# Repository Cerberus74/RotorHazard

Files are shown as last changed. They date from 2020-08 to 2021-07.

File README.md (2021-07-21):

RotorHazard Logo



# RotorHazard
**FPV Race Timing and Event Management**

A multi-node radio frequency race timing system for FPV drone racing with event management. Uses 5.8GHz video signals broadcast by drones to trigger lap times. Each node listens on a specified frequency and communicates times to a central server (usually a Raspberry pi). The server's front-end interface, which any device on the same network can connect to via web browser, offers race organizer management and pilot/spectator information. RotorHazard supports up to 16 nodes.

## Major Features
* Race timing and event management on local hardware, no internet connection needed
* Full screen and mobile-friendly responsive interface
* Simple, visual system calibration
* Adjust and apply calibration retroactively after race is complete
* Learns which calibration values work for each pilot and automatically applies them to new races (adaptive calibration)
* **Never miss a lap**; Recover laps with full accuracy by reviewing race history
* Advanced signal filtering allows accurate reading both indoors and outdoors, even in difficult multipathing environments
* Accurately tracks analog and DJI HD video transmitters
* Manage pilots, heats, classes, and race formats before or after races are run
* Statistics broken out by event, class, heat, and round
* Generates overlay displays and results pages for use with live streaming software such as OBS
* Timer hardware synchronized with user interface for accurate start/end signals; compensates for poor network connectivity
* LED and audio support to indicate race staging, starts, and other events
* Send live updates of lap times and split times to pilot OSD
* Control connected video receivers; change frequency and view lock status
* Connect other systems to extend functionality via MQTT or JSON API
* Send realtime lap data to LiveTime

## Documentation
For instructions on how to build and operate the current version of RotorHazard, follow the [Documentation](https://github.com/RotorHazard/RotorHazard/releases/latest#documentation) link on the [lastest-release page](https://github.com/RotorHazard/RotorHazard/releases/latest).

See the [RotorHazard Build Resources](resources/README.md) page for information on race-timer circuit boards and 3D-printable cases.

An easy-to-build single-node version of RotorHazard may also be constructed; see [doc/USB Nodes.md](doc/USB%20Nodes.md) for more info.

**Note:** The 'main' branch in the GitHub repository will usually contain the latest development code, which may not be stable. To install or upgrade to the latest stable release, please follow the [Documentation](https://github.com/RotorHazard/RotorHazard/releases/latest#documentation) link on the [lastest-release page](https://github.com/RotorHazard/RotorHazard/releases/latest) (see "Software Setup Instructions").

## Migrating from Delta5
RotorHazard is compatible with the hardware specifications of the [Delta5 Race Timer](https://github.com/scottgchin/delta5_race_timer). Install the software on  existing hardware per the [setup instructions](doc/Software%20Setup.md), ensuring that you complete a [re-flash of the Arduinos](doc/Software%20Setup.md#rotorhazard-node-code).

## Additional Resources
Links to external resources are available from the [Wiki](https://github.com/RotorHazard/RotorHazard/wiki), including extended tutorials, complete SD card images, video content, and a Raspberry Pi setup/install/upgrade/node flashing tool. Browsing these resources is strongly recommended for new users.

## Contributors
* Michael Niggel
* Eric Thomas
* Mark Hale

With support from Ryan Friedman, Klaus Michael Schneider, Cerberus Velvet, David Just, Paweł Fabiszewski, Aaron Smith, Diez Roggisch, Roger Bess, Kęstutis Strimaitis, and previous contributors to [Delta5](https://github.com/scottgchin/delta5_race_timer).

### Supported by:
Propwashed Logo (https://propwashed.com)

### Translators
* Dutch: Kenny Van Der Sypt
* German: Klaus Michael Schneider, Christian Baumgartner
* Spanish: Ramon Hernandez Roldan
* French: Yannick M.
* Polish: Mariusz Misiurek and Paweł Fabiszewski

## Feedback
Discuss RotorHazard on Facebook:  https://www.facebook.com/groups/rotorhazard

To report bugs or request features, please post a GitHub issue [here](https://github.com/RotorHazard/RotorHazard/issues). When reporting issues, using the "Download Logs" button and including the generated '.zip' file is highly recommended (see [here](doc/Software%20Setup.md#logging) for more information on logging).

Community contributions are welcome and encouraged; see the [Development.md](doc/Development.md) doc for more info.

## Support
Contributions to RotorHazard can be made on [Patreon](https://www.patreon.com/rotorhazard).

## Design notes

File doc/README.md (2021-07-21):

# RotorHazard Documentation

## Timing Guides
* [User Guide](User%20Guide.md)
* [Calibration Guide](Tuning%20Parameters.md)
* [Shielding and Course Position](Shielding%20and%20Course%20Position.md)
* [Event Setup Guide](Event%20Setup%20Guide.md)

## System Reference
* [Hardware Setup Instructions](Hardware%20Setup.md)
* [Software Setup Instructions](Software%20Setup.md)
* [Raspberry Pi Reference](Raspberry%20Pi%20Reference.md)

## Optional Features
* [Split Timing Guide](Cluster.md)
* [USB Nodes](USB%20Nodes.md)
* [Video Receiver Control](Video%20Receiver.md)

## General Reference
* [FPV Frequency Reference Chart](Frequency%20Reference.md)

<br />

---

* [Build Resources (PCB, etc)](../resources/README.md)
* [Developer Documentation](Development.md)
* <a href="https://github.com/RotorHazard/RotorHazard">RotorHazard on GitHub &#10132;&#xFE0E;</a>

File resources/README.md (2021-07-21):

# RotorHazard Build Resources

<br>

### Circuit Boards

* [RotorHazard S32_BPill PCB](S32_BPill_PCB/README.md)

* [RotorHazard 6 Node STM32](6_Node_BPill_PCB/README.md)

* [RotorHazard PCB 1.2 (Arduinos)](PCB/README.md)

<br>

### 3D-Printable Cases

* [RotorHazard S32_BPill Case](S32_BPill_case/README.md)

* [RotorHazard 6 Node Case](6_node_BPill_case/readme.md)

* [3D Printed Enclosure (for Arduino-based PCBs)](enclosure/README.md)

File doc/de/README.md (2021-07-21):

# RotorHazard-Dokumentation

## Timing-Leitfäden

* [Benutzerhandbuch](User%20Guide.md)
* [Kalibrierungsanleitung](Tuning%20Parameters.md)
* [Abschirmung und Kursposition](Shielding%20and%20Course%20Position.md)
* [Anleitung zur Ereigniseinrichtung](Event%20Setup%20Guide.md)

## System-Referenz

* [Anweisungen zur Hardware-Einrichtung](Hardware%20Setup.md)
* [Software-Einrichtungsanweisungen](Software%20Setup.md)
* [Raspberry Pi Reference](Raspberry%20Pi%20Reference.md)

## Optionale Merkmale

* [Leitfaden zur Zeitaufteilung](Cluster.md)
* [USB-Knoten](USB%20Nodes.md)
* [Video-Empfängersteuerung](Video%20Receiver.md)

## Allgemeine Referenz

* [FPV-Frequenz-Referenzdiagramm](Frequency%20Reference.md)

<br />

---

* [Dokumentation für Entwickler](Development.md)
* <a href="https://github.com/RotorHazard/RotorHazard" target="_blank">RotorGefahr auf GitHub</a> &#10132;➔&#xFE0E;︎

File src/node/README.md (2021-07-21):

# Receiver Node Firmware

The `src/node` directory contains the source code for the RotorHazard nodes. The same code may be used on Arduino nodes, or on an S32_BPill multi-node board.

For Arduino nodes, see '[readme_Arduino.md](readme_Arduino.md)'

For S32_BPill nodes, see '[readme_S32_BPill.md](readme_S32_BPill.md)'

<br>

## Unit Tests

Setup as per <https://github.com/Arduino-CI/arduino_ci>, then

```
set path=c:\Ruby25-x64\msys64\mingw64\bin;%path%
bundle exec arduino_ci_remote.rb --skip-compilation
```

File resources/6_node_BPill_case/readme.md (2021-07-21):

# 6 Node PCB Case
Internet connection is required to view images

## 3D Parts
Click [here](https://github.com/RotorHazard/rhfiles/tree/main/6_Node_BPill/case/stl) to view and download the .stl files

The 3D designs are done using Sketchup 2017 and the stl export plugin (which is hard to get hold of now). The .skp files have been uploaded should you wish to modify them, they can be found [here](https://github.com/RotorHazard/rhfiles/tree/main/6_Node_BPill/case/skp)

The available parts are:
Part                                    | Description                                                             | Links
----------------------------------------|-------------------------------------------------------------------------|-------------------------------------------------
RotorHazard Case                        | This is the main part of the case                                       | [[view](https://github.com/RotorHazard/rhfiles/blob/main/6_Node_BPill/case/stl/RotorHazard_Case.stl)] [[stl](https://github.com/RotorHazard/rhfiles/raw/main/6_Node_BPill/case/stl/RotorHazard_Case.stl)] [[skp](https://github.com/RotorHazard/rhfiles/raw/main/6_Node_BPill/case/skp/RotorHazard_Case.skp)]
RotorHazard Leg 60mm                    | This is the leg for the case, 2 are required                            | [[view](https://github.com/RotorHazard/rhfiles/blob/main/6_Node_BPill/case/stl/RotorHazard_Leg_60mm.stl)] [[stl](https://github.com/RotorHazard/rhfiles/raw/main/6_Node_BPill/case/stl/RotorHazard_Leg_60mm.stl)] [[skp](https://github.com/RotorHazard/rhfiles/raw/main/6_Node_BPill/case/skp/RotorHazard_Leg_60mm.skp)]
RotorHazard Standoff M2.5 11.5mm        | This is a standoff to go between the pi and the PCB, 4 are required     | [[view](https://github.com/RotorHazard/rhfiles/blob/main/6_Node_BPill/case/stl/RotorHazard_Standoff_M2.5_11.5mm.stl)] [[stl](https://github.com/RotorHazard/rhfiles/raw/main/6_Node_BPill/case/stl/RotorHazard_Standoff_M2.5_11.5mm.stl)] [[skp](https://github.com/RotorHazard/rhfiles/raw/main/6_Node_BPill/case/skp/RotorHazard_Standoff_M2.5_11.5mm.skp)]
RotorHazard Standoff M3 11.5mm          | Same as above, use these if you have made your pi's fixing holes wider  | [[view](https://github.com/RotorHazard/rhfiles/blob/main/6_Node_BPill/case/stl/RotorHazard_Standoff_M3_11.5mm.stl)] [[stl](https://github.com/RotorHazard/rhfiles/raw/main/6_Node_BPill/case/stl/RotorHazard_Standoff_M3_11.5mm.stl)] [[skp](https://github.com/RotorHazard/rhfiles/raw/main/6_Node_BPill/case/skp/RotorHazard_Standoff_M3_11.5mm.skp)]
RotorHazard Antenna Holder 50mm         | Used to mount the wired antenna                                         | [[view](https://github.com/RotorHazard/rhfiles/blob/main/6_Node_BPill/case/stl/RotorHazard_Antenna_Holder_50mm.stl)] [[stl](https://github.com/RotorHazard/rhfiles/raw/main/6_Node_BPill/case/stl/RotorHazard_Antenna_Holder_50mm.stl)] [[skp](https://github.com/RotorHazard/rhfiles/raw/main/6_Node_BPill/case/skp/RotorHazard_Antenna_Holder_50mm.skp)]
RotorHazard Lid No LED's                | The case lid with no cut outs for LED's                                 | [[view](https://github.com/RotorHazard/rhfiles/blob/main/6_Node_BPill/case/stl/RotorHazard_Lid_No_LEDs.stl)] [[stl](https://github.com/RotorHazard/rhfiles/raw/main/6_Node_BPill/case/stl/RotorHazard_Lid_No_LEDs.stl)] [[skp](https://github.com/RotorHazard/rhfiles/raw/main/6_Node_BPill/case/skp/RotorHazard_Lid_No_LEDs.skp)]
RotorHazard Lid External LED's          | The case lid with a cut out for a 3 pin JST-SM connector                | [[view](https://github.com/RotorHazard/rhfiles/blob/main/6_Node_BPill/case/stl/RotorHazard_Lid_External_LEDs.stl)] [[stl](https://github.com/RotorHazard/rhfiles/raw/main/6_Node_BPill/case/stl/RotorHazard_Lid_External_LEDs.stl)] [[skp](https://github.com/RotorHazard/rhfiles/raw/main/6_Node_BPill/case/skp/RotorHazard_Lid_External_LEDs.skp)]
RotorHazard Lid Cartridge 1 Part        | The case lid with an aperture for the LED cartridge                     | [[view](https://github.com/RotorHazard/rhfiles/blob/main/6_Node_BPill/case/stl/RotorHazard_Lid_Cartridge_1part.stl)] [[stl](https://github.com/RotorHazard/rhfiles/raw/main/6_Node_BPill/case/stl/RotorHazard_Lid_Cartridge_1part.stl)] [[skp](https://github.com/RotorHazard/rhfiles/raw/main/6_Node_BPill/case/skp/RotorHazard_Lid_Cartridge_1part.skp)]
RotorHazard Lid Cartridge 2 part A      | As above but broken into two easy to print parts, this is part A        | [[view](https://github.com/RotorHazard/rhfiles/blob/main/6_Node_BPill/case/stl/RotorHazard_Lid_Cartridge_2part_A.stl)] [[stl](https://github.com/RotorHazard/rhfiles/raw/main/6_Node_BPill/case/stl/RotorHazard_Lid_Cartridge_2part_A.stl)] [[skp](https://github.com/RotorHazard/rhfiles/raw/main/6_Node_BPill/case/skp/RotorHazard_Lid_Cartridge_2part_A.skp)]
RotorHazard Lid Cartridge 2 part B      | As above but broken into two easy to print parts, this is part B        | [[view](https://github.com/RotorHazard/rhfiles/blob/main/6_Node_BPill/case/stl/RotorHazard_Lid_Cartridge_2part_B.stl)] [[stl](https://github.com/RotorHazard/rhfiles/raw/main/6_Node_BPill/case/stl/RotorHazard_Lid_Cartridge_2part_B.stl)] [[skp](https://github.com/RotorHazard/rhfiles/raw/main/6_Node_BPill/case/skp/RotorHazard_Lid_Cartridge_2part_B.skp)]
RotorHazard Cartridge                   | This is the cartridge to hold the 8x8 LED panel                         | [[view](https://github.com/RotorHazard/rhfiles/blob/main/6_Node_BPill/case/stl/RotorHazard_LED_Cartridge.stl)] [[stl](https://github.com/RotorHazard/rhfiles/raw/main/6_Node_BPill/case/stl/RotorHazard_LED_Cartridge.stl)] [[skp](https://github.com/RotorHazard/rhfiles/raw/main/6_Node_BPill/case/skp/RotorHazard_LED_Cartridge.skp)]
RotorHazard Case (Pi zero / banana pi)  | Use this case with a pi zero or banana pi (No USB or Ethernet cutouts)  | [[view](https://github.com/RotorHazard/rhfiles/blob/main/6_Node_BPill/case/stl/RotorHazard_Case%20-%20pi%20zero.stl)] [[stl](https://github.com/RotorHazard/rhfiles/raw/main/6_Node_BPill/case/stl/RotorHazard_Case%20-%20pi%20zero.stl)] [[skp](https://github.com/RotorHazard/rhfiles/raw/main/6_Node_BPill/case/skp/RotorHazard_Case%20-%20pi%20zero.skp)]
RotorHazard Standoff M3 13.1mm          | Use this standoff when the screw doesn't go through the pi              | [[view](https://github.com/RotorHazard/rhfiles/blob/main/6_Node_BPill/case/stl/RotorHazard_Standoff_M3_13.1mm.stl)] [[stl](https://github.com/RotorHazard/rhfiles/raw/main/6_Node_BPill/case/stl/RotorHazard_Standoff_M3_13.1mm.stl)] [[skp](https://github.com/RotorHazard/rhfiles/raw/main/6_Node_BPill/case/skp/RotorHazard_Standoff_M3_13.1mm.skp)]

## Parts to buy for the case
### Required
Part                | Qty   | Description
--------------------|-------|---------------
M3x8mm              | 10    | Used to attach the PCB to the standoffs, the lid to the case and the legs to the case
M3x10mm countersunk | 4     | Used to attach the Raspberry pi to the case
Copper tape         | -     | Used for RF shielding, make sure it has conductive adhesive
26AWG Wire          | -     | 

### Optional
Part                    | Qty   | Description
------------------------|-------|---------------
M3x5mm                  | 1     | Used for attaching the antenna arm, 3x8mm would work
M2x5mm                  | 2     | Used to attach the voltage display to the case
40x40x10mm fans         | 2     | 
M3x16mm                 | 8     | Attaches the fans to the case
M3 nut                  | 8     | Attaches the fans to the case
8x8 WS218b LED panel    | 1     | LED's for the cartridge print
2.54mm header 3 pins    | 2     | Connects the cartridge to the lid
2.54mm socket 3 pins    | 1     | Connects the cartridge to the lid
Hot glue                | -     | To attach cartridge pins to case

## Lid
There are 3 lid option to chose from:
1. The first has no LED apparatuses and is a basic lid
2. The second adds an aperture for the female JST-SM 3 pin header that comes with the LED's so that external LED's can be used
3. The third allows use of an LED cartridge, the print can be printed in 1 or 2 parts depending on your printers capabilities

### LED cartridge & lid wiring
The LED cartridge connects to the lid using standard PCB mount 2.54mm headers and sockets. You have to be careful to get the alignment of the connectors correct.

1. Start with the two 3 way pin headers, solder wire to both of them and then solder those wires together.
2. Now insert those headers into the two holes on the lid 3D print. Make sure the pin out is symmetrical to ensure correct connections when you rotate the cartridge
3. Now solder the socket to wire and fit it into the LED cartridge print
4. Now is the time to align the connectors. Put the cartridge into the cartridge insert in the lid and ensure a good connection with the lids pins. Hot glue into place once aligned.
5. Rotate the cartridge and ensure it fits in the other orientation.
6. Now solder the cartridge socket wires to the LED panel and secure in place

Internet connection is required to view images
Internet connection is required to view images

## Thermal Considerations
Commercial electronics are typically rated up to 70&deg;C. During initial testing the timer was around 45&deg;C above ambient, with all 6 nodes active and with heat-syncs fitted.

Whilst this is still within 70&deg;C at room temperature ~21&deg;C these kind of temperatures are not recommended as it can cause the following:
* Stability issues
* Reduced life span of the electronics

If you live in a cold country or only plan to use 2-3 nodes at the same time then you are probably ok just using heat-syncs

For the majority of people heat-syncs and fans are recommended for optimum cooling.

If you use fans and wish for them to activate automatically and save power + maintain a constant temperature go [here](https://github.com/Aaronsss/Raspberry-Pi-Fan-Control) and follow the install instructions for the automatic fan control which will turn fans on when the pi temperature is 40&deg;C and off again when it is 38&deg;C

## RF Shielding
RF shielding is an essential part of RotorHazards timing, make sure you shield your timer. There are a number of ways to do this like putting the timer in a metal box

The neatest way to do it is to get some copper tape and cover the inside of the box. Be sure to use copper tape with conductive adhesive. Once fitted you can solder a wire to the copper tape and then connect that to the case pads of the PCB. It is recommended to add insulation tape in locations where the PCB comes close to the case. Be sure to leave the end with the grill and centers of the fan covers unshielded

More information of RF shielding can be found [here](/doc/Shielding%20and%20Course%20Position.md)

Internet connection is required to view images

## Wifi Antenna Wiring
If you wish to use Wifi it is recommended to use a USB 2.4GHz wifi dongle with external antenna. 

You can then go one step further and de-case it and include it inside the laptimer case. This is what the arm is designed for on this case design.

Remove the plastic casing from the wifi dongle, then de-solder the SMA connector. Now solder a 2.4GHz antenna to the old SMA pads by either direct soldering or using a U.FL connector

Now connect the USB connections to the probe points on the bottom of the Raspberry Pi. On a Raspberry Pi 3B+ the probe points are as follows for the bottom left USB (when looking directly at the USB connector):
* PP27 = USB VCC
* PP42 = USB D-
* PP43 = USB D+
* PP51 = GND

You should then apply heat shrink to the wifi board and apply some hot glue to the antenna end for mechanical security.

Now you can feed the antenna through the hole in the case and heat shrink it to the antenna arm

You will then need to configure your pi to use the wifi dongle instead of the built in wifi

Internet connection is required to view images

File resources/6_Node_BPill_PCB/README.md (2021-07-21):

# RotorHazard 6 Node STM32

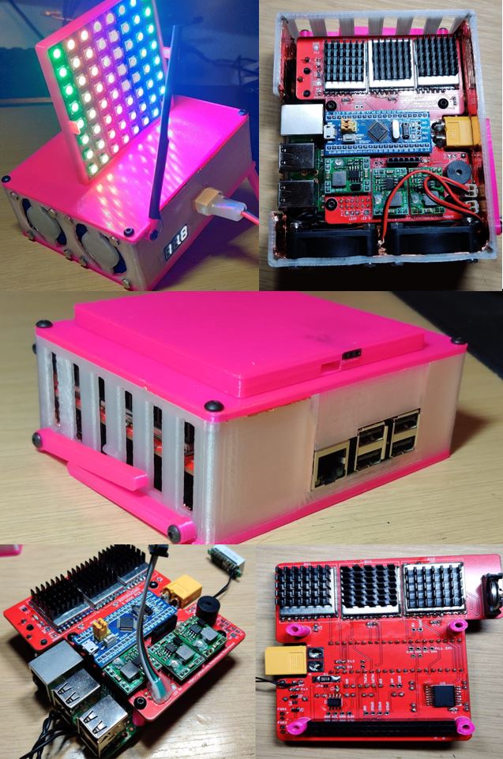
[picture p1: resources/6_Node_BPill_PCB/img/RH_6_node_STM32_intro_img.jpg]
RH_6_node_STM32_intro_img


## Features

* Supports 1 to 6 RX5808 nodes
* Board size is 97mmx87mm, with cut-outs for an XT60 & Raspberry Pi connectors
* The Raspberry Pi plugs directly into the PCB in a raspberry Pi 'hat' style, to keep things compact
* Instead of multiple Arduinos, the board uses a single STM32 processor on a 40 pin module, mounted on the PCB
* The STM32 firmware can be updated via the RotorHazard web GUI using the 'Update Nodes' button (in the 'System' section on the 'Settings' page)
* The same server and node source code supports both the 6 node STM32 and the (existing) multi-Arduino boards
* Supports power / battery monitoring and a buzzer (low-battery alarm)
* INA219 (Current sense IC) & DS3231 (Real Time Clock) + RTC battery can be mounted directly to the PCB
* Connector pads for LED-strips & dedicated regulator
* Fans can be automatically switched on based on raspberry pi temperature.

PCB build instructions can be found [here](BoardBuild.md)

PCB:<br>
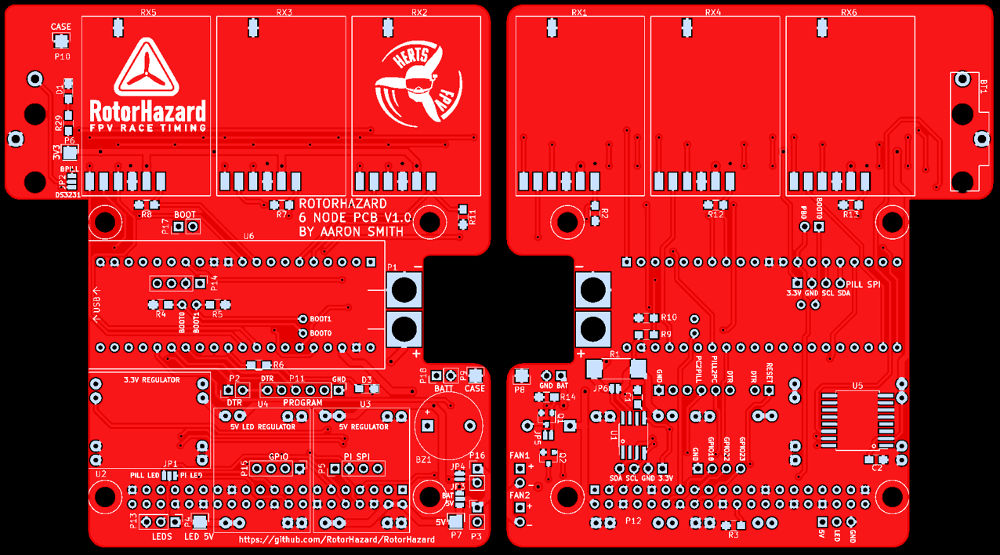
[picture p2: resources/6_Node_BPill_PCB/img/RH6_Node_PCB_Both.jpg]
RH6_Node_PCB_Both


## Cost
The cost of the required parts is approximately £74 (~102.60 USD)

For each node add £6, so all 6 nodes would add £36 (~49.90 USD)

All the optional parts add approximately £23 (~31.90 USD)

To fit all parts to the board will cost approximately £133 (~184.40 USD)

Note: The above costs includes the raspberry pi 3b + SD card. Mouser & Banggood were used in the above costings, parts may be cheaper from other suppliers

## Bill of Materials (BOM)
The PDF version of the BOM can be found [here](RotorHazard_6_Node_Timer_BOM_V1.0.pdf), the PDF version contains more information and suggested parts / suppliers
### Required

For the PCB:
Reference                       | Quantity  | Part No.                                                           | Notes
--------------------------------|-----------|--------------------------------------------------------------------|---------
PCB                             |   1       | Download the [gerber files](RotorHazard_6_Node_Timer_fab_V1.0.zip) | You can upload the gerbers files to your favourite PCB supplier or click [here](https://www.pcbway.com/project/shareproject/RotorHazard_6_Node_STM32_Lap_Timer.html) to buy from PCBway<br>Keep default options but consider changing:<br>- The solder mask colour <br>- Select quantity 10 which doesn't cost any more
P12	                            |   1	    | 2.54mm 20x2 8.51mm tall header                                     | Single strips also work
P1	                            |   1	    | XT60 Male	                                                         | -
R2, R7, R8, R9, R11, R12, R13	|   7	    | 100k ohm 5% 0805 resistor                                          | Buy some extra in case you drop one
R3, R10                         |   2       | 10k ohm 5% 0805 resistor                                           | Buy some extra in case you drop one
U2, U3                          |   2	    | MP1584	                                                         | -
U2, U3  	                    |   16	    | 2.54mm header pins                                                 | -
U6	                            |   1	    | STM32F103C8T6 	                                                 | -
RX1, RX2, RX3, RX4, RX5, RX6    |   1-6	    | RX5808	                                                         | 1 of these is required for each node you wish to fit

For the timer assembly:
Name                            | Quantity  | Notes
--------------------------------|-----------|---------
RASPBERRYPI_3B+                 |   1       | Alternative: Raspberry Pi 4
8GB+ Micro SD card              |   1       | Any Micro SD card between 8GB and 64GB will work
  
You will also require some 3D printed parts for the case and the 11.5mm 3D printed stand offs. If you wish to use a different case then 12mm standoffs should work.

Details on 3D printed parts and mechanical assembly can be found [here](../6_node_BPill_case/README.md)
  
### Optional
For the PCB:
Reference                       | Quantity  | Part No.                      | Notes
--------------------------------|-----------|-------------------------------|---------
U5                              |	1	    | DS3231SN                      | Fit if you want the real time clock (RTC), alternatives: DS3231S#T&R, DS3231SN#, DS3231S#
BT1	                            |   1	    | Keystone Electronics 1069     | Fit if you want the real time clock (RTC)
BT1	                            |   1	    | CR1632 battery                | Fit if you want the real time clock (RTC), alternatives: CR1620, CR1616
R1	                            |   1	    | 0.1 ohm 2512 1% resistor      | Fit if you wish to use the current sense IC
U1	                            |   1	    | INA219AIDR	                | Fit if you wish to use the current sense IC, alternatives: INA219AID, INA219BID, INA219BIDR
C1, C2	                        |   2	    | 100nF X7R 0805 capacitor      | These are decoupling capacitors for INA219 and DS3231
D1, D3	                        |   2	    | 0805 LED       	            | Fit if you want the on-board power and status LED's, not really needed
R6, R29	                        |   2	    | 220 ohm 5% 0805 resistor	    | Fit if you want the on-board power and status LED's, not really needed
P4	                            |   1	    | 3 pin JST SM Female	        | Fit if you want to use RGB LED rope / tape
U4	                            |   8	    | 2.54mm header pins            | Fit if you want to use RGB LED rope / tape
U4	                            |   1	    | MP1584	                    | Fit if you want to use RGB LED rope / tape
BZ1	                            |   1       | 12mm x 9.5mm 5V buzzer        | Used for low voltage alarm
Q2  	                        |   1	    | GSD SOT-23 N-Channel MOSFET   | Used for optional fan enable control, an example is IRLML6344TRPBF

For the timer assembly:
Name	                        | Quantity      | Notes
--------------------------------|---------------|---------
Raspberry Pi heat syncs         |   1 set       | Recommended to keep the pi cool
20x20x6mm heat sync             |   1-6         | Recommended to keep the RX5808's cool
Thermal glue                    |   1 tube      | Needed to attach the RX5808 heat syncs
LCD Voltage Screen              |   1           | Used to show the battery voltage on the case

## Tools
### Required
1. Soldering iron (chisel tip recommended to fit INA219 or DS3231 IC's)
2. Solder
3. Tweezers
4. Digital Multi Meter (DMM), to measure voltage and resistance
5. Screw driver for screws purchased
6. Small flat head screw driver to adjust MP1584 voltage

### Recommended
1. Wire cutters / side cutters
2. Helping hands
3. Solder wick
4. Hot glue & glue gun
5. Pilers
6. Insulation tape
7. Copper tape with conductive adhesive
8. Magnifying glass

## Resources

[RotorHazard 6 Node STM32 Schematic](RotorHazard_6_Node_Timer_V1.0.pdf)

[Gerber files for RotorHazard 6 Node STM32 PCB](RotorHazard_6_Node_Timer_fab_V1.0.zip)

[RotorHazard 6 node STM32 Board Build Guide](BoardBuild.md)

[3D printed parts & mechanical assembly](../6_node_BPill_case/readme.md)

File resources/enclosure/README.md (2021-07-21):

# 3D Printed Enclosure
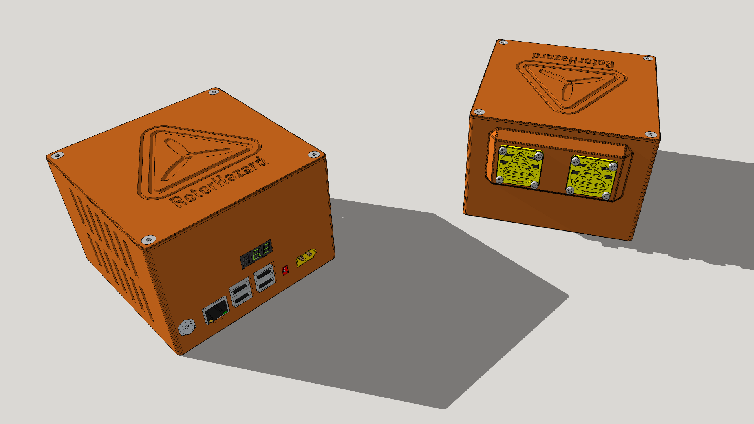
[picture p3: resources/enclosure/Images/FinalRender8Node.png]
3D rendering of box with openings for Raspberry Pi, case fans, and voltage display; with RotorHazard branding


## **Four and Eight Node Printable Enclosures**
This is pretty much a ground up rework of FreeFormFPV's excellent original work. Not much of the original remains. I've expanded heavily on the original design and hopefully improved it.

There are two enclosures. One for four node timers and one for eight node timers. The lid and PCB tray fit either.

The Original D5 100x100mm V2.0 PCB is a 'click fit' into the new PCB Trays. No fasteners needed. the trays then stack in place in the enclosure and are secured in place by the lid. Which secures with four countersunk M3 fasteners. The planned updated RotorHazard PCB will be compatible with the PCB tray.

A POE DC jack is provided so that the timer can be powered at the other end of the network cable (POE injector needed). Be sure to use a THREE PIN DC jack wired properly to disconnect the XT60 socket when in use. Failure to do this may result in the release of magical smoke. The timer may thus be powered either locally by a lipo or remotely over POE.

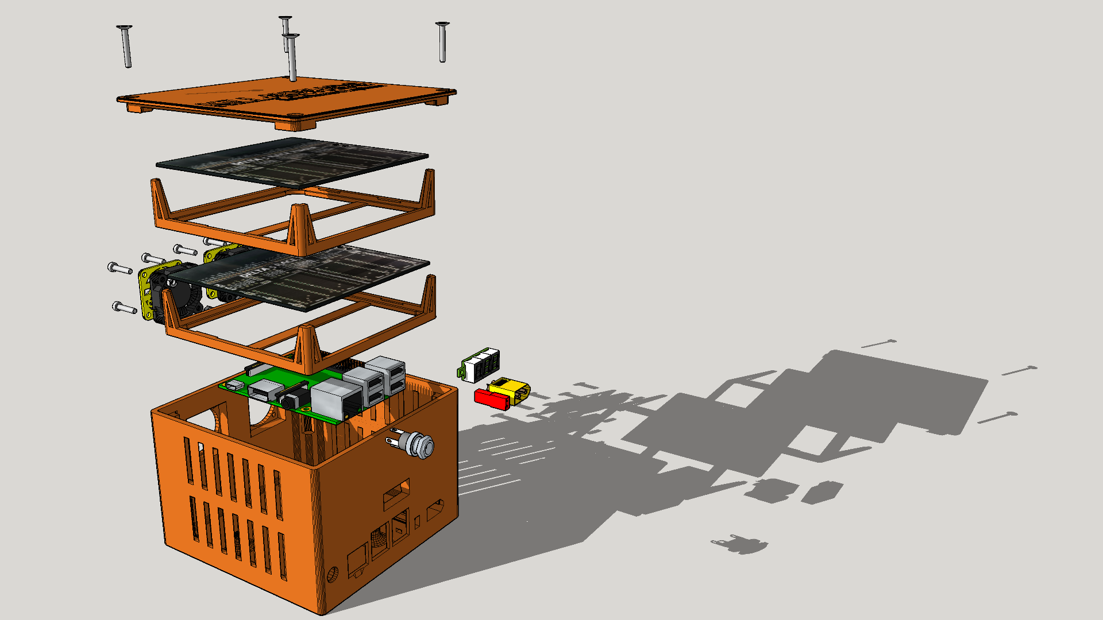
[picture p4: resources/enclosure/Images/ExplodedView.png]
Exploded view of enclosure with insert trays and electronic components

## **Printable Parts:**
* 8 Node Enclosure Box
* 4 Node Enclosure Box
* PCB Tray
* RotorHazard Branded Lid
* RotorHazard Branded Fan Grille
* Three Plain Style Fan Grilles

## **Parts Needed:**
**XT60 connector** to power timer by lipo (Slot for securing zip tie provided, but I recommend a dab of hot glue to really hold it)
http://tiny.cc/12ri8y

**JST connector** for WS2812b LED panel output from Raspberry Pi pins 19-GPIO10,20-GND (Slot for securing zip tie provided, but I recommend a dab of hot glue to really hold it)
http://tiny.cc/e7ri8y

**5.5mm 3 pin DC Jack** for POE
http://tiny.cc/wbsi8y [Wiring Diagram](Images/WireBarrelJack.png)

**POE injector/adapter** (optional)
http://tiny.cc/idsi8y

**2 x 5V 3cm cooling fans**
http://tiny.cc/rsti8y

**Voltage Meter**
http://tiny.cc/o7ti8y
(Secured by two M2 fasteners. Or a couple of dabs of hot glue)

**4 x countersunk M3x20 Machine Screw** To fasten lid
http://tinyurl.com/y3g2hqaf

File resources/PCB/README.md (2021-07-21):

# RotorHazard PCB

The RotorHazard PCB 1.2 implements current hardware standards to simplify wiring and component placement, expediting timer builds and improving usability.

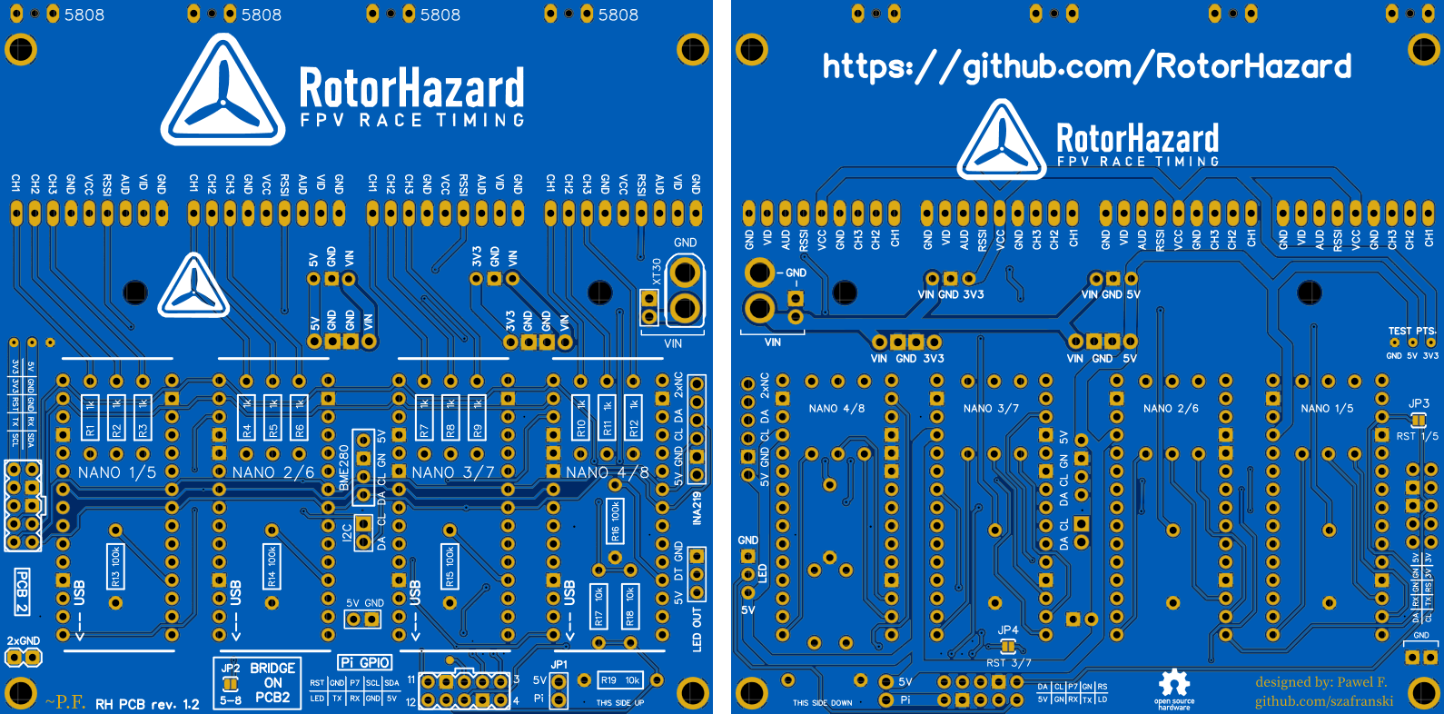
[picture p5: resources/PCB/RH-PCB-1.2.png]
PCB Layout


Download the [gerber file](Gerber_PCB%20RotorHazard%20PCB%20rev.%201.2.zip) to produce a board or send to a PCB manufacturer. Manufacturers often require bulk purchases, so check with other RotorHazard users near you before purchasing in case there is stock available or to split the cost of an order.

[View Board Schematic (PDF)](Schematic_RotorHazard-PCB-1_2_RC_2020-08-20_19-56-33.pdf)<br>
[View Board Dimensions (JPG)](RH_PCB_1_2_dimensions.jpg)

## Features

* 100×100mm (matches common Delta5 V2 PCB)
* Functions as 1–4 node primary board or 1–4 node extension
* Implements hardware-based node address selection. Nodes do not need uniquely addressed and can remain st to address 0 on upload.
* Implements in-system programming wiring for "OTA" updates without removing Arduinos from board
* Integrated voltage converter for ISP line
* Supports standardized 2×5 pin ribbon cable connectors to Pi GPIO and between boards
* Dedicated connectors for BME280 and INA219 sensors
* Expansion connectors for other I2C devices
* Raspberry Pi power isolation jumper
* Additional VIN connector (common uses: case fan or diode for reverse voltage protection)
* Additional ground connectors (common use: case shielding)
* 6 screw-mount holes, 4 with exposed ground plane

## Testing

RotorHazard does not manufacture PCBs and cannot guarantee the quality of any manufacturer. Thoroughly test any boards before connecting sensitive components.

## Build Components

### Required

See [Hardware Setup](https://github.com/RotorHazard/RotorHazard/blob/main/doc/Hardware%20Setup.md) for basic component requirements such as Arduinos, resistors, and receiver modules. The RotorHazard PCB offers mounting points for these components.

In addition to the above building with the RotorHazard PCB requires:
* 1× PCB (for timers with 1–4 nodes) or 2× PCB (timers with 5–8 nodes)
* 1× 3V 2.5A regulator
* 3× 10k resistor (0.25W or greater)

The RotorHazard PCB is designed to fit the following components:
* Arduino Nano
* Pololu D24V25F5 ("enable" pin is not connected)
* Pololu D24V25F3 ("enable" pin is not connected)

### Recommended

These components improve performance or significantly improve ease of use.

* 2×15 pin female 0.1in headers for each Arduino
* 1×9 pin female 0.1in header for each RX5808 module
* Female 0.1in header for each voltage regulator (either 1×3 pin or 1×4 pin depending on regulator style)
* 1×2 pin male 0.1in header with 2-pin jumper (for disconnecting power from the Pi)
* 2×5 pin male connector for Pi GPIO (may be KANDA/ISP style or male gold-pin header)
* Flat/ribbon cable or 10pcs jumper wires (2×5) for Pi GPIO
* 4–6 3mm screws for each board (mounting board to case)

If a 2nd PCB is used:
* 2×5 pin male connector for each PCB
* Flat/ribbon cable or 10pcs jumper wires (2×5) for PCB1 -> PCB2

### Optional

For a tidy build or to use with optional features, the following components may be added.

* XT30 female connector (power in)
* 1×3 pin female 0.1in header for each RX5808 module's antenna connector—do not solder center ANT pin
* 1×3 pin male 0.1in header for LEDs (connect only DATA and GND if LED are powered with separate voltage source)
* 1×6 pin female 0.1in header for INA219 sensor
* 1×4 pin female 0.1in header for BME280 sensor
* 1×2 0.1in header for grounding of RF shield (not needed if mounting screws are already connected to RF shield)
* 1×2 0.1in header for connecting optional accessories to the VIN (such as a 12V case fan)

## Assembly

This layout can be used as a primary board for up to 4 nodes when directly connected to the Pi, or a secondary board for up to 4 additional nodes. When connected directly it will be referred to as PCB1. If you are using only one board, follow all instructions for PCB1. A secondary board is referred to as PCB2.

* Find "THIS SIDE UP" indicator. This is the expected side on which to attach your components. While other configurations are possible, you will need to adjust these assembly instructions accordingly.
* Use node slots in numeric order. While RotorHazard should function with nodes placed out of order, in-system node flashing may not.
* Solder four resistors at "R" positions within each node area for all nodes you will be using. Use the values indicated (1k or 100k).
* R17-19 are required on PCB1. They are not used for PCB2.
* Female 0.1" (2.54mm) headers are expected for Arduino mounts, voltage regulators, and RX5808 mounts. Add these headers now if you are using them. If you choose to flush mount any component, be sure to electrically isolate it from the board.
* Bridge JP1 on PCB1. A physical jumper is recommended in this position. Bridging on PCB2 is not required.
* If using 5–8 nodes, connect "PCB2" headers between each board, being careful to match polarity. You may use a standard 2×5 pin ribbon cable or wire these insidivdually. On PCB2, bridge pads at the bottom marked "BRIDGE ON PCB2" (JP2)
* If using an odd number of nodes, bridge one and only one pad on the back of one board that corresponds to the highest numbered node in use:
1 node: PCB1 JP3
3 nodes: PCB1 JP4
5 nodes: PCB2 JP3
7 nodes: PCB2 JP4
* Connect a 5V voltage regulator and a 3.3V regulator on PCB1. Use either the upper (3) or lower (4) set of pins depending on the chosen regulator's pinout. Do not use both upper and lower sets at once for the same voltage.
* Connect input voltage connector or wires at VIN. Use XT30 connector if desired.
* STOP. Perform continuity testing to ensure there are no shorts from power to ground. Connect power at VIN and test 5V, 3.3V, and GND at test points on back of board before proceeding. Use a fuse or "smoke stopper" during these tests.
* Connect the Pi to the "Pi GPIO" header block. You may use a 2×5 pin cable attached to pins 3–12 of the Pi GPIO, or individual wires if you wish to change any connections (such as for "LED IN")
* If using INA219 or BME280 sensors, connect to dedicated pads.
* Connect Arduinos. Keep Aruino reset button and LEDs visible. Keep USB connector toward side indicated with "<-- USB" (away from voltage regulators).
* Connect RX5808 modules. Optionally connect GND pads near antenna. Do not solder to RX5808 antenna connection (center pad).
* When connecting an LED strip to LED OUT, ensure the voltage regulator you are using is rated highly enough for all Arduinos, sensors, and the LED strip combined. If not, supply power for the LEDs from a separate regulator, using only data and ground from the PCB.

## Usage

* Before ISP flashing of nodes is possible, nodes must not be transmitting over serial. You can flash the most recent node version from RotorHazard, or the standard "Blink" sketch. (Delta5 and older RotorHazard node versions generally use serial and will prevent ISP from functioning.)
* Nodes should all be flashed with the node number of 0 (default). This board will automatically assign node numbers based on their position.
* In-system flashing can be accomplished with the [OTA tool](https://github.com/szafranski/RH-ota)
* If flashing nodes by USB, disconnect JP1 to prevent powering on the Pi.

## Credit

This board and the OTA tool were developed by [Paweł Fabiszewski](mailto:p.fabiszewski@gmail.com).

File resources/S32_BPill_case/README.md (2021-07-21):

# RotorHazard S32_BPill Case

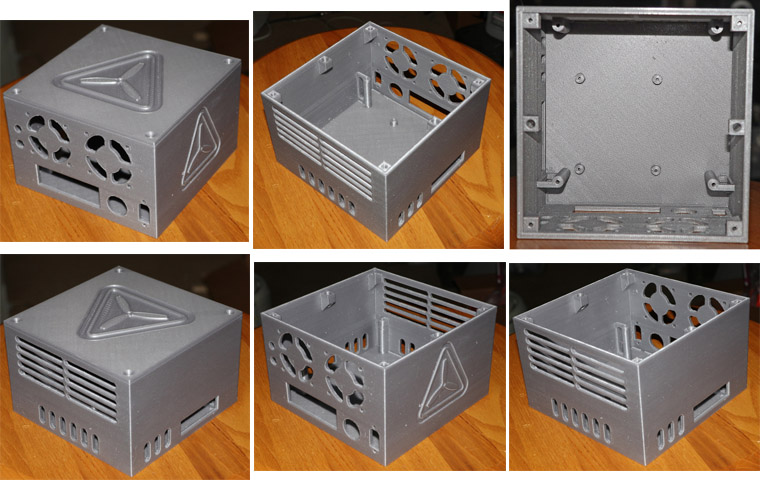
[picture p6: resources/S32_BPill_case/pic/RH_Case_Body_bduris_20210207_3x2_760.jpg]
RH_Case_Body_3x2


The RotorHazard S32_BPill case is the recommended enclosure to use with the [S32_BPill PCB](../S32_BPill_PCB/README.md). Inspired by existing designs, the S32_BPill case was created from scratch as a new project using [FreeCAD](https://github.com/FreeCAD/FreeCAD).

## Features

* Four mounting posts for attaching the S32_BPill PCB with screws (no separate mounting tray)

* Mounting posts for the Raspberry Pi on the bottom, with openings on the front and side for accessing Pi connectors

* Contains mounting holes for a power button, [shutdown button](../../doc/Shutdown%20Button.md), status LED, and (optional) fans

* Lid may be attached with screws, or magnets may be installed in provided mounts

* FreeCAD source project file available (see below)

## Resources

[RotorHazard S32_BPill Case Body \(with logo, 77mm tall\)](https://github.com/RotorHazard/rhfiles/raw/main/S32_BPill/case/RotorHazardCaseBodyBD77.stl) \[[preview](https://github.com/RotorHazard/rhfiles/blob/main/S32_BPill/case/RotorHazardCaseBodyBD77.stl)\]

[RotorHazard S32_BPill Case Lid \(with logo\)](https://github.com/RotorHazard/rhfiles/raw/main/S32_BPill/case/RotorHazardCaseTopBDyy.stl) \[[preview](https://github.com/RotorHazard/rhfiles/blob/main/S32_BPill/case/RotorHazardCaseTopBDyy.stl)\]

[FreeCAD Source Project File](https://github.com/RotorHazard/rhfiles/raw/main/S32_BPill/case/RotorHazardCaseBDyy.FCStd)

[Detailed RotorHazard S32_BPill Case Build Guide](detailedCaseBuild.md) (alt [PDF version](https://github.com/RotorHazard/rhfiles/blob/main/S32_BPill/case/RH_S32_BPill_CaseBuildInstructions.pdf))

Note: The 77mm-tall case is a good fit with the "standard" RotorHazard S32_BPill PCB build using [low-profile socket headers](../S32_BPill_PCB/headers.md) for the node modules. If standard socket headers are used for the node modules then the 81mm-tall case (below) can provide the extra height needed.

[RotorHazard S32_BPill Case Body \(with logo, 81mm tall\)](https://github.com/RotorHazard/rhfiles/raw/main/S32_BPill/case/RotorHazardCaseBodyBD81.stl) \[[preview](https://github.com/RotorHazard/rhfiles/blob/main/S32_BPill/case/RotorHazardCaseBodyBD81.stl)\]

[RotorHazard S32_BPill Case Body \(without logo, 77mm tall\)](https://github.com/RotorHazard/rhfiles/raw/main/S32_BPill/case/RotorHazardCaseBodyBD77_NoLogo.stl) \[[preview](https://github.com/RotorHazard/rhfiles/blob/main/S32_BPill/case/RotorHazardCaseBodyBD77_NoLogo.stl)\]

[RotorHazard S32_BPill Case Body \(without logo, 81mm tall\)](https://github.com/RotorHazard/rhfiles/raw/main/S32_BPill/case/RotorHazardCaseBodyBD81_NoLogo.stl) \[[preview](https://github.com/RotorHazard/rhfiles/blob/main/S32_BPill/case/RotorHazardCaseBodyBD81_NoLogo.stl)\]

[3D CAD Rendering of RotorHazard S32_BPill Case Body](files/RotorHazard_S32_BPill_Case_3D.pdf)

## Notes

* The case top will probably print best if it is inverted on the print bed.

* Changes to the design may be implemented by editing the FreeCAD source project file and regenerating the STL files. The design is highly parameterized and many of the dimensions can be altered by simply changing a number in the spreadsheet that is part of that source project.

* A page for this case has been posted on Thingiverse: https://www.thingiverse.com/thing:4733410

<br>

The RotorHazard S32_BPill case and detailed build guide were developed by Bob Duris

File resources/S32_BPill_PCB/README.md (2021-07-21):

# RotorHazard S32_BPill PCB

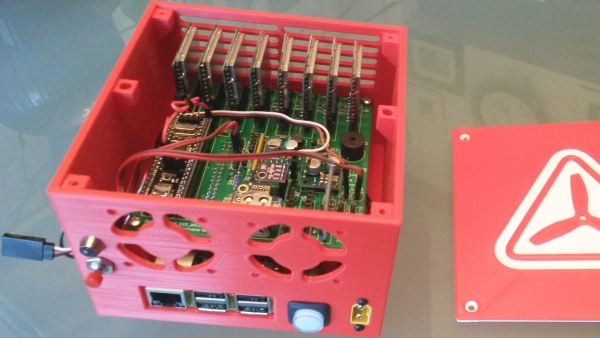
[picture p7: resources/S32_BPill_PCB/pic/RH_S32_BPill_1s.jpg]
RH_S32_BPill_1


The RotorHazard S32_BPill PCB v1.0 represents the next generation of race-timer hardware.

## Features

* Instead of multiple Arduinos, the board has a single STM32 processor

* Board size (100×100mm) is the same as the "standard" Delta5 PCBs

* Supports 1 to 8 RX5808 node modules on a single PCB

* The RX5808 node modules are mounted vertically using small sub-boards -- this allows for up to eight on a single board, and provides substantially improved cooling

* Communication between the STM32 processor and the Raspberry Pi is via serial-port link, running at 921600 baud. The S32_BPill board can also be connected directly to a computer (via USB-to-Serial/FTDI dongle)

* The STM32 processor is on a 40-pin module, attached to the board via sockets. These are commonly known as "Blue Pill" modules, and are readily available and inexpensive (see [below](#aboutblue))

* The board has a 40-pin (2x20) header for connecting to the Raspberry Pi, via a [ribbon cable](https://www.ebay.com/itm/40-Pin-2x20-Female-to-Female-2-54mm-Pitch-40-wire-IDC-Flat-Ribbon-Cable/391776118674) with female ends

* The STM32 processor is in-circuit programmable, able to be updated/flashed using the Raspberry Pi. The update can be performed via the RotorHazard web GUI using the 'Update Nodes' button (in the 'System' section on the 'Settings' page)

* The same server and node source code supports both the S32_BPill and the (existing) multi-Arduino boards

* Supports power/battery monitoring and a buzzer (low-battery alarm)

* Mounting locations for (optional) [DS3231](#rtc) (RTC), [INA219](https://www.adafruit.com/product/904) and [BME280](https://www.amazon.com/Onyehn-Temperature-Humidity-Barometric-Pressure/dp/B07KR24P6P) modules, connected to the Raspberry Pi I2C bus

* Optional "extra" LED, which can be panel mounted on the timer case

* Connector pads for LED-strips -- one to the Raspberry Pi, one to the STM32 processor
<br>

Main PCB:<br>
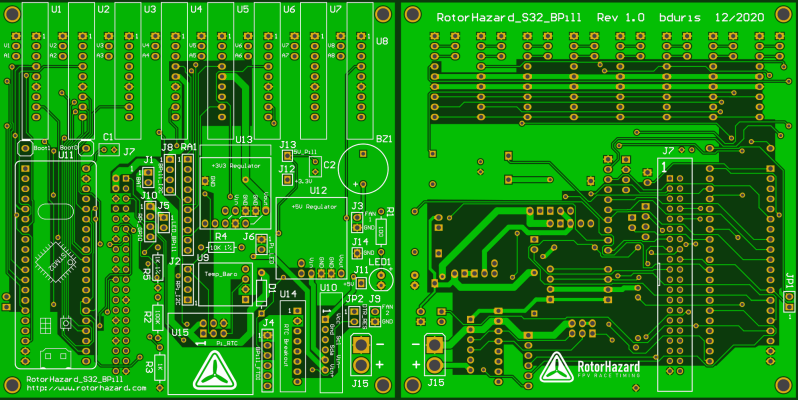
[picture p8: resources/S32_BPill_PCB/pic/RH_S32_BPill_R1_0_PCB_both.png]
RH_S32_BPill_R1_0_PCB_both
<br><br>
Node PCB:<br>
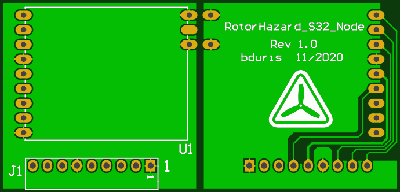
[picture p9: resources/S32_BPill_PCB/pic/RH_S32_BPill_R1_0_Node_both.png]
RH_S32_BPill_R1_0_Node_both


## Resources

[RotorHazard S32_BPill PCB Schematic](files/RotorHazard_S32_BPill_SCH_R1.pdf)

[RotorHazard S32_BPill Node-board Schematic](files/RotorHazard_S32_Node_SCH_R1_0.pdf)

[Gerber files for RotorHazard S32_BPill PCB](http://www.rotorhazard.com/files/GerberFiles_RotorHazard_S32_BPill_R1.zip) &nbsp; (alternate link: [on GitHub](files/GerberFiles_RotorHazard_S32_BPill_R1.zip))

[Gerber files for RotorHazard S32_BPill Node board](http://www.rotorhazard.com/files/GerberFiles_RotorHazard_S32_Node_R1_0.zip) &nbsp; (alternate link: [on GitHub](files/GerberFiles_RotorHazard_S32_Node_R1_0.zip))

The Gerber files can be sent to a PCB manufacturer to fabricate boards. To build a timer, you will need one S32_BPill PCB, and several of the S32_BPill Node boards (one for each RX5808 module in the timer).

The size of the node board is 34.3x33.0mm, with a recommended thickness of 0.8mm (for better thermal conductivity and more capacitance between layers). The recommended thickness for the main PCB is the standard 1.6mm, and, in general, the default PCB-fabrication settings should work well (i.e., 1oz copper, HASL finish, no castellated holes, no gold).

Bill of Materials: [PDF](files/RotorHazard_S32_BPill_R1_bd02.pdf) | [XLS](files/RotorHazard_S32_BPill_R1_bd02.xls) | [HTML](http://www.rotorhazard.com/files/RotorHazard_S32_BPill_R1_bd02.html)

[RotorHazard S32_BPill Main Board Build Guide](mainBoardBuild.md)

[RotorHazard S32_BPill Node Board Assembly](nodeAssembly.md)

[Altium 16.1 project files exported to ASCII](https://github.com/RotorHazard/rhfiles/raw/main/S32_BPill/files/RotorHazard_S32_BPill_R1_AltiumAscii.zip)

[CAD drawings of S32_BPill PCB](https://github.com/RotorHazard/rhfiles/raw/main/S32_BPill/files/RotorHazard_S32_BPill_PCB_R1.pdf)

[CAD drawings of S32_BPill Node Board](https://github.com/RotorHazard/rhfiles/raw/main/S32_BPill/files/RotorHazard_S32_Node_PCB_R1_0.pdf)

[PCB Build Notes](files/Build_notes.txt) and [Pin Soldering Helper](files/PinSolderingHelper.pdf) doc

[Socket Headers](headers.md) and [Trimming Jig](trimjig.md) for RotorHazard S32_BPill

[Generic Blue Pill Pinout](files/GenericBluePillPinout.jpg)

[RobotDyn "Black" Pill Pinout](files/STM32F103C8T6-RobotDyn_Black_Pill_pinout.pdf)

## Notes

* For the S32_BPill board the RotorHazard server must be version 3.0.0 or later.

* The recommended voltage regulators for the board are Pololu [D36V28F5](https://www.pololu.com/product/3782) (5V) and Pololu [D24V22F3](https://www.pololu.com/product/2857) (3.3V). See [here for additional notes](files/PololuCompatibilityWithRaceTimer.txt) about Pololu voltage regulators.

* The board supports two types of [Real-Time Clock](../../doc/Real%20Time%20Clock.md) (RTC) modules - '[DS3231 PiRTC](https://www.adafruit.com/product/4282)' (3x2 header U15) and '[DS3231 Breakout](https://www.adafruit.com/product/3013)' (8-pin header U14). Only one should be attached at a time. See the '[doc/Real Time Clock.md](../../doc/Real%20Time%20Clock.md)' file for setup instructions.

* The recommended installation option for the RX5808 node boards is to use [low-profile sockets](https://www.mouser.com/ProductDetail/Mill-Max/801-93-036-10-012000?qs=WZRMhwwaLl%2F7W%252BkSMqBETQ%3D%3D) in the U1-U8 (9-pin) locations on the PCB. These are shorter and have better contacts than standard socket headers. See the "[Trimming Jig for RotorHazard S32_BPill Nodes](trimjig.md)" document for information about trimming the pins on the node boards.

* An optional [INA219](https://www.adafruit.com/product/904) voltage and current-sensing module may be installed on the PCB at position U10. See [here](https://github.com/RotorHazard/rhfiles/raw/main/S32_BPill/mainBuildPics/image10.jpg) for a pic. (Make sure sure the pin designators correspond to those on the main board -- if the INA219 is installed backwards it will be destroyed.) If an INA219 is not installed, then a wire jumper needs to be soldered between the Vin+ and Vin- pins of the U10 pads (as noted on the
[schematic](https://github.com/RotorHazard/RotorHazard/blob/main/resources/S32_BPill_PCB/files/RotorHazard_S32_BPill_SCH_R1.pdf)).

* If you install the Boot0 [jumper wire](https://www.adafruit.com/product/1951) (and leave it installed) then the Raspberry Pi will always be able to flash the BPill. Without the wire, flash-updates will work if the RotorHazard firmware is operational on the BPill (it has a jump-to-bootloader command), but if not then you'd need to move the 2-pin header clip to the '1' position on Boot0. The red wire in [this pic](pic/RH_S32_BPill_Boot0Jumper.jpg) is the Boot0 jumper wire.

* Note that during the first-time power up, if the buzzer is constantly beeping (because the BPill is not yet flashed), you can put the 2-pin header-clip on the '1' position of the Boot0 jumper on the BPill module and press the reset button to silence it, and leave it on there until the initial flash of the BPill. After that, the Boot0 wire jumper should be installed and left in place. See the links above for BPill pinouts.

* The recommended method for installing the node firmware onto the BPill processor is to use the `Update Nodes` button (in the 'System' section on the 'Settings' page) on the RotorHazard web GUI. The "dtoverlay=miniuart-bt" line needs to have been added to the "/boot/config.txt" file on the RPi for the flash-update to succeed (see instructions in '[doc/Software Setup.md](../../doc/Software%20Setup.md)').

* The recommended enclosure is the [RotorHazard S32_BPill Case](../S32_BPill_case/README.md), which features mounting holes for a power button, [shutdown button](../../doc/Shutdown%20Button.md), and status LED.

### About Blue Pills and Black Pills

The "Blue Pill" is a module containing an STM32F1 processor and support components mounted on small board with two rows of 20-pin headers. The most common variant is what we're calling the "[Generic Blue Pill](https://stm32-base.org/boards/STM32F103C8T6-Blue-Pill)".

[RobotDyn](https://robotdyn.com) has a version with several improvements (better parts, thinner board layout, etc), which they called a "[Black Pill](https://stm32-base.org/boards/STM32F103C8T6-RobotDyn-Black-Pill)". See [here for the RobotDyn page](https://robotdyn.com/stm32f103-stm32-arm-mini-system-dev-board-stm-firmware.html).

We like the RobotDyn version more than the generics, but it has become difficult to acquire. In practice, any Blue Pill module with an STM32F103C8T6 processor and a compatible pin layout should work fine with the S32_BPill PCB.

Seaching eBay for "[STM32F103C8T6 Blue Pill](https://www.ebay.com/sch/i.html?_nkw=STM32F103C8T6+Blue+Pill)" should lead to a number of good, cheap options for acquiring compatible modules.

Note that there are other types of "Black Pill" modules out there with different pinouts. It is possible (with some tweaking) to use an STM32F4 ("Black Pill") module with the S32_BPill PCB; see [here for more information](stm32f4module.md).

<br>

### Assembled RotorHazard S32_BPill Board

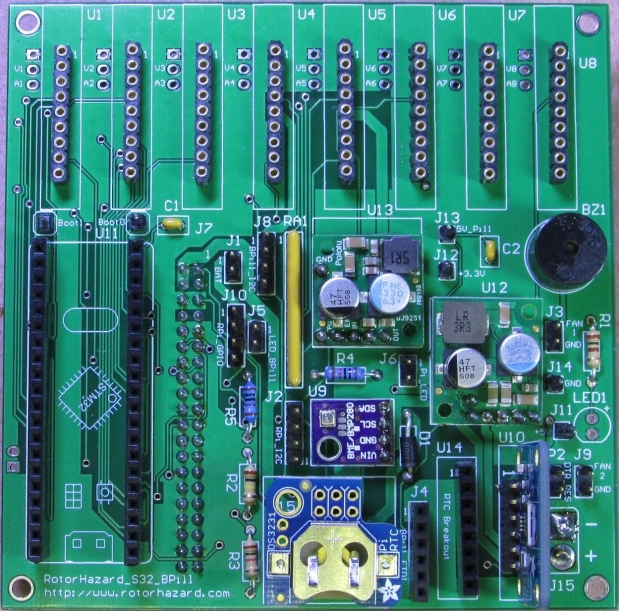
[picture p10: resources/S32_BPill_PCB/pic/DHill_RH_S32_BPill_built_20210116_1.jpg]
DHill_RH_S32_BPill_built_20210116_1


<br>

The RotorHazard S32_BPill schematic and PCB were developed by Bob Duris and [Eric Thomas](http://www.etheli.com).<br>
Special thanks to David Hill for the RotorHazard S32_BPill Main Board Build Guide, and more.

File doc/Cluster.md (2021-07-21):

# Cluster

Additional RotorHazard timers may be attached as "secondary" units, interfaced via their network connection (i.e., WiFi).  The default mode is 'split' (for split timing), which allows multiple timers to be placed around the track to get intermediate lap times.  A 'mirror' mode is also supported, in which the secondary timer will mirror the actions of the primary (for instance as an "LED-only" timer that displays the actions of the primary).

### Configuration

An additional timer may be configured (in 'src/server/config.json' on the primary timer) under "GENERAL" with a "SECONDARIES" entry containing the address of the secondary timer; for example:
```
{
	"GENERAL": {
		... ,
		"SECONDARIES": ["192.168.1.2:5000"]
	}
}
```

Multiple secondary timers may be specified as a list of addresses in track order:
```
{
	"GENERAL": {
		... ,
		"SECONDARIES": ["192.168.1.2:5000", "192.168.1.3:5000"]
	}
}
```

Additional options may be configured, for example:
```
{
	"GENERAL": {
		... ,
		"SECONDARIES": [{"address": "192.168.1.2:5000", "mode": "split", "distance": 5}, {"address": "192.168.1.2:5000", "mode": "mirror"}],
		"SECONDARY_TIMEOUT": 10
	}
}
```
* "address": The IP address and port for the secondary timer.
* "mode": The mode for the timer (either "split" or "mirror").
* "distance": The distance from the previous timer (used to calculate speed).
* "queryInterval": Number of seconds between heartbeat/query messages (default 10).
* "recEventsFlag": Set 'true' to propogate timer events from primary (default 'false' for "split" timer, 'true' for "mirror" timer).
* "SECONDARY_TIMEOUT": Maximum number of seconds to wait for connection to be established.

The "address" value may be specified using asterisk-wildcard characters. For instance, if the IP address of the 'primary' timer is "192.168.0.11":  `"*.77" => "192.168.0.77"`, `"*.*.3.77" => "192.168.3.77"`, `"*" => "192.168.0.11"`

On the secondary timer, no configuration changes are needed.

### Clock Synchronization

The accuracy of reported split times will be higher if all timers have their clocks synchronized. Adding precision [real-time clock (RTC) devices](Real%20Time%20Clock.md) like the [DS3231](https://www.adafruit.com/product/3013) to all the timers can accomplish this, or NTP can be configured to operate between the timers as shown below.

On all timers:

	sudo apt-get install ntp

On the primary, edit /etc/npd.conf and add lines similar to:

	restrict 192.168.123.0 mask 255.255.255.0
	broadcast 192.168.123.255
	
On the secondaries, edit /etc/npd.conf and add lines similar to:

	server 192.168.123.1

On all timers:

	sudo systemctl stop systemd-timesyncd
	sudo systemctl disable systemd-timesyncd
	sudo service ntp restart

### Random number generator

The random number generator helps improve WiFi connectivity (maintains entropy for encryption). Activate hardware RNG to improve available entropy.

	sudo apt-get install rng-tools

Edit /etc/default/rng-tools and uncomment the line:

    HRNGDEVICE=/dev/hwrng

Then, restart rng-tools with

    sudo service rng-tools restart

### Notes

For best results, the primary and secondary timers should be running the same version of the RotorHazard server.

Missed/incorrect split times will have no impact on the recording of lap times by the primary timer.

To enable the announcement of split times, see the "*Cluster/Split Timer*" option on the *Settings* page in the *Audio Control* section. To enable audio indicators of when a cluster/secondary timer connects and disconnects, select the "*Cluster Timer Connect / Disconnect*" checkbox under "*Indicator Beeps*". (Note that these options will only be visible if a secondary timer is configured.)

The status of connected secondary timers may be viewed on the *Settings* page in the *Status* section. (This status information is also available on the *Run* page.) The following items are displayed:
 * *Address* - Network address for the secondary timer (click to bring up the web-GUI for the timer)
 * *Type* - After the address will be an 'S' if split timer or an 'M' if mirror timer
 * *Latency: last min avg max* - Network latency (in milliseconds) for heartbeat/query messages
 * *Disconnects* - Number of times the secondary timer has been disconnected
 * *Contacts* - Number of network contacts with the secondary timer
 * *Time Diff* - Time difference (in milliseconds) between system clocks on primary and secondary timer
 * *Up* - Number of seconds the secondary timer has been connected
 * *Down* - Number of seconds the secondary timer has been disconnected
 * *Availability* - Availability rating (as a percentage) for the secondary timer
 * *Last Contact* - Time (in seconds) since last contact with the timer, or a status message

The web-GUI for the secondary timer may be accessed by clicking on the *Address* value on the status display on the primary timer. From there, lap history may be viewed, marshaling performed and settings adjusted.

When a secondary timer operating in 'split' mode establishes a connection (aka joins the cluster), the database on the timer is backed up and then any existing race data are cleared. The filenames on these backups will have the form "autoBkp_database_YYYYMMDD_HHMMSS.db". The number of these "autoBkp" files retained is limited by the DB_AUTOBKP_NUM_KEEP setting (in "config.json" under GENERAL), with the default value of 30.

A secondary can also be a primary, but sub-splits are not propagated upwards.

If you want to use a Wi-Fi based cluster, instructions for setting up an access point (Wi-Fi hotspot) can be found at
<https://www.raspberrypi.org/documentation/configuration/wireless/access-point.md>.
Also, read <https://github.com/mr-canoehead/vpn_client_gateway/wiki/Configuring-the-Pi-as-a-WiFi-Access-Point>
and <https://superuser.com/questions/1263588/strange-issue-with-denyinterfaces-in-access-point-config>.
Specifically, add `denyinterfaces wlan0` to `/etc/dhcpcd.conf` and `sudo nano /etc/network/interfaces.d/wlan0`
to add

```
allow-hotplug wlan0
iface wlan0 inet static
	address 10.2.2.1
	netmask 255.255.255.0
	network 10.2.2.0
	broadcast 10.2.2.255
	post-up systemctl restart hostapd
```
to make dhcpcd play nice with hostapd.

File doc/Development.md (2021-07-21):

# Development

This document is primarily for developers.

If you plan to contribute to RotorHazard by opening a [pull request](https://help.github.com/en/github/collaborating-with-issues-and-pull-requests/about-pull-requests) for a bugfix or feature, please read the following text before you start. This will help you in submitting your contribution in a form that has a good chance of being accepted.

## Using git and GitHub

Ensure you understand the GitHub workflow: [https://guides.github.com/introduction/flow/index.html](https://guides.github.com/introduction/flow/index.html)

Keep pull requests focused on one thing only, since this makes it easier to merge and test in a timely manner.

If you need help with pull requests there are guides on GitHub here: [https://help.github.com/articles/creating-a-pull-request](https://help.github.com/articles/creating-a-pull-request)

The main flow for a contributing is as follows:

1. Login to GitHub, go to the [RotorHazard repository](https://github.com/RotorHazard/RotorHazard) and press `fork`
2. Then using the command line/terminal on your computer: `git clone <url to YOUR fork>`
3. `cd RotorHazard`
4. `git checkout main`
5. `git checkout -b my-new-code`
6. Make changes
7. `git add <files that have changed>`
8. `git commit`
9. `git push origin my-new-code`
10. Create a pull request using the GitHub web UI to merge your changes from your new branch into `RotorHazard/main`
11. Repeat from step 4 for new other changes

The primary thing to remember is that separate pull requests should be created for separate branches.  Never create a pull request from your `main` branch.

Once you have created the PR, every new commit/push in your branch will propagate from your fork into the PR in the main GitHub/RotorHazard repo. Checkout another branch first if you want something else.

Later, you can get the changes from the RotorHazard repository into your `main` branch by adding the RotorHazard repository as a [git remote](https://help.github.com/en/github/collaborating-with-issues-and-pull-requests/configuring-a-remote-for-a-fork) ("upstream") and merging from it as follows:

1. `git remote add upstream https://github.com/RotorHazard/RotorHazard.git`
2. `git checkout main`
3. `git pull upstream main`
4. `git push origin main` (this is an optional step that will update your repository on GitHub)

<br>

If using Windows, [TortoiseGit](https://tortoisegit.org) is highly recommended.

## Coding Style

When code is added to an existing file, the new code should follow what's already there in terms of indentation (spaces vs tabs), braces, naming conventions, etc.

If a PR is modifying functionality, try to avoid unnecessary whitespace changes (i.e., adding/removing trailing spaces or newlines), as this makes it harder to see the functional changes. Improvements to whitespace and code style should be implemented with PRs that do only those things.

## Eclipse PyDev Project

The [Eclipse IDE](https://www.eclipse.org/eclipseide/) (with the [PyDev](https://www.pydev.org) extension) may be used to edit the Python source code -- the ".project" and ".pydevproject" files define the project, which may be loaded via "File | Open Projects from File System..." in Eclipse.

The [PyLint](https://www.pylint.org) code analyzer is used to improve and reduce bugs in the code. All Python code in the project should be able to pass PyLint analysis with minimal errors and warnings. See the [PyLint install](https://www.pylint.org/#install) page for instructions on installation; on Windows the package may be installed via the command:  `python -m pip install pylint`

See [here](https://www.pydev.org/manual_adv_pylint.html) for enabling PyLint code analysis on Eclipse with PyDev. With its default settings PyLint will flag more warnings than we want to deal with, so we disable some of them by navigating (in Eclipse) to "Preferences | PyDev | Editor | Code Analysis | PyLint" and entering the following into the box under "Arguments to pass to the pylint command":  `--disable=broad-except,bare-except,logging-not-lazy,logging-format-interpolation,global-statement,try-except-raise,unused-argument`

The batch/script files in the 'tools' directory may be used to run the PyLint analysis from the command line: 'pylintchk' checks for errors only, 'pylintchkw' checks for errors and warnings.

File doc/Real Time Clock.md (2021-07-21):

# Real Time Clock

The standard Raspberry Pi does not feature a real-time clock (RTC) -- when it has an internet connection the Pi will fetch the current date and time from an online server, but if an internet connection is not available when the Pi starts up, its date/time will be wrong.  (It will usually revert to the last date/time it was using, and go from there.)

Adding a real-time clock module addresses this problem.  The [DS3231](https://www.adafruit.com/product/3013) module is recommended, as it keeps very accurate time.  There are other, cheaper modules that will also do the job (albeit with less precision), such as the [PCF8523](https://www.adafruit.com/product/3295) and [DS1307](https://www.adafruit.com/product/3296).

The RTC module uses an onboard coin-cell battery ([CR1220](https://www.adafruit.com/product/380)), which allows it to keep track of time while the system is powered off.

### Wiring

If you're using an [S32_BPill PCB](../resources/S32_BPill_PCB/README.md), mounting points for two types of RTC modules are provided. For other PCBs, see below.

The RTC module connects to the Raspberry Pi via the I2C bus.  The following four pads on the RTC module need to be wired to the corresponding connections going to the Pi:  `Vin, GND, SCL, SDA`.  If using the DS3231 or PCF8523, the Vin pad can be wired to 3.3V or 5V.  For the DS1307 use 5V.  The other pads (besides those four) on the RTC module should be left unconnected.

Here is an example of wiring a DS3231 module via a Delta5 V2 PCB:

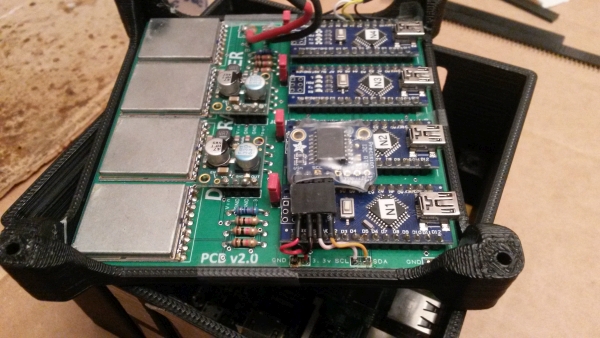
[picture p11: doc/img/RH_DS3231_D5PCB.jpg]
DS3231 wiring


If you're using one of the newer (Arduino-based) [RotorHazard PCBs](../resources/PCB/README.md), there are several places on the board where these connections are available.

### Configuration

The following instructions apply to the standard [Raspberry Pi OS](https://www.raspberrypi.org/downloads/raspberry-pi-os) that is installed for RotorHazard.

Run the following command to verify that the RTC module is wired properly:
```
sudo i2cdetect -y 1
```
The response should look something like this:
```
     0  1  2  3  4  5  6  7  8  9  a  b  c  d  e  f
00:          -- -- -- -- -- 08 -- 0a -- 0c -- 0e --
10: 10 -- 12 -- 14 -- 16 -- -- -- -- -- -- -- -- --
20: -- -- -- -- -- -- -- -- -- -- -- -- -- -- -- --
30: -- -- -- -- -- -- -- -- -- -- -- -- -- -- -- --
40: -- -- -- -- -- -- -- -- -- -- -- -- -- -- -- --
50: -- -- -- -- -- -- -- -- -- -- -- -- -- -- -- --
60: -- -- -- -- -- -- -- -- 68 -- -- -- -- -- -- --
70: -- -- -- -- -- -- -- --
```
The "68" represents the I2C address of the RTC module.  (After the Pi is configured to use the module, this value changes to "UU".)  The addresses from "08" to "16" represent the installed Arduino nodes, and there will usually be 4 or 8 entries (matching the number of nodes).

Enter the following command to edit the "/boot/config.txt" file:
```
sudo nano /boot/config.txt
```
If using the DS3231, add the following line to the end of the file:
```
dtoverlay=i2c-rtc,ds3231
```
(If using the PCF8523, make it `dtoverlay=i2c-rtc,pcf8523`; if using the DS1307, make it `dtoverlay=i2c-rtc,ds1307`.)

Hit *Ctrl-O* and *Enter* to save the file and then *Ctrl-X* to exit the editor.

At this point, reboot the Pi:
```
sudo reboot
```
A startup-service file is needed to make the Pi read the time from the RTC module when the system starts up.  To create this file, enter the following command:
```
sudo nano /etc/systemd/system/hwclock-start.service
```
Copy and paste the text below into the editor:
```
[Unit]
Description=hwclock-start to read rtc and write to system clock
After=sysinit.target

[Service]
Type=oneshot
ExecStart=/sbin/hwclock --hctosys --utc

[Install]
WantedBy=basic.target
```
Hit *Ctrl-O* and *Enter* to save the file and then *Ctrl-X* to exit the editor.

To configure and enable this startup service, enter the following commands:
```
sudo chmod 644 /etc/systemd/system/hwclock-start.service
sudo chown root:root /etc/systemd/system/hwclock-start.service
sudo systemctl daemon-reload
sudo systemctl enable hwclock-start.service
sudo systemctl start hwclock-start.service
```
At this point the RTC module is installed and configured.  When the Pi starts up, it should read the date/time from the RTC module and always have the correct value.  If the Pi has an internet connection it will still use it to fetch the current date and time, and it will update the RTC module with the fetched date/time.

### Testing

Entering the `date` command will display the current system time of the Pi.

The command below may be used to verify the date/time values:
```
timedatectl status
```
The response should look something like this:
```
               Local time: Sat 2020-08-29 19:15:01 EDT
           Universal time: Sat 2020-08-29 23:15:01 UTC
                 RTC time: Sat 2020-08-29 23:15:01
                Time zone: America/New_York (EDT, -0400)
System clock synchronized: yes
              NTP service: active
          RTC in local TZ: no
```
If an RTC module is not installed or is not working properly, the third line in the response will be "RTC time: n/a".

The operation of the RTC startup service can be verified with the following command:
```
journalctl -b | grep 'hwclock-start to read rtc'
```
The response should contain one or more instances of lines similar to these:
```
Aug 29 19:01:49 pi3number98 systemd[1]: Starting hwclock-start to read rtc and write to system clock...
Aug 29 19:01:51 pi3number98 systemd[1]: Started hwclock-start to read rtc and write to system clock.
```

The current time held by RTC module can be queried via the `sudo hwclock -r` command.  Adding the -D parameter will provide additional information:  `sudo hwclock -D -r`

<br />

*References:*  The information in [this forum post](https://www.raspberrypi.org/forums/viewtopic.php?t=209700#p1572546) was used when creating these instructions.

-----------------------------

See Also:  
[doc/Hardware Setup.md](Hardware%20Setup.md)  
[doc/Software Setup.md](Software%20Setup.md)

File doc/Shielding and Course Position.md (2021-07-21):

# Shielding and Course Position

## Add a Directional RF Shield

Illustration of timer shielding

A directional RF shield significantly improves the system's ability to reject false passes. This improves the timer's ability to collect accurate timing data, and allows operators to design courses that pass closely to the timing gate. 

Construct a directional shield that leaves a line of sight open between the timer and the timing gate, but blocks or attenuates RF signals from other directions. The most popular options to accomplish this are:

* Place the system inside a metal box with one side open, such as an ammo can, paint can, metal bucket, or computer case.
* Dig a hole into the ground and place your case within it.
* Line your system case with copper tape.

It is recommended to attach the electrical ground on the timer to your shield.

### Examples

Lining a case with copper tape is a common method of creating a directional shield.

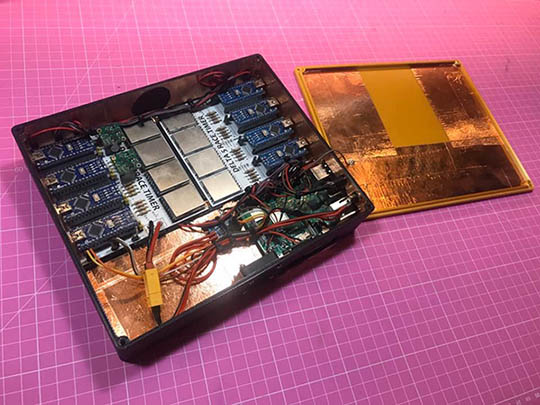
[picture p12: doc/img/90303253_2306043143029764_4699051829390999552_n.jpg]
Copper foil lined case

_Courtesy Cerberus Velvet_

<hr />

Outdoors, digging a hole can make use of the ground for basic shielding.

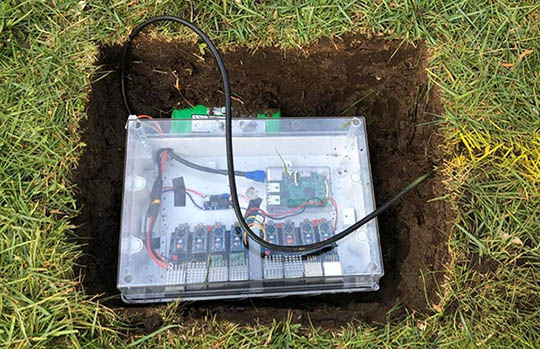
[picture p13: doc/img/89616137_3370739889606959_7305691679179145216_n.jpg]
Timer placed into cut hole in ground

_Courtesy Sebi Wburg_

## Timer Positioning

Illustration of timer position relative to course

The RF shield works best when you can block most of the race course while leaving the timer exposed from the direction of the timing gate.

* Place the timer just outside the gate post.
* Place the timer on the inner side of the course line, facing outward and away from the rest of the course. 
* Avoid having the course cross in front of the timer.

### Examples

Place the opening of the shield toward the gate, blocking the course beside and behind. A cardboard box simply wrapped in aluminum foil can be very effective.

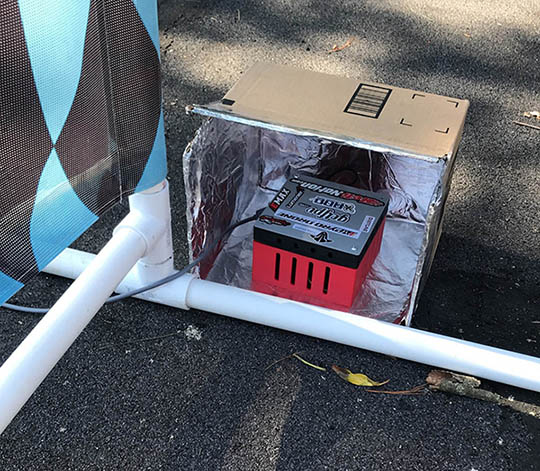
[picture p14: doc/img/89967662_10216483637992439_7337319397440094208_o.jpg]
Cardboard box with time sitting next to gate post

_Courtesy Mark Silva_

<hr />

From the pilot station and race operations outside of the course, you should be able to see the timer inside its shield.

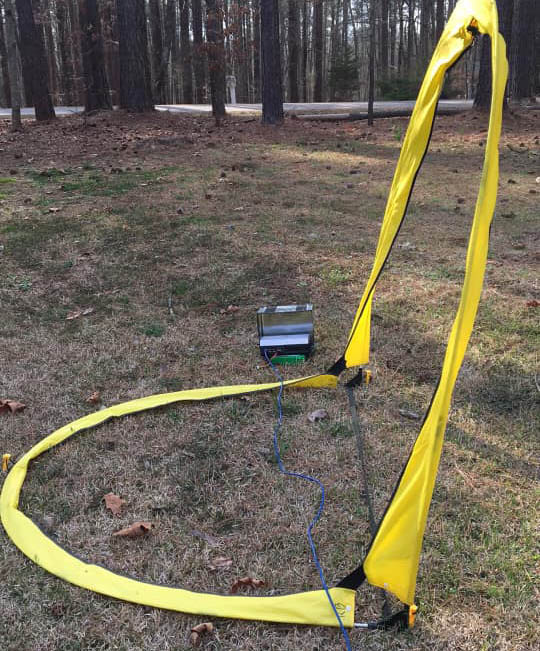
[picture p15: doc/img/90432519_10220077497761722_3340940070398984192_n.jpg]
Gate with timer on far side

_Courtesy Roger Bess_

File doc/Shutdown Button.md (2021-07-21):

# Shutdown Button and Status LED

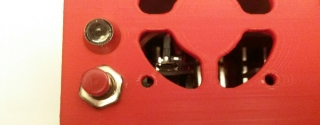
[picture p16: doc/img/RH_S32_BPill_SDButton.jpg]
Button and LED


When the RotorHazard S32_BPill hardware is used, the standard setup is to have a shutdown button and a status (AUX) LED wired to the PCB. See the [RotorHazard S32_BPill Case Build Guide](../resources/S32_BPill_case/detailedCaseBuild.md) for details on the wiring. The S32_BPill PCB also supports a buzzer, which provides feedback sounds.

For the shutdown features to operate correctly, the Raspberry Pi needs have its '/boot/config.txt' file configured as [described](Software%20Setup.md#s32btconfig) in the '[doc/Software Setup.md](Software%20Setup.md)' document.

### Shutdown Button

When the RotorHazard server is running, the button, LED and buzzer will operate as follows:

* When the button is pressed, the buzzer will emit a short beep.

* While the button is held, the LED will show a fast-flashing pattern.

* If the button is held for more than 2.5 seconds, a system shutdown is initiated. The buzzer will emit a medium-length beep, and the LED will stop flashing and be steady on. At this point the button can be released. The buzzer will emit a series of short beeps (for several seconds), followed by a long beep, and the LED will turn off. At this point it is safe to power down the timer.

* If a shutdown is initiated via the RotorHazard web GUI, the buzzer and LED feedback will be similar to what is described above.

When the RotorHazard server is not running there will be less LED and buzzer feedback, but the button may still be used to shut down the system (as long as the '/boot/config.txt' file is configured as [described](Software%20Setup.md#s32btconfig)). In this case the button needs to be held in longer (5-10 seconds), until a buzzer beep is emitted and the LED is steady on. After that, the buzzer and LED feedback should be similar to what is described above.

### Status (AUX) LED Patterns

When the Raspberry Pi is detected (by the BPill processor on S32_BPill board) as operating (not shut down), the Status (AUX) LED will be mostly on, and will blink to indicate activity, as follows:

* One blink every two seconds: The Raspberry Pi is operating, but the RotorHazard server is not running (or has not yet started up).

* One blink every two seconds and additional three-blink patterns mixed in: The RotorHazard server is running, and is "idle" (no web-GUI clients have connected).

* Continuous fast blinking: The RotorHazard server is running, and a web-GUI client has connected. This pattern continues until the server (or the system) is shut down (regardless of whether or not web-GUI clients are currently connected).

### Buzzer Beep Patterns

* When the timer is first powered on, the buzzer should always emit two short beeps. A similar pattern is emitted when the RotorHazard server starts up.

* When the first web-GUI client connects to the RotorHazard server, the buzzer will emit one short beep.

* When the shutdown button is pressed, the buzzer will emit a short beep.

* When a system shutdown is in progress, the buzzer will emit a series of short beeps (for several seconds), followed by a long beep. (At this point it is safe to power down the timer.)

### Configuration Parameters

The following parameters may be configured (in 'src/server/config.json') under "GENERAL":

* SHUTDOWN_BUTTON_GPIOPIN : The GPIO pin number on the Raspberry Pi for the shutdown button (defaults to 18)

* SHUTDOWN_BUTTON_DELAYMS : The length of time (in milliseconds) that the button needs to be held to initiate a shutdown (defaults to 2500)

<br/>

-----------------------------

See Also:  
[doc/Software Setup.md](Software%20Setup.md)<br>
[doc/Hardware Setup.md](Hardware%20Setup.md)<br>
[doc/User Guide.md](User%20Guide.md)

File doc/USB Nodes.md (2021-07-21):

# USB Nodes

Hardware nodes may be connected into the system via USB.  A node can be created with an Arduino, an RX5808 module, and six wires; with the connections shown below.

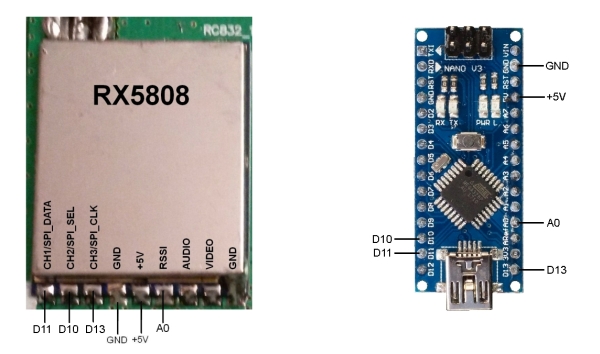
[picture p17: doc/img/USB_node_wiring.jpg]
USB node wiring

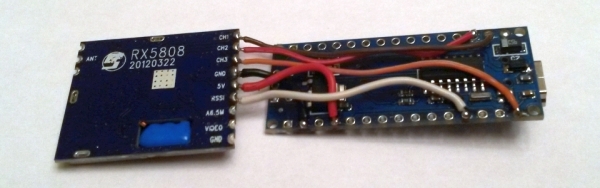
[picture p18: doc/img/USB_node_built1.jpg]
USB node built1

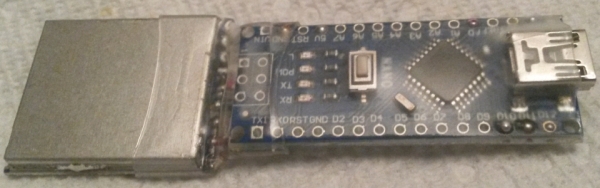
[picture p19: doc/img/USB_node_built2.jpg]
USB node built2


The above build uses an Arduino Nano V3.0 16M 5V ATmega328P module (which can be found on [eBay](https://www.ebay.com/sch/i.html?_nkw=Arduino+Nano+V3.0+16M+5V+ATmega328P)) and an RX5808 module (which can be found on [banggood](https://www.banggood.com/search/rx5808-module.html) and [eBay](https://www.ebay.com/sch/i.html?_nkw=rx5808+module)).

USB nodes may be plugged into the USB ports of the Raspberry Pi on a standard RotorHazard timer build, and they will appear in the system as serial ports.  If the timer also has "standard" (PCB-based) nodes, the USB/serial nodes will add to the total number of nodes available.  (Node counts of 9 or higher are possible.)

The nodes may also be attached (via USB) to [any computer running the RotorHazard server](Software%20Setup.md#otheros).  

USB nodes need to be configured in the "SERIAL_PORTS" section in the "src/server/config.json" file, as shown in the examples below.

#### Raspberry Pi

On the Raspberry Pi, an attached USB node will be referenced with a serial port name like "/dev/ttyUSB0".  The command ```ls /dev/ttyUSB*``` will show the current USB serial ports.  The "src/server/config.json" file should contain an entry like this:
```
	"SERIAL_PORTS": ["/dev/ttyUSB0"],
```
Multiple USB nodes would be configured like this:
```
	"SERIAL_PORTS": ["/dev/ttyUSB0","/dev/ttyUSB1"],
```

#### Windows Computer

On a Windows computer, an attached USB node will be referenced with a serial port name like "COM5".  The current ports may be viewed in the Windows Device Manager under "Ports (COM & LPT)" -- when the USB node is plugged in, its entry should appear.  It may be necessary to install or update its driver (named something like "USB-SERIAL").  The "src/server/config.json" file should contain an entry like this:
```
	"SERIAL_PORTS": ["COM5"],
```
Multiple USB nodes would be configured like this:
```
	"SERIAL_PORTS": ["COM5","COM6"],
```

#### Node Code

The RotorHazard node code will need to be uploaded (flashed) to the Arduino using [the "standard" method](Software%20Setup.md#install-receiver-node-code-arduinos) (via the Arduino IDE).  The NODE_NUMBER value (in "src/node/config.h") is ignored for USB nodes; it can be left at 0.

<br/>

-----------------------------

See Also:  
[doc/Hardware Setup.md](Hardware%20Setup.md)  
[doc/Software Setup.md](Software%20Setup.md)  
[doc/User Guide.md](User%20Guide.md)

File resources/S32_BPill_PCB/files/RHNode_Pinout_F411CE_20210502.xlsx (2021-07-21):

S32_BPill Pinout for RHNode
Pins are numbered in standard CCW DIP fashion starting with Pin 1 at Vbat
DIP Pin Number | Standard Designator | F411CE Module | Pins to Pi | Pins to Modules | Pins to Other | Notes | Available Pins
1 | Vbat | VB |  |  | RTC_BAT | Use if internal RTC is desired
2 | PC_13 | PC13 |  |  | LED1 | On-board LED
3 | PC_14 | PC14 |  |  | OSC32_IN | Connected to RTC Crystal
4 | PC_15 | PC15 |  |  | OSC32_OUT | Connected to RTC Crystal
5 | PA_0 | R | Alt - Pill_Reset | RSSI_0 |  | A/D Input
6 | PA_1 | A0 |  | RSSI_1 |  | A/D Input
7 | PA_2 | A1 |  | RSSI_2 |  | A/D Input
8 | PA_3 | A2 |  | RSSI_3 |  | A/D Input
9 | PA_4 | A3 |  | RSSI_4 |  | A/D Input
10 | PA_5 | A4 |  | RSSI_5 |  | A/D Input
11 | PA_6 | A5 |  | RSSI_6 |  | A/D Input
12 | PA_7 | A6 |  | RSSI_7 |  | A/D Input
13 | PB_0 | A7 | GPIO24 |  |  | (Signal from RPi)
14 | PB_1 | B0 |  |  | ADC1_9 | Battery Monitor (resistor divider)
15 | PB_10 | B1 |  | Alt - RSSI_0 | I2C2_SCL | I2C Interface for other peripherals
16 | PB_11 | B2 |  |  | I2C2_SDA | I2C Interface for other peripherals
17 | RESET | B10 | Pill_Reset |  |  | From digital output on Pi
18 | +3.3V | 3V3
19 | GND | GND | GND
20 | GND | 5V |  |  |  | Do not connect!
21 | PB_12 | B12 |  | CH2_4
22 | PB_13 | B13 |  | CH2_5
23 | PB_14 | B14 |  | CH2_6
24 | PB_15 | B15 |  | CH2_7
25 | PA_8 | A8 |  |  | PA_8_OUT | Direct Drive Buzzer, 5V Tolerant
26 | PA_9 | A9 | Serial1_Tx |  |  | Goes to Serial_Rx on Pi
27 | PA_10 | A10 | Serial1_Rx |  |  | Goes to Serial_Tx on Pi
28 | PA_11 | A11 |  |  | USB_DM | Connected to Micro USB Connector
29 | PA_12 | A12 |  |  | USB_DP | Connected to Micro USB Connector
30 | PA_15 | A15 |  |  | AUX_LED | Direct Drive External LED
31 | PB_3 | B3 |  | CH1_All
32 | PB_4 | B4 |  | CH3_All
33 | PB_5 | B5 |  |  | SPI1_MOSI | LED_STRIP
34 | PB_6 | B6 |  | CH2_0
35 | PB_7 | B7 |  | CH2_1
36 | PB_8 | B8 |  | CH2_2
37 | PB_9 | B9 |  | CH2_3
38 | +5V | 5V | +5V
39 | GND | GND | GND
40 | +3.3V | 3V3
 | (Denotes Fixed Function) |  | Boot0 |  |  | From digital output on Pi (Hold high on reset for bootloader)
 |  |  | (Boot will have to be strapped from the top header on Blue Pill. Connection is optional but recommended for debugging.) | On the 5808 Modules: CH1=SPI_Data CH2=SPI_LE CH3=SPI_CLK

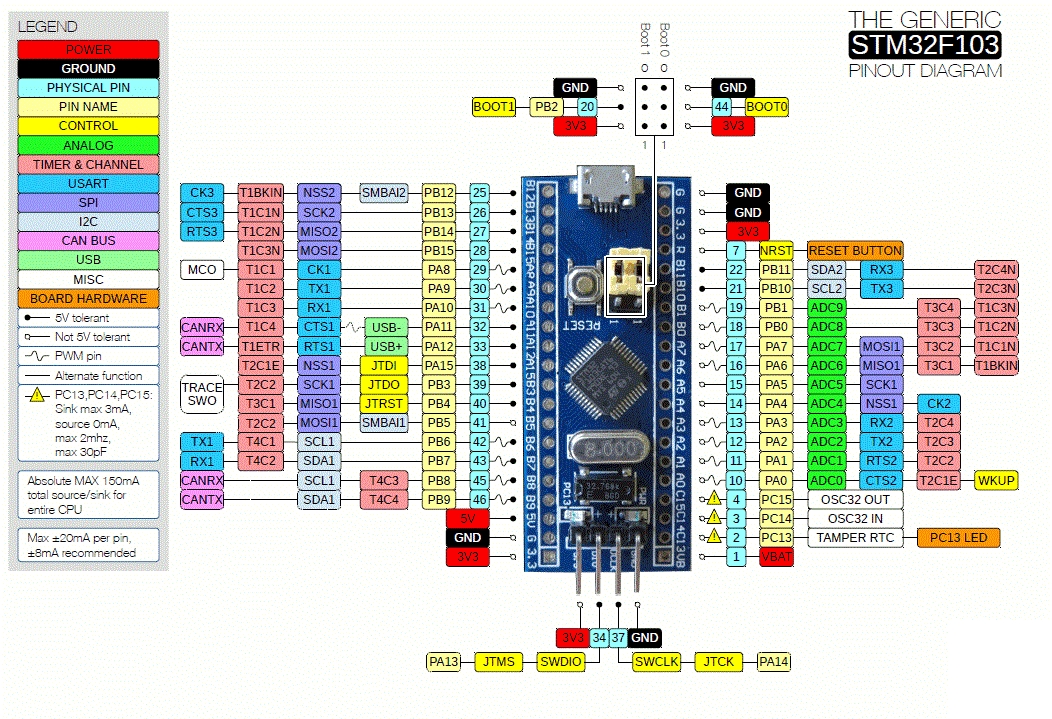
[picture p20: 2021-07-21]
resources/S32_BPill_PCB/files/GenericBluePillPinout.jpg

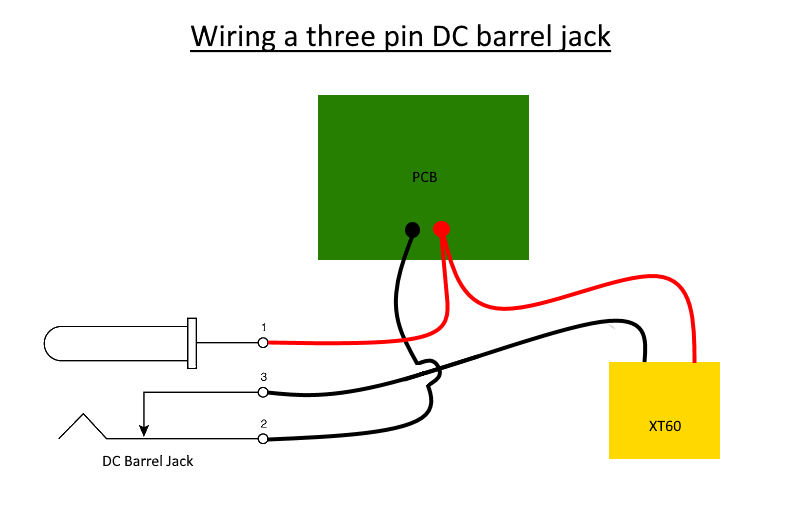
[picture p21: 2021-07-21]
resources/enclosure/Images/WireBarrelJack.png

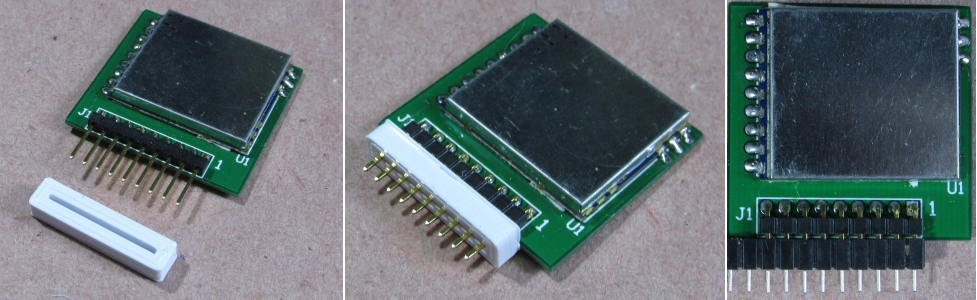
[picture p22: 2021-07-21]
resources/S32_BPill_PCB/pic/nodeTrimJig.jpg

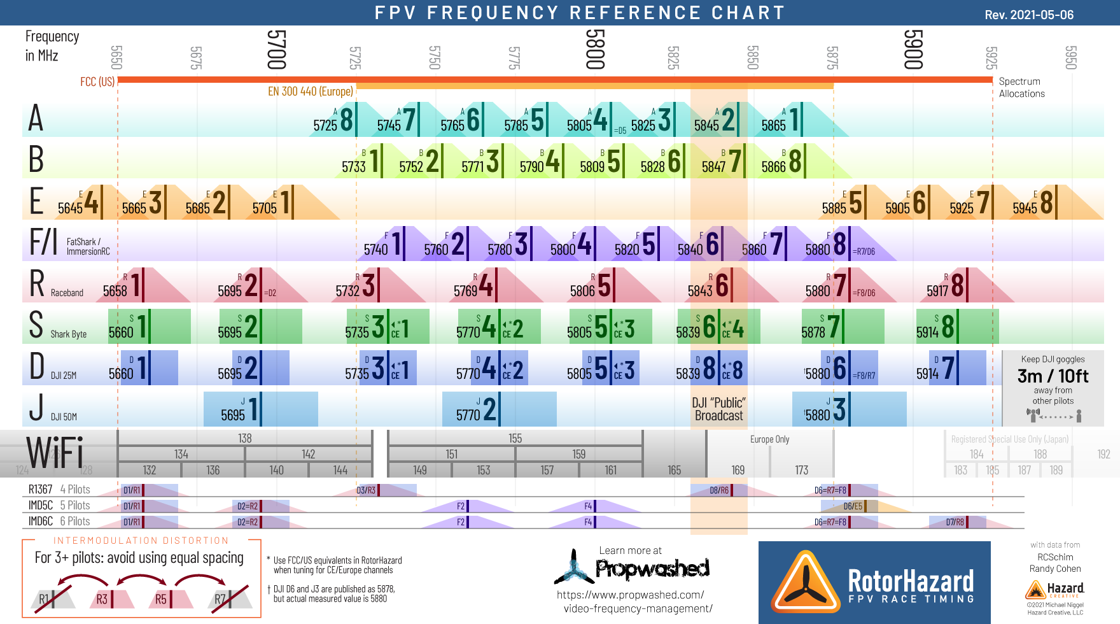
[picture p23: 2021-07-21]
doc/img/Frequency Reference Chart 2021-05-06.png

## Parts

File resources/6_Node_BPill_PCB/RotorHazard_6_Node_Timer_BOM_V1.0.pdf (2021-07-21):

Item Build
Level
Designator | Qty | Part Number | Alternatives | Mouser Ref | Banggood Ref
Optional? | Notes | Link
1 | PCB | U5 | 1 | DS3231SN#T&R

DS3231S#T&R, DS3231SN#,
DS3231S# | 700-DS3231SN#T&R- | -

Yes, fit if you want the real time clock (RTC)

DS3231S is rated for 0 to 70°C,
DS3231SN is rated for -40 to 85°C | https://www.mouser.co.uk/ProductDetail/700-DS3231SN#T&R-
2 | PCB | BZ1 | 1 | CMI-1295-0585T

Any 12mm x 9.5mm 5V
Buzzer | 490-CMI-1295-0585T | - | Yes, used for low voltage alarm | https://www.mouser.co.uk/ProductDetail/490-CMI-1295-0585T
3 | PCB | P12 | 1 | SSW-120-01-T-D

Any 2.54mm 20x2 8.51mm
tall header, single strips also
work | 200-SSW12001TD | - | No | https://www.mouser.co.uk/ProductDetail/200-SSW12001TD
4 | PCB | BT1 | 1

Keystone Electronics
1069 | - | 534-1069 | -

Yes, fit if you want the real time clock
(RTC) | https://www.mouser.co.uk/ProductDetail/534-1069
5 | PCB | C1,C2 | 2 | C0805C104KMRECAUTO

Any 0805 X7R 100nF
capacitor | 80-C0805C104KMRECAUT | -

Yes, these are decoupling capacitors
for INA219 and DS3231. | https://www.mouser.co.uk/ProductDetail/ 80-C0805C104KMRECAUT
6 | PCB | D1,D3 | 2 | 150080VS75000 | Any 0805 LED | 710-150080VS75000 | - | Yes, only fit if you want the onboard
| | | | | | | | power and status LED's

These are driven by 3.3V so check
forward volt drop if using blue or
white LED's and adjust 220r resistor
accordingly | https://www.mouser.co.uk/ProductDetail/710-150080VS75000
7 | PCB | P1 | 1 | XT60 Male | Wire manually to the pad | - | 45394 | No | https://www.banggood.com/search/45394.html
8 | PCB | P2,P3,P16,P17,P18 | 5 | Not required | - | Not required | - | Yes, you can direct solder if required | https://www.mouser.co.uk/ProductDetail/Not required
9 | PCB | P4 | 1 | 3 pin JST SM Female | - | 485-1663 | - | Yes, only needed if you want to use
| | | | | | | | LED rope | https://www.mouser.co.uk/ProductDetail/485-1663
10 | PCB | P5,P14,P15 | 3 | Not required | - | Not required | - | Yes, you can direct solder if required | https://www.mouser.co.uk/ProductDetail/Not required
11 | PCB | P11 | 1 | Not required | - | Not required | - | Yes, you can direct solder if required | https://www.mouser.co.uk/ProductDetail/Not required
12 | PCB | Q1,Q2 | 2 | IRLML6344TRPBF

Any GSD SOT-23 N channel

MOSFET | 942-IRLML6344TRPBF | - | Yes, 1 is used for optional switched
| | | buzzer, the other is used for optional
| | | fan enable control | Make sure if you use an alternative
| | | | the gate, source and drain pins match
| | | | the suggested one | https://www.mouser.co.uk/ProductDetail/942-IRLML6344TRPBF
13 | PCB | R1 | 1 | TLRP3A30WR100FTE

Any 2512 0.1 ohm 1% 3W

resistor | 279-TLRP3A30WR100FTE | - | Yes, only fit if you wish to use the
| | | current reference | | https://www.mouser.co.uk/ProductDetail/279-TLRP3A30WR100FTE
14 | PCB | R2,R7,R8,R9,R11,R12,R13 | 7 | CR0805-JW-104ELF

Any 0805 100k 5% (or better)
resistor | 652-CR0805JW-104ELF | - | No | Buy a few extra in case you drop some | https://www.mouser.co.uk/ProductDetail/652-CR0805JW-104ELF
15 | PCB | R3,R4,R5,R10,R14 | 5 | CR0805-JW-103ELF

Any 0805 10k 5% (or better)
resistor | 652-CR0805-JW-103ELF | - | No | Buy a few extra in case you drop some | https://www.mouser.co.uk/ProductDetail/652-CR0805-JW-103ELF
16 | PCB | R6,R29 | 2 | CR0805-JW-221ELF

Any 0805 220r 5% (or better)

resistor | 652-CR0805-JW-221ELF | - | Yes, only fit if you want the onboard
| | | power and status LED's | Buy a few extra in case you drop some | https://www.mouser.co.uk/ProductDetail/652-CR0805-JW-221ELF
17 | PCB | RX1,RX2,RX3,RX4,RX5,RX6 | 6 | RX5808

IDC-RF variant may be
cheaper on banggood | - | 84775
| | | Yes, 1 of these is required for each
| | | node you wish to fit | | https://www.banggood.com/search/84775.html
18 | PCB | U1 | 1 | INA219AIDR

INA219AID, INA219BID,

INA219BIDR | 595-INA219AIDR | - | Yes, only fit if you wish to use the
| | | current reference | The INA219B is more accurate than
| | | | the A variant | https://www.mouser.co.uk/ProductDetail/595-INA219AIDR
19 | PCB | U2,U3,U4 | 3 | MP1584 | - | 713-106990005 | - | Yes, 1 of these is optional and only
| | | | | | | | used for RGB LED's

Mouser variant only claims up to 18V
input voltage, variants up to 28V exsist
on eBay and are also cheaper, make
sure you get the board and not a
single IC | https://www.mouser.co.uk/ProductDetail/713-106990005
20 | PCB | U2,U3,U4 | 1 | 22-28-4301 | Any 2.54mm header | 538-22-28-4301 | - | No | https://www.mouser.co.uk/ProductDetail/538-22-28-4301
21 | PCB | U6 | 1 | STM32F103C8T6 | - | - | 1668936 | No | https://www.banggood.com/search/1668936.html
22 | PCB | BT1 | 1 | CR1632 | CR1620, CR1616 | - | - | Yes, fit if you want the real time clock
| | | | | | | | (RTC)

CR1632 (140mAh) will last the longests. CR1620 (75mAh), CR1616 (50mAh)
23 | PCB | PCB | 1 | From Github | - | - | - | No | https://www.pcbway.com/project/shareproject/RotorHazard_6_Node_STM32_Lap_Timer.html
24 | Assembly | 1 | RASPBERRYPI_3B+ | Raspberry Pi 4 | - | 1041862 | No | https://www.banggood.com/search/1041862.html
25 | Assembly | | 1 | 8GB + Micro SD card | Any micro SD card between
| | | | | 8GB and 64GB | 467-SDSDQAF3-008G-I | - | No | https://www.mouser.co.uk/ProductDetail/467-SDSDQAF3-008G-I
26 | Assembly | 1 | Raspberry Pi heat syncs | - | - | 1047433 | Yes, either use this or the fans | https://www.banggood.com/search/1047433.html
27 | Assembly | 1 | LCD Voltage Screen | - | - | 1530256 | Yes, only needed if you want to have
| | | | | | | a voltage LED on the case | https://www.banggood.com/search/1530256.html
28 | Assembly | 6 | RX5808 Heat Syncs | Anything up to 24x20x6.5mm | - | 1593902 | Yes, either use these or the fans

The part linked in a 5 pack from
banggood | https://www.banggood.com/search/1593902.html
29 | Assembly | 1 | Thermal Glue | - | - | Yes, either use this or the fans | used to secure the RX5808 heat syncs

30 | Assembly | 11 | M3 8mm Screw | Longer screws may be ok too

- No
31 | Assembly | 4 | M2.5 Countersunk 10mm
| | | screw | Longer screws may be ok too

- No
32 | Assembly | 2 | M2 5mm screw | Longer screws may be ok too

Yes, only needed if the voltage LCD is fitted

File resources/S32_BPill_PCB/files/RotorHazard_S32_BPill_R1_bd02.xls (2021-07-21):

Bill of Materials |  |  | Bill of Materials For Project [RotorHazard_S32_BPill_R1.PrjPCB]
Project: |  | RotorHazard_S32_BPill_R1.PrjPCB
Creation Date: | 12/28/2020 | 3:50:35 PM
Footprint | Comment | LibRef | Designator | Description | Quantity
BZ_12mm | TMB12A05 | Buzzer_12mm | BZ1 | TMB12A05 12mmX9.5mm Buzzer (https://www.amazon.com/TMB12A05-Universal-Active-Electromagnetic-Speaker/dp/B07SL2PJ3J) | 1
Cap Radial 100mil | 0.1uF 50V X7R | C320C104K5R5TA7301 | C1, C2 | Multilayer Ceramic Capacitors MLCC - Leaded 50V 0.1uF 10% X7R (https://www.mouser.com/ProductDetail/KEMET/C320C104K5R5TA7301) | 2
Axial 0.4 Diode | MBR100RLG | MBR1100RLG | D1 | Schottky Diodes & Rectifiers 1A 100V (https://www.mouser.com/ProductDetail/ON-Semiconductor/MBR1100RLG) | 1
HDR 1x2_2.54mm | HDR 1X2 | 961102-6804-AR | J1, J3, J5, J6, J9, JP1, JP2 | Headers & Wire Housings 2P STRT 1 ROW GOLD 6.8MM MATING PIN (https://www.mouser.com/ProductDetail/3M-Electronic-Solutions-Division/2302-6121TG) | 7
HDR 1x4_2.54mm | HDR 1X4 | 961104-6804-AR | J2, J8, J10 | Headers & Wire Housings 4P STRT 1 ROW GOLD 6.8MM MATING PIN (https://www.mouser.com/ProductDetail/3M-Electronic-Solutions-Division/961104-6804-AR) | 3
6-PIN SIL VERT SOCKET | 6 PIN SIL VERT SOCKET | M20-7820646 | J4 | Headers & Wire Housings 6 PIN SIL VERTICAL SOCKET TIN *Note 4 (https://www.mouser.com/ProductDetail/Harwin/M20-7820646) | 1
Header_2X20_Vert_Thru | Header_2X20_Vert_Thru | Header_To_Pi_Cable | J7 | Header_2X20_Vert_Thru (https://www.mouser.com/ProductDetail/Molex/70246-4004) | 1
HDR 1x1_2.54mm | HDR 1X1 | HEADER 1X1 | J11, J12, J13, J14 | Single pin header *Note 2 (https://www.amazon.com/Hotop-Pack-Single-Header-Connector/dp/B06XR8CV8P/) | 4
XT30_M | XT30-M | XT30-M | J15 | XT30 connector male pins (https://www.amazon.com/Finware-Upgrade-Female-Connectors-Battery/dp/B074S7NH3H/) | 1
LED_5mm | LED_5mm | LED_5mm | LED1 | 5mm standard leaded red LED (https://www.mouser.com/ProductDetail/Cree-Inc/C503B-RAN-CZ0C0AA1) | 1
Axial 0.4 100 CF | 100 1/4W 5% | CFR-25JR-52-100R | R1 | Carbon Film Resistors - Through Hole 100ohm 1/4W 5% (https://www.mouser.com/ProductDetail/Yageo/CFR-25JR-52-100R?qs=sGAEpiMZZMsPqMdJzcrNwiPCnpFTGbbhYHVmSfLkWwk%3D) | 1
Axial 0.4 100K CF | 100K 1/4W 5% | CFR-25JR-52-100K | R2 | Carbon Film Resistors - Through Hole 100K ohm 1/4W 5% (https://www.mouser.com/ProductDetail/Yageo/CFR-25JR-52-100K) | 1
Axial 0.4 1K CF | 1K 1/4W 5% | CFR-25JT-52-1K | R3 | Carbon Film Resistors - Through Hole 1/4W 1K Ohm 5% (https://www.mouser.com/ProductDetail/Yageo/CFR-25JT-52-1K?qs=KUIzHt%2Fe91mODjNMcON1KQ%3D%3D) | 1
Axial 0.4 10K MF | 10K 1/4W 1% | MFR-25FRF52-10K | R4 | Metal Film Resistors - Through Hole 10K ohm 1/4W 1% (https://www.mouser.com/ProductDetail/Yageo/MFR-25FRF52-10K?qs=sGAEpiMZZMu61qfTUdNhGztMfEiwFKKTpKeEBKehEYg%3D) | 1
Axial 0.4 1K MF | 1K 1/4W 1% | MFR-25FRF52-1K | R5 | Metal Film Resistors - Through Hole 1K ohm 1/4W 1% (https://www.mouser.com/ProductDetail/Yageo/MFR-25FRF52-1K?qs=sGAEpiMZZMu61qfTUdNhGztMfEiwFKKTY1DevuMNI5M%3D) | 1
RES_SIP_10P | 100K 10Pin SIP | 4610X-101-104LF | RA1 | Resistor Networks & Arrays 10pins 100Kohms Bussed (https://www.mouser.com/ProductDetail/Bourns/4610X-101-104LF?qs=sGAEpiMZZMvrmc6UYKmaNWZq5LK2CquH8Ch17mVAQEE%3D) | 1
RH_S32_Node_PCB | RX5808_PCB | RH_S32_Node | U1, U2, U3, U4, U5, U6, U7, U8 | RX5808 module on PCB with right-angle header pins *Note 1 | 8
BME280_PCB | BME280_BRD | BME280 | U9 | BME280 Temperature, Humidity and Pressure Sensor (https://www.amazon.com/Onyehn-Temperature-Humidity-Barometric-Pressure/dp/B07KR24P6P/) | 1
INA219_PCB_RA | INA219_BRD | INA219_BRD | U10 | INA219 Current Sensor/Voltage Monitor (https://www.adafruit.com/product/904) | 1
DIP40_Plus2 | STM32F103XX BPill | STM32F103XX_BPill | U11 | STMF103XX BPill (https://www.amazon.com/HiLetgo-STM32F103C8T6-Minimum-Development-Learning/dp/B07VKSVM21/) | 1
D36V28FX | D36V28F5 | D36V28F5 | U12 | Pololu D36V28F5 DC/DC Converter (https://www.pololu.com/product/3782) | 1
D24V22FX | D24V22F3 | D24V22F3 | U13 | Pololu D24V22F3 DC/DC Converter (https://www.pololu.com/product/2857) | 1
DS3231_Breakout | DS3231_BBRD | DS3231_Breakout | U14 | ADAFruit DS3231 Breakout Board *Note 3 (https://www.adafruit.com/product/3013) | 1
Pi_RTC | DS3231_Pi_RTC | DS3231_Pi_RTC | U15 | ADAFruit DS3231 PiRTC *Note 3 (https://www.adafruit.com/product/4282) | 1
Parts for Each Node
HDR 1X9 2.54mm RA | HDR 1X9 RA | 649-1012937990904BLF | J1 | 9-Pin RA Header Thru-Hole *Note 5 (https://www.mouser.com/ProductDetail/Amphenol-FCI/10129379-909004BLF?qs=0lQeLiL1qyZfaqCOsdhrCw%3D%3D) | 1
RX5808_MULTI | RX5808 | RX5808_MULTI | U1 | RX5808 Module *Note 6 (https://www.banggood.com/Boscam-5_8G-Wireless-Audio-Video-FPV-Receiver-Receiving-Module-RX5808-for-RC-Drone-FPV-Racing-p-84775.html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) | 1
Notes
1) The number of nodes is up to the user and should be automatically detected. High-quality low-profile sockets made from the strips linked here are recommended. (https://www.mouser.com/ProductDetail/Mill-Max/801-93-036-10-012000?qs=WZRMhwwaLl%2F7W%252BkSMqBETQ%3D%3D) | https://www.mouser.com/ProductDetail/Mill-Max/801-93-036-10-012000?qs=WZRMhwwaLl%2F7W%252BkSMqBETQ%3D%3D | 3) The DS3231 RTCs are optional, but if installed only one should be used at a time. |  | 5) When used with the low-profile sockets the pins should be cut to a length of 3.5mm-4.0mm as measured from the edge of the node PCB.
https://www.mouser.com/ProductDetail/Mill-Max/801-93-036-10-012000?qs=WZRMhwwaLl%2F7W%252BkSMqBETQ%3D%3D | https://www.mouser.com/ProductDetail/Mill-Max/801-93-036-10-012000?qs=WZRMhwwaLl%2F7W%252BkSMqBETQ%3D%3D
2) There are two more single-pin headers that are part of the STM32 CPU component. The one for BOOT0 is required to enable firmware upload. All of the rest are optional. If used these should probably just be separated from the longer breakable strips linked above. |  | 4) Sockets are also recommended for the STM32 CPU and BME280. The best source is probably to get a kit similar to the one linked here from Amazon which will provide enough for several timers. (https://www.amazon.com/Glarks-Straight-Connector-Assortment-Prototype/dp/B076GZXW3Z/) | https://www.amazon.com/Glarks-Straight-Connector-Assortment-Prototype/dp/B076GZXW3Z/ | 6) The "Blue Pill" boards are available from a variety of places and generally have clone versions of the CPU. There is a higher-quality board available from RobotDyn (linked below) but it is often out-of-stock.
 |  | https://www.amazon.com/Glarks-Straight-Connector-Assortment-Prototype/dp/B076GZXW3Z/ | https://www.amazon.com/Glarks-Straight-Connector-Assortment-Prototype/dp/B076GZXW3Z/
 |  | https://www.amazon.com/Glarks-Straight-Connector-Assortment-Prototype/dp/B076GZXW3Z/ | https://www.amazon.com/Glarks-Straight-Connector-Assortment-Prototype/dp/B076GZXW3Z/
 |  | https://www.amazon.com/Glarks-Straight-Connector-Assortment-Prototype/dp/B076GZXW3Z/ | https://www.amazon.com/Glarks-Straight-Connector-Assortment-Prototype/dp/B076GZXW3Z/ | Link to RobotDyn CPU Boards (https://robotdyn.com/stm32f103-stm32-arm-mini-system-dev-board-stm-firmware.html)

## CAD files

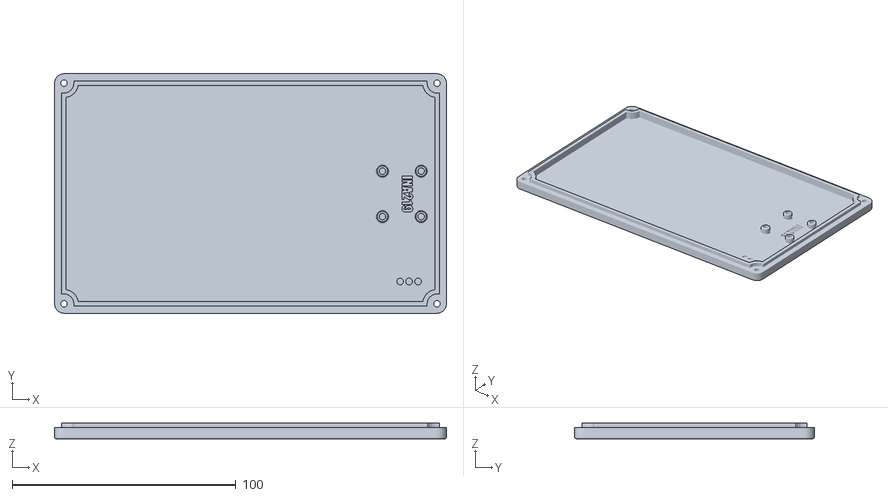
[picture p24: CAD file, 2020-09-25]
Hardware/3D Printed Enclosure/Flat Enclosure/D5 PCB Version/4Node_RHFlatCaseLid.stl
175.0 x 107.0 x 7.00

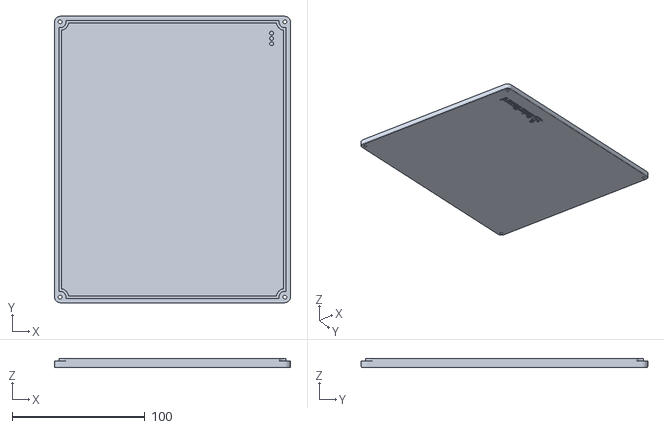
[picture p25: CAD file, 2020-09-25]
Hardware/3D Printed Enclosure/Flat Enclosure/RH PCB Version/V3PCBFlatCase8NodeLID.stl
177.5 x 215.5 x 7.00

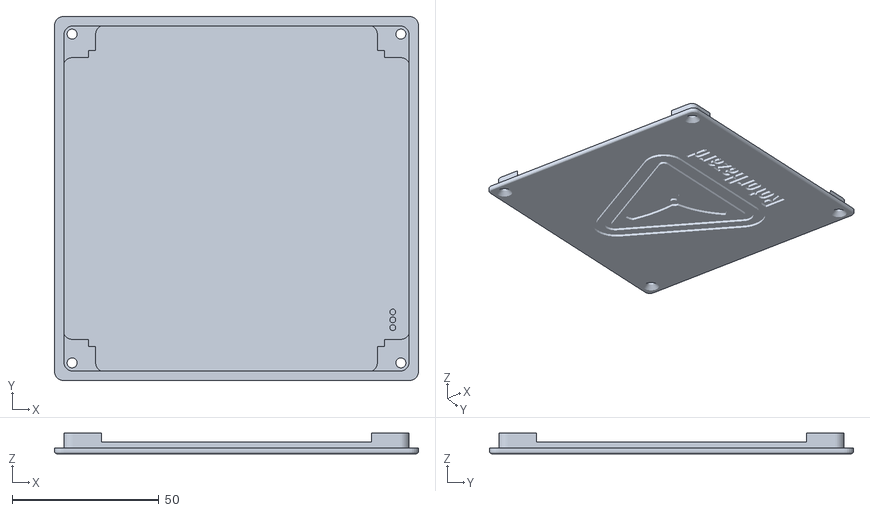
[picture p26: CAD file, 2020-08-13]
resources/enclosure/Lid RotorHazard.stl
124.0 x 124.0 x 7.00

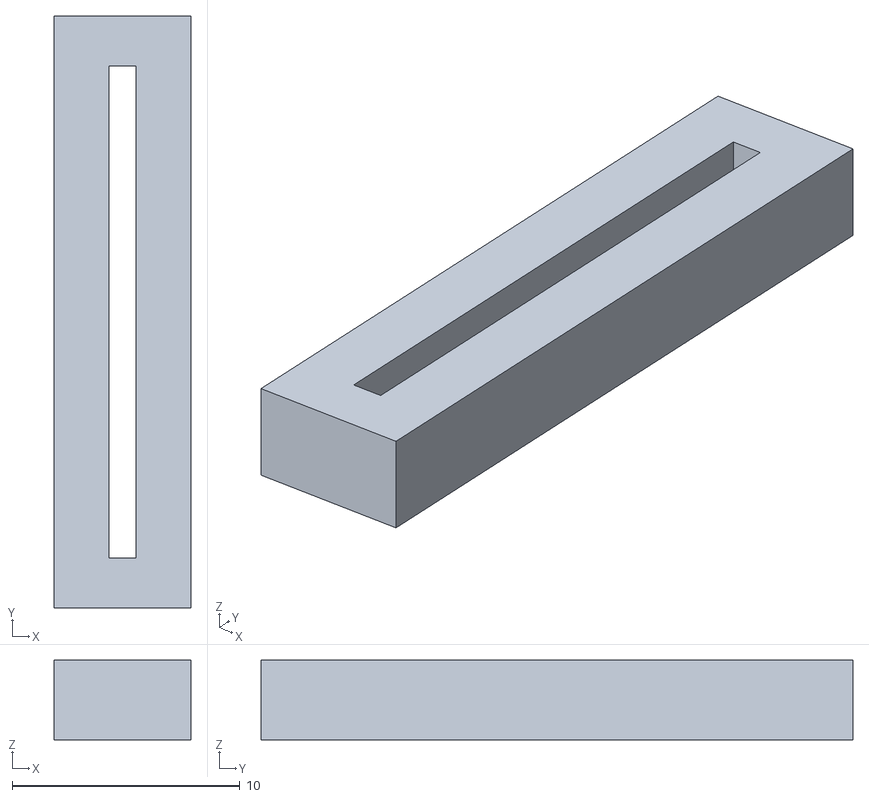
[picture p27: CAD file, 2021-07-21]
resources/S32_BPill_PCB/files/RH_S32_BPill_nodeTrimJig.stl
6.00 x 26.0 x 3.50

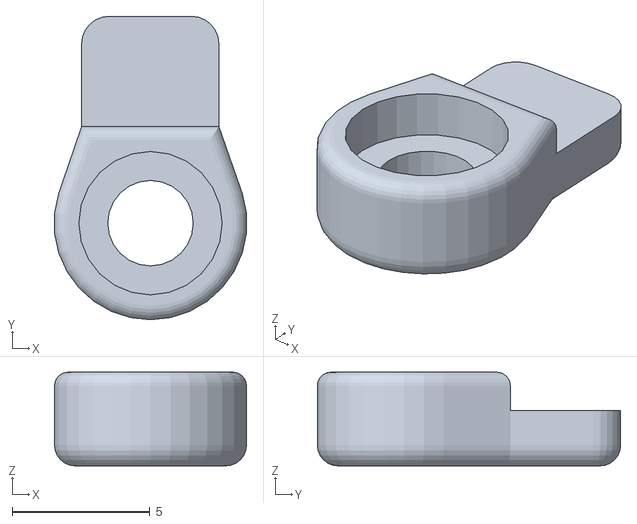
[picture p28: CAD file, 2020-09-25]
Hardware/3D Printed Enclosure/Flat Enclosure/D5 PCB Version/PCB_Clip.stl
6.96 x 11.0 x 3.40

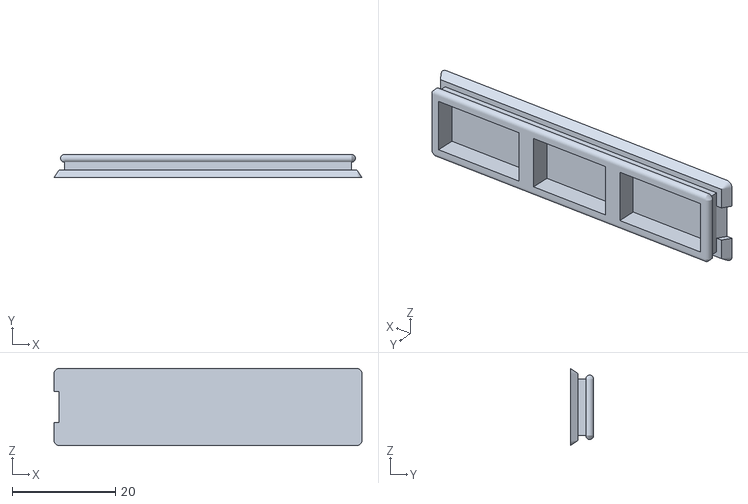
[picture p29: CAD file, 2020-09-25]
Hardware/3D Printed Enclosure/Flat Enclosure/RH PCB Version/PiPortCoverTPU.stl
59.7 x 4.50 x 14.9

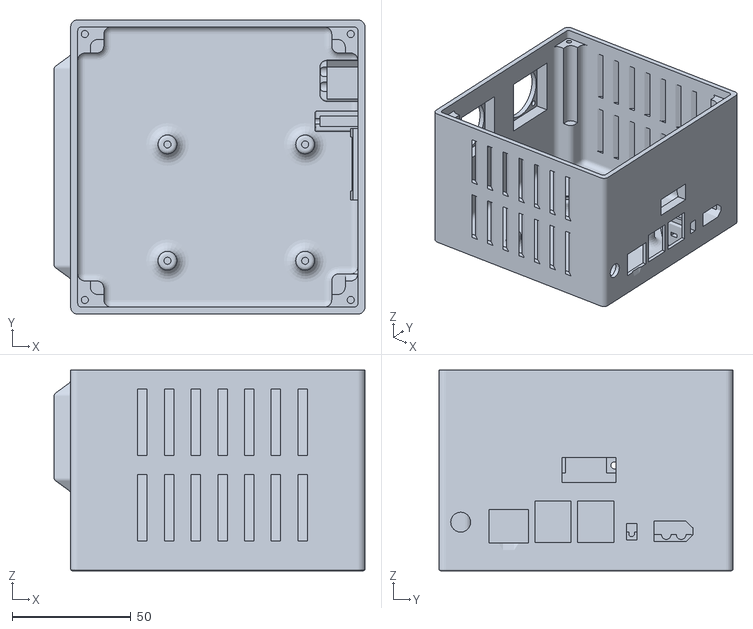
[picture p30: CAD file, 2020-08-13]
resources/enclosure/Box Eight Node.stl
131.0 x 124.0 x 84.5

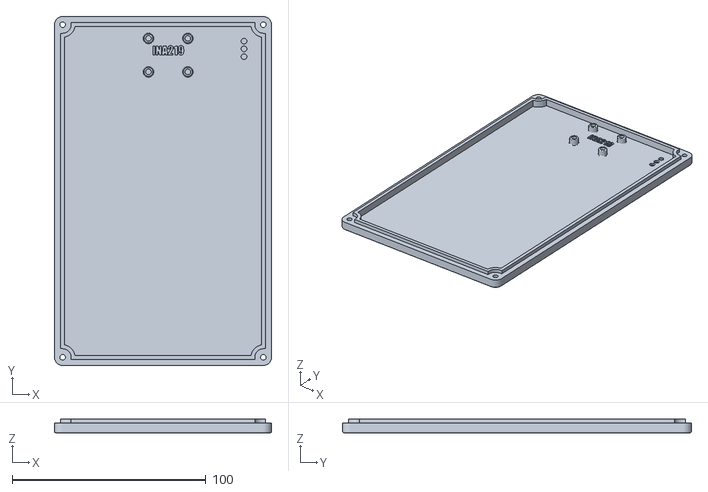
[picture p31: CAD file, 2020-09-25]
Hardware/3D Printed Enclosure/Flat Enclosure/RH PCB Version/V3PCBFlatCase4NodeLID.stl
112.0 x 180.0 x 7.00

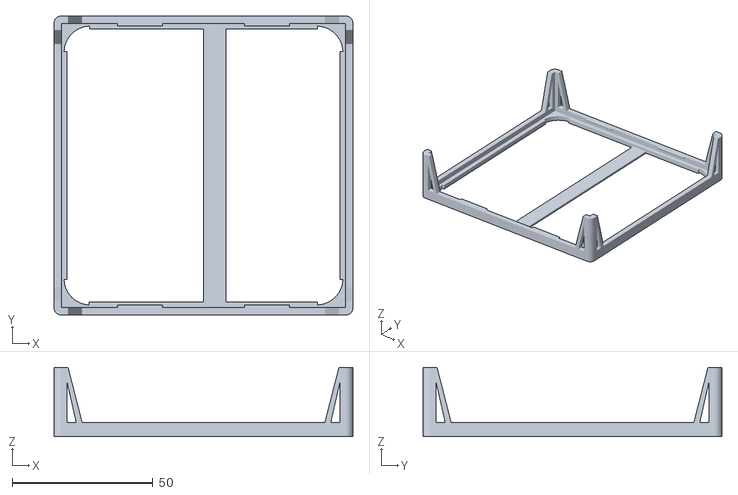
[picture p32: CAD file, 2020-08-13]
resources/enclosure/PCB Tray.stl
106.2 x 106.2 x 24.5

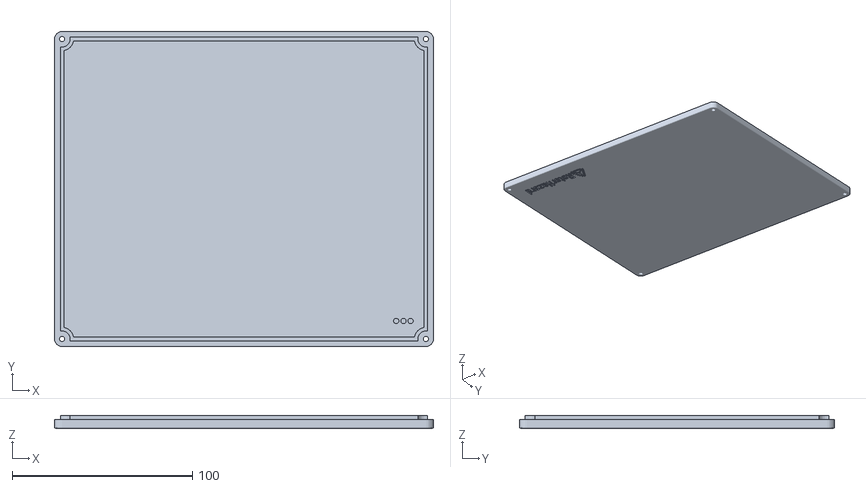
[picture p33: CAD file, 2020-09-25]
Hardware/3D Printed Enclosure/Flat Enclosure/D5 PCB Version/8Node_RHFlatCaseLid.stl
210.5 x 175.0 x 7.00

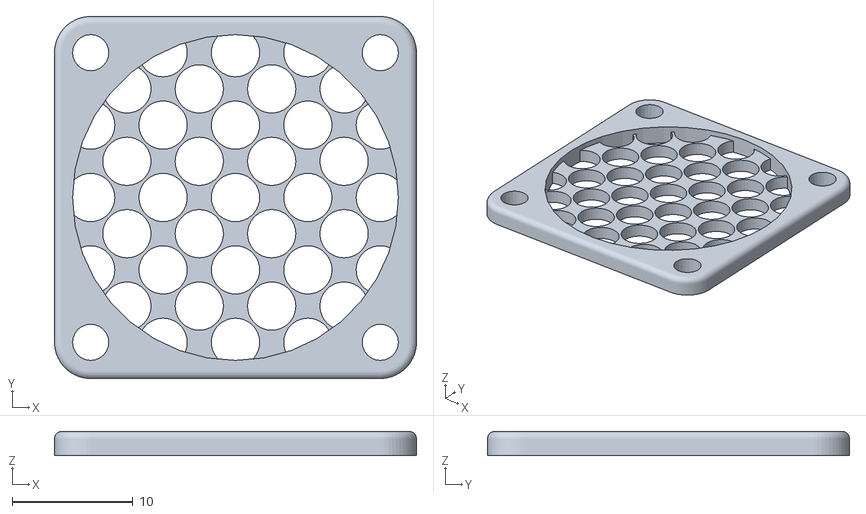
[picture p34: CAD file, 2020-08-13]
resources/enclosure/Grille Circles.stl
30.0 x 30.0 x 2.00

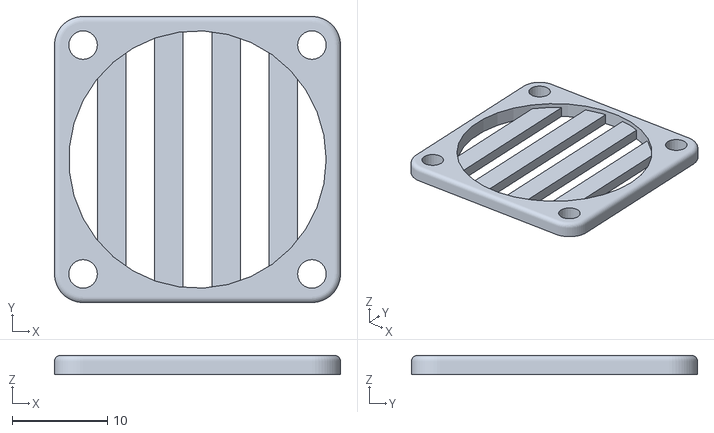
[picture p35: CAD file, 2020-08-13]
resources/enclosure/Grille Slatted.stl
30.0 x 30.0 x 2.00

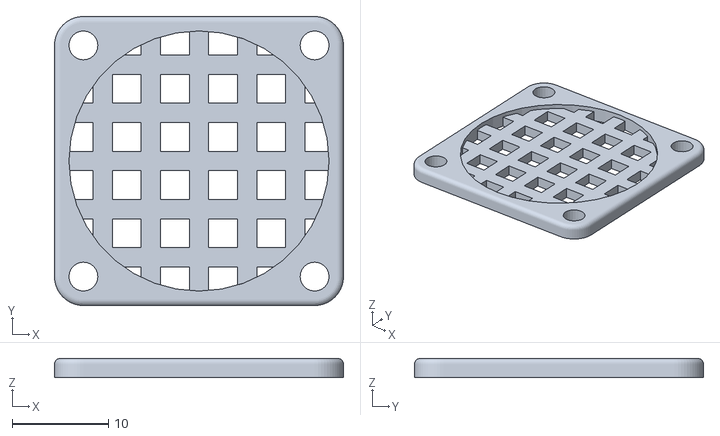
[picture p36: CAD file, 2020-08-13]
resources/enclosure/Grille Squares.stl
30.0 x 30.0 x 2.00

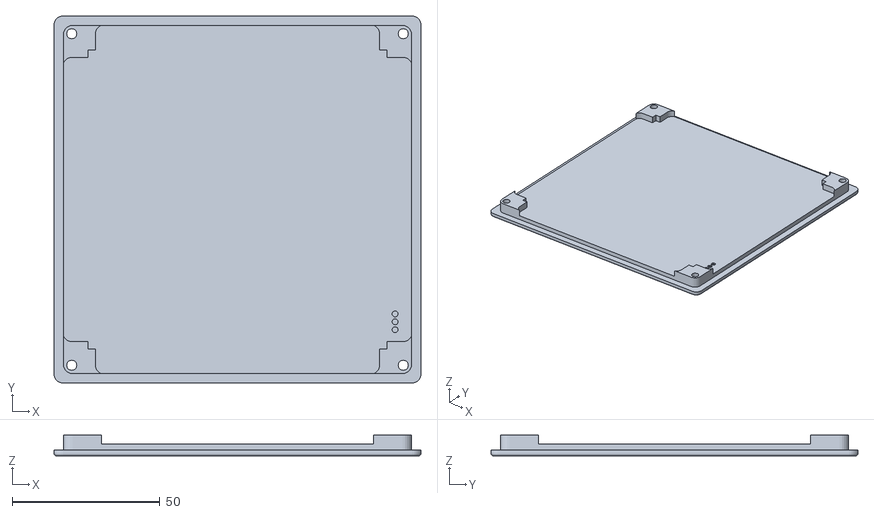
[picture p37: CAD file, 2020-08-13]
resources/enclosure/Lid Plain.stl
124.0 x 124.0 x 7.00

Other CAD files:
resources/enclosure/Grille RotorHazard.stl
resources/enclosure/Box Four Node.stl
resources/S32_BPill_PCB/files/RH_S32_BPill_nodeTrimJig.blend

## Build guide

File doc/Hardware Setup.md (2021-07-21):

# Hardware Setup Instructions

See the [RotorHazard Build Resources](../resources/README.md) page for information on race-timer circuit boards and 3D-printable cases.

For general information on the Arduino-nodes version of the timer, see '[doc/Timer Build with Arduinos.md](Timer%20Build%20with%20Arduinos.md)'

### Add a Directional RF Shield
A directional RF shield significantly improves the system's ability to reject false passes. See [RF shielding](Shielding%20and%20Course%20Position.md)

### Real Time Clock
See '[doc/Real Time Clock.md](Real%20Time%20Clock.md)' for more information on installing a real-time clock module to improve how the system maintains its date and time.

### WS2812b LED Support
The pins in the green box is what were already used by the timer. The pins in the red box is where you connect the signal and ground from the ws2812b LEDs.  The LEDs will require a separate power source. See WS2812b LED support under [doc/Software Setup.md](Software%20Setup.md).

led wiring

### Additional Sensors
Sensors (such as BME280 and INA219) may be attached to the I2C bus and power pins. See the '..._sensor.py' files in the "src/interface" directory for implementation examples. The sensors need to be specified in the "src/server/config.json" file -- in the sample configuration below, a BME280 sensor is configured at I2C address 0x76 (as "Climate") and a INA219 sensor is configured at address 0x40 (as "Battery").
```
    "SENSORS": {
            "i2c:0x76": {
                    "name": "Climate"
            },
            "i2c:0x40": {
                    "name": "Battery",
                    "max_current": 0.1
            }
    },
```

### Multiple Timers
Multiple RotorHazard timers may be connected together (i.e., for split timing and mirroring) -- see [doc/Cluster.md](Cluster.md).

-----------------------------

See Also:<br/>
[doc/USB Nodes.md](USB%20Nodes.md)<br/>
[doc/Software Setup.md](Software%20Setup.md)<br/>
[doc/User Guide.md](User%20Guide.md)<br/>
[Build Resources (PCB, etc)](../resources/README.md)

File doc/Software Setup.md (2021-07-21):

# Software Setup Instructions

The central software component of the RotorHazard system is its server, written in Python, which operates its functions and serves up web pages to browsers. In a standard setup, the server is run on a RaspberryPi. (It is also possible to run RotorHazard on other types of hardware -- see the [Other Operating Systems](#otheros) section below.)

Note: If RotorHazard is already installed, see the [Updating an existing installation](#update) section below.

## Install RotorHazard on a Raspberry Pi

### 1. Install the Raspberry Pi Operating System

Note: Many of the setup commands below require that the Rasperry Pi has internet access.

Install the Raspberry Pi OS, following the official instructions: https://www.raspberrypi.org/help

The standard-recommended setup is to use a Raspberry Pi 3 board and install the [Raspberry Pi OS](https://www.raspberrypi.org/software/operating-systems/#raspberry-pi-os-32-bit) (32-bit, Desktop).

Tip: Any time you intend to use a monitor (via HDMI) with the Raspberry Pi, connect it before powering up the Pi. Connecting the monitor after power up tends to not work (blank screen).

### 2. Configure Interface Options

(The options may be configured using step 2a or 2b below.)

#### 2a. Configure interface options using the desktop
If Raspberry Pi OS with Desktop was installed, the interface options may be configured via "Preferences" | "Raspberry Pi Configuration" | "Interfaces":
* Enable SSH, SPI, I2C, and 'Serial Port'
* Disable 'Serial Console'
* For remote access to the desktop (using a program like [RealVNC viewer](https://www.realvnc.com/en/connect/download/viewer)), enable VNC

#### 2b. Configure interface options using a terminal window
If the Pi OS Desktop is not available, the interface options may be configured using the following command:
```
sudo raspi-config
```
* Select 'Interface Options' and enable: SSH, SPI, and I2C
* Select 'Interface Options' | 'Serial Port', and configure:
  * "login shell accessible serial": No
  * "serial port hardware enabled": Yes

### 3. Apply Changes to '/boot/config.txt'
Open a terminal window and enter:
```
sudo nano /boot/config.txt
```
Add the following lines to the end of the file:
```
dtparam=i2c_baudrate=75000
dtoverlay=miniuart-bt
```
If the Raspberry Pi in use is a Pi 3 model or older (not a Pi 4) then also add this line:
```
core_freq=250
```
If your hardware is the S32_BPill setup with [shutdown button](Shutdown%20Button.md) and AUX LED then add these lines:
```
dtoverlay=act-led,gpio=24
dtparam=act_led_trigger=heartbeat
dtoverlay=gpio-shutdown,gpio_pin=18,debounce=5000
```
Save and exit (CTRL-X, Y, ENTER)

The first line sets the transfer rate on the I2C bus (which is used to communicate with the Arduino node processors).

The "dtoverlay=miniuart-bt" line moves the high performance UART from the Bluetooth device to the GPIO pins, which is needed for setups like the S32_BPill that use the serial port as the communications channel to the nodes.

The "core_freq" line fixes a potential variable clock-rate issue, described [here](https://www.abelectronics.co.uk/kb/article/1089/i2c--smbus-and-raspbian-stretch-linux). If a Raspberry Pi 4 is being used, the "core_freq" line should be omitted (as per the Raspberry Pi documentation [here](https://www.raspberrypi.org/documentation/configuration/config-txt/overclocking.md)).

For the S32_BPill setup, the "dtoverlay=act-led,gpio=24" and "dtparam=act_led_trigger=heartbeat" lines configure a Raspberry-Pi-heartbeat signal that the BPill processor monitors to track the status of the Pi.  The "dtoverlay=gpio-shutdown..." line makes it so the shutdown button still operates if the RotorHazard server is not running.

### 4. Perform System Update
Using a terminal window, do a system update and upgrade (this can take a few minutes):
```
sudo apt-get update && sudo apt-get upgrade
```

### 5. Install Python
Using a terminal window, install Python and the Python drivers for the GPIO:
```
sudo apt install python-dev python3-dev libffi-dev python-smbus build-essential python-pip python3-pip git scons swig python-rpi.gpio python3-rpi.gpio
```
Check the current default version of Python by entering the following command:
```
python --version
```
If the version reported is older than Python 3, enter the following commands to switch the default version to Python 3:
```
sudo update-alternatives --install /usr/bin/python python /usr/bin/python2 1
sudo update-alternatives --install /usr/bin/python python /usr/bin/python3 2
```
After the above commands are entered, the system should default to using Python 3. The default version can be switched back and forth via the command: `sudo update-alternatives --config python`

### 6. Install the RotorHazard Server
Install the RotorHazard server code under '/home/pi/' on the Raspberry Pi as follows:

Go to the [Latest Release page](https://github.com/RotorHazard/RotorHazard/releases/latest) for the project and note the version code.

In the commands below, replace the two occurrences of "1.2.3" with the current version code, and enter the commands using a terminal window:
```
cd ~
wget https://codeload.github.com/RotorHazard/RotorHazard/zip/1.2.3 -O temp.zip
unzip temp.zip
mv RotorHazard-1.2.3 RotorHazard
rm temp.zip
```

Enter the commands below to install RotorHazard server dependencies (be patient, this may take a few minutes):
```
cd ~/RotorHazard/src/server
sudo pip install -r requirements.txt
```

### 7. Reboot System
After the above setup steps are performed, the system should be rebooted by entering the following using a terminal window:
```
sudo reboot
```

----------------------------------------------------------------------------

## RotorHazard Node Code

The firmware for the RotorHazard nodes will need to be installed (or updated). The nodes can be Arduino based (with an Arduino processor for each node channel), or use the multi-node S32_BPill board (with a single STM32F1 processor running 1-8 channels).

For Arduino-based node boards, see the '[src/node/readme_Arduino.md](../src/node/readme_Arduino.md)' file for more information and instructions for installing the node firmware code.

For the S32_BPill board, the recommended method for installing the currently-released node firmware is to use the `Update Nodes` button (in the 'System' section on the 'Settings' page) on the RotorHazard web GUI.<br>
The "dtoverlay=miniuart-bt" line needs to have been added to the "/boot/config.txt" file for the flash-update to succeed (see instructions above).<br>
Note that the flash-update steps described in '[src/node/readme_S32_BPill.md](../src/node/readme_S32_BPill.md)' are for developers who wish to build the S32_BPill node firmware from the source code.

The node-code version may be viewed in the Server Log, and via the "About RotorHazard" item in the drop-down menu.

----------------------------------------------------------------------------

## Optional Components

### Real Time Clock

The installation of a real-time clock module allows the RotorHazard timer to maintain the correct date and time even when an internet connection is not available.  See '[doc/Real Time Clock.md](Real%20Time%20Clock.md)' for more information.

### WS2812b LED Support

Support for WS2812b LED strips (and panels) is provided by the Python library '[rpi-ws281x](https://github.com/rpi-ws281x/rpi-ws281x-python)' (which is among the libraries installed via the `sudo pip install -r requirements.txt` command.

The **LED_COUNT** value must be set in the `src/server/config.json` file; other LED configuration options will attempt to use reasonable defaults. **LED_ROWS** must be set for multiline displays. See the `src/server/config-dist.json` file for the default configuration of the 'LED' settings. The following items may be set:
```
LED_COUNT:  Number of LED pixels in strip (or panel)
LED_ROWS:  Number of rows in a multiline LED display panel (LED_COUNT must be evenly divisible by this value; default 1)
LED_PIN:  GPIO pin connected to the pixels (default 10 uses SPI '/dev/spidev0.0')
LED_FREQ_HZ:  LED signal frequency in hertz (usually 800000)
LED_DMA:  DMA channel to use for generating signal (default 10)
LED_INVERT:  True to invert the signal (when using NPN transistor level shift)
LED_CHANNEL:  Set to '1' for GPIOs 13, 19, 41, 45 or 53
LED_STRIP:  Strip type and color ordering (default is 'GRB')
PANEL_ROTATE:  Optional panel-rotation value (default 0)
INVERTED_PANEL_ROWS:  Optional even-index row inversion for LED panels (default false)
```
***LED_PIN*** is the GPIO number, not the hardware pin index.
If specified, the **LED_STRIP** value must be one of: 'RGB', 'RBG', 'GRB', 'GBR', 'BRG', 'BGR', 'RGBW', 'RBGW', 'GRBW',  'GBRW', 'BRGW', 'BGRW'

Running LEDs from certain GPIO pins (such as GPIO18) requires the server to be run as root. If the error message `Can't open /dev/mem: Permission denied` or `mmap() failed` appears on startup, you must run the server with `sudo` or connect LEDs to a different GPIO pin. If using a service file to start the server on boot, it may be run as root by leaving out the "User=pi" line.

### Java Support
Java enables the calculating of IMD scores, which is helpful for selecting frequency sets with less interference between VTXs. To determine if Java is installed, run the following command:
```
java -version
```
If the response is "command not found" then Java needs to be installed.

For the Raspberry Pi 3 or Pi 4, use the following command:
```
sudo apt install default-jdk-headless
```

For the Raspberry Pi Zero (or an older-model Pi), use this command:
```
sudo apt install openjdk-8-jdk-headless
```

----------------------------------------------------------------------------

## Running the RotorHazard server

The following instructions will start the web server on the raspberry pi, allowing full control and configuration of the system to run races and save lap times.

### Manual Start
Open a terminal window and enter the following:
```
cd ~/RotorHazard/src/server
python server.py
```
The server may be stopped by hitting Ctrl-C

### Start on Boot
To configure the system to automatically start the RotorHazard server when booting up:

Create a service file:
```
sudo nano /lib/systemd/system/rotorhazard.service
```
with the following contents
```
[Unit]
Description=RotorHazard Server
After=multi-user.target

[Service]
User=pi
WorkingDirectory=/home/pi/RotorHazard/src/server
ExecStart=/usr/bin/python server.py

[Install]
WantedBy=multi-user.target
```

Running LEDs from certain GPIO pins (such as GPIO18) requires the server to be run as root. If the error message `Can't open /dev/mem: Permission denied` or `mmap() failed` appears on startup, remove `User=pi` from this config.

Save and exit (CTRL-X, Y, ENTER).

Update permissions:
```
sudo chmod 644 /lib/systemd/system/rotorhazard.service
```

Enable the service:
```
sudo systemctl daemon-reload
sudo systemctl enable rotorhazard.service
sudo reboot
```
### Stopping the server service
If the RotorHazard server was started as a service during the boot, it may be stopped with a command like this:
```
sudo systemctl stop rotorhazard
```
To disable the service (so it no longer runs when the system starts up), enter:
```
sudo systemctl disable rotorhazard.service
```
To query the status of the service:
```
sudo systemctl status rotorhazard.service
```

### Shutting down the System
A system shutdown should always be performed before unplugging the power, either by clicking on the 'Shutdown' button on the 'Settings' page, or by entering the following in a terminal:
```
sudo shutdown now
```

----------------------------------------------------------------------------

## Updating an existing installation

Before updating, any currently-running RotorHazard server should be stopped. If installed as a service, it may be stopped with a command like:
```
sudo systemctl stop rotorhazard
```

To update an existing RotorHazard installation: Go to the [Latest Release page](https://github.com/RotorHazard/RotorHazard/releases/latest) for the project and note the version code. In the commands below, replace the two occurrences of "1.2.3" with the current version code, and enter the commands:
```
cd ~
wget https://codeload.github.com/RotorHazard/RotorHazard/zip/1.2.3 -O temp.zip
unzip temp.zip
mv RotorHazard RotorHazard.old
mv RotorHazard-1.2.3 RotorHazard
rm temp.zip
cp RotorHazard.old/src/server/config.json RotorHazard/src/server/
cp RotorHazard.old/src/server/database.db RotorHazard/src/server/
```
The previous installation ends up in the 'RotorHazard.old' directory, which may be deleted or moved.

For RotorHazard the minimum version of Python supported is 3.5. If your Python is older than this, you should upgrade using the steps in the "Install RotorHazard" section under "5. [Install Python](#python)."

The RotorHazard server dependencies should also be updated (be patient, this command may take a few minutes):
```
cd ~/RotorHazard/src/server
sudo pip install --upgrade --no-cache-dir -r requirements.txt
```

----------------------------------------------------------------------------

## Enable Port forwarding
The RotorHazard server defaults to port 5000, as this is necessary for some 3rd party integrations. While you can change the port via `HTTP_PORT` in the `config.json` file, a better approach is often to forward the web default port of 80 to 5000.

By default, HTTP uses port 80. Other values will require that the port be included as part of the URL entered into client browsers. If other web services are running on the Pi, port 80 may already be in use and reusing it will cause problems. If port 80 is used directly via `HTTP_PORT`, the server may need to be run using the *sudo* command. With the following commands, the server runs on port 5000 but the system sends the traffic from port 80 to it.

```
sudo iptables -A PREROUTING -t nat -p tcp --dport 80 -j REDIRECT --to-ports 5000
sudo iptables -A PREROUTING -t nat -p tcp --dport 8080 -j REDIRECT --to-ports 80
sudo iptables-save
sudo apt-get install iptables-persistent
```
After running these commands, RotorHazard will be available from both ports 80 and 5000. When available by port 80, you may leave the port off when accessing the server, i.e.: `http://127.0.0.1`

Note: The second *iptables* command will forward port 8080 to 80, so services that would normally be available on port 80 will instead be available on port 8080. If port 80 services are not present or if other services are using port 8080, this *iptables* command may be omitted.
<br/>

----------------------------------------------------------------------------

## Other Operating Systems

The RotorHazard server may be run on any computer with an operating system that supports Python. In these alternate configurations, one or more hardware nodes may be connected via USB -- see [doc/USB Nodes.md](USB%20Nodes.md) for more information. The server may also be run using simulated (mock) nodes.

To install the RotorHazard server on these systems:

1. If the computer does not already have Python installed, download and install Python from https://www.python.org/downloads . To check if Python is installed, open up a command prompt and enter ```python --version```

1. From the RotorHazard [Releases page on github](https://github.com/RotorHazard/RotorHazard/releases), download the "Source code (zip)" file.

1. Unzip the downloaded file into a directory (aka folder) on the computer.

1. Open up a command prompt and navigate to the ```src/server``` directory in the RotorHazard files (using the 'cd' command).

1. Install the RotorHazard server dependencies using the 'reqsNonPi.txt' file, using one of the commands below. (Note that this command may require administrator access to the computer, and the command may take a few minutes to finish).
  * On a Windows system the command to use will likely be:<br/>```python -m pip install -r reqsNonPi.txt```<br>

Note: If the above command fails with a message like "error: Microsoft Visual C++ 14.0 is required", the Visual C++ Build Tools may be downloaded (from [here](http://go.microsoft.com/fwlink/?LinkId=691126&fixForIE=.exe.)) and installed.<br>

  * On a Linux system the command to use will likely be:<br/>```sudo pip install -r reqsNonPi.txt```

To run the RotorHazard server on these systems:

1. Open up a command prompt and navigate to the ```src/server``` directory in the RotorHazard files (if not already there).

1. Enter: ```python server.py```

1. If the server starts up properly, you should see various log messages, including one like this:
    ```
    Running http server at port 5000
    ```

1. The server may be stopped by hitting Ctrl-C

If hardware nodes are connected via USB, they will need to be configured in the "SERIAL_PORTS" section in the "src/server/config.json" configuration file (see [doc/USB Nodes.md](USB%20Nodes.md) for details).

If no hardware nodes are configured, the server will operate using simulated (mock) nodes. In this mode the web-GUI interface may be explored and tested.

To view the web-GUI interface, open up a web browser and enter into the address bar: ```localhost:5000``` (If the HTTP_PORT value in the configuration has been changed then use that value instead of 5000). If the server is running then the RotorHazard main page should appear. Note that pages reserved for the race director (Admin/Settings) are password protected with the username and password specified in the configuration.
<br/>

----------------------------------------------------------------------------

## Logging

The RotorHazard server generates "log" messages containing information about its operations. Below is a sample configuration for logging:

```
    "LOGGING": {
        "CONSOLE_LEVEL": "INFO",
        "SYSLOG_LEVEL": "NONE",
        "FILELOG_LEVEL": "INFO",
        "FILELOG_NUM_KEEP": 30,
        "CONSOLE_STREAM": "stdout"
    }
```
The following log levels may be specified:  DEBUG, INFO, WARNING, WARN, ERROR, FATAL, CRITICAL, NONE

If the FILELOG_LEVEL value is not NONE then the server will generate log files in the `src/server/logs` directory. A new log file is created each time the server starts, with each file having a unique name based on the current date and time (i.e., "rh_20200621_181239.log"). Setting FILELOG_LEVEL to DEBUG will result in more detailed log messages being stored in the log file, which can be useful when debugging problems.

The FILELOG_NUM_KEEP value is the number of log files to keep; the rest will be deleted (oldest first).

The CONSOLE_STREAM value may be "stdout" or "stderr".

If the SYSLOG_LEVEL value is not NONE then the server will send log messages to the logging utility built into the host operating system.

The current Server Log may be displayed via the "View Server Log" item in the drop-down menu. The displayed log is "live" in that it will update as new messages are generated. The log can be displayed in a separate window by clicking on the "View Server Log" menu item with the right-mouse button and selecting the "Open Link in New Window" (or similar) option.

Clicking on the "Select Text" button will select all the displayed log text, which may then be copied and pasted. Clicking on the "Download Logs" button will create and download a '.zip' archive file containing all available log files and the current configuration and database files. The '.zip' archive file can also be generated by running the server with the following command:  `python server.py --ziplogs`

**When reporting issues, using the "Download Logs" button and including the generated '.zip' file is highly recommended.**

When troubleshooting, another place to check for error messages is the "/var/log/syslog" file, which may be viewed with a command like: `tail -100 /var/log/syslog`

<br/>

-----------------------------

See Also:<br/>
[doc/Hardware Setup.md](Hardware%20Setup.md)<br/>
[doc/USB Nodes.md](USB%20Nodes.md)<br/>
[doc/User Guide.md](User%20Guide.md)<br/>
[Build Resources (PCB, etc)](../resources/README.md)

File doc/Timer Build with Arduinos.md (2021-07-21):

# Timer Build with Arduinos

## Parts List

### Receiver Node(s) (this list makes one node, build up to eight)
* 1 x [Arduino Nano](https://www.ebay.com/sch/i.html?_nkw=Arduino+Nano+V3.0+16M+5V+ATmega328P)
* 1 x [RX5808 module](https://www.banggood.com/search/rx5808-module.html) with SPI mod (modules with date code 20120322 are known to work)
* 3 x 1k ohm resistor
* 1 x 100k ohm resistor
* 26 AWG and 30 AWG silicone wire

### System Components
* 1 x Raspberry Pi3 (Pi2 users have reported issues with multiple nodes connected)
* 8 GB (minimum) Micro SD Card
* 26 AWG and 30 AWG silicone wire (for wiring to each receiver node)
* 3D printed case for housing the electronics
* 5V power supply, 3 amp minimum (or 12V power supply if onboard regulators are used)

### Additional Components
* [RF shielding](Shielding%20and%20Course%20Position.md)

### Optional Components
* Ethernet cable, 50ft plus
* Outdoor power cable, 50ft plus
* Network router
* Laptop/tablet
* ws2812b LEDs

## Hardware Setup

### RX5808 Video Receivers
Make sure your receivers support SPI. *Most RX5808 modules on sale today already arrive with SPI enabled.* If they do not, modify the RX5808 receivers to enable SPI support as follows:

Remove the shield from the RX5808, the shield is normally held on by a few spots of solder around the edges. Use some solder wick to remove the solder and free the shield from the receiver. Be careful not to damage any ground pads on the receiver. There are usually small holes around the edge you can use to help push off the shield.

Remove the following resistor:
RX5808 spi mod

The shield should be soldered back in place after removing the resistor.

### Receiver Nodes
Complete wiring connections between each Arduino and RX5808.
receiver node wiring

Note: A simple receiver node may also be constructed and attached via USB -- see [doc/USB Nodes.md](USB%20Nodes.md).

### System Assembly
Complete wiring connections between each Arduino and the Raspberry Pi.

Note: be sure all Receiver Nodes and the Raspberry Pi are tied to a common ground; if not, the i2c messages can be corrupted.
system wiring

-----------------------------

See Also:<br/>
[doc/Hardware Setup.md](Hardware%20Setup.md)<br/>
[doc/USB Nodes.md](USB%20Nodes.md)<br/>
[doc/Software Setup.md](Software%20Setup.md)<br/>
[doc/User Guide.md](User%20Guide.md)<br/>
[Build Resources (PCB, etc)](../resources)

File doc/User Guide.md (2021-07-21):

# RotorHazard Race Timer User Guide

## Initial Setup

### Hardware and Software Setup
Follow the instructions here if not done already:<br>
[Hardware Setup](Hardware%20Setup.md)<br>
[Software Setup](Software%20Setup.md)<br>
[RF shielding](Shielding%20and%20Course%20Position.md)

### Set up Config File
In the "src/server" directory, find *config-dist.json* and copy it to *config.json*. Edit this file and modify the ADMIN_USERNAME and ADMIN_PASSWORD values. This items in this file must in valid JSON format. A linter utility like [JSONLint](https://jsonlint.com/) can be used to check for syntax errors.

ADMIN_USERNAME and ADMIN_PASSWORD are the login credentials you will need to access the pages reserved for the race director (i.e., the *Settings* and *Run* pages).

### Connect to the Server
A computer, phone or tablet may be used to interact with the race timer by launching a web browser and entering the IP address of the Raspberry Pi. The Raspberry Pi may be connected using an ethernet cable, or to an available WiFi network. If the IP address of the Pi is not known, it may be viewed using the terminal command "ifconfig", and it can configured to a static value on the Pi desktop via the "Network Preferences." If the Pi is connected to a WiFi network, its IP address may be found in the 'Clients' list on the admin page for the network's router.

In the web browser, type in the IP address of for the race timer and the port value you set in the config file (or leave off the :port if set to 80).

```
XXX.XXX.XXX.XXX:5000
```

Once the page is successfully displayed, it may be bookmarked in the browser. Pages reserved for the race director ("Admin / Settings") are password protected with the username and password specified in the config file.

## Pages

### Home

This page displays the event name and description, along with a set of buttons to various other pages.

### Event

This public page displays the current class setup (if applicable), and a summary of pilots and their heats with channel assignment.

### Results

This public page will display results and calculated statistics of all previously saved races, organized into collapsible panels. Aggregate results are displayed for each heat with multiple rounds, each class, and the entire event.

### Current

This page displays information about the currently running race, including real-time race time, pilot lap times and leaderboard. It automatially updates with the event, and is suitable for projecting to a prominently displayed screen.

In the Audio Control section, the user can select whether any one pilot, all pilots, or no pilots will have laps announced. In this way, a pilot might elect to hear only their own laps announced. A user can also adjust the voice, volume, rate, and pitch of these announcements.

### Settings

This page allows changing the timer's optional settings and event setup.

#### Frequency Setup
Choose a preset or manually select frequencies for each node. Arbitrary frequency selection is possible, as is disabling a node. The IMD score for currently selected frequencies is calculated and displayed at the bottom of the panel.

Profiles contain frequencies and node tuning values. Changing this list immediately activates the selected profile, and changing current frequencies and node tuning immediately saves to the profile.

#### Sensor Tuning
See [doc/Tuning Parameters.md](Tuning%20Parameters.md) for a detailed description and tuning guide.

#### Event and Classes
Event information is displayed on the home page when users first connect to the system.

Classes are not required for events; there's no need to create a class unless you will have two or more in the event. Classes can be used to have separate generated statistics for groups of heats. For example, Open and Spec class, or Beginner/Pro classes.

#### Heats
Add heats until there are enough for all pilots racing. Optional heat names can be added if desired. Heat slots may be set to *None* if no pilot is assigned there.

If you are using classes, assign each heat to a class. Be sure to add enough heats for each pilot in each class; heats assigned to one class are not available in another.

As you run races, heats will become locked and cannot be modified. This protects saved race data from becoming invalid. To modify heats again, open the *Database* panel and clear races.

#### Pilots
Add an entry for each pilot that will race. The system will announce pilots based on their callsign. A phonetic spelling for a callsign may be used to influence the voice callouts; it is not required.

#### Audio Control
All audio controls are local to the browser and device where you set them, including the list of available languages, volumes, and which announcements or indicators are in use.

Voice select chooses the text-to-speech engine. Available selections are provided by the web browser and operating system.

Announcements allow the user to choose to hear each pilot's callsign, lap number, and/or lap time as they cross. The "Race Clock" announcement will perioically call out how much time has elapsed or is remaining, depending on the timer mode in the race format. "Team Lap Total" is used only when "Team Racing Mode" is enabled.

Voice volume, rate, and pitch control all text-to-speech announcements. "Tone Volume" controls race start and end signals.

Indicator beeps are very short tones that give feedback on how the timer is working, and are most useful when trying to tune it. Each node is identified with a unique audio pitch. "Crossing Entered" will beep once when a pass begins, and "Crossing Exited" will beep twice rapidly when a pass is completed. "Manual Lap Button" will beep once if the "Manual" button is used to force a simulated pass.

#### Race Format
Race formats define how a race is conducted. Choose an active race format. Settings that you adjust here will be saved to the currently active format.

The race clock can count up or down as selected by _Race Clock Mode_. Use "No Time Limit" for a "First to X laps" style with a timer that counts upward from zero. Use "Fixed Time" for a timer which counts down to zero after the race starts. _Timer Duration_ is used in "Fixed Time" mode to determine race length.

Each race begins with a staging sequence. Race staging can be done with a fixed or variable number of staging seconds and with or without staging tones. Set the _Minimum Start Delay_ and _Maximum Start Delay_ to the values (in seconds) that are desired for race staging. If these values are different, the timer will choose a value at random for the amount of staging time. Random staging times are useful to prevent false starts. The timer will display "Ready" during staging, obscuring the race start time. For a fixed staging time, set the "Minimum" and "Maximum" to the same value. The staging timer will openly display the number of seconds until the race begins. 

_A small amount of time is needed to ensure the timer has synchronized with all hardware, so there is a short staging period even with a staging time of zero._

A number of tones can be generated during the staging sequence, as set by _Staging Tones_. For "Each Second", the timer will sound a tone continuously during staging. With "One", the timer will sound a tone immediately when staging begins. With "None", no audible warning is provided. Regardless of the _Staging Tones_ setting, the "Race Start" tone is still played when staging completes and the race begins.

When a pilot crosses for the first time in a race, _First Crossing_ affects how result displays and race outcomes are processed. "Hole Shot" records the race time of each pilot's first crossing as beginning their first lap. "First Lap" records the race time of each pilot's first crossing as ending their first lap. "Staggered Start" begins each pilot's own race clock their first crossing, disregarding the global race clock. "Staggered Start" is typically combined with the "No Time Limit" _Race Clock Mode_.

_Win Condition_ determines how the timer calls out the winner of the race, the information presented in the OSD and streaming display, and sort method for leaderboards. Leaderboard sorting affects the results page and heat generator.
* __Most Laps in Fastest Time__: Pilots are judged by the number of laps completed and how long it took to complete them. If there is a tie for the number of laps completed, the pilot who completed those laps in a shorter amount of time will be ranked higher.
* __Most Laps Only__: Scored only by the completed lap count. Pilots with the same lap count are tied. Use with "Fixed Time" mode for a race style before timing was reliable, or with "No Time Limit" mode to judge the greatest distance instead of shortest time.
* __Most Laps Only with Overtime__: Similar to _Most Laps in Fastest Time_, but with a "sudden death" component. When the timer expires (or the race is stopped early), if a pilot has more laps than all the others then that pilot is the winner. If there is a tie for lap count when the timer expires, the first of the tied pilots across the line is the winner.
* __First to X Laps__: The race continues until one pilot reaches the desired lap count. In this mode, the _Number of Laps to Win_ parameter is used. Typically used with the _No Time Limit_ race mode.
* __Fastest Lap__: Ignores the race progress and considers only each pilot's single fastest lap.
* __Fastest 3 Consecutive Laps__: Considers all laps a pilot has completed and uses the three consecutive laps with the fastest combined time.
* __None__: Does not declare a winner under any circumstance. Heats generated from a class with this condition will be assigned randomly.

_Team Racing Mode_ activates alternate scoring for additional race formats. Win conditions in team racing mode differ somewhat:
* __Most Laps in Fastest Time__: Teams are judged on combined lap count of all members and how long it took to complete those laps.
* __Most Laps Only__: Teams are judged on total combined lap count of all members.
* __Most Laps Only with Overtime__: Teams are judged on total combined lap count of all members. If tied when time expires, the first team (of those tied) to add a lap becomes the winner.
* __First to X Laps__: The first team to complete the desired combined lap count is the winner.
* __Fastest Lap__: After all team members have contributed one lap, teams are judged by the average of pilots' fastest lap time.
* __Fastest 3 Consecutive Laps__: After all team members have contributed 3 laps, teams are judged by the average of pilots' fastest "three consecutive laps" time.

With _Fastest Lap_ and _Fastest 3 Consecutive Laps_, teams with differing numbers of pilots can compete together fairly.

_Minimum lap Time_ highlights or discards passes that would have registered laps less than the specified duration. Use the "discard" behavior with caution, as this will eliminate data that may have been valid. _Minimum Lap Time_ is not stored with the race format.

#### LED Effects
Choose a visual effect for each timer event. The timer will display this effect when the event occurs, immediately overriding any existing display or effect. Some visual effects are only available on particular timer events. Some visual effects are modified by the event, most notably the color of gate crossing enters/exits. Most effects can be previewed through the LED Control panel.

Some LED effects can be delayed a short time if the timer is busy with time-critical tasks. (Others such as race start are never delayed.) Because of this effect and potentially concurrent crossings, _"Turn Off"_ should usually be avoided for gate exits. Instead, use _"No Change"_ on gate entrance and your desired effect on gate exit.

_This section will not appear if your timer does not have LEDs configured. A notice appears in the startup log._

#### LED Control
This section will override the current LED display. Choose to temporarily shut off the display, display some pre-configured colors, display any custom color, or display a defined effect. You can also use the slider to adjust the brightness of your panel. The ideal setting for FPV cameras is where the lit panel matches the brightness of a white object. This puts the panel output within the dynamic range of what the camera can capture. However, using a low brightness setting distorts color reproduction and smoothness of color transitions.

_This section will not appear if your timer does not have LEDs configured. A notice appears in the startup log._

#### Database
Choose to backup the current database (save to a file on the pi and prompt to download it) or clear data. You may clear races, classes, heats, and pilots.

#### System
Choose the interface language, and change parameters that affect the appearance of the timer such as its name and color scheme. You can also shut down the server from here.

### Run

This page allows you to control the timer and run races.

Select the Heat for the race which is to be run next.

Start the race when ready. (Hotkey: <kbd>z</kbd>) The timer will do a quick communication to the server to  compensate for client/server response time, then begin the staging procedure defined by the current race format.

Tuning parameters can be adjusted here by clicking on/touching any of the graphs for each node. See [doc/Tuning Parameters.md](Tuning%20Parameters.md) for a detailed description and tuning guide.

During the race, there is an "×" next to each counted lap. This will discard that lap pass, so its time is moved to the next lap. Use this to remove errant extra passes, or clean up pilots flying close to the start gate after their race finished.

Pressing the "+ Lap" button will manually trigger a lap pass for that node.

When a race is over, use the "Stop Race" button (Hotkey: <kbd>x</kbd>) to discontinue counting laps. You need to do this  even if the timer reaches zero in a "Count Down" format—a popular race format allows pilots to finish the lap they are on when time expires. For best results, clear the timing gate and allow all valid crossings to end before stopping the race.

Once a race has concluded, you must choose "Save Laps" or "Discard Laps" before starting another race. "Save Laps" (Hotkey: <kbd>c</kbd>) will store race results to the database and display them on the "Results" page. "Discard Laps" (Hotkey: <kbd>v</kbd>) will discard the race results. Saving laps will automatically advance the heat selection to the next heat with the same class as the saved race.

(The spacebar can also be used as a hotkey for the Start, Stop and Save functions.)

The Race Management panel provides quick access to change the current Race Format, Profile, Minimum Lap Time, or Team Racing Mode. _Audio Control_ and _LED Control_ are the same as the Settings page. The History Export dumps a CSV file to be downloaded of the recorded RSSI values in the most recently completed race. "Time Until Race Start" will schedule a race to be run at a future time. Operators may use this to set a hard limit on the amount of time allowed for pilots to prepare, or to start the timer and then participate in the race themselves.

### Marshal

Adjust results of saved races.

Select the round, heat, and pilot to adjust. Enter and Exit points are automatically loaded from the saved race data. Adjust the Enter and Exit points to recalibrate the race after the fact. "Load from Node" to copy current live calibration data over the active values. "Save to Node" to copy the active values over the current live values. "Recalculate Race" to use the active Enter/Exit values as calibration points for a "re-run" of the race. This will erase current laps and replace them with the recalculated information. Manually entered laps are preserved.

Add laps by entering the crossing time in seconds from the beginning of the race, then pressing the "Add Lap" button.

Delete laps with the "×" button on the unwanted lap. Deleted laps are removed from calculations but remain present in the data for later reference. "Discard Laps" to permanently remove the data from the database.

You may click on/touch the graph to set enter/exit points, activate recalculation, and highlight specific laps. Clicking on laps in the list also adds a highlight on the graph. Press <kbd>delete</kbd> or <kbd>x</kbd> to delete a highlighted lap. Active laps are displayed in green, and deleted laps change to red. The width of the lap indicator shows the enter/exit points, and the yellow highlight draws a line at the exact lap time within that window.

"Commit changes" when you are finished adjusting the race data to save it to the database and update the race results.

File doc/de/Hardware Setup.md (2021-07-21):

# Anweisungen zur Hardware-Einrichtung

## Stückliste

### Empfänger-Knoten (diese Liste ergibt einen Knoten, bis zu acht)

* 1 x [Arduino Nano](https://www.ebay.com/sch/i.html?_nkw=Arduino+Nano+V3.0+16M+5V+ATmega328P)
* 1 x [RX5808 Modul](https://www.banggood.com/search/rx5808-module.html) mit SPI mod (Module mit Datumscode 20120322 funktionieren bekanntermaßen)
* 3 x 1k-Ohm-Widerstand
* 1 x 100k-Ohm-Widerstand
* 26 AWG und 30 AWG Silikondraht

### Systemkomponenten

* 1 x Raspberry Pi3 (Pi2-Benutzer haben Probleme mit mehreren angeschlossenen Knoten gemeldet)
* 8 GB (Minimum) Micro-SD Karte
* 26 AWG und 30 AWG Silikonkabel (für die Verdrahtung zu jedem Empfängerknoten)
* 3D gedrucktes Gehäuse zur Aufnahme der Elektronik
* 5V-Stromversorgung, mindestens 3 Ampere (oder 12V-Stromversorgung, wenn bordeigene Regler verwendet werden)

### Zusätzliche Komponenten

* [HF-Abschirmung](Shielding%20and%20Course%20Position.md)

### Optionale Komponenten

* Ethernet-Kabel, 15 Meter plus
* Stromkabel für den Außenbereich, 15 Meter plus
* Netzwerk-Router
* Laptop/Tablett
* ws2812b LEDs

## Hardware-Einrichtung

### RX5808 Video-Empfänger

Stellen Sie sicher, dass Ihre Empfänger SPI unterstützen. *Wenn dies nicht der Fall ist, modifizieren Sie die RX5808-Empfänger wie folgt, um die SPI-Unterstützung zu aktivieren*. Die meisten heute erhältlichen RX5808-Module werden bereits mit aktiviertem SPI geliefert:

Entfernen Sie die Abschirmung vom RX5808, die Abschirmung wird normalerweise durch ein paar Lötpunkte an den Kanten gehalten. Verwenden Sie etwas Lötlotdocht, um das Lot zu entfernen und die Abschirmung vom Empfänger zu befreien. Achten Sie darauf, keine Massepads auf dem Empfänger zu beschädigen. In der Regel befinden sich am Rand kleine Löcher, mit denen Sie die Abschirmung leichter entfernen können.

Entfernen Sie den folgenden Widerstand:
RX5808 spi mod

Die Abschirmung sollte nach Entfernen des Widerstandes wieder angelötet werden.

### Empfänger-Knoten

Vollständige Verkabelung der Verbindungen zwischen jedem Arduino und RX5808.
Verdrahtung des Empfängerknotens

Hinweis: Ein einfacher Empfängerknoten kann auch über USB konstruiert und angeschlossen werden -- siehe [doc/USB Nodes.md](USB%20Nodes.md).

### System-Baugruppe

Vollständige Verkabelung der Verbindungen zwischen jedem Arduino und der Raspberry Pi.

Hinweis: Vergewissern Sie sich, dass alle Empfänger-Knoten und die Raspberry Pi an eine gemeinsame Masse angeschlossen sind; wenn nicht, können die i2c-Nachrichten beschädigt werden.
Systemverkabelung

### Hinzufügen einer gerichteten RF-Abschirmung

Eine gerichtete HF-Abschirmung verbessert die Fähigkeit des Systems zur Abwehr von Fehlpässen erheblich. Siehe [HF-Abschirmung](Shielding%20and%20Course%20Position.md)

### Echtzeituhr

Unter "[doc/Real Time Clock.md](Real%20Time%20Clock.md)" finden Sie weitere Informationen über die Installation eines Echtzeituhr-Moduls, mit dem das System das Datum und die Uhrzeit besser verwalten kann.

### WS2812b LED-Unterstützung

Die Stifte im grünen Kasten sind die, die bereits vom Timer verwendet wurden. An den Pins im roten Kasten schließen Sie das Signal und die Masse der ws2812b-LEDs an.  Die LEDs benötigen eine separate Stromquelle. Siehe WS2812b LED-Unterstützung unter [doc/Software Setup.md](Software%20Setup.md).

led wiring

### Zusätzliche Sensoren

Sensoren (wie BME280 und INA219) können an den I2C-Bus und die Stromversorgungspins angeschlossen werden. Siehe die '..._sensor.py'-Dateien im Verzeichnis "src/interface" für Implementierungsbeispiele. Die Sensoren müssen in der Datei "src/server/config.json" spezifiziert werden -- in der Beispielkonfiguration unten wird ein BME280-Sensor an I2C-Adresse 0x76 (als "Klima") und INA219-Sensoren an 0x40 und 0x41 konfiguriert.

```
    "SENSOREN": {
            "i2c:0x76": {
                    "Name": "Klima": "Klima".
            },
            "i2c:0x40": {
                    "Name": "Batterie",
                    "max_current": 0.1
            },
            "i2c:0x41": {
                    "Name": "Pi",
                    "max_current": 2
            }
    },
```

### Mehrere Timer

Mehrere RotorHazard Timer können miteinander verbunden werden (d.h. für Split Timing und Spiegelung) -- siehe [doc/Cluster.md](Cluster.md).

---

Siehe auch:<br/>
[doc/USB-Knoten.md](USB%20Nodes.md)<br/>
[doc/Software Setup.md](Software%20Setup.md)<br/>
[doc/Benutzerhandbuch.md](User%20Guide.md)

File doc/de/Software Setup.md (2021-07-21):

# Anweisungen zur Software-Einrichtung

Die zentrale Softwarekomponente des RotorHazard-Systems ist der in Python geschriebene Server, der seine Funktionen ausführt und Webseiten für Browser bereitstellt. In einem Standard-Setup wird der Server auf einem RaspberryPi ausgeführt. (Es ist auch möglich, RotorHazard auf anderen Hardwaretypen auszuführen - siehe Abschnitt [Andere Betriebssysteme](#otheros) weiter unten.)

## System installieren (Raspberry Pi)

Hinweis: Für viele der folgenden Setup-Befehle muss der Rasperry Pi über einen Internetzugang verfügen.

Beginnen Sie mit der Installation von Raspbian und befolgen Sie die offiziellen Anweisungen hier: https://www.raspberrypi.org/downloads/raspbian/. Sie können entweder Desktop oder Lite verwenden.

Konfigurieren Sie die Schnittstellenoptionen auf dem Raspberry Pi.
Öffnen Sie ein Terminalfenster und geben Sie den folgenden Befehl ein:

```
sudo raspi-config
```

Wählen Sie Schnittstellenoptionen und aktivieren Sie: SSH, SPI und I2C.

Führen Sie ein Systemupdate und -upgrade durch (dies kann einige Minuten dauern):

```
sudo apt-get update && sudo apt-get upgrade
```

Installieren Sie Python und die Python-Treiber für das GPIO.

```
sudo apt install python-dev libffi-dev python-smbus build-essential python-pip git scons swig python-rpi.gpio
```

Installieren Sie die Funktionsoberfläche in Python

```
sudo pip install cffi
```

Aktualisieren Sie die i2c-Baudrate

```
sudo nano /boot/config.txt
```

Fügen Sie am Ende der Datei die folgenden Zeilen hinzu:

```
dtparam=i2c_baudrate=75000
core_freq=250
```

Hinweis: In der ersten Zeile wird die Übertragungsrate auf dem I2C-Bus festgelegt (der zur Kommunikation mit den Arduino-Knotenprozessoren verwendet wird). Die zweite Zeile behebt ein potenzielles Problem mit variabler Taktrate, das [hier](https://www.abelectronics.co.uk/kb/article/1089/i2c--smbus-and-raspbian-stretch-linux) beschrieben wird. Wenn ein Raspberry Pi 4 verwendet wird, muss möglicherweise die zweite Zeile weggelassen werden.

Speichern und beenden Sie die Datei mit Strg-X

Installieren Sie den RotorHazard-Code unter '/home/pi/' auf dem Raspberry Pi wie folgt: Gehen Sie zur [Seite mit der neuesten Version](https://github.com/RotorHazard/RotorHazard/releases/latest) für das Projekt und notieren Sie das Versionscode. Ersetzen Sie in den folgenden Befehlen die beiden Vorkommen von "1.2.3" durch den aktuellen Versionscode und geben Sie die folgenden Befehle ein:

```
cd ~
wget https://codeload.github.com/RotorHazard/RotorHazard/zip/1.2.3 -O temp.zip
unzip temp.zip
mv RotorHazard-1.2.3 RotorHazard
rm temp.zip
```

Installieren Sie die RotorHazard-Serverabhängigkeiten (haben Sie etwas Geduld, dieser Befehl kann einige Minuten dauern):

```
cd ~/RotorHazard/src/server
sudo pip install -r requirements.txt
```

Aktualisieren Sie die Berechtigungen im Arbeitsordner:

```
cd ~/RotorHazard/src
sudo chmod 777 server
```

*Hinweis: Wenn RotorHazard bereits installiert ist, lesen Sie den folgenden Abschnitt [Aktualisieren einer vorhandenen Installation](#update).*

## Installieren Sie den Code für Empfängerknoten (Arduinos).

Arduino 1.8+ ist erforderlich. Download von https://www.arduino.cc/en/Main/Software

*Der Knotencode und die Serverversion müssen übereinstimmen. Verwenden Sie den 'Knoten'-Code, der in dem zuvor heruntergeladenen Servercode enthalten ist. Laden Sie keine andere Datei direkt von GitHub herunter.*

Der Knotencode kann mit der [Eclipse IDE](https://www.eclipse.org/eclipseide/) und der "[Eclipse C ++ - IDE für Arduino](https://marketplace.eclipse.org/content) bearbeitet und erstellt werden / eclipse-c-ide-arduino) "Plugin (oder die altmodische Methode mit der Arduino IDE). In Eclipse kann das Knotencode-Projekt über "Datei | Projekte aus Dateisystem öffnen ..." geladen werden.

Wenn Sie keine RotorHazard-Platine verwenden, bearbeiten Sie die Datei 'src/node/config.h' und konfigurieren Sie vor dem Hochladen den Wert '#define NODE_NUMBER' für jeden Knoten. Für den ersten Knoten setzen Sie NODE_NUMBER auf 1, für den zweiten auf 2 usw.

```
// Node Setup -- Set node number here (1 - 8)
#define NODE_NUMBER 1
```

Die Auswahl der Hardwareadresse ist auch möglich, indem die Hardwarestifte gemäß der [veröffentlichten Spezifikation](https://github.com/RotorHazard/RotorHazard/wiki/Specification:-Node-hardware-addressing) geerdet werden.

## Installieren Sie optionale Komponenten

### Echtzeituhr

Durch die Installation eines Echtzeituhrmoduls kann der RotorHazard-Timer das korrekte Datum und die korrekte Uhrzeit beibehalten, auch wenn keine Internetverbindung verfügbar ist. Weitere Informationen finden Sie unter '[doc/Real Time Clock.md](Real%20Time%20Clock.md)'.

### WS2812b LED-Unterstützung

Die ws2812b-Steuerelemente werden von folgendem Projekt bereitgestellt:

[https://github.com/jgarff/rpi_ws281x](https://github.com/jgarff/rpi_ws281x)

Klonen Sie das Repository auf den Pi und starten Sie Scons:

```
cd ~
sudo git clone https://github.com/jgarff/rpi_ws281x.git
cd rpi_ws281x
sudo scons
```

Installieren Sie die Python-Bibliothek:

```
cd python
sudo python setup.py install
```

Hinweis: Der Wert **LED_COUNT** muss in der Datei `src/server/config.json` festgelegt werden. Die Standardkonfiguration der LED-Einstellungen finden Sie in der Datei "src/server/config-dist.json". Folgende Elemente können eingestellt werden:

```
LED_COUNT:  Anzahl der LED-Pixel im Streifen (oder Panel)
LED_PIN:  GPIO-Pin mit den Pixeln verbunden (Standard 10 verwendet SPI '/dev/spidev0.0')
LED_FREQ_HZ:  LED-Signalfrequenz in Hertz (normalerweise 800000)
LED_DMA:  DMA-Kanal zur Signalerzeugung (Standard 10)
LED_INVERT:  True, um das Signal zu invertieren (bei Verwendung der NPN-Transistorpegelverschiebung)
LED_CHANNEL:  Setzen Sie für die GPIOs 13, 19, 41, 45 oder 53 auf '1'
LED_STRIP:  Streifentyp und Farbreihenfolge (Standard ist 'GRB')
LED_ROWS:  Anzahl der Zeilen im LED-Panel-Array (1 für Streifen)
PANEL_ROTATE:  Optionaler Panel-Rotationswert (Standard 0)
INVERTED_PANEL_ROWS:  Optionale Panel-Zeilenumkehrung (Standardwert false)
```

Falls angegeben, muss der Wert **LED_STRIP** einer der folgenden Werte sein: 'RGB', 'RBG', 'GRB', 'GBR', 'BRG', 'BGR', 'RGBW', 'RBGW', 'GRBW' , 'GBRW', 'BRGW', 'BGRW'

Die LED-Bibliothek erfordert direkten Speicher und GPIO-Zugriff. Wenn aktiviert, muss RotorHazard mit `sudo` ausgeführt werden.

```
sudo python server.py
```

### INA219 Spannungs- / Stromunterstützung

Die ina219-Schnittstelle wird von folgendem Projekt bereitgestellt:

https://github.com/chrisb2/pi_ina219

Klonen Sie das Repository auf den Pi:

```
cd ~
sudo git clone https://github.com/chrisb2/pi_ina219.git
cd pi_ina219
```

Installieren Sie die Python-Bibliothek:

```
sudo python setup.py install
```

### BME280 Temperaturunterstützung

Die bme280-Schnittstelle wird von folgendem Projekt bereitgestellt:
https://github.com/rm-hull/bme280

Klonen Sie das Repository auf den Pi:

```
cd ~
sudo git clone https://github.com/rm-hull/bme280.git
cd bme280
```

Installieren Sie die Python-Bibliothek:

```
sudo python setup.py install
```

### Java-Unterstützung

Java ermöglicht die Berechnung von IMD-Scores. Wenn Sie mit RASPBIAN MIT GRAFISCHER OBERFLÄCHE begonnen haben, sollte dieser Schritt nicht erforderlich sein, da Java standardmäßig installiert ist. Andernfalls:

```
sudo apt install default-jdk-headless
```

## System vorbereiten

### System neu starten

Nachdem die obigen Einrichtungsschritte ausgeführt wurden, sollte das System neu gestartet werden, indem folgendes eingegeben wird:

```
sudo reboot
```

### System starten

Die folgenden Anweisungen starten den Webserver auf dem Himbeer-Pi und ermöglichen die vollständige Kontrolle und Konfiguration des Systems, um Rennen durchzuführen und Rundenzeiten zu sparen.

#### Manueller Start

Öffnen Sie ein Terminal und geben Sie folgendes ein:

```
cd ~/RotorHazard/src/server
python server.py
```

Der Server kann durch Drücken von Strg-C gestoppt werden

#### Automatischer Start beim Hochfahren

So konfigurieren Sie das System so, dass der RotorHazard-Server beim Hochfahren automatisch gestartet wird:

Erstellen Sie eine Servicedatei:

```
sudo nano /lib/systemd/system/rotorhazard.service
```

mit folgenden Inhalten

```
[Unit]
Description=RotorHazard Server
After=multi-user.target

[Service]
WorkingDirectory=/home/pi/RotorHazard/src/server
ExecStart=/usr/bin/python server.py

[Install]
WantedBy=multi-user.target
```

Speichern und beenden (STRG-X, Y, ENTER).

Berechtigungen anpassen:

```
sudo chmod 644 /lib/systemd/system/rotorhazard.service
```

Aktivieren Sie den Dienst:

```
sudo systemctl daemon-reload
sudo systemctl enable rotorhazard.service
sudo reboot
```

#### Beenden des Serverdienstes

Wenn der RotorHazard-Server während des Startvorgangs als Dienst gestartet wurde, kann er mit einem Befehl wie dem folgenden gestoppt werden:

```
sudo systemctl stop rotorhazard
```

Geben Sie Folgendes ein, um den Dienst zu deaktivieren (damit er beim Systemstart nicht mehr ausgeführt wird):

```
sudo systemctl disable rotorhazard.service
```

### System herunterfahren

Ein Herunterfahren des Systems sollte immer durchgeführt werden, bevor der Netzstecker gezogen wird, indem Sie entweder auf der Seite "Einstellungen" auf die Schaltfläche "Herunterfahren" klicken oder Folgendes in ein Terminal eingeben:

```
sudo shutdown now
```

### Aktualisieren einer vorhandenen Installation

Vor dem Update sollte jeder aktuell ausgeführte RotorHazard-Server gestoppt werden. Wenn es als Dienst installiert ist, kann es mit einem Befehl wie dem folgenden gestoppt werden:

```
sudo systemctl stop rotorhazard
```

So aktualisieren Sie eine vorhandene RotorHazard-Installation: Gehen Sie zur Seite [Neueste Version](https://github.com/RotorHazard/RotorHazard/releases/latest) für das Projekt und notieren Sie den Versionscode. Ersetzen Sie in den folgenden Befehlen die beiden Vorkommen von "1.2.3" durch den aktuellen Versionscode und geben Sie die folgenden Befehle ein:

```
cd ~
wget https://codeload.github.com/RotorHazard/RotorHazard/zip/1.2.3 -O temp.zip
unzip temp.zip
mv RotorHazard RotorHazard.old
mv RotorHazard-1.2.3 RotorHazard
rm temp.zip
cp RotorHazard.old/src/server/config.json RotorHazard/src/server/
cp RotorHazard.old/src/server/database.db RotorHazard/src/server/
```

Die vorherige Installation landet im Verzeichnis 'RotorHazard.old', das gelöscht oder verschoben werden kann.

Die RotorHazard-Serverabhängigkeiten sollten ebenfalls aktualisiert werden (haben Sie etwas Geduld, dieser Befehl kann einige Minuten dauern):

```
cd ~/RotorHazard/src/server
sudo pip install --upgrade --no-cache-dir -r requirements.txt
```

### Aktivieren Sie die Portweiterleitung

Der RotorHazard-Server verwendet standardmäßig Port 5000, da dies für einige Integrationen von Drittanbietern erforderlich ist. Während Sie den Port über `HTTP_PORT` in der Datei `config.json` ändern können, besteht ein besserer Ansatz häufig darin, den Web-Standardport von 80 bis 5000 weiterzuleiten.

Standardmäßig verwendet HTTP Port 80. Für andere Werte muss der Port als Teil der in Client-Browsern eingegebenen URL enthalten sein. Wenn andere Webdienste auf dem Pi ausgeführt werden, wird Port 80 möglicherweise bereits verwendet, und die Wiederverwendung führt zu Problemen. Wenn Port 80 direkt über `HTTP_PORT` verwendet wird, muss der Server möglicherweise mit dem Befehl *sudo* ausgeführt werden. Mit den folgenden Befehlen wird der Server auf Port 5000 ausgeführt, aber das System sendet den Datenverkehr von Port 80 an Port 80.

```
sudo iptables -A PREROUTING -t nat -p tcp --dport 80 -j REDIRECT --to-ports 5000
sudo iptables-save
sudo apt-get install iptables-persistent
```

Nach dem Ausführen dieser Befehle ist RotorHazard an beiden Ports 80 und 5000 verfügbar. Wenn es an Port 80 verfügbar ist, können Sie den Port beim Zugriff auf den Server deaktivieren: `http://127.0.0.1`
<br/>

---

### Andere Betriebssysteme

Der RotorHazard-Server kann auf jedem Computer mit einem Betriebssystem ausgeführt werden, das Python unterstützt. In diesen alternativen Konfigurationen können ein oder mehrere Hardwareknoten über USB verbunden sein. Weitere Informationen finden Sie unter [doc/USB Nodes.md](USB%20Nodes.md). Der Server kann auch mit simulierten (Schein-) Knoten ausgeführt werden.

So installieren Sie den RotorHazard-Server auf diesen Systemen:

1. Wenn auf dem Computer Python noch nicht installiert ist, laden Sie Python Version 2.7 von https://www.python.org/downloads herunter und installieren Sie es. Um zu überprüfen, ob Python installiert ist, öffnen Sie eine Eingabeaufforderung und geben Sie ```python --version``` ein
2. Laden Sie von RotorHazard [Veröffentlichungsseite auf github](https://github.com/RotorHazard/RotorHazard/releases) die Datei "Quellcode (zip)" herunter.
3. Entpacken Sie die heruntergeladene Datei in ein Verzeichnis (auch bekannt als Ordner) auf dem Computer.
4. Öffnen Sie eine Eingabeaufforderung und navigieren Sie zum Verzeichnis `src/server` in den RotorHazard-Dateien (mit dem Befehl 'cd').
5. Installieren Sie die RotorHazard-Serverabhängigkeiten mithilfe der Datei 'requirements.txt' mit einem der folgenden Befehle (Beachten Sie, dass für diesen Befehl möglicherweise Administratorzugriff auf den Computer erforderlich ist und der Befehl einige Minuten dauern kann):

* Auf einem Windows-System lautet der zu verwendende Befehl wahrscheinlich:<br/>```python -m pip install -r requirements.txt```<br/><br/>
* Auf einem Linux-System lautet der zu verwendende Befehl wahrscheinlich:<br/>```sudo pip install -r requirements.txt```<br/>

So führen Sie den RotorHazard-Server auf diesen Systemen aus:

1. Öffnen Sie eine Eingabeaufforderung und navigieren Sie zum Verzeichnis `src/server` in den RotorHazard-Dateien (falls nicht bereits vorhanden).
2. Geben Sie ```python server.py``` ein.
3. Wenn der Server ordnungsgemäß gestartet wird, sollten verschiedene Protokollmeldungen angezeigt werden, darunter eine wie folgt:

   ```
   Running http server at port 5000
   ```
4. Der Server kann durch Drücken von Strg-C gestoppt werden

Wenn Hardwareknoten über USB verbunden sind, müssen sie im Abschnitt `SERIAL_PORTS` in der Konfigurationsdatei "src/server/config.json" konfiguriert werden (siehe [doc/USB Nodes.md](USB%20Nodes.md) für Details).

Wenn keine Hardwareknoten konfiguriert sind, arbeitet der Server mit simulierten (Schein-) Knoten. In diesem Modus kann die Web-GUI-Oberfläche untersucht und getestet werden.

Um die Web-GUI-Oberfläche anzuzeigen, öffnen Sie einen Webbrowser und geben Sie in die Adressleiste Folgendes ein: `localhost:5000` (Wenn der HTTP_PORT-Wert in der Konfiguration geändert wurde, verwenden Sie diesen Wert anstelle von 5000). Wenn der Server ausgeführt wird, sollte die RotorHazard-Hauptseite angezeigt werden. Beachten Sie, dass für den Rennleiter reservierte Seiten (Admin / Einstellungen) mit dem in der Konfiguration angegebenen Benutzernamen und Passwort passwortgeschützt sind.
<br/>

---

### Protokollierung

Der RotorHazard-Server generiert "Protokoll" -Nachrichten mit Informationen zu seinen Vorgängen. Unten finden Sie eine Beispielkonfiguration für die Protokollierung:

```
    "LOGGING": {
        "CONSOLE_LEVEL": "INFO",
        "SYSLOG_LEVEL": "NONE",
        "FILELOG_LEVEL": "INFO",
        "FILELOG_NUM_KEEP": 30,
        "CONSOLE_STREAM": "stdout"
    }
```

Die folgenden Protokollstufen können angegeben werden: DEBUG, INFO, WARNING, WARN, ERROR, FATAL, CRITICAL, NONE

Wenn der Wert FILELOG_LEVEL nicht NONE ist, generiert der Server Protokolldateien im Verzeichnis `src/server/logs`. Bei jedem Start des Servers wird eine neue Protokolldatei erstellt, wobei jede Datei einen eindeutigen Namen hat, der auf dem aktuellen Datum und der aktuellen Uhrzeit basiert (d. H. "Rh_20200621_181239.log"). Wenn Sie FILELOG_LEVEL auf DEBUG setzen, werden detailliertere Protokollmeldungen in der Protokolldatei gespeichert. Dies kann beim Debuggen von Problemen hilfreich sein.

Der Wert FILELOG_NUM_KEEP gibt die Anzahl der zu speichernden Protokolldateien an. Der Rest wird gelöscht (älteste zuerst).

Der CONSOLE_STREAM-Wert kann "stdout" oder "stderr" sein.

Wenn der Wert SYSLOG_LEVEL nicht NONE ist, sendet der Server Protokollnachrichten an das im Host-Betriebssystem integrierte Protokollierungsdienstprogramm.

Das aktuelle Serverprotokoll wird möglicherweise über den Eintrag "Serverprotokoll anzeigen" im Dropdown-Menü angezeigt. Das angezeigte Protokoll ist "live", da es aktualisiert wird, wenn neue Nachrichten generiert werden. Das Protokoll kann in einem separaten Fenster angezeigt werden, indem Sie mit der rechten Maustaste auf den Menüpunkt "Serverprotokoll anzeigen" klicken und die Option "Link in neuem Fenster öffnen" (oder ähnlich) auswählen.

Durch Klicken auf die Schaltfläche "Text auswählen" wird der gesamte angezeigte Protokolltext ausgewählt, der dann kopiert und eingefügt werden kann. Durch Klicken auf die Schaltfläche "Protokolle herunterladen" wird eine ZIP-Archivdatei erstellt und heruntergeladen, die alle verfügbaren Protokolldateien sowie die aktuellen Konfigurations- und Datenbankdateien enthält. Die '.zip'-Archivdatei kann auch generiert werden, indem der Server mit dem folgenden Befehl ausgeführt wird: `python server.py --ziplogs`

Wenn Sie Probleme melden, wird dringend empfohlen, die Schaltfläche "Protokolle herunterladen" zu verwenden und die generierte ZIP-Datei einzuschließen.

<br/>

---

Siehe auch:
[doc/Hardware Setup.md](Hardware%20Setup.md)<br/>
[doc/USB Nodes.md](USB%20Nodes.md)<br/>
[doc/User Guide.md](User%20Guide.md)

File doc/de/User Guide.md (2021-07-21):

# RotorHazard Race Timer Benutzerhandbuch

## Ersteinrichtung

### Hardware- und Software-Setup

Befolgen Sie die Anweisungen hier, falls dies noch nicht geschehen ist: <br>
[Hardware Setup](Hardware%20Setup.md)<br>
[Software Setup](Software%20Setup.md)<br>
[RF shielding](Shielding%20and%20Course%20Position.md)

### Konfigurationsdatei einrichten

Suchen Sie im Verzeichnis "src / server" nach *config-dist.json* und kopieren Sie es nach *config.json*. Bearbeiten Sie diese Datei und ändern Sie die Werte ADMIN_USERNAME und ADMIN_PASSWORD. Diese Elemente in dieser Datei müssen im gültigen JSON-Format vorliegen. Ein Linter-Dienstprogramm wie [JSONLint](https://jsonlint.com/) kann verwendet werden, um nach Syntaxfehlern zu suchen.

ADMIN_USERNAME und ADMIN_PASSWORD sind die Anmeldeinformationen, die Sie benötigen, um auf die für den Rennleiter reservierten Seiten zuzugreifen (d. H. Auf die Seiten *Einstellungen* und *Ausführen*).

### Stellen Sie eine Verbindung zum Server her

Ein Computer, ein Smartphone oder ein Tablet kann zur Interaktion mit dem Race-Timer verwendet werden, indem ein Webbrowser gestartet und die IP-Adresse des Raspberry Pi eingegeben wird. Der Raspberry Pi kann über ein Ethernet-Kabel oder ein verfügbares WiFi-Netzwerk verbunden werden. Wenn die IP-Adresse des Pi nicht bekannt ist, kann sie mit dem Terminalbefehl "ifconfig" angezeigt und über die "Netzwerkeinstellungen" auf dem Pi-Desktop auf einen statischen Wert konfiguriert werden. Wenn der Pi mit einem WiFi-Netzwerk verbunden ist, finden Sie seine IP-Adresse in der Liste "Clients" auf der Administrationsseite für den Router des Netzwerks.

Geben Sie im Webbrowser die IP-Adresse von für den Race-Timer und den Portwert ein, den Sie in der Konfigurationsdatei festgelegt haben (oder lassen Sie den Port: weg, wenn er auf 80 eingestellt ist).

```
XXX.XXX.XXX.XXX:5000
```

Sobald die Seite erfolgreich angezeigt wurde, kann sie im Browser mit einem Lesezeichen versehen werden. Für den Rennleiter reservierte Seiten ("Admin / Einstellungen") sind mit dem in der Konfigurationsdatei angegebenen Benutzernamen und Passwort passwortgeschützt.

## Seiten

### Home

Auf dieser Seite werden der Name und die Beschreibung des Ereignisses sowie eine Reihe von Schaltflächen für verschiedene andere Seiten angezeigt.

### Veranstaltung

Auf dieser öffentlichen Seite werden das aktuelle Klassen-Setup (falls zutreffend) sowie eine Zusammenfassung der Piloten und ihrer Vorläufe mit Kanalzuweisung angezeigt.

### Ergebnisse

Auf dieser öffentlichen Seite werden Ergebnisse und berechnete Statistiken aller zuvor gespeicherten Rennen angezeigt, die in zusammenklappbaren Feldern organisiert sind. Die Gesamtergebnisse werden für jeden Lauf mit mehreren Runden, jeder Klasse und dem gesamten Ereignis angezeigt.

### Aktuell

Auf dieser Seite werden Informationen zum aktuell laufenden Rennen angezeigt, einschließlich Echtzeit-Rennzeit, Rundenzeiten des Piloten und Rangliste. Es wird automatisch mit dem Ereignis aktualisiert und eignet sich für die Projektion auf einen gut sichtbaren Bildschirm.

Im Abschnitt Audiosteuerung kann der Benutzer auswählen, ob für einen Piloten, alle Piloten oder keine Piloten Runden angekündigt werden sollen. Auf diese Weise kann ein Pilot entscheiden, nur seine eigenen angekündigten Runden zu hören. Ein Benutzer kann auch die Stimme, Lautstärke, Rate und Tonhöhe dieser Ansagen anpassen.

### Einstellungen

Auf dieser Seite können Sie die optionalen Einstellungen und das Ereignis-Setup des Timers ändern.

#### Frequenzeinstellung

Wählen Sie eine Voreinstellung oder wählen Sie die Frequenzen für jeden Knoten manuell aus. Eine beliebige Frequenzauswahl ist möglich, ebenso wie das Deaktivieren eines Knotens. Der IMD-Wert für aktuell ausgewählte Frequenzen wird berechnet und am unteren Rand des Bedienfelds angezeigt.

Profile enthalten Frequenzen und Knotenoptimierungswerte. Durch Ändern dieser Liste wird das ausgewählte Profil sofort aktiviert, und durch Ändern der aktuellen Frequenzen und der Knotenoptimierung wird sofort im Profil gespeichert.

#### Sensor-Tuning

Eine ausführliche Beschreibung und Tuning-Anleitung finden Sie hier [doc/Tuning Parameters.md](Tuning%20Parameters.md).

#### Veranstaltung und Klassen

Ereignisinformationen werden auf der Startseite angezeigt, wenn Benutzer zum ersten Mal eine Verbindung zum System herstellen.

Für Veranstaltungen sind keine Klassen erforderlich. Es ist nicht erforderlich, eine Klasse zu erstellen, es sei denn, Sie haben zwei oder mehr in dem Ereignis. Klassen können verwendet werden, um separate Statistiken für Gruppen von Vorläufen zu generieren. Zum Beispiel Open- und Spec-Klassen oder Anfänger- / Pro-Klassen.

#### Vorläufe

Fügen Sie Läufe hinzu, bis genug für alle Piloten vorhanden sind. Falls gewünscht, können optionale Wärmenamen hinzugefügt werden. Heizschlitze können auf *Keine* gesetzt werden, wenn dort kein Pilot zugewiesen ist.

Wenn Sie Klassen verwenden, weisen Sie jede Hitze einer Klasse zu. Stellen Sie sicher, dass für jeden Piloten in jeder Klasse genügend Vorläufe vorhanden sind. Läufe, die einer Klasse zugeordnet sind, sind in einer anderen nicht verfügbar.

Während Sie Rennen laufen, werden die Vorläufe gesperrt und können nicht geändert werden. Dies schützt gespeicherte Renndaten vor Ungültigkeit. Um die Vorläufe erneut zu ändern, öffnen Sie das Bedienfeld *Datenbank* und löschen Sie die Rennen.

#### Piloten

Fügen Sie einen Eintrag für jeden Piloten hinzu, der Rennen fahren wird. Das System kündigt Piloten anhand ihres Rufzeichens an. Eine phonetische Schreibweise für ein Rufzeichen kann verwendet werden, um die Sprachanrufe zu beeinflussen. es ist nicht notwendig.

#### Audiosteuerung

Alle Audiosteuerelemente sind lokal für den Browser und das Gerät, auf dem Sie sie eingestellt haben, einschließlich der Liste der verfügbaren Sprachen, Lautstärken und der verwendeten Ansagen oder Anzeigen.

Sprachauswahl wählt die Text-zu-Sprache-Engine. Die verfügbaren Optionen werden vom Webbrowser und vom Betriebssystem bereitgestellt.

Mit Ankündigungen kann der Benutzer wählen, ob er das Rufzeichen, die Rundennummer und / oder die Rundenzeit jedes Piloten beim Überqueren hören möchte. Die Ankündigung "Race Timer" zeigt perio an, wie viel Zeit verstrichen ist oder noch verbleibt, abhängig vom Timer-Modus im Race-Format. "Team Lap Total" wird nur verwendet, wenn "Team Racing Mode" aktiviert ist.

Sprachlautstärke, Frequenz und Tonhöhe steuern alle Text-zu-Sprache-Ansagen. "Tonlautstärke" steuert die Start- und Endsignale des Rennens.

Anzeigetöne sind sehr kurze Töne, die Rückmeldung über die Funktionsweise des Timers geben und am nützlichsten sind, wenn Sie versuchen, ihn abzustimmen. Jeder Knoten ist mit einer eindeutigen Tonhöhe gekennzeichnet. "Crossing Entered" piept einmal, wenn ein Pass beginnt, und "Crossing Exited" piept zweimal schnell, wenn ein Pass abgeschlossen ist. Die Taste "Manuelle Runde" piept einmal, wenn mit der Taste "Manuell" ein simulierter Durchgang erzwungen wird.

#### Rennformat

Rennformate definieren, wie ein Rennen durchgeführt wird. Wähle ein aktives Rennformat. Einstellungen, die Sie hier anpassen, werden im aktuell aktiven Format gespeichert.

Der Renntimer kann nach oben oder unten zählen, wie im Renn-Timer-Modus ausgewählt. Verwenden Sie "No Time Limit" für einen "First to X Laps" -Stil mit einem Timer, der von Null aufwärts zählt. Verwenden Sie "Feste Zeit" für einen Timer, der nach dem Start des Rennens auf Null herunterzählt. Die Zeitdauer wird im Modus "Feste Zeit" verwendet, um die Länge des Rennens zu bestimmen.

Jedes Rennen beginnt mit einer Inszenierungssequenz. Race Staging kann mit einer festen oder variablen Anzahl von Staging-Sekunden und mit oder ohne Staging-Töne durchgeführt werden. Stellen Sie die _Minimum Start Delay_ und _Maximum Start Delay_ auf die Werte (in Sekunden) ein, die für die Rennstrecke gewünscht werden. Wenn diese Werte unterschiedlich sind, wählt der Timer einen zufälligen Wert für die Staging-Zeit. Zufällige Staging-Zeiten sind nützlich, um Fehlstarts zu verhindern. Der Timer zeigt während der Bereitstellung "Bereit" an und verdeckt die Startzeit des Rennens. Stellen Sie für eine feste Staging-Zeit "Minimum" und "Maximum" auf den gleichen Wert ein. Der Staging-Timer zeigt offen die Anzahl der Sekunden an, bis das Rennen beginnt.

_Eine kleine Zeit wird benötigt, um sicherzustellen, dass der Timer mit der gesamten Hardware synchronisiert wurde, sodass selbst bei einer Staging-Zeit von Null eine kurze Staging-Zeitspanne vorhanden ist._

Während der Staging-Sequenz kann eine Anzahl von Tönen erzeugt werden, wie durch _Staging-Töne_ festgelegt. Bei "Jede Sekunde" gibt der Timer während der Inszenierung kontinuierlich einen Ton aus. Mit "Eins" gibt der Timer sofort zu Beginn der Inszenierung einen Ton aus. Bei "Keine" wird keine akustische Warnung ausgegeben. Unabhängig von der Einstellung _Staging Tones_ wird der Ton "Race Start" immer noch abgespielt, wenn das Staging abgeschlossen ist und das Rennen beginnt.

_Win Condition_ bestimmt, wie der Timer den Gewinner des Rennens anruft, welche Informationen im OSD und in der Streaming-Anzeige angezeigt werden und welche Sortiermethode für Bestenlisten verwendet wird. Die Sortierung der Bestenlisten wirkt sich auf die Ergebnisseite und den Wärmeerzeuger aus.

* __Die meisten Runden in der schnellsten Zeit__: Die Piloten werden anhand der Anzahl der absolvierten Runden und der Dauer ihrer Runden beurteilt. Wenn es ein Unentschieden für die Anzahl der absolvierten Runden gibt, wird der Pilot, der diese Runden in kürzerer Zeit absolviert hat, höher eingestuft.
* __Nur die meisten Runden__: Wird nur nach der Anzahl der abgeschlossenen Runden gewertet. Piloten mit der gleichen Rundenzahl sind gebunden. Verwenden Sie den Modus "Feste Zeit" für einen Rennstil, bevor das Timing zuverlässig war, oder den Modus "Kein Zeitlimit", um die größte Distanz anstelle der kürzesten Zeit zu beurteilen.
* __Die meisten Runden nur mit Überstunden__: Ähnlich wie _Most Runden in der schnellsten Zeit_, jedoch mit einer Komponente "Plötzlicher Tod". Wenn der Timer abläuft (oder das Rennen vorzeitig abgebrochen wird), wenn ein Pilot mehr Runden als alle anderen hat, ist dieser Pilot der Gewinner. Wenn nach Ablauf des Timers ein Gleichstand für die Rundenanzahl besteht, ist der erste der gebundenen Piloten auf der ganzen Linie der Gewinner.
* __Erste bis X Runden__: Das Rennen wird fortgesetzt, bis ein Pilot die gewünschte Rundenzahl erreicht hat. In diesem Modus wird der Parameter _Number of Laps to Win_ verwendet. Wird normalerweise im Rennmodus _No Time Limit_ verwendet.
* __Schnellste Runde__: Ignoriert den Rennfortschritt und berücksichtigt nur die schnellste Einzelrunde jedes Piloten.
* __Schnellste 3 aufeinanderfolgende Runden__: Berücksichtigt alle Runden, die ein Pilot absolviert hat, und verwendet die drei aufeinander folgenden Runden mit der schnellsten kombinierten Zeit.
* __None__: Erklärt unter keinen Umständen einen Gewinner. Vorläufe, die aus einer Klasse mit dieser Bedingung generiert wurden, werden zufällig zugewiesen.

_Team Racing Mode_ aktiviert die alternative Wertung für zusätzliche Rennformate. Die Gewinnbedingungen im Teamrennmodus unterscheiden sich etwas:

* __Die meisten Runden in der schnellsten Zeit__: Die Teams werden anhand der Gesamtzahl der Runden aller Mitglieder und der Dauer dieser Runden beurteilt.
* __Nur die meisten Runden__: Die Teams werden anhand der Gesamtzahl der kombinierten Runden aller Mitglieder beurteilt.
* __Die meisten Runden nur mit Überstunden__: Die Teams werden anhand der Gesamtzahl der kombinierten Runden aller Mitglieder beurteilt. Wenn nach Ablauf der Zeit ein Gleichstand besteht, gewinnt das erste Team (von dem Unentschieden), das eine Runde hinzugefügt hat, den Sieger.
* __Erste bis X Runden__: Das erste Team, das die gewünschte Anzahl kombinierter Runden erreicht hat, ist der Gewinner.
* __Schnellste Runde__: Nachdem alle Teammitglieder eine Runde beigesteuert haben, werden die Teams anhand des Durchschnitts der schnellsten Rundenzeit der Piloten beurteilt.
* __Schnellste 3 aufeinanderfolgende Runden__: Nachdem alle Teammitglieder 3 Runden beigesteuert haben, werden die Teams anhand des Durchschnitts der schnellsten "drei aufeinander folgenden Runden" der Piloten beurteilt.

Mit _Fastest Lap_ und _Fastest 3 Consecutive Laps_ können Teams mit unterschiedlich vielen Piloten fair miteinander konkurrieren.

_Minimale Rundenzeit_ markiert oder verwirft Pässe, bei denen Runden registriert worden wären, die kürzer als die angegebene Dauer sind. Verwenden Sie das Verhalten "Verwerfen" mit Vorsicht, da dadurch möglicherweise gültige Daten entfernt werden. _Minimum Lap Time_ wird nicht im Rennformat gespeichert.

#### LED-Effekte

Wählen Sie für jedes Timer-Ereignis einen visuellen Effekt. Der Timer zeigt diesen Effekt an, wenn das Ereignis eintritt, und überschreibt sofort alle vorhandenen Anzeigen oder Effekte. Einige visuelle Effekte sind nur für bestimmte Timer-Ereignisse verfügbar. Einige visuelle Effekte werden durch das Ereignis verändert, insbesondere die Farbe der Ein- und Ausgänge der Gate-Kreuzung. Die meisten Effekte können über das LED-Bedienfeld in der Vorschau angezeigt werden.

Einige LED-Effekte können sich kurz verzögern, wenn der Timer mit zeitkritischen Aufgaben beschäftigt ist. (Andere wie der Start des Rennens werden nie verzögert.) Aufgrund dieses Effekts und möglicherweise gleichzeitiger Überfahrten sollte "Ausschalten" normalerweise für Torausgänge vermieden werden. Verwenden Sie stattdessen _"No Change"_ am Gate-Eingang und den gewünschten Effekt beim Gate-Ausgang.

_Dieser Abschnitt wird nicht angezeigt, wenn für Ihren Timer keine LEDs konfiguriert sind. Ein Hinweis wird im Startprotokoll angezeigt._

#### LED-Steuerung

Dieser Abschnitt überschreibt die aktuelle LED-Anzeige. Wählen Sie diese Option, um die Anzeige vorübergehend auszuschalten, einige vorkonfigurierte Farben anzuzeigen, benutzerdefinierte Farben anzuzeigen oder einen definierten Effekt anzuzeigen. Sie können auch den Schieberegler verwenden, um die Helligkeit Ihres Panels anzupassen. Die ideale Einstellung für FPV-Kameras ist, wenn das beleuchtete Feld der Helligkeit eines weißen Objekts entspricht. Dadurch liegt die Panel-Ausgabe innerhalb des Dynamikbereichs, den die Kamera erfassen kann. Die Verwendung einer niedrigen Helligkeitseinstellung verzerrt jedoch die Farbwiedergabe und die Glätte der Farbübergänge.

_Dieser Abschnitt wird nicht angezeigt, wenn für Ihren Timer keine LEDs konfiguriert sind. Ein Hinweis wird im Startprotokoll angezeigt._

#### Datenbank

Wählen Sie, ob Sie die aktuelle Datenbank sichern (in einer Datei auf dem Pi speichern und zum Herunterladen auffordern) oder Daten löschen möchten. Sie können Rennen, Klassen, Vorläufe und Piloten beenden.

#### System

Wählen Sie die Sprache der Benutzeroberfläche aus und ändern Sie Parameter, die sich auf das Erscheinungsbild des Timers auswirken, z. B. Name und Farbschema. Sie können den Server auch von hier aus herunterfahren.

### Lauf

Auf dieser Seite können Sie den Timer steuern und Rennen starten.

Wählen Sie die Hitze für das Rennen, das als nächstes ausgeführt werden soll.

Starten Sie das Rennen, wenn Sie bereit sind. (Hotkey: <kbd>z</kbd>). Der Timer führt eine schnelle Kommunikation mit dem Server durch, um die Client / Server-Antwortzeit zu kompensieren, und beginnt dann mit dem durch das aktuelle Race-Format definierten Staging-Verfahren.

Die Tuning-Parameter können hier über die Taste eingestellt werden.Eine ausführliche Beschreibung und Tuning-Anleitung finden Sie hier [doc/Tuning Parameters.md](Tuning%20Parameters.md).

Während des Rennens steht neben jeder gezählten Runde ein "×". Dadurch wird dieser Rundenpass verworfen, sodass seine Zeit auf die nächste Runde verschoben wird. Verwenden Sie diese Option, um fehlerhafte zusätzliche Pässe zu entfernen oder Piloten zu bereinigen, die nach Beendigung des Rennens in der Nähe des Starttors fliegen.

Durch Drücken der Taste "+ Runde" wird manuell ein Rundenpass für diesen Knoten ausgelöst.

Wenn ein Rennen beendet ist, verwenden Sie die Schaltfläche "Rennen stoppen" (Hotkey: <kbd>x</kbd>), um das Zählen von Runden abzubrechen. Sie müssen dies auch dann tun, wenn der Timer in einem "Countdown" -Format Null erreicht. Ein beliebtes Rennformat ermöglicht es den Piloten, die Runde zu beenden, auf der sie sich befinden, wenn die Zeit abgelaufen ist. Um optimale Ergebnisse zu erzielen, löschen Sie das Timing-Gate und lassen Sie alle gültigen Überfahrten enden, bevor Sie das Rennen beenden.

Sobald ein Rennen beendet ist, müssen Sie "Runden speichern" oder "Runden verwerfen" wählen, bevor Sie ein anderes Rennen starten. "Runden speichern" (Hotkey: <kbd>c</kbd>) speichert die Rennergebnisse in der Datenbank und zeigt sie auf der Seite "Ergebnisse" an. "Runden verwerfen" (Hotkey: <kbd>v</kbd>) verwirft die Rennergebnisse. Durch das Speichern von Runden wird die Auswahl des Laufs automatisch auf den nächsten Lauf mit derselben Klasse wie beim gespeicherten Rennen vorgerückt.

Das Race Management-Bedienfeld bietet schnellen Zugriff zum Ändern des aktuellen Rennformats, Profils, der minimalen Rundenzeit oder des Team-Rennmodus. _Audio Control_ und _LED Control_ entsprechen der Seite Einstellungen. Der Verlaufsexport gibt eine CSV-Datei aus, die von den aufgezeichneten RSSI-Werten des zuletzt abgeschlossenen Rennens heruntergeladen werden soll. "Zeit bis zum Start des Rennens" plant ein Rennen, das zu einem späteren Zeitpunkt durchgeführt werden soll. Die Betreiber können dies verwenden, um ein festes Limit für die Zeit festzulegen, die Piloten zur Vorbereitung benötigen, oder um den Timer zu starten und dann selbst am Rennen teilzunehmen.

### Marshal

Passen Sie die Ergebnisse gespeicherter Rennen an.

Wählen Sie die Runde, die Hitze und den Piloten aus, um sie anzupassen. Ein- und Ausstiegspunkte werden automatisch aus den gespeicherten Renndaten geladen. Passen Sie die Ein- und Ausstiegspunkte an, um das Rennen nachträglich neu zu kalibrieren. "Vom Knoten laden", um aktuelle Live-Kalibrierungsdaten über die aktiven Werte zu kopieren. "Auf Knoten speichern", um die aktiven Werte über die aktuellen Live-Werte zu kopieren. "Rennen neu berechnen", um die aktiven Ein- / Ausstiegswerte als Kalibrierungspunkte für eine "Wiederholung" des Rennens zu verwenden. Dadurch werden aktuelle Runden gelöscht und durch die neu berechneten Informationen ersetzt. Manuell eingegebene Runden bleiben erhalten.

Fügen Sie Runden hinzu, indem Sie die Überfahrtzeit in Sekunden ab Rennbeginn eingeben und dann auf die Schaltfläche "Runde hinzufügen" klicken.

Löschen Sie Runden mit der Taste "×" in der unerwünschten Runde. Gelöschte Runden werden aus den Berechnungen entfernt, bleiben jedoch zur späteren Bezugnahme in den Daten vorhanden. "Runden verwerfen", um die Daten dauerhaft aus der Datenbank zu entfernen.

Sie können auf das Diagramm klicken / es berühren, um Ein- / Ausstiegspunkte festzulegen, die Neuberechnung zu aktivieren und bestimmte Runden hervorzuheben. Durch Klicken auf Runden in der Liste wird auch eine Markierung in der Grafik hinzugefügt. Drücken Sie <kbd>delete</kbd> oder <kbd>x</kbd>, um eine markierte Runde zu löschen. Aktive Runden werden grün angezeigt und gelöschte Runden werden rot. Die Breite der Rundenanzeige zeigt die Ein- / Ausstiegspunkte an, und die gelbe Markierung zeichnet eine Linie zur genauen Rundenzeit in diesem Fenster.

"Änderungen übernehmen", wenn Sie mit dem Anpassen der Renndaten fertig sind, um sie in der Datenbank zu speichern und die Rennergebnisse zu aktualisieren.

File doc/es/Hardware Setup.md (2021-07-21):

# Instrucciones de Configuración del Hardware

## Lista de componentes

### Nodo/s del receptor (esta lista forma un nodo, pero se pueden montar hasta ocho)
* 1 x [Arduino Nano](https://www.ebay.com/sch/i.html?_nkw=Arduino+Nano+V3.0+16M+5V+ATmega328P)
* 1 x [RX5808 module](https://www.banggood.com/search/rx5808-module.html) con el mod SPI (se sabe que los módulos con el código de fecha 20120322 funcionan)
* 3 resistencias x 1k ohm 
* 1 resistencia x 100k ohm
* Cable de silicona: medida 26 AWG y 30 AWG

### Componentes del Sistema
* 1 x Raspberry Pi3 (los usuarios de Pi2 han reportado problemas con múltiples nodos conectados)
* 8 GB (mínimo) Micro SD Card
* Cable de silicona de 26 AWG y 30 AWG (para cablear cada nodo del receptor)
* Carcasa 3D o similar para alojar todos los componentes
* Fuente de alimentación de 5V, de 3 amperios como mínimo (o fuente de alimentación de 12V si se utilizan reguladores a bordo)

### Componentes adicionales
* Blindaje RF (ver debajo)

### Componentes Opcionales
* Cable Ethernet, 30m o más
* Cable de corriente de exterior, 30 metros o más
* Enrutador de red
* Ordenador portáti / Tablet pc
* ws2812b LEDs

## Configuración del Hardware

### Receptores de vídeo RX5808 
Asegúrese de que sus receptores sean compatibles con SPI. * La mayoría de los módulos RX5808 a la venta ya llegan con SPI habilitado. * Si no lo hacen, modifique los receptores RX5808 para habilitar el soporte SPI de la siguiente manera:

Retire el escudo del RX5808, el escudo normalmente está sujeto por unos pocos puntos de soldadura alrededor de los bordes. Use una mecha de soldadura para eliminar la soldadura y liberar el escudo del receptor. Tenga cuidado de no dañar las almohadillas de tierra en el receptor. Por lo general, hay pequeños agujeros alrededor del borde que puede usar para ayudar a empujar el escudo.

Retire la siguiente resistencia:
RX5808 spi mod

Vuelva a soldar el escudo protector una vez haya retirado la resistencia.

### Nodos Receptores
Complete el cableado entre cada Arduino y RX5808.
receiver node wiring

Nota: También se puede construir y conectar un nodo receptor simple a través de USB -- vea [doc/USB Nodes.md](USB%20Nodes.md).

### Ensamblaje del Sistema
Complete las conexiones de cableado entre cada Arduino y la Raspberry Pi.

Nota: asegúrese de que todos los nodos del receptor y la Raspberry Pi estén vinculados a un negativo (GND) común; si no, los mensajes de i2c pueden corromperse.
system wiring

### Agregar un blindaje direccional de RF
Un escudo de RF direccional mejora significativamente la capacidad del sistema para rechazar pases falsos. Esto permite a los operadores aumentar su sensibilidad o construir carreras que pasan más cerca de la puerta de sincronización. Construya un escudo direccional que deje una línea de visión abierta entre el temporizador y la puerta de sincronización, pero que bloquee o atenúe las señales de RF de otras direcciones. Las opciones más populares para lograr esto son:
* Coloque el sistema dentro de una caja de metal con un lado abierto, como una lata de munición, una lata de pintura, un cubo de metal o una caja de computadora. Se recomienda conectar este estuche a una toma de tierra eléctrica en el temporizador.
* Cava un hoyo en el suelo y coloca tu estuche dentro de él
* Cubra su carcasa del sistema con cinta de cobre

### Soporte LED WS2812b
Los pines en el cuadro verde son los que ya están en uso en el temporizador. Los pines en el cuadro rojo es donde se debe conectar la señal y la tierra de los LED ws2812b. Los LED requerirán una fuente de alimentación separada. Consulte el soporte de LED WS2812b en Configuración de software.
led wiring

### Sensores adicionales
Se pueden conectar sensores (como BME280 e INA219) al bus I2C y a los pines de alimentación. Consulte los archivos '..._ sensor.py' en el directorio "src / interface" para ver ejemplos de implementación. Los sensores deben especificarse en el archivo "src / server / config.json": en la siguiente configuración de muestra, un sensor BME280 está configurado en la dirección I2C 0x76 (como "Clima") y los sensores INA219 están configurados en 0x40 y 0x41 .
```
    "SENSORES": {
            "i2c:0x76": {
                    "name": "Temperatura"
            },
            "i2c:0x40": {
                    "name": "Batería",
                    "max_current": 0.1
            },
            "i2c:0x41": {
                    "name": "Pi",
                    "max_current": 2
            }
    },
```

### Temporizadores múltiples
Se pueden conectar varios temporizadores RotorHazard entre sí (es decir, para temporización dividida y duplicación); consulte[doc/Cluster.md](Cluster.md).

-----------------------------

Vea también:<br/>
[doc/USB Nodes.md](USB%20Nodes.md)<br/>
[doc/Software Setup.md](Software%20Setup.md)<br/>
[doc/User Guide.md](User%20Guide.md)

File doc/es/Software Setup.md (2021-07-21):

#Instrucciones de configuración de software

El componente de software central del sistema RotorHazard es su servidor, escrito en Python, que opera sus funciones y sirve páginas web para los navegadores. En una configuración estándar, el servidor se ejecuta en un RaspberryPi. (También es posible ejecutar RotorHazard en otros tipos de hardware; consulte el[Other Operating Systems](#otheros) section below.)

##Instalar sistema (Raspberry Pi)
Nota: Muchos de los comandos de configuración a continuación requieren que Raspberry Pi tenga acceso a Internet.
Comience instalando Raspbian, siguiendo las instrucciones oficiales aquí: https://www.raspberrypi.org/downloads/raspbian/. Puede usar Desktop o Lite.

Configure las opciones de interfaz en la Raspberry Pi.
Abra una ventana de Terminal e ingrese el siguiente comando:
```
sudo raspi-config
```
Seleccione Opciones de Interfaz y habilite: SSH, SPI y I2C.

Actualice el sistema (esto puede tardar unos minutos):
```
sudo apt-get update && sudo apt-get upgrade
```

Instale Python y los drivers de Python para GPIO.
```
sudo apt-get install python-dev python-rpi.gpio libffi-dev python-smbus build-essential python-pip git scons swig
```

Instale la interfaz de la función en Python
```
sudo pip install cffi
```

Actualice el baudrate de puerto i2C
```
sudo nano /boot/config.txt
```
Añada las siguientes líneas al final del archivo config.txt:
```
dtparam=i2c_baudrate=75000
core_freq=250
```
Guarde y salga del archivo con Ctrl-X

Instale el código RotorHazard en '/ home / pi /' en la Raspberry Pi de la siguiente manera: Vaya a [Latest Release page](https://github.com/RotorHazard/RotorHazard/releases/latest) para el proyecto y tenga en cuenta el código de versión. En los siguientes comandos, reemplace las dos apariciones de "1.2.3" con el código de la versión actual e ingrese los comandos:
```
cd ~
wget https://codeload.github.com/RotorHazard/RotorHazard/zip/1.2.3 -O temp.zip
unzip temp.zip
mv RotorHazard-1.2.3 RotorHazard
rm temp.zip
```

Instale las dependencias del servidor RotorHazard (sea paciente, este comando puede tardar unos minutos):
```
cd ~/RotorHazard/src/server
sudo pip install -r requirements.txt
```

Actualizar permisos en la carpeta de trabajo:
```
cd ~/RotorHazard/src
sudo chmod 777 server
```

* Nota: Si RotorHazard ya está instalado, consulte el [Updating an existing installation](#update) sección abajo.*

## Instalar el Código en los Nodo Receptores (Arduinos)
Requiere Arduino 1.8 o superior. Descárguelo de https://www.arduino.cc/en/Main/Software

* El código de nodo y la versión del servidor deben coincidir. Utilice el código 'nodo' incluido con el código del servidor que descargó anteriormente; no descargue un archivo diferente directamente desde GitHub. *

El código de nodo se puede editar y construir utilizando el[Eclipse IDE](https://www.eclipse.org/eclipseide/) y el "[Eclipse C++ IDE for Arduino](https://marketplace.eclipse.org/content/eclipse-c-ide-arduino)"plugin (o la forma tradicional usando el IDE de Arduino). En Eclipse, el proyecto de código de nodo se puede cargar a través de "Archivo | Abrir proyectos desde el sistema de archivos ..."

Edite el archivo 'src / node / config.h' y configure el valor '#define NODE_NUMBER' para cada nodo antes de cargarlo. Para el primer nodo, configure NODE_NUMBER en 1, para el segundo configúrelo en 2, etc.

```
// Node Setup -- Set node number here (1 - 8)
#define NODE_NUMBER 1
```
También se puede configurar de manera automática los nodos mediante la conexión a tierra de estos pines de los Arduinos. Establezca NODE_NUMBER en 0, luego empalme estos pines a tierra (GND):

nodo #1: GND a pin D5<br/>
nodo #2: GND a pin D6<br/>
nodo #3: GND a pin D7<br/>
nodo #4: GND a pin D8<br/>
nodo #5: GND a pin D5 y pin D4<br/>
nodo #6: GND a pin D6 y pin D4<br/>
nodo #7: GND a pin D7 y pin D4<br/>
nodo #8: GND a pin D8 y pin D4<br/>

## Instalar Componentes opcionales
### Soporte WS2812b LED
Los controles de los LED ws2812b se proporcionan en el siguiente proyecto:
https://github.com/jgarff/rpi_ws281x

Clone el repositorio en la Pi e inicie Scons:
```
cd ~
sudo git clone https://github.com/jgarff/rpi_ws281x.git
cd rpi_ws281x
sudo scons
```

Instale la bilblioteca Python:
```
cd python
sudo python setup.py install
```

### Sensor de Voltage/Current INA219
La interfaz ina219 se proporciona en el siguiente proyecto:
https://github.com/chrisb2/pi_ina219

Clone el repositorio en la Pi:
```
cd ~
sudo git clone https://github.com/chrisb2/pi_ina219.git
cd pi_ina219
```
Instale la biblioteca Python:
```
sudo python setup.py install
```

### Sensor de Temperatura BME280
La interfaz bme280 se proporciona en el siguiente proyecto:
https://github.com/rm-hull/bme280

Clone el repositorio en la Pi:
```
cd ~
sudo git clone https://github.com/rm-hull/bme280.git
cd bme280
```
Instale la biblioteca Python:
```
sudo python setup.py install
```

### Soporte Java
Java permite el cálculo de las puntuaciones de IMD. Si comenzó con RASPBIAN WITH DESKTOP, este paso no debería ser necesario ya que Java está instalado de manera predeterminada. De otra manera:
```
sudo apt install default-jdk-headless
```

## Preparar el Sistema
### Reiniciar el Sistema
Después de realizar los pasos de configuración anteriores, el sistema debe reiniciarse ingresando lo siguiente:
```
sudo reboot
```

### Arrancando el Sistema

Las siguientes instrucciones iniciarán el servidor web en la raspberryPi, permitiendo el control total y la configuración del sistema para lanzar carreras y guardar los tiempos de vuelta.

#### Arranque Manual
Abra un terminal y escriba lo siguiente:
```
cd ~/RotorHazard/src/server
python server.py
```
El servidor se puede parar pulsando Ctrl+c

#### Arranque de inicio
Cree un servicio
```
sudo nano /lib/systemd/system/rotorhazard.service
```
con el siguiente contenido:
```
[Unit]
Description=RotorHazard Server
After=multi-user.target

[Service]
WorkingDirectory=/home/pi/RotorHazard/src/server
ExecStart=/usr/bin/python server.py

[Install]
WantedBy=multi-user.target
```
Guarde y salga (CTRL-X, Y, ENTER).

Actualice los permisos.
```
sudo chmod 644 /lib/systemd/system/rotorhazard.service
```

Inicio con los comandos de arranque.
```
sudo systemctl daemon-reload
sudo systemctl enable rotorhazard.service
sudo reboot
```

### Apagando el Sistema
El apagado del sistema siempre debe realizarse antes de desconectar la alimentación, ya sea haciendo clic en el botón 'Apagar' en la página 'Configuración' o ingresando lo siguiente en un terminal:
```
sudo shutdown now
```

### Actualizar una instalación existente

Antes de actualizar, se debe detener cualquier servidor RotorHazard que se esté ejecutando actualmente. Si se instala como un servicio, se puede detener con un comando como: `sudo systemctl stop rotorhazard`

Para actualizar una instalación existente de RotorHazard: vaya a [Latest Release page](https://github.com/RotorHazard/RotorHazard/releases/latest) para el proyecto y tenga en cuenta el código de versión. En los siguientes comandos, reemplace las dos apariciones de "1.2.3" con el código de la versión actual e ingrese los comandos:
```
cd ~
wget https://codeload.github.com/RotorHazard/RotorHazard/zip/1.2.3 -O temp.zip
unzip temp.zip
mv RotorHazard RotorHazard.old
mv RotorHazard-1.2.3 RotorHazard
rm temp.zip
cp RotorHazard.old/src/server/config.json RotorHazard/src/server/
cp RotorHazard.old/src/server/database.db RotorHazard/src/server/
```
La instalación anterior termina en el directorio 'RotorHazard.old', que se puede eliminar o mover.

Las dependencias del servidor RotorHazard también deben actualizarse (tenga paciencia, este comando puede tardar unos minutos):
```
cd ~/RotorHazard/src/server
sudo pip install --upgrade --no-cache-dir -r requirements.txt
```
<br/>

-----------------------------

### Otros sistemas operativos

El servidor RotorHazard puede ejecutarse en cualquier computadora con un sistema operativo que admita Python. En estas configuraciones alternativas, uno o más nodos de hardware se pueden conectar a través de USB; consulte [doc/USB Nodes.md](USB%20Nodes.md) para más información. El servidor también puede ejecutarse utilizando nodos simulados.

To install the RotorHazard server on these systems:

1. Si el ordenador aún no tiene Python instalado, descargue e instale Python versión 2.7 de https://www.python.org/downloads. Para verificar si Python está instalado, abra un símbolo del sistema e ingrese ```python --version```

1. Desde el RotorHazard [Releases page on github](https://github.com/RotorHazard/RotorHazard/releases), descargar el archivo "Source code (zip)".

1. Descomprima el archivo descargado en un directorio (también conocido como carpeta) en el ordenador.

1. Abra un símbolo del sistema y navegue hasta el directorio `` src / server`` en los archivos RotorHazard (usando el comando 'cd').

1. Instale las dependencias del servidor RotorHazard utilizando el archivo 'require.txt'. En un sistema Windows, el comando a usar probablemente será: ```python -m pip install -r requirements.txt```<br/>Tenga en cuenta que este comando puede requerir acceso de administrador al ordenador, y el comando puede tardar unos minutos en finalizar)

Para ejecutar el servidor RotorHazard en estos sistemas:

1. Abra un símbolo del sistema y navegue hasta el directorio ```src/server``` en los archivos RotorHazard (si aún no está allí).

1. Teclee: ```python server.py```

1. Si el servidor se inicia correctamente, debería ver varios mensajes de registro, incluido uno como este:
    ```
    Running http server at port 5000
    ```

1. El servidor se puede detener presionando Ctrl+C

Si los nodos de hardware están conectados a través de USB, deberán configurarse en la sección "SERIAL_PORTS" en el archivo de configuración "src / server / config.json" (consulte [doc/USB Nodes.md](USB%20Nodes.md) para detalles).

Si no hay configurados nodos de hardware, el servidor funcionará utilizando nodos simulados (simulados). En este modo, se puede explorar y probar la interfaz web-GUI.

Para ver la interfaz web-GUI, abra un navegador web e ingrese en la barra de direcciones: ```localhost:5000``` (Si el valor HTTP_PORT en la configuración ha cambiado, use ese valor en lugar de 5000). Si el servidor se está ejecutando, debería aparecer la página principal de RotorHazard. Tenga en cuenta que las páginas reservadas para el director de carrera (Administrador / Configuración) están protegidas con contraseña con el nombre de usuario y la contraseña especificados en la configuración.

<br/>

-----------------------------

Vea también:<br/>
[doc/Hardware Setup.md](Hardware%20Setup.md)<br/>
[doc/USB Nodes.md](USB%20Nodes.md)<br/>
[doc/User Guide.md](User%20Guide.md)

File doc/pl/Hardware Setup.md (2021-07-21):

# Instrukcja Ustawienia Sprzętu

## Lista Części

### Odnoga odbiornika (z tej listy stworzysz jedną - maksymalnie można używać ośmiu)
* 1 x [Arduino Nano](https://www.ebay.com/sch/i.html?_nkw=Arduino+Nano+V3.0+16M+5V+ATmega328P)
* 1 x [RX5808 module](https://www.banggood.com/search/rx5808-module.html) with SPI mod (modules with date code 20120322 are known to work)
* 3 x rezystor 1k Ohm
* 1 x rezystor 100k Ohm
* przewód 26 AWG i 30 AWG

### Komponenty Systemu
* 1 x Raspberry Pi3 (użytkownicy Pi2 raportowali problemy, kiedy było podłączone więcej odnóg)
* karta Micro SD - 8 GB (minimum)
* przewód 26 AWG i 30 AWG (do połączenia do każdej odnogi odbiornika)
* wydrukowana w 3D obudowa na komponenty elektroniczne
* zasilacz 5V, 3A minimum (albo zasilacz 12V jeśli używane są regulatory na płytce)

### Dodatkowe komponenty
* ekranowanie RF (zobacz poniżej)

### Opcjonalne komponenty
* Kabel Ethernet, 15m plus
* Zewnętrzny kabel zasilający, 15m plus
* Router sieciowy
* Laptop/tablet
* Paski LED-owe WS2812b

## Ustawienie sprzętu

### RX5808 - Odbiorniki Wideo
Upewnij się, że odbiorniki wspierają protokół SPI. *Większość sprzedawanych dziś odbiorników wspiera SPI.* Jeśli nie, zmodyfikuj odbiorniki RX5808, żeby wspierały ten protokół, w następujący sposób:

Zdejmij ekranowanie z odbiornika, przytwierdzone za pomocą kilku lutów na brzegach. Użyj plecionki żeby pozbyć się cyny (możesz dodać odrobinę świeżej cyny z topnikiem). Bądź ostrożny, żeby nie uszkodzić padów połączonych do masy. Przeważnie dookoła odbiornika są małe otwory, które mogą zostać użyte do zdjęcia ekranowania.

Pozbądź się następującego rezystora:
RX5808 spi mod

Ekranowanie powinno zostać przylutowane z powrotem, po wyjęciu rezystora.

### Odnogi odbiornika
Kompletne okablowanie każdego Arduino i odbiornika RX5808
okablowanie odnogi odbiornika

Uwaga: Prosty odbiornik może być również skonstruowany i podłączony przez USB - zobacz [doc/USB Nodes.md](USB%20Nodes.md).

### Złożenie Systemu
Skompletuj okablowanie każdej odnogi i Raspberry Pi.

Uwaga: Upewnij się, że wszystkie odnogi i Raspberry Pi są podłączone do wspólnej masy. Jeśli tak nie jest, transfer danych może działać nieprawidłowo.
okablowanie systemu

### Dodaj ekranowanie kierunkowe
Kierunkowe ekranowanie znacząco poprawia zdolność systemu do odrzucania fałszywych pezelotów przez bramkę. Pozwala to operatorowi na podniesienie ich czułości i budowanie torów przebiegających bliżej bramki z timerem. Skonstruuj kierunkowe ekranowanie pozostawiając niewielką linię między timerem, a mierzoną bramką, ale blokując sygnały RF z innych kierunków. Najbardziej popularne opcje, aby to osiągnąć to:
* Połóż system w metalowym pojemniku, z jedną stroną otwartą, np. w pojemniku na amunicję, wiaderku po farbie czy metalowym wiadrze albo obudowie od komputera. Zaleca się podłączenie elektrycznej masy timera do tego pojemnika.
* Wykop dziurę w ziemi i umieść tam pojemnik
* Owiń obudowę swojego timera miedzianą taśmą

### Wsparcie dla LEDów WS2812b
Piny w zielonym prostokącie są już używane przez timer. Piny zaznaczone na czerwono są tam, gdzie możesz podłączyć sygnał i masę z LED-ów WS2812b. Ledy potrzebują oddzielnego źródła zasilania. Zobacz wsparcie dla WS2812b w sekcji Ustawienia Programowe (Software Setup).
okablowanie LED

### Dodatkowe Czujniki
Czujniki (takie jak BME280 and INA219) mogą być podłączone do magistrali I2C. Zobacz pliki '..._sensor.py' w folderze "src/interface" dla przykładów zastosowania. Czujniki muszą być uwzględnione w pliku "src/server/config.json" -- w przykładowej konfiguracji poniżej czujnik BME280 jest skonfigurowany na linii I2C pod adresem 0x76 (jako "Climate") i czujnik INA219 jest skonfigurowany pod adresem 0x40 i 0x41.
```
    "SENSORS": {
            "i2c:0x76": {
                    "name": "Temperatura"
            },
            "i2c:0x40": {
                    "name": "Bateria",
                    "max_current": 0.1
            },
            "i2c:0x41": {
                    "name": "Pi",
                    "max_current": 2
            }
    },
```

### Wiele Timerów
Wiele timerów RotorHazard może być połączonych razem (np. dla pomiaru międzyczasów albo w trybie "odbicia lustrzanego") -- zobacz [doc/Cluster.md](Cluster.md).

-----------------------------

Zobacz Również:<br/>
[doc/USB Nodes.md](USB%20Nodes.md)<br/>
[doc/Software Setup.md](Software%20Setup.md)<br/>
[doc/User Guide.md](User%20Guide.md)

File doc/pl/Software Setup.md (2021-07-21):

# Instrukcje Konfiguracji Oprogramowania

Głównym komponentem oprogramowania systemu RotorHazard jest jego serwer, napisany w języku python, który operuje jego funkcjami i służy jako serwer web dla przeglądarki. W standardowym ustawieniu serwer jest włączony na Raspberry Pi. Możliwe jest włączenie RotorHazard na innym typie urządzenia – zobacz poniżej sekcję [Inne Systemy Operacyjne](#otheros).
## Zainstaluj System – (Raspberry Pi)
Uwaga: Wiele spośród wymienionych niżej komend wymaga połączenia z Internetem.

Zacznij od instalacji systemu Raspbian. Postępuj zgodnie z oficjalnymi instrukcjami na stronie:
https://www.raspberrypi.org/downloads/raspbian/. Możesz użyć wersji Desktop albo Lite.

Skonfiguruj interfejs na Raspberry Pi. Otwórz okno terminala i wpisz następujące komendy:
```
sudo raspi-config
```
Wybierz Interfacing Options i włącz: SSH, SPI, and I2C.

Wykonaj aktualizację systemu – może zająć kilka minut:
```
sudo apt-get update && sudo apt-get upgrade
```
Zainstaluj python i sterowniki python dla GPIO:
```
sudo apt-get install python-dev python-rpi.gpio libffi-dev python-smbus build-essential python-pip git scons swig
```
Zainstaluj interfejs funkcji dla python:
```
sudo pip install cffi
```
Zaktualizuj przepływność magistrali I2C:
```
sudo nano /boot/config.txt
```
Dodaj następujące linie na końcu pliku:
```
dtparam=i2c_baudrate=75000
core_freq=250
```
Zapisz i zamknij naciskając Ctrl+X.

Zainstaluj RotorHazard w '/home/pi/' na Raspberry Pi następujący sposób:
Idź do strony [Latest Release page](https://github.com/RotorHazard/RotorHazard/releases/latest)

„Ostatnie wydania” i zobacz jaka jest aktualna wersja kodu. W komendach poniżej zastąp znaki "1.2.3" aktualną wersję kodu i wpisz następujące komendy:
```
cd ~
wget https://codeload.github.com/RotorHazard/RotorHazard/zip/1.2.3 -O temp.zip
unzip temp.zip
mv RotorHazard-1.2.3 RotorHazard
rm temp.zip
```
Zainstaluj tak zwane „zależności” serwera RotorHazard - bądź cierpliwy może zająć to kilka minut:
```
cd ~/RotorHazard/src/server
sudo pip install -r requirements.txt
```
Zmień ustawienia dostępu dla folderu:
```
cd ~/RotorHazard/src
sudo chmod 777 server
```
Uwaga: jeśli RotorHazard jest już zainstalowany, zobacz w sekcji poniżej[uaktualnianie obecnej instalacji](#update).

## Zainstaluj kod dla odnóg Arduino
Wymagane jest Arduino w wersji minimum 1.8. Ściągnij z:
https://www.arduino.cc/en/Main/Software

*Wersja oprogramowania dla odnóg oraz serwera muszą do siebie pasować. Użyj kodu przygotowanego dla odnóg z tego samego folderu, z którego instalujesz serwer. Nie ściągaj innych plików bezpośrednio z GitHub.*

Kod dla odnóg może być edytowany i przygotowany używając [Eclipse IDE](https://www.eclipse.org/eclipseide/) i "[Eclipse C++ IDE dla Arduino](https://marketplace.eclipse.org/content/eclipse-c-ide-arduino)" (albo “po-staremu” używając Arduino IDE). W Eclipse projekt zawierający kod dla odnóg może być otwarty poprzez „Plik”, „Otwórz projekt z pliku systemowego…”

Edytuj plik 'src/node/config.h' i skonfiguruj wartość '#define NODE_NUMBER' dla każdej odnogi przed uaktualnieniem. Dla pierwszej odnogi ustaw NODE_NUMBER jako 1, dla drugiej ustaw jako 2, itd.
```
// Node Setup -- Set node number here (1 - 8)
#define NODE_NUMBER 1
```
Automatyczne numerowanie sprzętowe, również jest możliwe. Ustaw NODE_NUMBER jako 0, następnie połącz następujące piny z masą:

node #1: pin D5 podłączony do masy<br/>
node #2: pin D6 podłączony do masy<br/>
node #3: pin D7 podłączony do masy<br/>
node #4: pin D8 podłączony do masy<br/>
node #5: pin D5 i pin D4 podłączone do masy<br/>
node #6: pin D6 i pin D4 podłączone do masy<br/>
node #7: pin D7 i pin D4 podłączone do masy<br/>
node #8: pin D8 i pin D4 podłączone do masy

## Zainstaluj Opcjonalne Składniki
### Wsparcie dla LEDów WS2812b
Kontrola nad WS2812b jest dostarczona przez następujący projekt:
https://github.com/jgarff/rpi_ws281x

Sklonuj repozytorium na Pi i zainicjuj Scons:
```
cd ~
sudo git clone https://github.com/jgarff/rpi_ws281x.git
cd rpi_ws281x
sudo scons
```

Zainstaluj bibliotekę Python:
```
cd python
sudo python setup.py install
```

### Wsparcie dla miernika Napięcia/Natężenia INA219
Interfejs INA219 jest dostarczony przez następujący projekt:
https://github.com/chrisb2/pi_ina219

Sklonuj repozytorium na Pi:
```
cd ~
sudo git clone https://github.com/chrisb2/pi_ina219.git
cd pi_ina219
```
Zainstaluj bibliotekę Python:
```
sudo python setup.py install
```

### Wsparcie dla czujnika temperatury BME280
Interfejs BME280 jest dostarczony przez następujący projekt: https://github.com/rm-hull/bme280

Sklonuj repozytorium na Pi:
```
cd ~
sudo git clone https://github.com/rm-hull/bme280.git
cd bme280
```
Zainstaluj bibliotekę Python:
```
sudo python setup.py install
```

### Java Support
Java umożliwia kalkulację oceny zniekształceń intermodulacyjnych „IMD score”. Jeśli zainstalowałeś w kroku pierrwszym “RASPBIAN WITH DESKTOP”, ten krok nie powinien być konieczny. W innym wypadku:
```
sudo apt install default-jdk-headless
```

## Przygotuj System
### Zrestartuj System
Po tym jak powyższe kroki zostaną przeprowadzone system powinien być zrestartowany poprzez następujące komendy:
```
sudo reboot
```

### Uruchom System
Następujące instrukcje włączą serwer web na Raspberry Pi, umożliwiając pełną kontrolę oraz konfigurację systemu, aby móc przeprowadzać wyścigi i zapisywać czasy okrążeń.

#### Manualny Start
Otwórz okno terminal i wpisz:
```
cd ~/RotorHazard/src/server
python server.py
```
Serwer może być zatrzymany poprzez wciśnięcie Ctrl+C

#### Uruchamianie podczas rozruchu
Stwórz usługę
```
sudo nano /lib/systemd/system/rotorhazard.service
```
Z następującą zawartością:
```
[Unit]
Description=RotorHazard Server
After=multi-user.target

[Service]
WorkingDirectory=/home/pi/RotorHazard/src/server
ExecStart=/usr/bin/python server.py

[Install]
WantedBy=multi-user.target
```
Zapisz i wyjdź (CTRL+X, Y, ENTER).

Zaktualizuj ustawienia dostępu.
```
sudo chmod 644 /lib/systemd/system/rotorhazard.service
```

Komendy uruchamiania podczas rozruchu:
```
sudo systemctl daemon-reload
sudo systemctl enable rotorhazard.service
sudo reboot
```

### Wyłączanie Systemu
System powinien zawsze być prawidłowo wyłączony przed odłączeniem zasilania – poprzez wciśnięcie przycisku w Ustawieniach lub poprzez wpisanie następującej komendy:
```
sudo shutdown now
```

### Uaktualnianie obecnej instalacji

Przed uaktualnieniem, wszystkie obecnie uruchomione serwery powinny być zatrzymane. Jeśli serwer jest zainstalowany jako usługa, może być zatrzymany przez wpisanie komendy: `sudo systemctl stop rotorhazard`

Aby uaktualnić obecną instalację RotorHazard: Idź do [Latest Release page](https://github.com/RotorHazard/RotorHazard/releases/latest) „Ostatnie wydania” i zobacz jaka jest aktualna wersja kodu. W komendach poniżej zastąp znaki "1.2.3" aktualną wersję kodu i wpisz następujące komendy:
```
cd ~
wget https://codeload.github.com/RotorHazard/RotorHazard/zip/1.2.3 -O temp.zip
unzip temp.zip
mv RotorHazard RotorHazard.old
mv RotorHazard-1.2.3 RotorHazard
rm temp.zip
cp RotorHazard.old/src/server/config.json RotorHazard/src/server/
cp RotorHazard.old/src/server/database.db RotorHazard/src/server/
```
Poprzednia instalacja znajdzie się w folderze 'RotorHazard.old', który może zostać usunięty lub przeniesiony.

„Zależności” RotorHazard również powinny być uaktualnione – bądź cierpliwy – może to zająć kilka minut:
```
cd ~/RotorHazard/src/server
sudo pip install --upgrade --no-cache-dir -r requirements.txt
```
<br/>

-----------------------------

### Pozostałe Systemy Operacyjne

Serwer RotorHazard może być uruchomiony na każdym komputerze obsługującym python. W tych alternatywnych konfiguracjach, jedna albo więcej odnóg może być podłączona przez USB – zobacz [doc/USB Nodes.md](USB%20Nodes.md) aby uzyskać więcej informacji. Serwer może również być włączony używając “wirtualnych” (sztucznych) odnóg.

Aby zainstalować serwer RotorHazard na tych systemach:

1. Jeśli komputer nie posiada zainstalowanego Python’a w wersji 2.7 zainstaluj go z https://www.python.org/downloads. Żeby sprawdzić czy Python jest zainstalowany, otwórz wiersz poleceń i wpisz ```python --version```

2. Z RotorHazard [Releases page on github](https://github.com/RotorHazard/RotorHazard/releases), ściągnij plik "Source code (zip)".

3. Rozpakuj ściągnięty plik w folderze, na komputerze.

4. Otwórz wiersz poleceń i nawiguj do pliku ```src/server``` w plikach RotorHazard (używając komend 'cd’).

5. Zainstaluj “zależności” serwera RotorHazard używając pliku 'requirements.txt'. Na systemie Windows komenda jakiej prawdopodobnie będziesz musiał użyć to: ```python -m pip install -r requirements.txt```<br/>
Zwróć uwagę, że ta komenda może wymagać uprawnień administratora i jej wykonanie może zająć kilka minut.

Aby uruchomić serwer RotorHazard na tych systemach:

1. Otwórz wiersz poleceń i nawiguj do pliku ```src/server``` w plikach RotorHazard (chyba, że już się tam znajdujesz).

2. Wpisz: ```python server.py```

3. Jeśli serwer uruchomił się prawidłowo, powinieneś zobaczyć wiersz log’ów, np:
    ```
    Running http server at port 5000
    ```

4. Serwer może być zatrzymany poprzez naciśnięcie Ctrl+C

Jeśli odnogi są podłączone poprzez USB, muszą zostać skonfigurowane w sekcji "SERIAL_PORTS" w pliku konfiguracyjnym "src/server/config.json" (zobacz [doc/USB Nodes.md](USB%20Nodes.md) aby uzyskać szczegółowe informacje).

Jeśli żadna odnoga sprzętowa nie jest skonfigurowana, serwer będzie operował używając symulowanych – sztucznych – odnóg. w tym trybie interfejs web może byś testowany i eksplorowany.

Aby obejrzeć interfejs web, otwórz przeglądarkę internetową i wpisz w pole adresu: ```localhost:5000``` (jeśli HTTP_PORT w konfiguracji został zmieniony, wpisz wybraną wartość zamiast 5000). Jeśli serwer uruchomiony, wtedy strona główna RotorHazard powinna się pojawić. Zwróć uwagę że strony przynależne do zarządzającego zawodami (Admin/Settings) są chronione hasłem z nazwą użytkownika i hasłem ustalonymi w pliku konfiguracyjnym.
<br/>

-----------------------------

Zobacz również:<br/>
[doc/Hardware Setup.md](Hardware%20Setup.md)<br/>
[doc/USB Nodes.md](USB%20Nodes.md)<br/>
[doc/User Guide.md](User%20Guide.md)

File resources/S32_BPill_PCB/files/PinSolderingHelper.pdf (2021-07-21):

Pin Soldering Helper

When solder single or even dual pin headers onto a PCB it can be difficult or frustrating to get them straight without burning yourself. Here is how to make a simple helper to make the process a lit bit easier.

First, start with a 3- or 4-pin high-profile socket and cut its pins off flush so that it can sit flat:

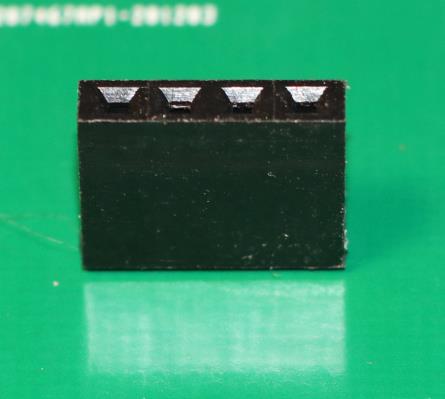
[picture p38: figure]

Then take two single pins and insert them into the socket. You can see from the photo that these were broken off of a longer header pin strip:

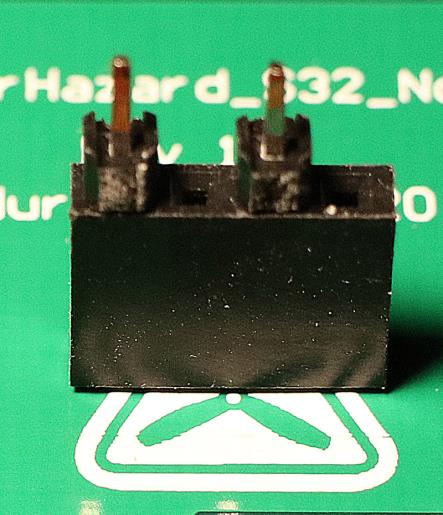
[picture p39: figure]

Then cut off the tails of the pins flush and push the pins down so they are completely below the plastic surround:

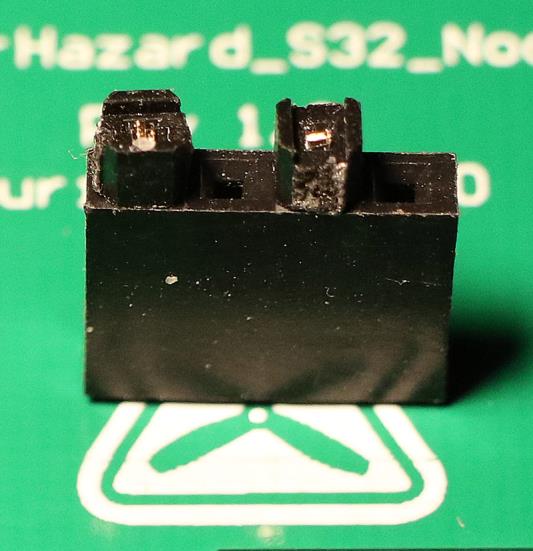
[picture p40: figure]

Insert the pin to be soldered between the other two pins and you now have a nice holder that will make it easier to hold the single pin for soldering without burning your fingers:

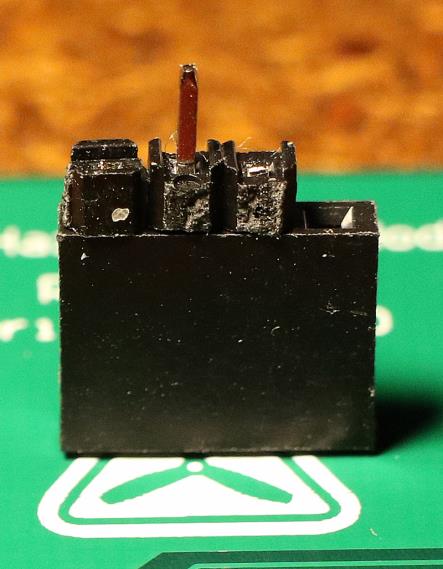
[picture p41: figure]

It will also make it easier to hold the pin vertical in the first place. This helper can also make it easier to hold 2-pin (or more) headers perpendicular to the PCB while soldering:

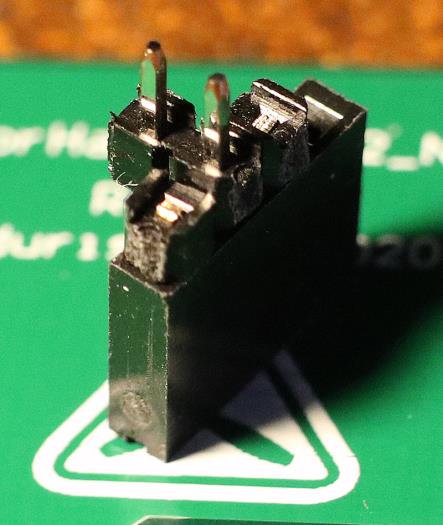
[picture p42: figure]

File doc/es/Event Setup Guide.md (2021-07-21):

# Gía de configuración de Evento

Los conceptos básicos de la configuración de un evento son la configuración de pilotos, series y nodos. También puede agregar detalles del evento y clases de carrera si lo desea.

## Borrar datos existentes (si fuese necesario)
Desde Configuración, abrir Base de datos. Usar entre las opciones disponibles para borrar los datos que sean obsoletos.

## Añadir Detalles al Evento (opcional)
Desde Configuración, abra el panel Evento. Actualice el nombre y la descripción del evento. Estos se mostrarán en la página de inicio cuando los usuarios visiten el RotorHazard por primera vez. Aquí puede informar a los pilotos qué pueden esperar del evento, como cuál será el formato o el horario.

## Añadir Pilotos
Desde Configuración, abra el panel Pilotos. Agregue una entrada para cada piloto que participe. El nombre del piloto se mostrará en la página del evento; Callsign (alias) se usará para mostrar los resultados de la carrera y las llamadas de voz. Prueba la pronunciación de la voz con el botón ">". Si lo desea, escriba una ortografía fonética para los nombres que no suenen igual. Esto nunca se mostrará, pero se usa para pronunciar el nombre.

## Crear Formatos de Carrera (opcional)
Desde Configuración, abrir Formato de Carreras. [Adjust the settings](User%20Guide.md#race-format) o crear nuevos formatos para que coincidan con el tipo de puesta en escena de inicio de su grupo, la condición de victoria, etc.

## Añadir Series y Clases
**Series** son pilotos que vuelan juntos exactamente al mismo tiempo. Asigne un nombre a su serie o deje el nombre vacío para usar un nombre predeterminado. Seleccione qué pilotos volarán exactamente al mismo tiempo y agréguelos a una casilla de la serie. El número de casillas de serie disponibles está determinado por el número de nodos conectados al temporizador. Use "Ninguno" para las casillas de la serie no utilizadas.

**Clases** son grupos de pilotos con características compartidas. Cree clases basadas en cómo está estructurado su evento, si necesita más de una clase. Nombre su clase para referencia en otro lugar. La descripción de la clase es visible en la página del evento. Establecer un formato opcional obliga a todas las carreras dentro de esa clase a usar la configuración de Formato de Carrera seleccionado.

Asigne series a las clases para usarlos. Cuando una carrera se guarda para una serie con una clase asignada, los resultados de la clase se calcularán por separado y aparecerán como su propia sección en los resultados de la carrera.

## Sintonizar los Nodos al Entorno
Una vez que el temporizador esté funcionando en el lugar de la carrera, ajuste el [node parameters and filtering settings](Tuning%20Parameters.md) para que coincida mejor con el tipo de carrera deseado. Opcionalmente, cree un perfil para esta ubicación para que pueda cargarlo fácilmente más tarde.

## Ejemplo
8 pilotos se reunirán para una carrera de micro quad en interiores. El formato del evento es de cinco rondas clasificatorias que suman el recuento total de vueltas con los cuatro mejores pilotos avanzando a una única serie final. Antes del evento, el organizador agrega todos los pilotos en el panel Pilotos. Se crean dos clases, "Calificación" y "Final", y a ambas clases se les asigna el formato de carrera "Whoop Sprint". Se crean dos series con cuatro pilotos cada una, y ambas series se asignan a la clase "Calificación".

El día del evento, el organizador selecciona el perfil "Interior" para establecer las frecuencias deseadas y la configuración de filtrado y se asegura de que los nodos estén sintonizados correctamente. Desde la página Carrera, las eliminatorias se ejecutan cinco veces cada una. El temporizador organiza estas carreras en rondas 1 a 5 para la página de resultados a medida que se ejecutan las carreras.

Una vez que terminan las eliminatorias clasificatorias, el organizador revisa la página de resultados y revisa la clase "Calificación" para determinar los mejores pilotos. El organizador abre la página Configuración y el panel Calienta, crea un nuevo calor y asigna los cuatro mejores pilotos en él, luego asigna la clase "Final" al calor. La carrera por este último calor se corre. En la página de resultados, la clase "Final" contiene los resultados de la final y los muestra por separado de los demás.

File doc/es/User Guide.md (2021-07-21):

# RotorHazard Race Timer - Guía de Usuario

## Configuración Inicial

### Configuración de HARDWARE y SOFTWARE
Siga las siguientes instrucciones si aún no lo ha hecho:
[doc/Hardware Setup.md](Hardware%20Setup.md)
[doc/Software Setup.md](Software%20Setup.md)

### Configurar archivo de configuración
En el directorio "src/server", busque *config-dist.json* y cópielo en *config.json*. Edite este archivo y modifique los valores HTTP_PORT, ADMIN_USERNAME y ADMIN_PASSWORD. Python requiere estrictamente que este archivo sea JSON válido. Una utilidad linter como [JSONLint](https://jsonlint.com/) puede ayudarle a revisar errores de síntesis.

HTTP_PORT es el valor del puerto en el que se ejecutará el servidor. De manera predeterminada, HTTP usa el puerto 80. Otros valores requerirán que el puerto se incluya como parte de la URL ingresada en los navegadores del cliente. Si otros servicios web se están ejecutando en la Pi, el puerto 80 puede estar en uso y el servidor no podrá iniciarse. Si se usa el puerto 80, el servidor puede necesitar ejecutarse usando el comando *sudo*. El puerto 5000 debería estar disponible. Algunas versiones de LiveTime solo se conectarán a un servidor en el puerto 5000.

ADMIN_USERNAME y ADMIN_PASSWORD son las credenciales de inicio de sesión que se necesitarán para realizar cambios en el apartado de configuración.

### Conectarse al servidor
Se puede usar una computadora, teléfono o tableta para interactuar con el crono iniciando un navegador web e ingresando la dirección IP de Raspberry Pi. La Raspberry Pi puede conectarse mediante un cable de ethernet o una red WiFi disponible. Si no se conoce la dirección IP de Pi, se puede ver con el comando de terminal "ifconfig" y se puede configurar con un valor estático en el escritorio de Pi a través de "Preferencias de red". Si el Pi está conectado a una red WiFi, su dirección IP se puede encontrar en la lista 'Clientes' en la página de administración del enrutador de la red.

En el navegador web, escriba la dirección IP del crono y el valor del puerto que configuró en el archivo de config.json (o deje el puerto: si está configurado en 80).

```
XXX.XXX.XXX.XXX:5000
```

Una vez que la página se muestre con éxito, se puede marcar en el navegador. Las páginas reservadas para el director de carrera ("Admin/Configuración") están protegidas con contraseña con el nombre de usuario y la contraseña especificados en el archivo de config.json

## Pages

### Home

Esta página muestra el nombre y la descripción del evento, junto con un conjunto de botones para otras páginas.

### Evento

Esta es una página pública que muestra la configuración de clase actual (si corresponde) y un resumen de los pilotos y sus series con asignación de canales.

### Resultados

Esta página pública mostrará resultados y estadísticas calculadas de todas las carreras guardadas anteriormente, organizadas en paneles desplegables. Los resultados agregados se muestran para cada serie con múltiples rondas, cada clase y el evento completo.

### Espectador

Esta página muestra información sobre la carrera actual, incluido el tiempo de carrera en tiempo real, los tiempos de vuelta de los pilotos y la tabla de clasificación. Se actualiza automáticamente con el evento y es adecuado para proyectar en una pantalla de visualización destacada.

En la sección Control de audio, el usuario puede seleccionar si se anuncia por voz a un piloto, todos los pilotos o ningún piloto. De esta manera, un piloto podría elegir escuchar solo sus propias vueltas anunciadas. El usuario también puede ajustar la voz, el volumen, la velocidad y el tono de estos anuncios.

### Configuración

Esta página permite cambiar la configuración opcional del crono y la configuración de eventos.

#### Configuración de frecuencias
Elija un preajuste o seleccione manualmente las frecuencias para cada nodo. La selección de frecuencias arbitrarias es posible, igual que deshabilitar un nodo. Actualmente se calcula y se muestra en la parte inferior del panel la puntuación IMD para las frecuencias seleccionadas. 

Los perfiles contienen frecuencias y valores de ajuste de nodos. Cambiar esta lista activa inmediatamente el perfil seleccionado, y cambiar las frecuencias actuales y la sintonización de nodos se guarda inmediatamente en el perfil.

#### Ajuste del sensor
Vea [doc/Tuning Parameters.md](Tuning%20Parameters.md) para una descripción detallada sobre la sintonización y calibrado de los nodos.

#### Evento y Clases
La información del evento se muestra en la página de inicio cuando los usuarios se conectan por primera vez al sistema.

No se requieren clases para eventos; no es necesario crear una clase a menos que tenga dos o más en el evento. Las clases se pueden usar para tener estadísticas generadas por separado para grupos de series. Por ejemplo, clasificatorias Open y Spec, o clasificatorias Principiante/Pro.

#### Series
Agregue series hasta que haya suficientes para todas las carreras y pilotos. Se pueden agregar nombres de serie opcionales si se desea. Las ranuras dentro de la serie se pueden establecer en *Ninguno* si no se asigna ningún piloto allí.

Si está usando clases, asigne cada serie a una clase. Asegúrese de agregar suficientes series para cada piloto en cada clase; las series asignadas a una clase no están disponibles en otra.

A medida que lance carreras, las clases (clasificatorias) se bloquearán y no podrán modificarse. Esto protege los datos de carrera guardados para que sean válidos. Para modificar las series nuevamente, abra el panel *Base de datos* y borre las carreras.

#### Pilotos
Agregue una entrada para cada piloto que competirá. El sistema anunciará pilotos en función de su indicativo "callsing". Se puede usar una ortografía fonética para un "callsing" para influir en cómo se oirá el nombre; aunque es opcional.

#### Control de audio
Todos los controles de audio son locales para el navegador y el dispositivo donde los configuró, incluida la lista de idiomas, volúmenes disponibles y qué anuncios o indicadores están en uso.
La selección de voz elige el motor de texto a voz. Las selecciones disponibles serán proporcionadas por el navegador web y el sistema operativo.

Los anuncios permiten al usuario elegir escuchar el indicativo, el número de vuelta y/o el tiempo de vuelta de cada piloto al cruzar. El anuncio del "Tiempo de carrera" indicará periódicamente cuánto tiempo ha transcurrido o queda, según el modo de temporizador en el formato de carrera. "Tiempo de Vuelta de Equipo" se usa solo cuando el "Modo de Carrera por Equipos" está habilitado.

El volumen de voz, la velocidad y el tono controlan todos los anuncios de texto a voz. "Volumen de tono" controla las señales de inicio y finalización de la carrera.

Los pitidos de los indicadores son tonos muy cortos que proporcionan información sobre cómo funciona el temporizador, y son más útiles cuando se trata de sintonizarlo. Cada nodo se identifica con un tono de audio único. "Cruce entrado" emitirá un pitido cuando comience un pase y "Cruce salido" emitirá dos pitidos rápidamente cuando se complete un pase. El "Botón de vuelta manual" emitirá un pitido si se usa el botón "Manual" para forzar un pase simulado.

#### Formato de carrera
Los formatos de carrera recopilan configuraciones que definen cómo se lleva a cabo una carrera. Elige un formato de carrera activo. La configuración que ajuste aquí se guardará en el formato actualmente activo.

El modo de temporizador puede contar hacia arriba o hacia atrás. Use "Cuenta Ascendente" para un estilo heads-up, "primero en X vueltas". Use "Cuenta Atrás" para un formato de tiempo fijo. La duración del temporizador solo se usa en el modo "Count Down".

El modo de temporizador de etapas afecta si la visualización del tiempo será visible antes de una carrera. "Mostrar cuenta regresiva" mostrará el tiempo hasta la señal de inicio de la carrera; "Ocultar cuenta regresiva" mostrará "Listo" hasta que comience la carrera.

El Retardo de inicio mínimo y máximo ajusta cuántos segundos dura el cronómetro de etapas (antes de la carrera). Ajústelos al mismo número durante un tiempo de contado fijo, o a números diferentes para un tiempo aleatorio dentro de este rango.

El tiempo mínimo de vuelta y el modo de carrera en equipo no se almacenan con el formato de carrera.

El tiempo mínimo de vuelta descarta automáticamente los pases que hubieran registrado vueltas menores a la duración especificada. Úselo con precaución, ya que esto podría descartar datos que podrían haber sido válidos.

#### Efectos LED
Elija un efecto visual para cada evento del temporizador. El temporizador mostrará este efecto cuando ocurra el evento, anulando inmediatamente cualquier visualización o efecto existente. Algunos efectos visuales solo están disponibles en eventos de temporizador particulares. El evento modifica algunos efectos visuales, en particular el color del cruce de la puerta que entra/sale. La mayoría de los efectos se pueden previsualizar a través del panel de control LED.

Algunos efectos de LED pueden retrasarse un poco si el temporizador está ocupado con tareas críticas. (Otros, como el inicio de la carrera, nunca se retrasan). Debido a este efecto y los cruces potencialmente concurrentes, _"Desactivar"_ generalmente debe evitarse para las salidas de la puerta. En su lugar, use _"Sin cambio"_ en la entrada de la puerta y el efecto deseado en la salida de la puerta.

_Esta sección no aparecerá si su crono no tiene LED configurados. Aparece un aviso en el registro de inicio._

#### Control LED
Esta sección anulará la pantalla LED actual. Elija apagar temporalmente la pantalla, mostrar algunos colores preconfigurados, mostrar cualquier color personalizado o mostrar un efecto definido. También puede usar el control deslizante para ajustar el brillo de su panel. La configuración ideal para cámaras FPV es donde el panel iluminado coincide con el brillo de un objeto blanco. Esto coloca la salida del panel dentro del rango dinámico de lo que la cámara puede capturar. Sin embargo, el uso de un ajuste de brillo bajo distorsiona la reproducción del color y la suavidad de las transiciones de color.

_Esta sección no aparecerá si su temporizador no tiene LED configurados. Aparece un aviso en el registro de inicio._

#### Base de datos
Elija hacer una copia de seguridad de la base de datos actual (guardar en un archivo en el pi y solicitar que se descargue) o borrar datos. Puede borrar carreras, clases, series y pilotos.

#### Sistema
Elija el idioma de la interfaz y cambie los parámetros que afectan la apariencia del temporizador, como su nombre y combinación de colores. También puede apagar i reiniciar el servidor desde aquí.

### Carrera

Esta página te permite controlar el crono y correr carreras.

Seleccione la Serie para la carrera que se ejecutará a continuación.

Comienza la carrera cuando estés listo. (Hotkey: <kbd>z</kbd>) El temporizador hará una comunicación rápida con el servidor para compensar el tiempo de respuesta del cliente / servidor, luego comenzará el procedimiento de clasificación definido por el formato de carrera actual.

Los parámetros de ajuste se pueden ajustar aquí mediante el botón "⚠". Ver [doc/Tuning Parameters.md](Tuning%20Parameters.md) para una descripción detallada y guía de ajuste.

Durante la carrera, hay una "×" al lado de cada vuelta contada. Esto descartará ese pase de vuelta, por lo que su tiempo se moverá a la siguiente vuelta. Use esto para eliminar pases extra erróneas, o limpiar a los pilotos que vuelan cerca de la puerta de inicio después de que termine su carrera.

Se proporciona un botón "+ Vuelta" para forzar el paso de vuelta para que ese nodo se registre inmediatamente.

Cuando termine una carrera, use el botón "Detener carrera" (Hotkey: <kbd>x</kbd>) para dejar de contar vueltas. Debe hacerlo incluso si el temporizador llega a cero en un formato de "Cuenta atrás"; un formato de carrera popular permite a los pilotos terminar la vuelta en la que se encuentran cuando expira el tiempo. Para obtener los mejores resultados, despeje la puerta de sincronización y permita que finalicen todos los cruces válidos antes de detener la carrera.

Una vez que finaliza una carrera, debes elegir "Guardar vueltas" o "Borrar vueltas" antes de comenzar otra carrera. "Guardar vueltas" (Hotkey: <kbd>c</kbd>) almacenará los resultados de la carrera en la base de datos y los mostrará en la página "Resultados". "Descartar Vueltas" (Hotkey: <kbd>v</kbd>) descartará los resultados de la carrera. Guardar vueltas avanzará automáticamente la selección de la serie a la siguiente con la misma clase que la carrera guardada.

El panel Gestión de Carrera proporciona acceso rápido para cambiar el formato de carrera actual, el perfil, el tiempo mínimo de vuelta o el modo Team Racing. _Audio Control_ y _LED Control_ son igules que en la página Configuración. La Exportación del Historial crea un archivo CSV para descargar los valores RSSI registrados en la carrera completada más recientemente. "Tiempo hasta el inicio de la carrera" programará una carrera que se ejecutará en un momento futuro. Los operadores pueden usar esto para establecer un límite estricto en la cantidad de tiempo permitido para que los pilotos se preparen, o para iniciar el crono y luego participar en la carrera ellos mismos.

### Mariscal

Ajusta los resultados de las carreras guardadas.

Seleccione la serie, la ronda y el piloto a ajustar. Los puntos de entrada y salida se cargan automáticamente a partir de los datos de carrera guardados. Ajuste los puntos de entrada y salida para recalibrar la carrera. "Cargar desde el nodo" para cargar los datos guardados actualmente en el nodo y que se muestren en el gráfico. "Guardar en nodo" para copiar los valores ajustados en el gráfico al nodo. "Recalcular carrera" para usar los valores activos de entrada/salida como puntos de calibrado para una "repetición" de la carrera. Esto borrará las vueltas actuales y las reemplazará con la información recalculada. Las vueltas introducidas manualmente se conservarán.

Agregue vueltas ingresando el tiempo de cruce en segundos desde el comienzo de la carrera, luego presione el botón "Agregar vuelta".

Elimine las vueltas con el botón "×" en la vuelta no deseada. Las vueltas eliminadas se eliminan de los cálculos, pero permanecen presentes en los datos para referencia posterior. "Borrar vueltas" para eliminar permanentemente los datos de la base de datos.

Puede hacer clic/tocar el gráfico para establecer los puntos de entrada/salida, activar el recálculo y resaltar vueltas específicas. Al hacer clic en las vueltas de la lista también se resalta el gráfico. Presione <kbd>borrar</kbd> o <kbd>x</kbd> para borrar una vuelta resaltada. Las vueltas activas se muestran en verde, y las vueltas eliminadas cambian a rojo. El ancho del indicador de vuelta muestra los puntos de entrada/salida, y el resaltado amarillo dibuja una línea en el tiempo exacto de vuelta dentro de esa ventana.

"Realizar Cambios" cuando haya terminado de ajustar los datos de la carrera para guardarlos en la base de datos y actualizar los resultados de la carrera.

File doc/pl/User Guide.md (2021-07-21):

# RotorHazard Race Timer - Instrukcja Użytkownika

## Wstępna Konfiguracja

###  Ustawienia Sprzętu i Oprogramowania
Postępuj zgodnie z instrukcja podanymi poniżej, jeśli jeszcze tego nie zrobiłeś:
[doc/Hardware Setup.md](Hardware%20Setup.md)
[doc/Software Setup.md](Software%20Setup.md)

###  Ustaw Plik Konfiguracyjny
W folderze "src/server" znajdź plik *config-dist.json* skopiuj go jako *config.json*.  Edytuj plik modyfikując wartości: HTTP_PORT,  ADMIN_USERNAME, and ADMIN_PASSWORD. Python szczególnie zwraca uwagę, żeby ten plik był ważnym plikiem JSON. Narzędzie linter i podobne [JSONLint](https://jsonlint.com/) może być użyte żeby sprawdzić poprawność składni.

HTTP_PORT jest portem, na którym serwer będzie włączony. Domyślnie, HTTP używa portu 80. Inne wartości wymagają, żeby port zawierał się jako część adresu wpisanego w przeglądarkę klienta. Jeśli inne usługi sieciowe chodzą już na Pi, port 80 może być już w użyciu i serwer nie będzie mógł wystartować. Jeśli port 80 jest używany, serwer może wymagać użycia komendy *sudo*. Port 5000 powinien być dostępny. Niektóre wersje LiveTime będą mogły się połączyć z serwerem tylko na porcie 5000.

ADMIN_USERNAME i ADMIN_PASSWORD są danymi do logowania, potrzebnymi aby zmieniać ustawienia.

### Połączenie z Serwerem
Komputer, telefon albo tablet może być użyty do interakcji z timerem, przez włączenie strony internetowej i wpisanie adresu IP należącego do Raspberry Pi. Raspberry Pi może być podłączone używając kabla Ethernet albo do dostępnej sieci WiFi. Jeżeli adres IP Raspberry jest nieznany może być sprawdzony poprzez wpisanie w wierszu poleceń komendy "ifconfig". Może być też skonfigurowany jako statyczny adres IP w preferencjach sieciowych, w wersji desktop systemu. Jeśli jest połączony z siecią WiFi, jego adres IP może być sprawdzony na liście "klientów", ma stronie konfiguracyjnej routera.

W przeglądarce sieciowej, wpisz adres IP timera i port ustawiony w pliku konfiguracyjnym albo zostaw port nie-wpisany jeśli jest ustawiony na 80.

```
XXX.XXX.XXX.XXX:5000
```

Kiedy strona zostanie wyświetlana, może być dodana do zakładek w przeglądarce. Strony zarezerwowane dla zarządzającego zawodami ("Admin/Settings") - ustawienia - są zabezpieczone hasłem. Nazwa użytkownika i hasłem ustawione są w pliku konfiguracyjnym.

## Strony

### Domowa

Ta strona wyświetla nazwę wydarzenia i opis oraz zestaw przycisków przełączających do innych stron.

### Wydarzenie

To strona ogólnodostępna wyświetlająca aktualne ustawienia klasy - jeśli dostępne - i podsumowanie pilotów oraz ich biegu i ustawień kanału.

### Wyniki

To strona ogólnodostępna wyświetlająca wyniki i obliczone statystyki wszystkich zapisanych wyścigów, zorganizowane jako zwijający się panel. Zgromadzone rezultaty, są wyświetlane dla każdego biegu z wieloma rundami dla każdej klasy i dla całego wydarzenia.

### Aktualny

Ta strona wyświetla informacje o aktualnie trwającym wyścigu, zawiera czas wyścigu podany na żywo, czasy poszczególnych Pilotów i ich wyniki. Automatycznie uaktualnia się wraz z wydarzeniem jest przystosowana do wyświetlania na ogólno-dostepnym, dużym ekranie.

W sekcja Kontroli Audio, użytkownik może wybrać czy chce słuchać komunikatów dotyczących wszystkich, żadnego czy poszczególnych pilotów oraz ich okrążeń i czasów. W ten sposób pilot może przystosować się i słuchać tylko swoich czasów i okrążeń. Użytkownik może również ustawić głos, głośność, język oraz mowę komunikatów głosowych.

### Ustawienia

Ta strona pozwala na zmianę opcjonalnych ustawienie timera i wydarzenia.

#### Ustawienia Częstotliwości

Wybierz przygotowane ustawienie albo osobiście wybierz częstotliwości dla każdej od odnogi. Odgórne przypisanie częstotliwości jest możliwe, tak samo jak wyłączenie poszczególnych odnóg. Wynik IMD dla aktualnie wybranych częstotliwości jest obliczany i pokazany na dole panelu.

Profile zawierają częstotliwości i strojenia dla odnóg. Zmiana od razu aktywuje wybrany profil, zmienia aktualnie wybrane częstotliwości, a strojenie odnogi od razu zapisuje się do profilu.

#### Strojenie Czujników

Zobacz [doc/Tuning Parameters.md](Tuning%20Parameters.md) dla szczegółowych informacji, opisu i przewodnika po strojeniu.

#### Wydarzenia i Klasy

Informacje o wydarzeniu są wyświetlane na stronie głównej, kiedy użytkownik po raz pierwszy podłącza się do systemu.

Klasy nie są  wymagane, nie ma potrzeby tworzenia klas, chyba że masz dwie lub więcej klas w danym wydarzeniu. Klasy mogą być użyte, żeby generować oddzielne statystyki dla grupy kilku biegów. Na przykład klasa Open i Spec albo Początkujący i Pro-piloci.

#### Biegi

Dodaj biegi, aż będzie ich wystarczająco dużo, żeby wszyscy piloci mogli się ścigać. Opcjonalnie możesz nazwać bieg - jeśli chcesz. Wolne miejsca w biegach mogą być ustawione jako "None" jeśli żaden pilot nie jest przypisany.

Jeśli używasz Klas, przypisz każdy bieg do klasy. Upewnij się dodałeś odpowiednią ilość biegów dla każdego pilota, w każdej klasie. Biegi przypisane do jednej klasy, nie są dostępne w innej.

Kiedy przeprowadzasz wyścigi, biegi będą zablokowane i nie będą mogły być zmienione. To chroni zapisane wyścigi przed tym, żeby nie stały się nie ważne. Żeby zmienić biegi, otwórz panel "Baza Danych" i skasuj wyścigi.

#### Piloci

Dodaj wpis dla każdego pilota który będzie się ścigał. System będzie ogłaszał pilotów bazując na ich zapisanych znakach wywoławczych. Fonetyczna wymowa dla każdego znaku może być użyta, żeby dostosować komunikaty głosowe, nie jest to jednak wymagane.
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

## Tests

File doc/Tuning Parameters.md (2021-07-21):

# Calibration and Sensor Tuning Parameters

_If you are having trouble calibrating your timer, be sure you have constructed and placed [RF shielding](Shielding%20and%20Course%20Position.md) correctly._

Each node keeps track of the signal strength (RSSI) on a selected frequency and uses this relative strength to determine whether a transmitter is near the timing gate. The RotorHazard timing system allows you to calibrate each node individually so that you can compensate for the behavior and hardware differences across your system and environment.

A node can be *Crossing* or *Clear*. If a node is *Clear*, the system believes a transmitter is not near the timing gate because the RSSI is low. If it is *Crossing*, the system believes a transmitter is passing by the timing gate because the RSSI is high. A lap pass will be recorded once the *Crossing* is finished and the system returns to *Clear*.

Tuning Graph<br />
_RSSI during a race appears similar to this graph with many visible peaks and valleys. As the transmitter nears the timing gate, the signal rises._

## Parameters
Two parameters that affect the *Crossing* status: *EnterAt* and *ExitAt*.

### EnterAt
The system will switch to *Crossing* when RSSI raises to or above this level. It is indicated by a red line.

### ExitAt
The system will switch to *Clear* once the RSSI value drops below this level. It is indicated by an orange line.

In between *EnterAt* and *ExitAt*, the system will remain *Crossing* or *Clear* depending on its previous state.

Sample RSSI Graph

### Calibration Mode

*Manual* calibration mode will always use the *EnterAt* and *ExitAt* values provided by the user.

*Adaptive* calibration mode uses the user-defined points unless there are saved races. When saved races exist, changing heats will initiate a search of previous race data for the best calibration values to use in the upcoming race. These values are copied and replace the current *EnterAt* and *ExitAt* values for all nodes. This mode improves calibration as more races are saved if the race director confirms the incoming lap counts or recalculates them through the *Marshal* page.

### Start of Race EnterAt/ExitAt Lowering

At the beginning of a race there can be many quads going through the start gate at the same time, and this can result in lower RSSI values being detected on some of the nodes (which could result in an initial gate pass being missed). To try and account for this, the following settings may be configured:

*Start of race EnterAt/ExitAt lowering amount (percent):* Sets the amount that the EnterAt and ExitAt values for all nodes will be reduced, as a percentage. For instance, if 30 (percent) is configured, the EnterAt value will be lowered to a value that is 30% closer to the ExitAt value. (So if EnterAt=90 and ExitAt=80, the EnterAt value will be lowered to 87.) The ExitAt value will be also be lowered by the same amount.

*Start of race EnterAt/ExitAt lowering duration (seconds):* Sets the maximum amount of time (in seconds) that the EnterAt and ExitAt values will be lowered. If a gate crossing for a node is detected as completed before this time then the EnterAt and ExitAt values for that node will be restored then.

Suggested values are 30 (percent) and 10 (seconds). If either of these settings are configured as zero then the EnterAt and ExitAt values will not be lowered.

Note that on the *Marshal* page these settings are taken into consideration, so if they are non-zero then the first lap pass on a node may be detected even though the peak RSSI appears to be lower than the EnterAt level displayed.

## Tuning
Before tuning, power up the timer and keep it running for a few minutes to allow the receiver modules to warm up. The RSSI values tend to increase by a few points as the timer heats up.

You can use the *Marshal* page to tune values visually. Collect data by running a race with a pilot on each channel, then save it. Open the *Marshal* page and view the race data, adjusting Enter and Exit points until the number of laps is correct. Save the Enter/Exit points to each node to use as calibration for future races.

### Set the *EnterAt* value
Tuning Graph

* Below the peak of all gate crossings
* Above any peak when the transmitter is not near the gate
* Higher than *ExitAt*

### Set the *ExitAt* value
Tuning Graph

* Below any valleys that occur during a gate crossing
* Above the lowest value seen during any lap
* Lower than *EnterAt*

ExitAt values closer to EnterAt allow the timer to announce and display laps sooner, but can cause multiple laps to be recorded.

### Tuning Example
Tuning Graph<br />
_Two laps are recorded. The signal rises above *EnterAt* and then falls below *ExitAt* twice, once at each peak. Within these two crossing windows, the timer finds the strongest signal after noise filtering to use as the recorded lap time._

### Alternate Tuning Method

The *Capture* buttons may be used to store the current RSSI reading as the *EnterAt* or *ExitAt* value for each node. The values may also be entered and adjusted manually.

Power up a quad on the correct channel and bring it very close to the timer for a few seconds. This will allow the timer to capture the peak RSSI value for that node. This should be done for each node/channel that is being tuned. The peak value will be displayed.

#### EnterAt
A good starting point for *EnterAt* is to capture value with a quad about 1.5–3m (5–10 ft) away from the timer.

#### ExitAt
A good starting point for *ExitAt* is to capture the value with a quad about 6–9m (20–30 ft) away from the timer.

## Notes
* A low *ExitAt* value can still provide accurate timing, but the system will wait longer before announcing laps. A delay in announcing does not affect the accuracy of the timer.
* The *Minimum Lap Time* setting can be used to prevent extra passes, but might mask crossings that are triggered too early. It is recommended to leave the behavior at *Highlight* rather than *Discard*.
* If you experience timing issues during a race and the RSSI graphs are responding to transmitter location, do not stop the race. Save the race after it completes and visit the *Marshal* page. All RSSI history is saved and the race can be accurately recalculated with updated tuning values.

## Troubleshooting

### Missing Laps (System usually *Clear*)
Tuning Graph<br />
_Laps are not recorded if RSSI does not reach EnterAt._
* Lower *EnterAt*

### Missing Laps (System usually *Crossing*)
Tuning Graph<br />
_Laps are merged together if *ExitAt* is too low because the first lap crossing never completes._
* Raise *ExitAt*

### Laps register on other parts of a course
Tuning Graph<br />
_Extra crossings occur when *EnterAt* is too low._
* Raise *EnterAt* until *crossings* only begin near the timing gate. (Use the *Marshal* page after saving a race to determine and save the best values.)

### Many laps register at once
Tuning Graph<br />
_Too many laps occur when *ExitAt* is too close to *EnterAt* because laps exit too quickly._
* Raise *EnterAt*, if possible
* Lower *ExitAt*

The *Minimum Lap Time* setting always keeps the first crossing and disards subsequent laps that occur too soon. In this instance, this setting would discard the correct first crossing and keep the incorrect second crossing. It is recommended to leave the *Minimum Lap Time* behavior at *Highlight* rather than *Discard* so that a race organizer can manually review each case.

### Laps take a long time to register
Tuning Graph<br />
_Lap recording takes a long time to complete if *ExiAt* is low. This does not affect the accuracy of the recorded time._
* Raise *ExitAt*

### Node is never *crossing*
Tuning Graph<br />
_Laps will not register if RSSI never reaches *EnterAt*._
* Lower *EnterAt*

### Node is never *clear*
Tuning Graph<br />
_Laps will not complete if RSSI never drops below *ExitAt*._
* Raise *ExitAt*

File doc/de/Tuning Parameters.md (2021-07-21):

# Kalibrierungs- und Sensorabstimmungsparameter

_Wenn Sie Probleme beim Kalibrieren Ihres Timers haben, stellen Sie sicher, dass Sie die [HF-Abschirmung](Shielding%20and%20Course%20Position.md) korrekt konstruiert und platziert haben._

Jeder Knoten verfolgt die Signalstärke (RSSI) auf einer ausgewählten Frequenz und verwendet diese relative Stärke, um zu bestimmen, ob sich ein Sender in der Nähe des Timing-Gates befindet. Mit dem RotorHazard-Zeitmesssystem können Sie jeden Knoten einzeln kalibrieren, um das Verhalten und die Hardwareunterschiede zwischen System und Umgebung auszugleichen.

Ein Knoten kann *Crossing* oder *Clear* sein. Wenn ein Knoten *Clear* ist, glaubt das System, dass sich ein Sender nicht in der Nähe des Timing-Gates befindet, da der RSSI niedrig ist. Wenn es sich um *Crossing* handelt, geht das System davon aus, dass ein Sender am Timing Gate vorbeikommt, da der RSSI hoch ist. Ein Rundenpass wird aufgezeichnet, sobald die *Überfahrt* beendet ist und das System zu *Löschen* zurückkehrt.

Tuning Graph<br />
_RSSI während eines Rennens erscheint ähnlich wie diese Grafik mit vielen sichtbaren Gipfeln und Tälern. Wenn sich der Sender dem Timing-Gate nähert, steigt das Signal an._

## Parameter

Zwei Parameter, die sich auf den Status *Crossing* auswirken: *EnterAt* und *ExitAt*.

### EnterAt

Das System wechselt zu *Crossing*, wenn RSSI auf oder über dieses Niveau steigt. Es wird durch eine rote Linie angezeigt.

### ExitAt

Das System wechselt zu *Löschen*, sobald der RSSI-Wert unter diesen Wert fällt. Es wird durch eine orange Linie angezeigt.

Zwischen *EnterAt* und *ExitAt* bleibt das System je nach vorherigem Status *Crossing* oder *Clear*.

Sample RSSI Graph

### Kalibrierungsmodus

Der *manuelle* Kalibrierungsmodus verwendet immer die vom Benutzer angegebenen Werte *EnterAt* und *ExitAt*.

Der *adaptive* Kalibrierungsmodus verwendet die benutzerdefinierten Punkte, sofern keine Rennen gespeichert sind. Wenn gespeicherte Rennen vorhanden sind, wird durch Ändern der Vorläufe eine Suche in den vorherigen Renndaten nach den besten Kalibrierungswerten für das bevorstehende Rennen eingeleitet. Diese Werte werden kopiert und ersetzen die aktuellen Werte *EnterAt* und *ExitAt* für alle Knoten. Dieser Modus verbessert die Kalibrierung, da mehr Rennen gespeichert werden, wenn der Rennleiter die Anzahl der eingehenden Runden bestätigt oder sie über die Seite *Marschall* neu berechnet.

### Start des Rennens EnterAt/ExitAt Absenkung

Zu Beginn eines Rennens können viele Quads gleichzeitig durch das Starttor fahren, und dies kann dazu führen, dass auf einigen Knoten niedrigere RSSI-Werte erkannt werden (was dazu führen kann, dass ein anfänglicher Gate-Pass verpasst wird). Um dies zu berücksichtigen, können die folgenden Einstellungen konfiguriert werden:

*Start des Rennens EnterAt / ExitAt-Senkungsbetrag (Prozent):* Legt den Betrag fest, um den die EnterAt- und ExitAt-Werte für alle Knoten in Prozent reduziert werden. Wenn beispielsweise 30 (Prozent) konfiguriert ist, wird der EnterAt-Wert auf einen Wert gesenkt, der 30% näher am ExitAt-Wert liegt. (Wenn also EnterAt=90 und ExitAt=80 ist, wird der EnterAt-Wert auf 87 gesenkt.) Der ExitAt-Wert wird ebenfalls um denselben Betrag gesenkt.

*Startbeginn EnterAt / ExitAt-Absenkungsdauer (Sekunden):* Legt die maximale Zeitspanne (in Sekunden) fest, in der die EnterAt- und ExitAt-Werte gesenkt werden. Wenn eine Gate-Kreuzung für einen Knoten vor diesem Zeitpunkt als abgeschlossen erkannt wird, werden die EnterAt- und ExitAt-Werte für diesen Knoten wiederhergestellt.

Vorgeschlagene Werte sind 30 (Prozent) und 10 (Sekunden). Wenn eine dieser Einstellungen als Null konfiguriert ist, werden die EnterAt- und ExitAt-Werte nicht gesenkt.

Beachten Sie, dass auf der Seite *Marschall* diese Einstellungen berücksichtigt werden. Wenn sie also nicht Null sind, wird möglicherweise der erste Rundenpass auf einem Knoten erkannt, obwohl der maximale RSSI-Wert niedriger als der angezeigte EnterAt-Wert zu sein scheint.

## Tuning

Schalten Sie den Timer vor dem Einstellen ein und lassen Sie ihn einige Minuten laufen, damit sich die Empfängermodule erwärmen können. Die RSSI-Werte steigen in der Regel um einige Punkte an, wenn sich der Timer erwärmt.

Auf der Seite *Marschall* können Sie Werte visuell einstellen. Sammeln Sie Daten, indem Sie auf jedem Kanal ein Rennen mit einem Piloten durchführen, und speichern Sie sie dann. Öffnen Sie die Seite *Marschall* und zeigen Sie die Renndaten an. Passen Sie die Ein- und Ausstiegspunkte an, bis die Anzahl der Runden korrekt ist. Speichern Sie die Eingabe- / Ausstiegspunkte auf jedem Knoten, um sie als Kalibrierung für zukünftige Rennen zu verwenden.

### Stellen Sie den Wert *EnterAt* ein

Tuning Graph

* Unterhalb der Spitze aller Torübergänge
* Über jeder Spitze, wenn sich der Sender nicht in der Nähe des Gates befindet
* Höher als *ExitAt*

### Stellen Sie den Wert *ExitAt* ein

Tuning Graph

* Unterhalb von Tälern, die während einer Torüberquerung auftreten
* Über dem niedrigsten Wert, der während einer Runde gesehen wurde
* Niedriger als *EnterAt*

ExitAt-Werte, die näher an EnterAt liegen, ermöglichen es dem Timer, Runden früher anzukündigen und anzuzeigen, können jedoch dazu führen, dass mehrere Runden aufgezeichnet werden.

### Tuning Beispiel

Tuning Graph<br />
_Zwei Runden werden aufgezeichnet. Das Signal steigt über *EnterAt* und fällt dann zweimal unter *ExitAt*, einmal an jedem Peak. Innerhalb dieser beiden Kreuzungsfenster findet der Timer nach der Rauschfilterung das stärkste Signal, das als aufgezeichnete Rundenzeit verwendet werden kann._

### Alternative Tuning Methode

Mit den Schaltflächen *Capture* kann der aktuelle RSSI-Wert als *EnterAt* - oder *ExitAt* -Wert für jeden Knoten gespeichert werden. Die Werte können auch manuell eingegeben und angepasst werden.

Schalten Sie ein Quad auf dem richtigen Kanal ein und bringen Sie es einige Sekunden lang sehr nahe an den Timer. Dadurch kann der Timer den RSSI-Spitzenwert für diesen Knoten erfassen. Dies sollte für jeden Knoten / Kanal erfolgen, der abgestimmt wird. Der Spitzenwert wird angezeigt.

#### EnterAt

Ein guter Ausgangspunkt für *EnterAt* ist die Erfassung des Werts mit einem Quad, das etwa 1,5 bis 3 m vom Timer entfernt ist.

#### ExitAt

Ein guter Ausgangspunkt für *ExitAt* ist die Erfassung des Werts mit einem Quad, das etwa 6 bis 9 m vom Timer entfernt ist.

## Anmerkungen

* Ein niedriger *ExitAt* -Wert kann immer noch ein genaues Timing liefern, aber das System wartet länger, bevor Runden angekündigt werden. Eine Verzögerung bei der Ansage hat keinen Einfluss auf die Genauigkeit des Timers.
* Die Einstellung *Minimale Rundenzeit* kann verwendet werden, um zusätzliche Durchgänge zu verhindern, kann jedoch Kreuzungen maskieren, die zu früh ausgelöst werden. Es wird empfohlen, das Verhalten bei *Hervorheben* anstatt bei *Verwerfen* zu belassen.
* Wenn während eines Rennens Zeitprobleme auftreten und die RSSI-Grafiken auf den Senderstandort reagieren, beenden Sie das Rennen nicht. Speichern Sie das Rennen nach Abschluss und besuchen Sie die Seite *Marschall*. Der gesamte RSSI-Verlauf wird gespeichert und das Rennen kann mit aktualisierten Tuning-Werten genau neu berechnet werden.

## Fehlerbehebung

### Fehlende Runden (System normalerweise *Löschen*)

Tuning Graph<br />
_Runden werden nicht aufgezeichnet, wenn RSSI EnterAt nicht erreicht wurde._

* Senken Sie *EnterAt*

### Fehlende Runden (System normalerweise *Crossing*)

Tuning Graph<br />
_Runden werden zusammengeführt, wenn *ExitAt* zu hoch ist, weil die erste Rundenüberquerung nie abgeschlossen wird._

* Erhöhen Sie *ExitAt*

### Runden registrieren sich für andere Teile eines Kurses

Tuning Graph<br />
_Extra-Kreuzungen treten auf, wenn *EnterAt* zu niedrig ist._

* Erhöhen Sie *EnterAt*, bis *Kreuzungen* erst in der Nähe des Timing-Gates beginnen. (Verwenden Sie nach dem Speichern eines Rennens die Seite *Marschall*, um die besten Werte zu ermitteln und zu speichern.)

### Viele Runden werden gleichzeitig registriert

Tuning Graph<br />
_Zu viele Runden treten auf, wenn *ExitAt* zu nahe an *EnterAt* liegt, weil Runden zu schnell beendet werden._

* Erhöhen Sie nach Möglichkeit *EnterAt*
* Niedriger *ExitAt*

Die Einstellung *Minimale Rundenzeit* behält immer die erste Überfahrt bei und verwirft nachfolgende Runden, die zu früh auftreten. In diesem Fall würde diese Einstellung die richtige erste Kreuzung verwerfen und die falsche zweite Kreuzung beibehalten. Es wird empfohlen, das Verhalten *Minimale Rundenzeit* bei *Hervorheben* anstatt bei *Verwerfen* zu belassen, damit ein Rennveranstalter jeden Fall manuell überprüfen kann.

### Die Registrierung der Runden dauert lange

Tuning Graph<br />
_Die Rundenaufzeichnung dauert lange, wenn *ExiAt* niedrig ist. Dies hat keinen Einfluss auf die Genauigkeit der aufgezeichneten Zeit._

* Erhöhen Sie *ExitAt*

### Der Knoten kreuzt niemals

Tuning Graph<br />
_Laps werden nicht registriert, wenn RSSI *EnterAt* nie erreicht ._

* Senken Sie *EnterAt*

### Der Knoten ist niemals *klar*

Tuning Graph<br />
_Laps werden nicht abgeschlossen, wenn RSSI niemals unter *ExitAt* fällt ._

* Erhöhen Sie *ExitAt*

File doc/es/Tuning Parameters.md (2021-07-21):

# Parámetros de calibración y ajuste del sensor

Cada nodo realiza un seguimiento de la intensidad de la señal (RSSI) en una frecuencia seleccionada y utiliza esta intensidad relativa para determinar si un transmisor está cerca de la puerta donde está alojado el crono. El sistema de sincronización RotorHazard le permite calibrar cada nodo individualmente para que pueda compensar el comportamiento y las diferencias de hardware en su sistema y en su entorno.

Un nodo puede estar *Cruzando* o *Despejado*. Si un nodo es *Despejado*, el sistema cree que no hay ningún dron cerca de la puerta del crono porque el RSSI es bajo. Si está *Cruzando*, el sistema cree que hay un transmisor pasando por la puerta de sincronización porque el RSSI es alto. Se registrará un pase de vuelta una vez que *Cruzando* haya finalizado y el sistema regrese a *Despejado*.

Tuning Graph<br />
_La señal RSSI durante una carrera aparece similar a este gráfico con muchos picos y bajadas visibles. A medida que el transmisor se acerca a la puerta de sincronización, la señal aumenta._

## Parámetros
Dos parámetros que afectan el estado *Cruzando*: *EnterAt* y *ExitAt*.

### EnterAt
El sistema cambiará a *Cruzando* cuando la señal RSSI suba o supere este nivel. Está indicado por una línea roja.

### ExitAt
El sistema cambiará a *Despejado* una vez que el valor de la señal RSSI caiga por debajo de este nivel. Está indicado por una línea naranja.

Entre *EnterAt* y *ExitAt*, el sistema seguirá estando *Cruzando* o *Despejado* dependiendo de su estado anterior.

Sample RSSI Graph

### Modo de Calibrado

El modo de calibrado *Manual* siempre utilizará los valores *EnterAt* y *ExitAt* proporcionados por el usuario manualmente.

El modo de calibración *Adaptativo* utiliza los puntos definidos por el usuario a menos que haya carreras guardadas. Cuando existen carreras guardadas, el cambio entre series iniciará una búsqueda de datos de carreras anteriores para obtener los mejores valores de calibrado para usar en la próxima carrera. Estos valores se copian y reemplazan los valores actuales *EnterAt* y *ExitAt* para todos los nodos. Este modo mejora la calibración a medida que se guardan más carreras, si el director de carrera confirma los conteos de vueltas entrantes o los recalcula a través de la página *Mariscal*. Para que estos valores se vayan guardando tendremos que pinchar en REALIZAR CAMBIOS dentro de la página *Mariscal*

## Sintonización
Antes de sintonizar, encienda el temporizador y manténgalo en funcionamiento durante unos minutos para permitir que los módulos receptores se calienten. Los valores de RSSI tienden a aumentar en algunos puntos a medida que el temporizador se calienta.

Puede usar la página *Mariscal* para ajustar los valores visualmente. Recopile datos corriendo una carrera con un piloto en cada canal, luego guárdelo. Abra la página *Mariscal* y vea los datos de la carrera ajustando los puntos de entrada y salida hasta que el número de vueltas sea correcto. Guarde los puntos de entrada/salida en cada nodo para usarlos como calibrado para futuras carreras.

### Configurar el valor *EnterAt*
Tuning Graph

* Por debajo del pico de todos los cruces de puertas
* Por encima de cualquier pico cuando el transmisor no está cerca de la puerta
* Superior a *ExitAt*

### Configurar el valor *ExitAt*
Tuning Graph

* Debajo de los valles que ocurren durante un cruce de la puerta
* Por encima del valor más bajo visto durante cualquier vuelta
* Menor que *EnterAt*

Los valores ExitAt más cercanos a EnterAt permiten que el temporizador anuncie y muestre vueltas antes, pero puede hacer que se registren varias vueltas.

### Ejemplo de Sintonización
Tuning Graph<br />
_Se registran dos vueltas. La señal sube por encima de *EnterAt* y luego cae por debajo de *ExitAt* dos veces, una en cada pico. Dentro de estas dos ventanas cruzadas, el crono encuentra la señal más fuerte después del filtrado de ruido para usarla como el tiempo de vuelta registrado._

### Método de ajuste alternativo

Los botones *Capturar* pueden usarse para almacenar la lectura actual de RSSI como el valor *EnterAt* o *ExitAt* para cada nodo. Los valores también pueden ingresarse y ajustarse manualmente.

Encienda un quad en el canal correcto y llévelo muy cerca del crono durante unos segundos. Esto permitirá que el crono capture el valor máximo de señal RSSI para ese nodo. Esto debe hacerse para cada nodo/canal que se esté sintonizando. Se mostrará el valor pico.

#### EnterAt
Un buen punto de partida para *EnterAt* es capturar el valor con un quad a unos 1,5m – 3m (5–10 pies) del temporizador.

#### ExitAt
Un buen punto de partida para *ExitAt* es capturar el valor con un quad a unos 6m – 9m (20–30 pies) del temporizador.

## Notas
* Un valor bajo *ExitAt* aún puede proporcionar una sincronización precisa, pero el sistema esperará más tiempo antes de anunciar vueltas. Un retraso en el anuncio no afecta la precisión del temporizador.
* El ajuste *Tiempo mínimo de vuelta* se puede usar para evitar pases adicionales, pero puede enmascarar los cruces que se activan demasiado pronto. Se recomienda dejar el comportamiento en *Resaltar* en lugar de *Descartar*.
* Si tiene problemas de tiempo durante una carrera y los gráficos RSSI responden a la ubicación del transmisor, no pare la carrera. Guarde la carrera después de que se complete y visite la página *Mariscal*. Todo el historial RSSI se guarda y la carrera se puede volver a calcular con precisión con valores de ajuste actualizados.

## Solución de Problemas

### Vueltas Perdidas (Sistema generalmente *Despejado*)
Tuning Graph<br />
_Las vueltas no se registran si RSSI no llega a EnterAt._
* Bajar *EnterAt*

### Vueltas Perdidas (Sistema generalmente *Cruzando*)
Tuning Graph<br />
_Las vueltas fse fusionan si *ExitAt* es demasiado bajo porque el primer cruce de la vuelta nunca se completa._
* Subir *ExitAt*

### Se cuentan Vueltas en otras partes del circuito
Tuning Graph<br />
_Los cruces adicionales ocurren cuando *EnterAt* es demasiado bajo ._
* Elevar *EnterAt* hasta que *los cruces* solo comiencen cerca de la puerta del crono. (Use la página *Mariscal* después de guardar una carrera para determinar y guardar los mejores valores).

### Se registran varias vueltas a la vez
Tuning Graph<br />
Ocurren demasiadas vueltas cuando *ExitAt* está demasiado cerca de *EnterAt* porque las vueltas salen demasiado rápido.
* Elevar *EnterAt*, si es posible
* Bajar *ExitAt*

El ajuste *Tiempo mínimo de vuelta* siempre mantiene el primer cruce y descarta las vueltas posteriores que ocurren demasiado pronto. En este caso, esta configuración descartaría el primer cruce correcto y mantendría el segundo cruce incorrecto. Se recomienda dejar el comportamiento *Tiempo mínimo de vuelta* en *Resaltar* en lugar de *Descartar* para que un organizador de la carrera pueda revisar manualmente cada caso.

### Las Vueltas tardan mucho en registrarse
Tuning Graph<br />
_El registro de las vueltas tarda mucho tiempo en completarse si *ExiAt* es bajo. Esto no afecta la precisión del tiempo registrado.
* Elevar *ExitAt*

### El nodo nunca está *Cruzando*
Tuning Graph<br />
_No se registrarán vueltas si la señal RSSI nunca alcanza *EnterAt*._
* Bajar *EnterAt*

### El nodo nunca está *Despejado*
Tuning Graph<br />
_Las vueltas nunca se completarán si la señal RSSI nunca cae por debajo de *ExitAt*._
* Subir *ExitAt*

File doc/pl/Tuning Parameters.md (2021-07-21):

# Kalibracja i Parametry Strojenia Czujników

Każda odnoga monitoruje siłę sygnału (RSSI) wybranych częstotliwości i używa tych względnych wartości, żeby zdeterminować kiedy nadajnik jest w pobliżu bramki. System pomiaru czasu RotorHazard pozwala na kalibrację każdej odnogi indywidualnie, przez co różnice w sprzecie mogą zostać skompensowane dla danego systemu i otoczenia.

Odnoga może być w stanie *Przelotu* (Crossing) lub *Czysto* (Clear). Jeśli odnoga jest w stanie *Czysto*, system zakłada, że nadajnik nie jest w pobliżu bramki, ponieważ wartość RSSI jest niska. Jeśli jest w stanie
*Przelotu*, system zakłada, że nadajnik przekracza bramkę, ponieważ wartość RSSI jest wysoka. Przelot przez okrążanie będzie zapisany, kiedy zakończy się *Przelot*, a system wróci do stanu *Czysto*.

Wykres strojenia<br />
_RSSI podczas wyścigu wygląda podobnie do tego, z dużą ilością zmian i  pików. Kiedy nadajnik jest w pobliżu timera, wartość odczytu wzrasta._

## Parametry
Dwa parametry, które wpływają na stan *Przelotu*: *Wlot* i  *Wylot*.

### Wlot
System przełączy się w stan *Przelotu*, gdy wartość RSSI przekroczy tę wartość. Pokazuje to czerwona linia.

### Wylot
System przełączy się w stan *Czysto*, gdy wartość RSSI spadnie poniżej tej wartości. Pokazuje to pomarańczowa linia.

Pomiędzy *Wlotem* a *Wylotem*, system pozostanie w stanie *Przelot* lub *Czysto* w zależności od poprzedniego stanu.

Przykładowy wykres RSSI

### Tryb kalibracji

*Manualny* tryb kalibracji będzie zawsze używał wartości * Wlot* i * Wylot* podanych przez użytkownika.

*Adaptacyjny* tryb kalibracji będzie używał wartości * Wlot* i * Wylot* podanych przez użytkownika dopóki nie pojawią się zapisane wyścigi. Kiedy pojawią się napisane wyścigi, zmiana biegów spowoduje rozpoczęcie poszukiwania danych z poprzedniego wyścigu dla najlepszych wartości kalibracji, żeby użyć ich w kolejnym biegu. Wartości te są skopiowane i zamienione przez obecne *Wlot* i *Wylot* dla wszystkich odnóg. Tryb ten poprawia kalibrację wraz z każdym zapisanym wyścigiem, gdy zarządzający wyścigiem potwierdzi pojawiające się okrążenie - liczy się ono albo jest przeliczane ponownie używając strony *Zarządzanie*.

## Strojenie
Przed strojeniem, włącz timer i zostaw go włączonego na kilka minut, aby pozwolić odbiornikom się nagrzać. Wartości RSSI mają tendencję do zwiększania się o kilka punktów po tym jak timer się nagrzeje

Możesz użyć zakładki *Zarządzanie*, żeby stroić wartości wizualnie.  Zbierz dane przeprowadzając wyścig z pilotem na każdym kanale, później je zapisz. Otwórz stronę *Zarządzanie* i zobacz dane wyścigów. Ustaw wartości Wlot i Wylot, do momentu kiedy liczba okrążeń będzie poprawa. Zapisz wartości wlot i wylot na każdej od nogi żeby użyć ich jako kalibrację dla kolejnych wyścigów.

### Ustawianie wartości *Wlot*
Wykres Strojenia

* Poniżej piku podczas wszystkich przelotów przez bramkę
* Powyżej każdego piku kiedy nadajnik nie jest w pobliżu bramki
* Wyżej niż wartość *Wylot*

### Ustawianie wartości *Wylot*
Wykres Strojenia

* Poniżej każdego spłaszczenia jakie pojawiają się podczas przygotowywania przez bramkę
* Powyżej najniższej wartości widzianej atrakcje okrążenia
* Poniżej wartości *Wlot*

Wartość *Wylot* bliższa wartości *Wlot* pozwala timerowi na ogłoszenie i wyświetlenie okrążeń wcześniej, ale może powodować, że zbyt wiele okrążenie dostanie zapisanych

### Przykład Strojenia
Wykres Strojenia<br />
_Dwa okrążenia są zapisane. Sygnał rośnie powyżej wartości *Wlot*, a później opada poniżej wartości *Wylot* 2 razy, raz przy każdym piku. Podczas tych dwóch przelotów timer szuka najsilniejszego sygnału po odfiltrowywaniu szumu, żeby użyć go jako zapisanego czasu okrążenia

### Alternatywne Metody Strojenia

Przycisk *Przechwyć* (Capture) może być użyty żeby zapisać obecną wartość RSSI jako *Wlot* albo *Wylot* dla każdej odnogi. Wartości mogą być też wpisane ręcznie.

Włącz quad na poprawnym kanale i spraw, żeby zbliżył się bardzo blisko timera na kilka sekund. To pozwoli timerowi przechwycić wartości RSSI dla tej odnogi. Proces ten powinien być przeprowadzony dla każdej odnogi/kanału, który jest strojony. Wartość piku będzie wyświetlona.

#### Wlot
Dobrym punktem startowym dla *Wlot* jest przechwycenie wartości z quadem około 1.5 do 3m od timera.

#### Wylot
Dobrym punktem startowym dla *Wylot* jest przechwycenie wartości z quadem około 6 do 9m od timera.

## Uwagi
* Niska wartość *Wylot* może nadal powodować, że pomiary będą poprawne, ale system będzie dłużej czekał na ogłoszenie okrążeń. Opóźnienie w podaniu okrążenia nie wpływa na dokładność pomiaru.
* Ustawienie Minimalnego Czasu Okrążenia może być użyte, żeby zapobiec dodatkowym przekroczeniom bramki, ale może zamaskować przelot, który pojawia się zbyt szybko. Zaleca się pozostawienie zachowania jako *Podświetl*, a nie *Odrzuć*.
* Jeśli doświadczasz jakichś kwestii związanych z opóźnieniami podczas wyścigu, a wartość RSSI na wykresie odpowiada na odległość nadajnika, nie przerywaj wyścigu. Zachowaj wyścig po tym jak jest ukończony i odwiedź stronę *Zarządzanie*. Wszystkie dane historyczne RSSI są zapisane i wyścig może być dokładnie przekalkulowany z nowymi danymi strojenia.

## Rozwiązywanie Problemów

### Brakujące okrążenie (System przeważnie w stanie *Czysto*)
![Wykres Strojenia](](../img/Tuning%20Graph-04.svg)<br />
_Okrążenia nie są zapisane jeśli wartość RSSI nie przekroczy wartości *Wlot*._
* Obniż *Wlot*

### Brakujące okrążenia (przeważnie w stanie *Przekraczanie*)
![Wykres Strojenia]../img/Tuning%20Graph-05.svg)<br />
_Okrążenia są łączone w jedno jeśli *Wylot* jest za wysoko, ponieważ pierwsze okrążenie nigdy się nie skończyło._
* Podwyższ *Wylot*

### Obrażenia są zarejestrowane w innych częściach torów
Wykres Strojenia<br />
_Dodatkowe przekroczenia pojawiają się kiedy wartość *Wlot* jest ustawiona za nisko._
* Podnieść wartość *Wlot* do momentu kiedy *Przelot* będzie zaczynać się tylko w pobliżu bramki. Użyj strony *Zarządzanie* po zapisaniu w wyścigu, żeby stwierdzić jaka powinna być to wartość i zapisz najbardziej pasujące wartości.

### Wiele okrążeń zarejestrowanych na raz
Wykres Strojenia<br />
_Zbyt wiele okrążeń pojawia się kiedy wartość *Wylot* jest za blisko wartości *Wlot*, ponieważ okrążenie kończy się zbyt szybko._
* Podnieś wartość *Wlot*, jeśli to możliwe
* Obniż wartośc *Wylot*

### Ustawienie Minimalny Czas Okrążenia zawsze utrzymuje pierwsze przekroczenie i odrzuca kolejne które pojawiają się zbyt szybko.
*W takim wypadku ustawienie to odrzuciłoby pierwsze poprawne przekroczenie i utrzymało kolejne niepoprawne. Zaleca się pozostawienie opcji ustawionej na *Podświetlenie*, a nie na *Odrzucenie*, żeby organizator wyścigu mógł ręcznie sprawdzić każdy przypadek.

### Okrążeniom zajmuje dużo czasu, żeby się zarejestrowały
Wykres Strojenia<br />
_Zapisanie okrążeń trwa zbyt długo kiedy wartość *Wylot* jest za niska. Nie wpływa to na poprawność czasu zapisanych okrążeń._
* Podnieś *Wylot*

### Odnoga nigdy nie jest w stanie *Przelot*
Wykres Strojenia<br />
_Okrążenie nigdy nie zostanie zarejestrowane jeśli wartość RSSI nigdy nie przekroczy wartości *Wlot*._
* Obniż *Wlot*

### Odnoga nigdy nie jest w stanie *Czysto*
Wykres Strojenia<br />
_Okrążenie nigdy się nie skończy jeśli wartość RSSI nigdy nie spadnie poniżej wartości *Wylot*._
* Podnieś *Wylot*

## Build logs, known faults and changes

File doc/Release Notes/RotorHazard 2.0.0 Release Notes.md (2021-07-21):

# RotorHazard 2.0.0 Release Notes

## Main Features
* Improved node filtering improves timing accuracy and ease of calibration by resisting outlier noise. No longer requires setting filter ratio when changing between indoor and outdoor environments.
* Race history collection: Records signal data during a race so calibration can be adjusted afterward.
* Improved browser timer (system-clock based vs. interval-based): more accurate and better synchronization
* Synchronization and delay compensation for i2c and browser communciations
* Synchronization of LED changes and browser start signals
* Race marshaling: add laps, remove laps, and recalculate all laps based on signal history.
* LiveTime support.
* Race scheduling (delayed staging/start)
* JSON API exposes race data for use by other services on network.
* Supports BME280 temperature sensor and INA219 voltage sensor 

### UI
* Added [keyboard shortcuts](https://github.com/RotorHazard/RotorHazard/blob/main/doc/User%20Guide.md#run) for start race, stop race, save laps, clear laps, manual laps, and dismiss message
* Selectable generated or MP3 tones (each work better on different browsers)
* Improved use of large screen areas
* Warn about suspect calibration values
* Display local race start time
* Display race lap absolute timestamp
* Restore opened panels when results refresh
* Warn about browser timer sync loss
* Less intrusive message location 

### Other
* New 3D printed case design/STL files
* Improved documentation
* Added French language
* Some UK localization
* Optionally used libraries are not required to install
* Simulated interface for developing without hardware present
* Unit tests for important node functions
* Can stop a race during staging
* Bug fixes and performance improvements

## Upgrade Notes
* The monotonic library is now required. Connect the pi to the internet, change to the server directory, then run "sudo pip install -r requirements.txt" to get it.
* Use of [directional RF shielding](https://github.com/RotorHazard/RotorHazard/blob/main/doc/Hardware%20Setup.md#add-a-directional-rf-shield) is now considered a required part of the hardware build.

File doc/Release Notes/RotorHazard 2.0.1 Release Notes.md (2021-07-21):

# RotorHazard 2.0.1 Release Notes

## Updates
* Language translation updates
* Update LED library
* Fix LEDs not actually optional
* Fix opening Marshal page clears local settings
* Fix database recovery of RSSI thresholds
* Update requirements to prevent dependency vulnerabilities
* Add DJI channels

## Upgrade Notes
* If you run LEDs, you will need to update the rpi_281x library. Connect the pi to the internet, then run "sudo pip install --upgrade rpi_ws281x".

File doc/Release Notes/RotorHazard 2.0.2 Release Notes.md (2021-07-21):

# RotorHazard 2.0.2 Release Notes

## Updates
* Improve CORS handling (fixes LiveTime support)
* Set dependency requirements to known working versions
* Improve LED detection (support older lib)
* Language updates
* Minor cleanup

## Upgrade Notes
* After updating project files, change to ~/RotorHazard/src/server and run "sudo pip install --upgrade -r requirements.txt" to update dependencies to known working versions. This can take a few minutes to run. This is not required for new builds.

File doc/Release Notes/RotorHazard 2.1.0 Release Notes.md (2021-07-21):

# RotorHazard 2.1.0 Release Notes

## Updates from 2.0

 * Improved browser/pi time sync (improves sync of audio/LED start signals and time capture)
 * Adjust calibration based on pilot/node history
 * Touch-marshaling: click and drag on graph to quickly select laps and adjust tuning parameters
 * Auto-increment heat when race is saved (maintains same class)
 * LED effects library
 * LED management maps effects to timer events
 * LED panel support: image bitmap display, image rotation, row index conversion
 * Colorblind- and FPV-camera-friendly images for 16x16 LED panels
 * Improved responsiveness (non-blocking pass callbacks and results calculations)
 * Improved documentation; especially tuning parameters with new illustrations
 * Offline documentation reader
 * Improved UI for race marshaling (graph scaling, data reload, default to most recently run race)
 * New heat pilot assignments default to "None"
 * Hide disabled nodes from UI (when disabled by frequency)
 * Keep deleted realtime laps for restoration in marshaling
 * Frontend display of lap number, time since start, time since lap 0 (Klaus-Michael PR #105)
 * Highlight laps recorded after time has expired during a fixed-time race
 * Generic sensor framework (pulquero PR #159)
 * Support for USB-connected nodes (see 'doc/USB Nodes.md')
 * Cleaned-up and improved node code (pulquero PR #99)
 * Added node I2C comms monitor (should prevent unresponsive nodes)
 * Improved node status LED: now shows idle (2s blink), crossing (solid), and data bus activity
 * Split-timing support (experimental) (pulquero PR #94)
 * Band scanner (experimental, enabled via Debug config flag) (pulquero)
 * Browser sync quality now visible under ... -> About RotorHazard (Run or Current page only)
 * Added server reboot button
 * Various bug fixes and minor improvements
 * Added primary documentation translations (es, pl)
 * Added Polish language
 * Language updates
 * Dependency updates

### LED Panel

LED panel hardware is configured exactly like LED strips. To enable image display, follow the instructions at the top of src/server/led_handler_bitmap.py to install necessary libraries. See config-dist.json for new LED options that may be used. If your panel image requires rotation, use `PANEL_ROTATE` with the number of 90-degree CCW rotations needed [0..3]. Some panels are not wired in a typical left-to-right pattern and are instead wired in a Z-pattern (every other row is addressed right-to-left). Set `"INVERTED_PANEL_ROWS": true` to correct this.

### Upgrade Notes

To install RotorHazard on a new system, see the instructions in doc/Software Setup.md

To update an existing RotorHazard installation to this version:
```
cd ~
wget https://codeload.github.com/RotorHazard/RotorHazard/zip/2.1.0 -O temp.zip
unzip temp.zip
mv RotorHazard RotorHazard.old
mv RotorHazard-2.1.0 RotorHazard
rm temp.zip
cp RotorHazard.old/src/server/config.json RotorHazard/src/server/
cp RotorHazard.old/src/server/database.db RotorHazard/src/server/
```
The previous installation ends up in the 'RotorHazard.old' directory, which may be deleted or moved.

The RotorHazard server dependencies should also be updated (be patient, this command may take a few minutes):
```
cd ~/RotorHazard/src/server
sudo pip install --upgrade --no-cache-dir -r requirements.txt
```

### Node Code (Arduino)

Node code changes for NODE_API_LEVEL 22 provide faster node polling and more robust operation (with recovery via a communications monitor). Please upgrade using the code supplied with this release. This version is not different from 2.1.0-beta.2, no updates are needed if upgrading from that version or later.

As always, to report bugs please post a GitHub issue [here](https://github.com/RotorHazard/RotorHazard/issues).

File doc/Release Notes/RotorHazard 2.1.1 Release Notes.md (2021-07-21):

# RotorHazard 2.1.1 Release Notes

## Updates from 2.1.0

 * Fix LED custom color selector
 * Fix profile selector
 * Added support for RGBW strips
 * Improved documentation and translations

See [release notes from 2.1.0](https://github.com/RotorHazard/RotorHazard/releases/tag/2.1.0) for more information on this version.

## Upgrade Notes

To install RotorHazard on a new system, see the instructions in doc/Software Setup.md

To update an existing RotorHazard installation to this version:
```
cd ~
wget https://codeload.github.com/RotorHazard/RotorHazard/zip/2.1.1 -O temp.zip
unzip temp.zip
mv RotorHazard RotorHazard.old
mv RotorHazard-2.1.1 RotorHazard
rm temp.zip
cp RotorHazard.old/src/server/config.json RotorHazard/src/server/
cp RotorHazard.old/src/server/database.db RotorHazard/src/server/
```
The previous installation ends up in the 'RotorHazard.old' directory, which may be deleted or moved.

The RotorHazard server dependencies should also be updated (be patient, this command may take a few minutes):
```
cd ~/RotorHazard/src/server
sudo pip install --upgrade --no-cache-dir -r requirements.txt
```

## Node Code (Arduino)

No additional code changes have been made to nodes since the 2.1.0 release.

As always, to report bugs please post a [GitHub issue](https://github.com/RotorHazard/RotorHazard/issues).

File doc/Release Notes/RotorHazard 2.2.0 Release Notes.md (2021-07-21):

# RotorHazard 2.2.0 Release Notes

RotorHazard 2.2.0 provides many new features and fixes, including:

### Logging
The RotorHazard interface now has a "View Server Log" menu item (in the "..." menu) and a "Download Logs" button that will create and download a '.zip' archive file containing all available log files and the current configuration and database files. When reporting issues, using the "Download Logs" button and including the generated '.zip' file is highly recommended.

### VRx Control
See doc/Video Receiver.md

### Streaming
The _..._ -> _Stream Displays_ menu option generates a list of URLs which can be directly placed by OBS into scenes.

### Heat Generation
From _Settings_ -> _Heats_ panel. If an input class other than "Randomize" is selected, heats are generated using the "Win Condition" setting of the input class' race format. Lower seeded heats are added first.

### Display Result Source
Mouse over or click/tap on fastest lap or fastest consecutive time to view which round/heat was the source for that time.

## Updates from RotorHazard 2.1.1

* VRx Control and OSD messaging (supports ClearView 2.0) #291 #285 #236 
* Dynamic overlay pages for use with live streaming (OBS) #318 #282 #226
* Improved results generation performance and caching #293 #193 #113
* Heat generation from class results or available pilots #304 #192
* Pilot sorting by name or callsign #297 #195 #177
* Enable removing of unused pilots, heats, classes #300 #8
* Duplicate heats and classes #314 #180
* New options for staging tones #268 #93 #189
* Display source heat/round for result in summary leaderboard #298 #157
* Highlight laps recorded after fixed-time race ends #209 #313
* Arbitrary user text-to-speech callouts #315 #208 #161
* Hardware power saving #311
* Node hardware addressing update #277 #252 
* Enabling in-system programming of nodes #277 #262
* Improved logging and log visibility #330 #324 #289 #283 #295 #301 #303
* Logs saved to file #323
* Automatic log file pruning #323
* Improved database recovery #308
* Internal event system for triggering behaviors; enables plugins and other 3rd party integrations #273 #299
* Fixed pass crossing issues with maxLapsWin races #348
* Node code simplification and cleanup #296
* Node history buffering #230
* Documentation main page #327 
* Experimental node low-pass filter #230
* Code structure improvements #319 #287 #310 
* Database organization improvements #267 #136 
* Bug fixes #312 #305
* Fixed heat generator update on class renaming #332
* Fixed freqs callout wrong frequencies #336
* Fixed IMDtabler reads unused nodes #335
* Added documentation on [logging configuration](https://github.com/RotorHazard/RotorHazard/blob/main/doc/Software%20Setup.md#logging)
* Added Release Notes files in doc
* Other documentation updates

## Upgrade Notes

To install RotorHazard on a new system, see the instructions in doc/Software Setup.md

To update an existing RotorHazard installation to this version:
```
cd ~
wget https://codeload.github.com/RotorHazard/RotorHazard/zip/2.2.0 -O temp.zip
unzip temp.zip
mv RotorHazard RotorHazard.old
mv RotorHazard-2.2.0 RotorHazard
rm temp.zip
cp RotorHazard.old/src/server/config.json RotorHazard/src/server/
cp RotorHazard.old/src/server/database.db RotorHazard/src/server/
```
The previous installation ends up in the 'RotorHazard.old' directory, which may be deleted or moved.

The RotorHazard server dependencies should also be updated (be patient, this command may take a few minutes):
```
cd ~/RotorHazard/src/server
sudo pip install --upgrade --no-cache-dir -r requirements.txt
```

## Node Code (Arduino)
There are node code changes for this version (since 2.1.1) to enable hardware power saving, history buffering, new hardware addressing spec, in-system programming, and other features. Please upgrade using the code supplied with this release.

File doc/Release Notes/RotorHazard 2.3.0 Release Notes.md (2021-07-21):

# RotorHazard 2.3.0 Release Notes

RotorHazard 2.3.0 provides many new features and fixes, including:

### Improved Results Generation
This release provides significant performance advantages when saving races and viewing the results page, particularly for large events. Race results are now atomically cached for each race, heat, class, and event. A local page cache is also maintained. These caching systems are updated on an as-needed basis, preventing rebuild of the entire results cache.

### Expanded Win Conditions and First Crossing Behaviors
Win conditions include common race types and new team racing conditions that use average lap times for the entire team. First crossings can now be hole shots, first lap, or staggered starts. See [Race Formats in the User Guide](https://github.com/RotorHazard/RotorHazard/blob/main/doc/User%20Guide.md#race-format) for more details.

### Retroactive Data Manipulation
Organizers may now remove locks on saved race data to manipulate assigned pilots, heats, classes, etc. for the correction of event setup errors in prior races.

### Database Controls and Migrations
Save, restore, and delete database files in the db_bkp folder from the Database panel in Settings. Also restores database files in older formats.

### Split Timing Improvements
Support for multiple cluster/split timers has been fleshed out and improved. See '[doc/Cluster.md](https://github.com/RotorHazard/RotorHazard/blob/main/doc/Cluster.md)' for details.

### Frequency Reference
A [Frequency Reference](https://github.com/RotorHazard/RotorHazard/blob/main/doc/Frequency%20Reference.md) has been added to documentation, and can be pulled up in the offline documentation viewer.

### Python 3 support
Python 2 is past end of life. RotorHazard 2.3.0 may be run on either Python 2 or Python 3. (This is also the last release to support Python 2; after this release, only Python 3 will be supported.)

### Official PCB release
Paweł Fabiszewski has developed a PCB which implements current hardware standards to simplify wiring and component placement, expediting timer builds and improving usability. See [RotorHazard PCB](https://github.com/RotorHazard/RotorHazard/tree/main/resources/PCB) for more details.

### LiveTime Controls
Visit /decoder to open a dedicated page for settings which apply when RotorHazard is connected to LiveTime.

## Updates from RotorHazard 2.2

* Optimize result page rebuild process #446 
* First crossing options (hole shot, first lap, staggered start) #442
* Retroactive data maniplulation #440
* Added PCB files and documentation #397
* Improved results page build and caching #384
* Added expanded win conditions #339 ([See documentation](https://github.com/RotorHazard/RotorHazard/blob/main/doc/User%20Guide.md#race-format))
* Added "decoder" page for LiveTime settings #316
* Added [Frequency Reference](https://github.com/RotorHazard/RotorHazard/blob/main/doc/Frequency%20Reference.md) to documentation
* Split timer improvements #377 #378 #399 #402 #404 #417 #439
* Python 3 compatibility #320 #415 
* Improved display on iOS #470 
* Automatic dark mode #443
* Reconnect when page regains visibility (device wakes from sleep) #447
* Server support of up to 16 nodes (I2C limit is still 8)
* Fix major issue with events and multiple assigned handlers
* Restore and delete databases from UI #59 #421
* Added DJI 50MB channels as "J" band
* Updated DJI 25MB Ch6 to 5880
* Added Shark Byte channels as "S" band
* Added start-of-race enter/exit lowering #389
* Made auto heat increment optional #394
* Added hotkey for start/stop race (spacebar) #437 
* Added more announcement options #395
* Support most recent CVCM protocol #408
* Allow log updates page to be paused #401 #422
* Improved database migrations and fix issues #415
* Enforce format switch on heat change and race staging
* Added semaphore lock for node I/O access #467
* Clears stream node display when seat is empty
* Handle system clock time jumps #439
* Improve message queuing for cluster timers #455
* VRx Control shuts off OSD on CV2.0 #457
* VRx Control uses preliminary JSON protocol #438
* Remove 'null' pilots from results list #388
* Add folder for user data that is not overwritten on update #356 #423
* Ensure correct permissions on generated files and folders
* Improved exception catching/logging on thread/route/render functions #387
* Decoupled sensors from timing interface #386 
* Improved translation support #414 #425
* Additional German translations #414 #425
* Fixed scheduled race cancellation
* Fixed plugin loading #373
* Code refactoring #398 
* Alter last heat's ID to 1 after others deleted #426
* Various minor bug fixes and improvements
* Improved documentation #403

## Upgrade Notes

To install RotorHazard on a new system, see the instructions in '[doc/Software Setup.md](https://github.com/RotorHazard/RotorHazard/blob/main/doc/Software%20Setup.md)'

To update an existing RotorHazard installation to this version:
```
cd ~
wget https://codeload.github.com/RotorHazard/RotorHazard/zip/2.3.0 -O temp.zip
unzip temp.zip
mv RotorHazard RotorHazard.old
mv RotorHazard-2.3.0 RotorHazard
rm temp.zip
cp RotorHazard.old/src/server/config.json RotorHazard/src/server/
cp RotorHazard.old/src/server/database.db RotorHazard/src/server/
```
The previous installation ends up in the 'RotorHazard.old' directory, which may be deleted or moved.

The RotorHazard server dependencies should also be updated (be patient, this command may take a few minutes):
```
cd ~/RotorHazard/src/server
sudo pip install --upgrade --no-cache-dir -r requirements.txt
```

## Node Code (Arduino)
There are no node code changes for this version since 2.2.0. You will need to upgrade your Arduino firmware only if upgrading from a version prior to 2.2.

## Issues
If you encounter a bug, please report it using the [Issues page on GitHub](https://github.com/RotorHazard/RotorHazard/issues). Open "View Server Log" (in the "..." menu) and a "Download Logs" button will create and download a '.zip' archive file containing all available log files and the current configuration and database files.

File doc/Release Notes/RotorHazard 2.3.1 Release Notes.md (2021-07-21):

# RotorHazard 2.3.1 Release Notes

## Updates from 2.3.0

 * Fix LiveTime Decoder page
 * Fix Java detection for Python 3.8 #477
 * Resolve deprecated log functions #476

See [release notes from 2.3.0](https://github.com/RotorHazard/RotorHazard/releases/tag/2.3.0) for more information on this version.

## Documentation

Documentation for RotorHazard 2.3.1 may be found at:
https://github.com/RotorHazard/RotorHazard/blob/2.3.1/doc/README.md

## Installation / Upgrade Notes

To install RotorHazard on a new system, see the instructions in [doc/Software Setup.md](https://github.com/RotorHazard/RotorHazard/blob/2.3.1/doc/Software%20Setup.md)

To update an existing RotorHazard installation to this version:
```
cd ~
wget https://codeload.github.com/RotorHazard/RotorHazard/zip/2.3.1 -O temp.zip
unzip temp.zip
mv RotorHazard RotorHazard.old
mv RotorHazard-2.3.1 RotorHazard
rm temp.zip
cp RotorHazard.old/src/server/config.json RotorHazard/src/server/
cp RotorHazard.old/src/server/database.db RotorHazard/src/server/
```
The previous installation ends up in the 'RotorHazard.old' directory, which may be deleted or moved.

The RotorHazard server dependencies should also be updated (be patient, this command may take a few minutes):
```
cd ~/RotorHazard/src/server
sudo pip install --upgrade --no-cache-dir -r requirements.txt
```

## Node Code (Arduino)
There are no node code changes for this version since 2.2.0. You will need to upgrade your Arduino firmware only if upgrading from a version prior to 2.2.

## Issues
If you encounter a bug, please report it using the [Issues page on GitHub](https://github.com/RotorHazard/RotorHazard/issues). Open "View Server Log" (in the "..." menu) and a "Download Logs" button will create and download a '.zip' archive file containing all available log files and the current configuration and database files.

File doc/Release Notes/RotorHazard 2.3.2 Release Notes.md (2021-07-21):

# RotorHazard 2.3.2 Release Notes

## Updates from 2.3.1

 * Improved compatibility with hardware and python version differences
 * Realign documentation with other updates

See [release notes from 2.3.0](https://github.com/RotorHazard/RotorHazard/releases/tag/2.3.0) and [release notes from 2.3.1](https://github.com/RotorHazard/RotorHazard/releases/tag/2.3.1) for more information on this version.

## Documentation

Documentation for RotorHazard 2.3.2 may be found at:
https://github.com/RotorHazard/RotorHazard/blob/2.3.2/doc/README.md

## Installation / Upgrade Notes

To install RotorHazard on a new system, see the instructions in [doc/Software Setup.md](https://github.com/RotorHazard/RotorHazard/blob/2.3.2/doc/Software%20Setup.md)

Use the commands below to update an existing RotorHazard installation to this version. (Before updating, any currently-running RotorHazard server should be [stopped](https://github.com/RotorHazard/RotorHazard/blob/2.3.2/doc/Software%20Setup.md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).)
```
cd ~
wget https://codeload.github.com/RotorHazard/RotorHazard/zip/2.3.2 -O temp.zip
unzip temp.zip
mv RotorHazard RotorHazard.old
mv RotorHazard-2.3.2 RotorHazard
rm temp.zip
cp RotorHazard.old/src/server/config.json RotorHazard/src/server/
cp RotorHazard.old/src/server/database.db RotorHazard/src/server/
```
The previous installation ends up in the 'RotorHazard.old' directory, which may be deleted or moved.

The RotorHazard server dependencies should also be updated (be patient, this command may take a few minutes):
```
cd ~/RotorHazard/src/server
sudo pip install --upgrade --no-cache-dir -r requirements.txt
```

## Node Code (Arduino)
There are no node code changes for this version since 2.2.0. You will need to upgrade your Arduino firmware only if upgrading from a version prior to 2.2.

## Issues
If you encounter a bug, please report it using the [Issues page on GitHub](https://github.com/RotorHazard/RotorHazard/issues). Open "View Server Log" (in the "..." menu) and a "Download Logs" button will create and download a '.zip' archive file containing all available log files and the current configuration and database files.

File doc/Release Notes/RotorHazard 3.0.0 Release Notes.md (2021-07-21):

# RotorHazard 3.0.0 Release Notes

RotorHazard 3.0.0 provides many new features and fixes, including:

### Support for STM32 hardware
A RotorHazard timer can now be built using the new S32_BPill board (with a single STM32 processor instead of multiple Arduinos). This results in significant cost savings and fewer points of failure for new timer builds. RotorHazard maintains compatibility with all existing hardware.

### S32_BPill PCBs and case
See the [resources](https://github.com/RotorHazard/RotorHazard/blob/master/resources/README.md) section for information on the new [S32_BPill board](https://github.com/RotorHazard/RotorHazard/blob/master/resources/S32_BPill_PCB/README.md) and [3D-printable case](https://github.com/RotorHazard/RotorHazard/blob/master/resources/S32_BPill_case/README.md), including extensive documentation and build guides. STM32F1 and STM32F4 chips are supported on "Blue Pill" and "Black Pill" modules. Also check out the compact [RotorHazard 6 Node STM32 board](https://github.com/RotorHazard/RotorHazard/blob/master/resources/6_Node_BPill_PCB/README.md) (contributed by Aaron Smith).

### Data export
Export race data via the Database panel of the Settings page. Exporters are included for CSV and JSON formats with a variety of data types. Export uses a plugin system that will automatically load user-created exporter files for additional flexibility in data and format returned.

### Improved band / channel support
Selecting a frequency now stores the band/channel information instead of just numeric frequency. As a result, the user interface will display the selected band/channel when recalled (previously the first band/channel that matched the same frequency assignment was provided).

### Live graphic tuning
On the tuning dialog, drawing on the graph will immediately update enter and exit values. The "Tuning" button is removed for each node on the `Run` page as clicking on the graph itself opens this dialog.

### UI refresh
The UI has undergone a minor update, including a customized typeface. Disallowed actions no longer appear as UI options. The spacebar functions as a general-purpose hotkey for advancing the event.

### Cluster terminology has changed
A "Master" timer is now known as a "Primary" timer and "Slave" timers are now known as "Secondary" timers. Existing 'SLAVE' keys in the config.json file are still accepted, but their use is deprecated. Please migrate to 'SECONDARY' keys as documented in [Cluster.md](https://github.com/RotorHazard/RotorHazard/blob/3.0.0/doc/Cluster.md).

### End of support for Python 2
Python 2 is past end of life. RotorHazard 3.0 only officially supports Python 3 and some features will no longer function if run with Python 2. [See documentation for upgrade instructions](https://github.com/RotorHazard/RotorHazard/blob/3.0.0/doc/Software%20Setup.md#5-install-python).

## Documentation
Documentation for RotorHazard 3.0.0 may be found at:
https://github.com/RotorHazard/RotorHazard/tree/3.0.0/doc

## Updates from RotorHazard 2.3

* Support for STM32 #482 #483 #538
* Data Export #456 #253
* Store band/channel #492 #499
* Add leader/winner tones #513
* Update relationship terminology #486
* Add support for hardware buzzer and status LED #538 #553
* Update UI for split/mirror connections #472
* Make important server message more prominent in UI #559
* Add space hotkey condition for race save action #564
* Improved database recovery
* Include customized UI typeface
* Removed UI for disallowed actions
* Make i2c bus index configurable #473
* Send peak duration instead of timestamp #432
* Favor best available data when history buffer is full #433
* Reduce i2c chill #409
* Fix Flask_SQLAlchemy dependency incompatibility
* Fix memory leak #527
* Fix issue with exporting unclassified races
* Fix cache issue with failed database load
* Fix file download under Python 3
* Fix filter time compensation #407
* Improve log outputs
* Add warning for split/cluster version mismatch
* Node firmware versioning #518
* Cleanup of language file #488
* Add STM32 build resources #513 #537
* Improve ease of install #555
* Bug fixes and stability improvements #561 #517 #548 #535
* Improve documentation #491 #495 #549 #558 #568
* Update frequency reference with updated Shark Byte assignments #570

## Installation / Upgrade Notes

To install RotorHazard on a new system, see the instructions in '[doc/Software Setup.md](https://github.com/RotorHazard/RotorHazard/blob/3.0.0/doc/Software%20Setup.md)'

To update an existing RotorHazard installation to this version:
```
cd ~
wget https://codeload.github.com/RotorHazard/RotorHazard/zip/3.0.0 -O temp.zip
unzip temp.zip
mv RotorHazard RotorHazard.old
mv RotorHazard-3.0.0 RotorHazard
rm temp.zip
cp RotorHazard.old/src/server/config.json RotorHazard/src/server/
cp RotorHazard.old/src/server/database.db RotorHazard/src/server/
```
The previous installation ends up in the 'RotorHazard.old' directory, which may be deleted or moved.

For RotorHazard the minimum version of Python supported is 3.5. If your Python is older than this, you should upgrade using the steps in the Software Setup document under "5. [Install Python](https://github.com/RotorHazard/RotorHazard/blob/main/doc/Software%20Setup.md#5-install-python)."

The RotorHazard server dependencies should also be updated (be patient, this command may take a few minutes):
```
cd ~/RotorHazard/src/server
sudo pip install --upgrade --no-cache-dir -r requirements.txt
```

## RotorHazard Node Code
New node code is provided with this version. As of this release, the RotorHazard node code supports both [Arduino-based](https://github.com/RotorHazard/RotorHazard/blob/master/src/node/readme_Arduino.md) and [S32_BPill](https://github.com/RotorHazard/RotorHazard/blob/master/resources/S32_BPill_PCB/README.md) boards.

For the S32_BPill board, the recommended method for installing the node firmware is to use the `Update Nodes` button (in the 'System' section on the 'Settings' page) on the RotorHazard web GUI.

Starting with this release the node code is now assigned a version, with this version at "1.1.4". The node-code version may be viewed in the Server Log, and via the "About RotorHazard" item in the drop-down menu.

## Issues
If you encounter a bug, please report it using the [Issues page on GitHub](https://github.com/RotorHazard/RotorHazard/issues). When reporting issues, using the "Download Logs" button and including the generated '.zip' file is highly recommended (see below).

The Server Log may be displayed via the "View Server Log" item in the drop-down menu. Clicking on the "Select Text" button will select all the displayed log text, which may then be copied and pasted. Clicking on the "Download Logs" button will create and download a '.zip' archive file containing all available log files and the current configuration and database files.

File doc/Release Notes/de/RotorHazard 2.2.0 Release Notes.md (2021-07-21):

# Versionshinweise zu RotorHazard 2.2.0

RotorHazard 2.2.0 bietet viele neue Funktionen und Korrekturen, darunter:

### Protokollierung

Die RotorHazard-Oberfläche verfügt jetzt über einen Menüpunkt "Serverprotokoll anzeigen" (im Menü "...") und eine Schaltfläche "Protokolle herunterladen", mit der eine ".zip" -Archivdatei erstellt und heruntergeladen wird, die alle verfügbaren Protokoll-, die aktuellen Konfigurations- und Datenbankdateien. Wenn Sie Probleme melden, wird dringend empfohlen, die Schaltfläche "Protokolle herunterladen" zu verwenden und die generierte ZIP-Datei einzuschließen.

### VRx-Steuerung

Siehe [doc/Video Receiver.md](doc/de-Video%20Receiver.md)

### Streaming

Die Menüoption _..._-> _Stream Displays_ generiert eine Liste von URLs, die von OBS direkt in Szenen eingefügt werden können.

### Erzeugung von Läufen

Aus dem Bereich _Einstellungen_ -> _Läufe_. Wenn eine andere Eingabeklasse als "Zufällig" ausgewählt ist, werden Vorläufe mit der Einstellung "Gewinnbedingung" des Rennformats der Eingabeklasse generiert. Niedrigere Läufe werden zuerst hinzugefügt.

### Ergebnisquelle anzeigen

Fahren Sie mit der Maus über oder klicken / tippen Sie auf die schnellste Runde oder die schnellste aufeinanderfolgende Zeit, um zu sehen, welche Runde / Hitze die Grundlage für diese Zeit war.

## Updates von RotorHazard 2.1.1

* VRx Control und OSD-Messaging (unterstützt ClearView 2.0) #291 #285 #236
* Dynamische Overlay-Seiten zur Verwendung mit Live-Streaming (OBS) #318 #282 #226
* Verbesserte Leistung bei der Ergebnisgenerierung und Zwischenspeicherung #293 #193 #113
* Erzeugung von Läufen aus Klassenergebnissen oder verfügbaren Piloten #304 #192
* Sortierung der Piloten nach Name oder Rufzeichen #297 #195 #177
* Aktivieren von "Entfernen nicht verwendeter Piloten, Vorläufe, Klassen" #300 #8
* Duplizierung von Vorläufen und Klassen #314 #180
* Neue Optionen für die Inszenierung von Tönen #268 #93 #189
* Anzeige der Läufe / Runden für das Ergebnis in der zusammenfassenden Bestenliste #298 #157
* Markieren Sie Runden, die nach dem Ende des Rennens mit fester Zeit aufgezeichnet wurden #209 #313
* Beliebige Benutzer-Text-zu-Sprache-Beschriftungen #315 #208 #161
* Hardware-Energieeinsparung #311
* Update der Knotenhardwareadressierung #277 #252
* Aktivieren der systeminternen Programmierung von Knoten #277 #262
* Verbesserte Protokollierung und Protokollsichtbarkeit #330 #324 #289 #283 #295 #301 #303
* In Datei #323 gespeicherte Protokolle
* Automatisches Bereinigen von Protokolldateien #323
* Verbesserte Datenbankwiederherstellung #308
* Internes Ereignissystem zum Auslösen von Verhalten; aktiviert Plugins und andere Integrationen von Drittanbietern #273 #299
* Probleme beim Überqueren von Pässen bei maxLapsWin-Rennen #348 wurden behoben
* Vereinfachung und Bereinigung des Knotencodes #296
* Knotenverlaufspufferung #230
* Hauptseite der Dokumentation #327
* Experimenteller Knoten-Tiefpassfilter #230
* Verbesserungen der Codestruktur #319 #287 #310
* Verbesserungen der Datenbankorganisation #267 #136
* Fehlerbehebungen #312 #305
* Das Update des Wärmeerzeugers beim Umbenennen der Klasse #332 wurde behoben
* Fehler behoben: Freqs Callout falsche Frequenzen #336
* Behoben, dass IMDtabler nicht verwendete Knoten #335 liest
* Dokumentation zu [Protokollierungskonfiguration](https://github.com/RotorHazard/RotorHazard/blob/main/doc/de-Software%20Setup.md#logging) hinzugefügt
* Versionshinweisdateien im Dokument hinzugefügt
* Andere Dokumentationsaktualisierungen

## Upgrade-Hinweise

Informationen zum Installieren von RotorHazard auf einem neuen System finden Sie in den Anweisungen in doc / Software Setup.md

So aktualisieren Sie eine vorhandene RotorHazard-Installation auf diese Version:

```
cd ~
wget https://codeload.github.com/RotorHazard/RotorHazard/zip/2.2.0 -O temp.zip
unzip temp.zip
mv RotorHazard RotorHazard.old
mv RotorHazard-2.2.0 RotorHazard
rm temp.zip
cp RotorHazard.old/src/server/config.json RotorHazard/src/server/
cp RotorHazard.old/src/server/database.db RotorHazard/src/server/
```

Die vorherige Installation landet im Verzeichnis 'RotorHazard.old', das gelöscht oder verschoben werden kann.

Die RotorHazard-Serverabhängigkeiten sollten ebenfalls aktualisiert werden (haben Sie etwas Geduld, dieser Befehl kann einige Minuten dauern):

```
cd ~/RotorHazard/src/server
sudo pip install --upgrade --no-cache-dir -r requirements.txt
```

## Knotencode (Arduino)

Für diese Version (seit 2.1.1) wurden Änderungen am Knotencode vorgenommen, um Hardware-Energieeinsparung, Verlaufspufferung, neue Hardware-Adressierungsspezifikation, systeminterne Programmierung und andere Funktionen zu ermöglichen. Bitte aktualisieren Sie diese mit dem in dieser Version enthaltenen Code.

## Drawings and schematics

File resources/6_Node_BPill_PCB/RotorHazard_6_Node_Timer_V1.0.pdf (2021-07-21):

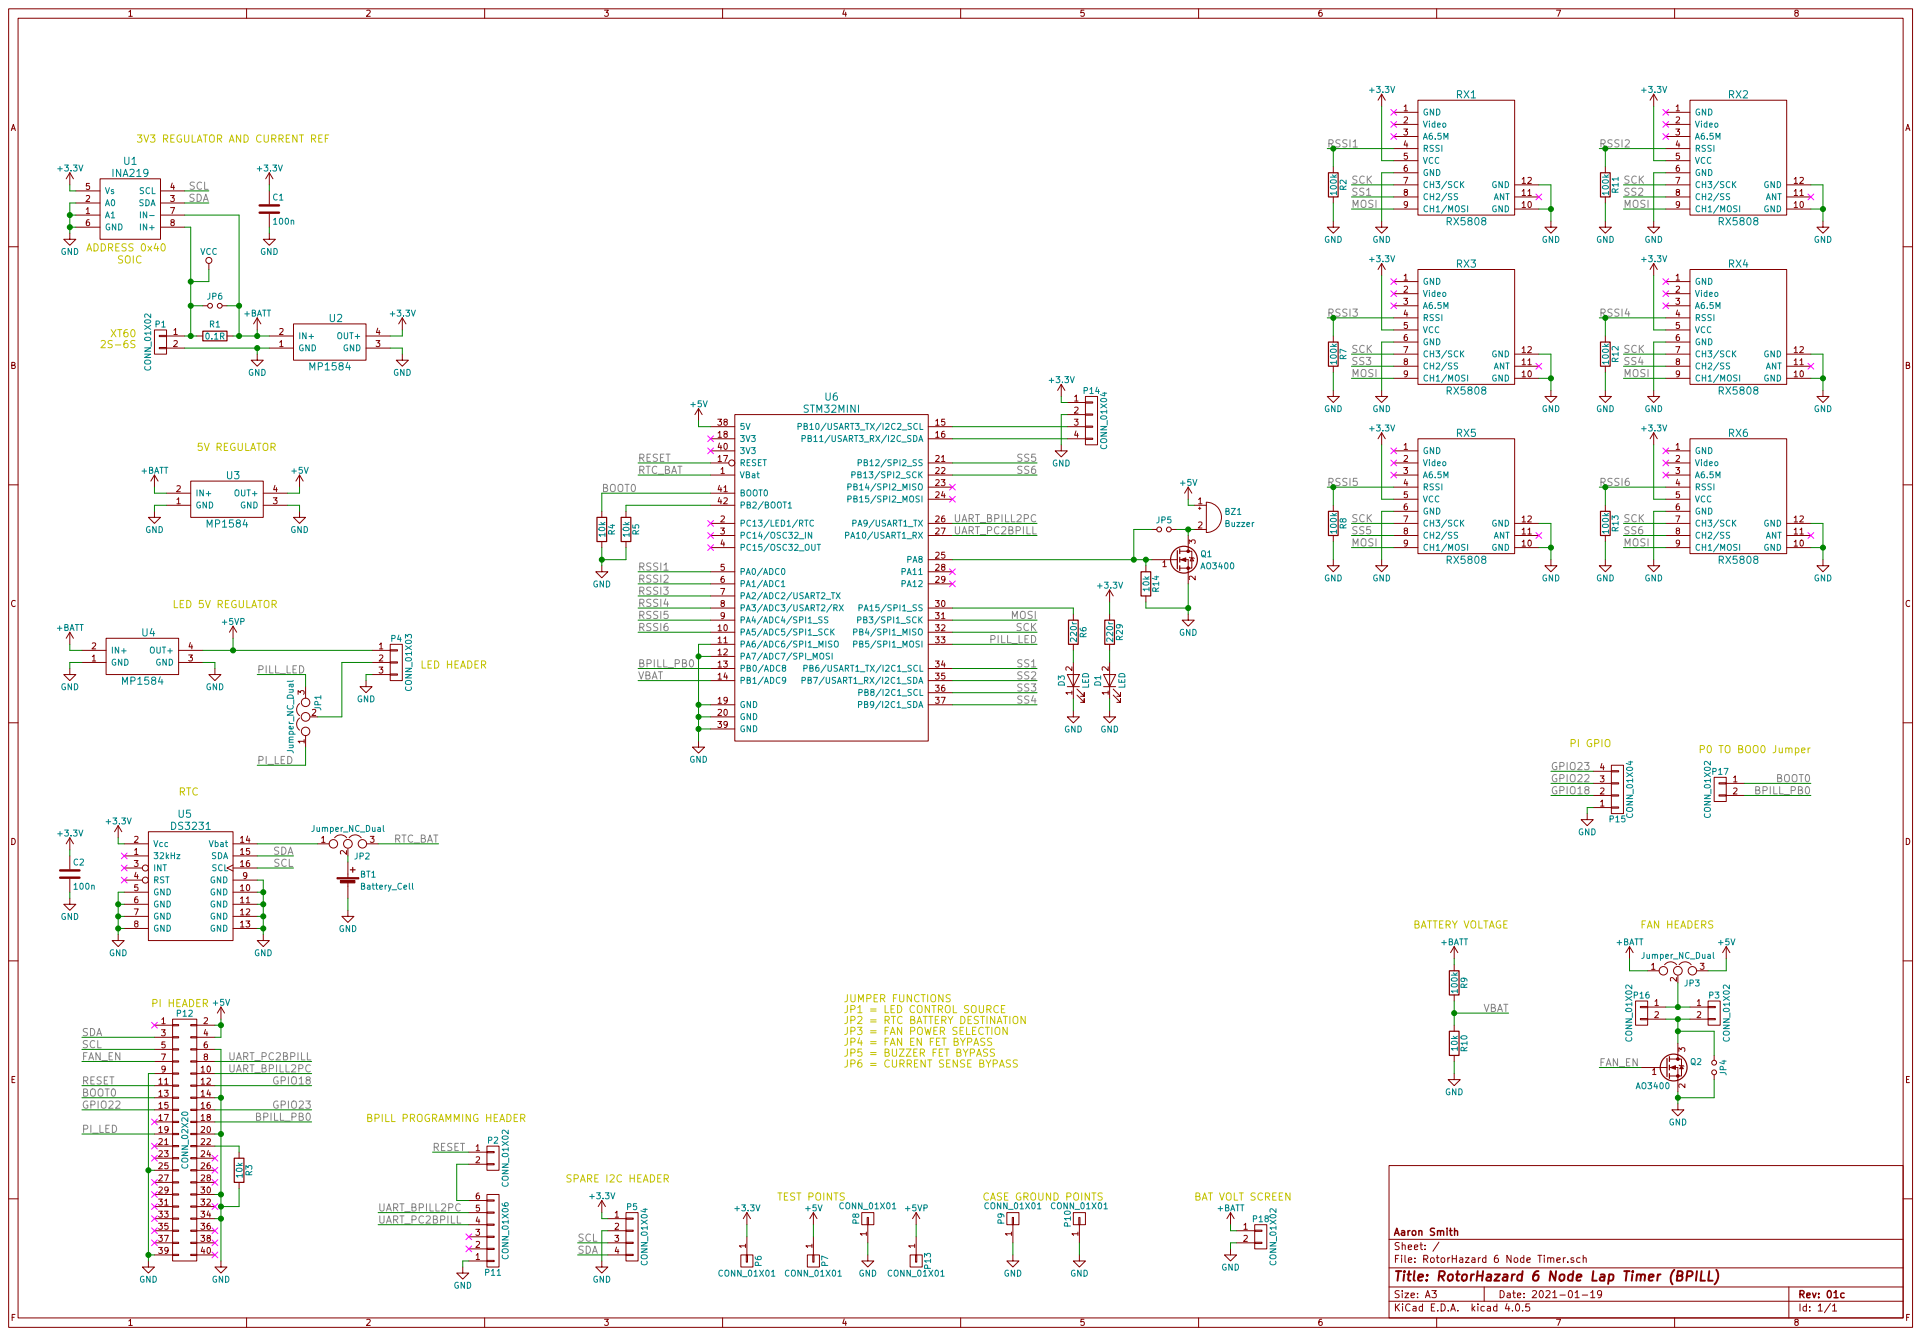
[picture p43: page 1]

3V3 REGULATOR AND CURRENT REF
0.1R SCL

39 P12CONN_02X20 GND 15 | GND SCL

JP1 = LED CONTROL SOURCE
JP2 = RTC BATTERY DESTINATION
JP3 = FAN POWER SELECTION
JP4 = FAN EN FET BYPASS
JP5 = BUZZER FET BYPASS
JP6 = CURRENT SENSE BYPASS

17 | | 18 | BPILL_PB0

2 P18 CONN_01X02+BATT GND BAT VOLT SCREEN

Id: 1/1 Title: RotorHazard 6 Node Lap Timer (BPILL) File: RotorHazard 6 Node Timer.sch Sheet: / Aaron Smith

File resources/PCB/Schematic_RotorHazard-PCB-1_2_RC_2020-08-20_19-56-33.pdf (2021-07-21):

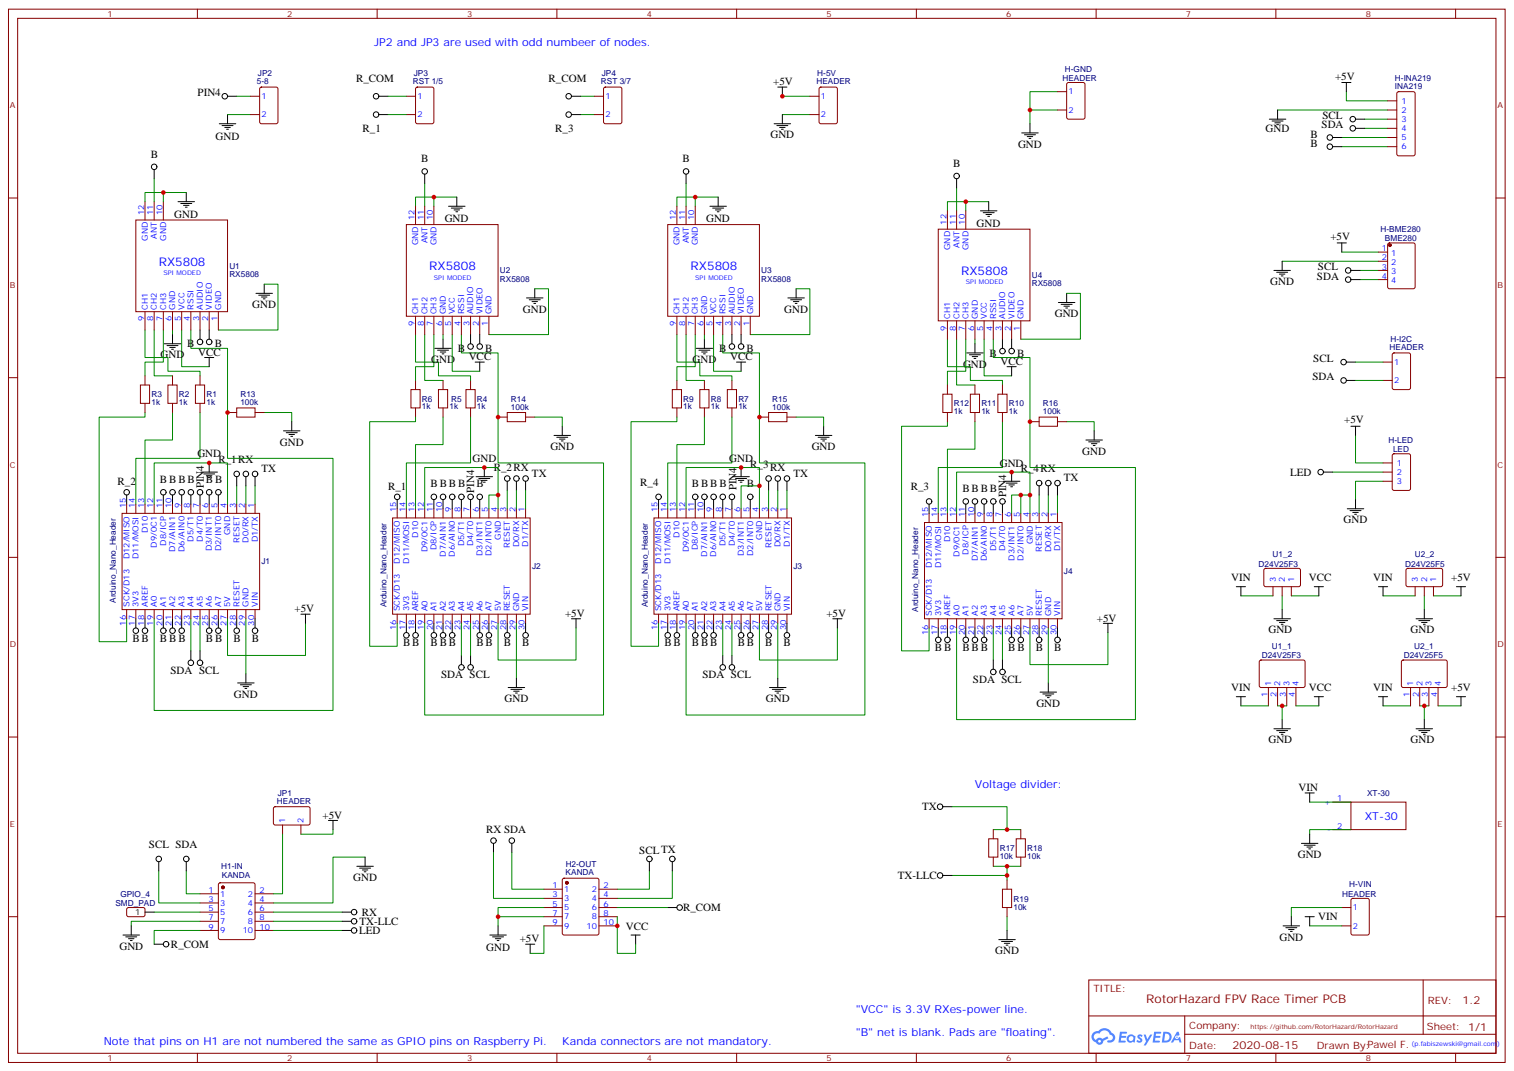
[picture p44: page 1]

JP2 and JP3 are used with odd numbeer of nodes.

SDA SCL

"VCC" is 3.3V RXes-power line.
"B" net is blank. Pads are "floating".

Company: https://github.com/RotorHazard/RotorHazard

Note that pins on H1 are not numbered the same as GPIO pins on Raspberry Pi. Kanda connectors are not mandatory.

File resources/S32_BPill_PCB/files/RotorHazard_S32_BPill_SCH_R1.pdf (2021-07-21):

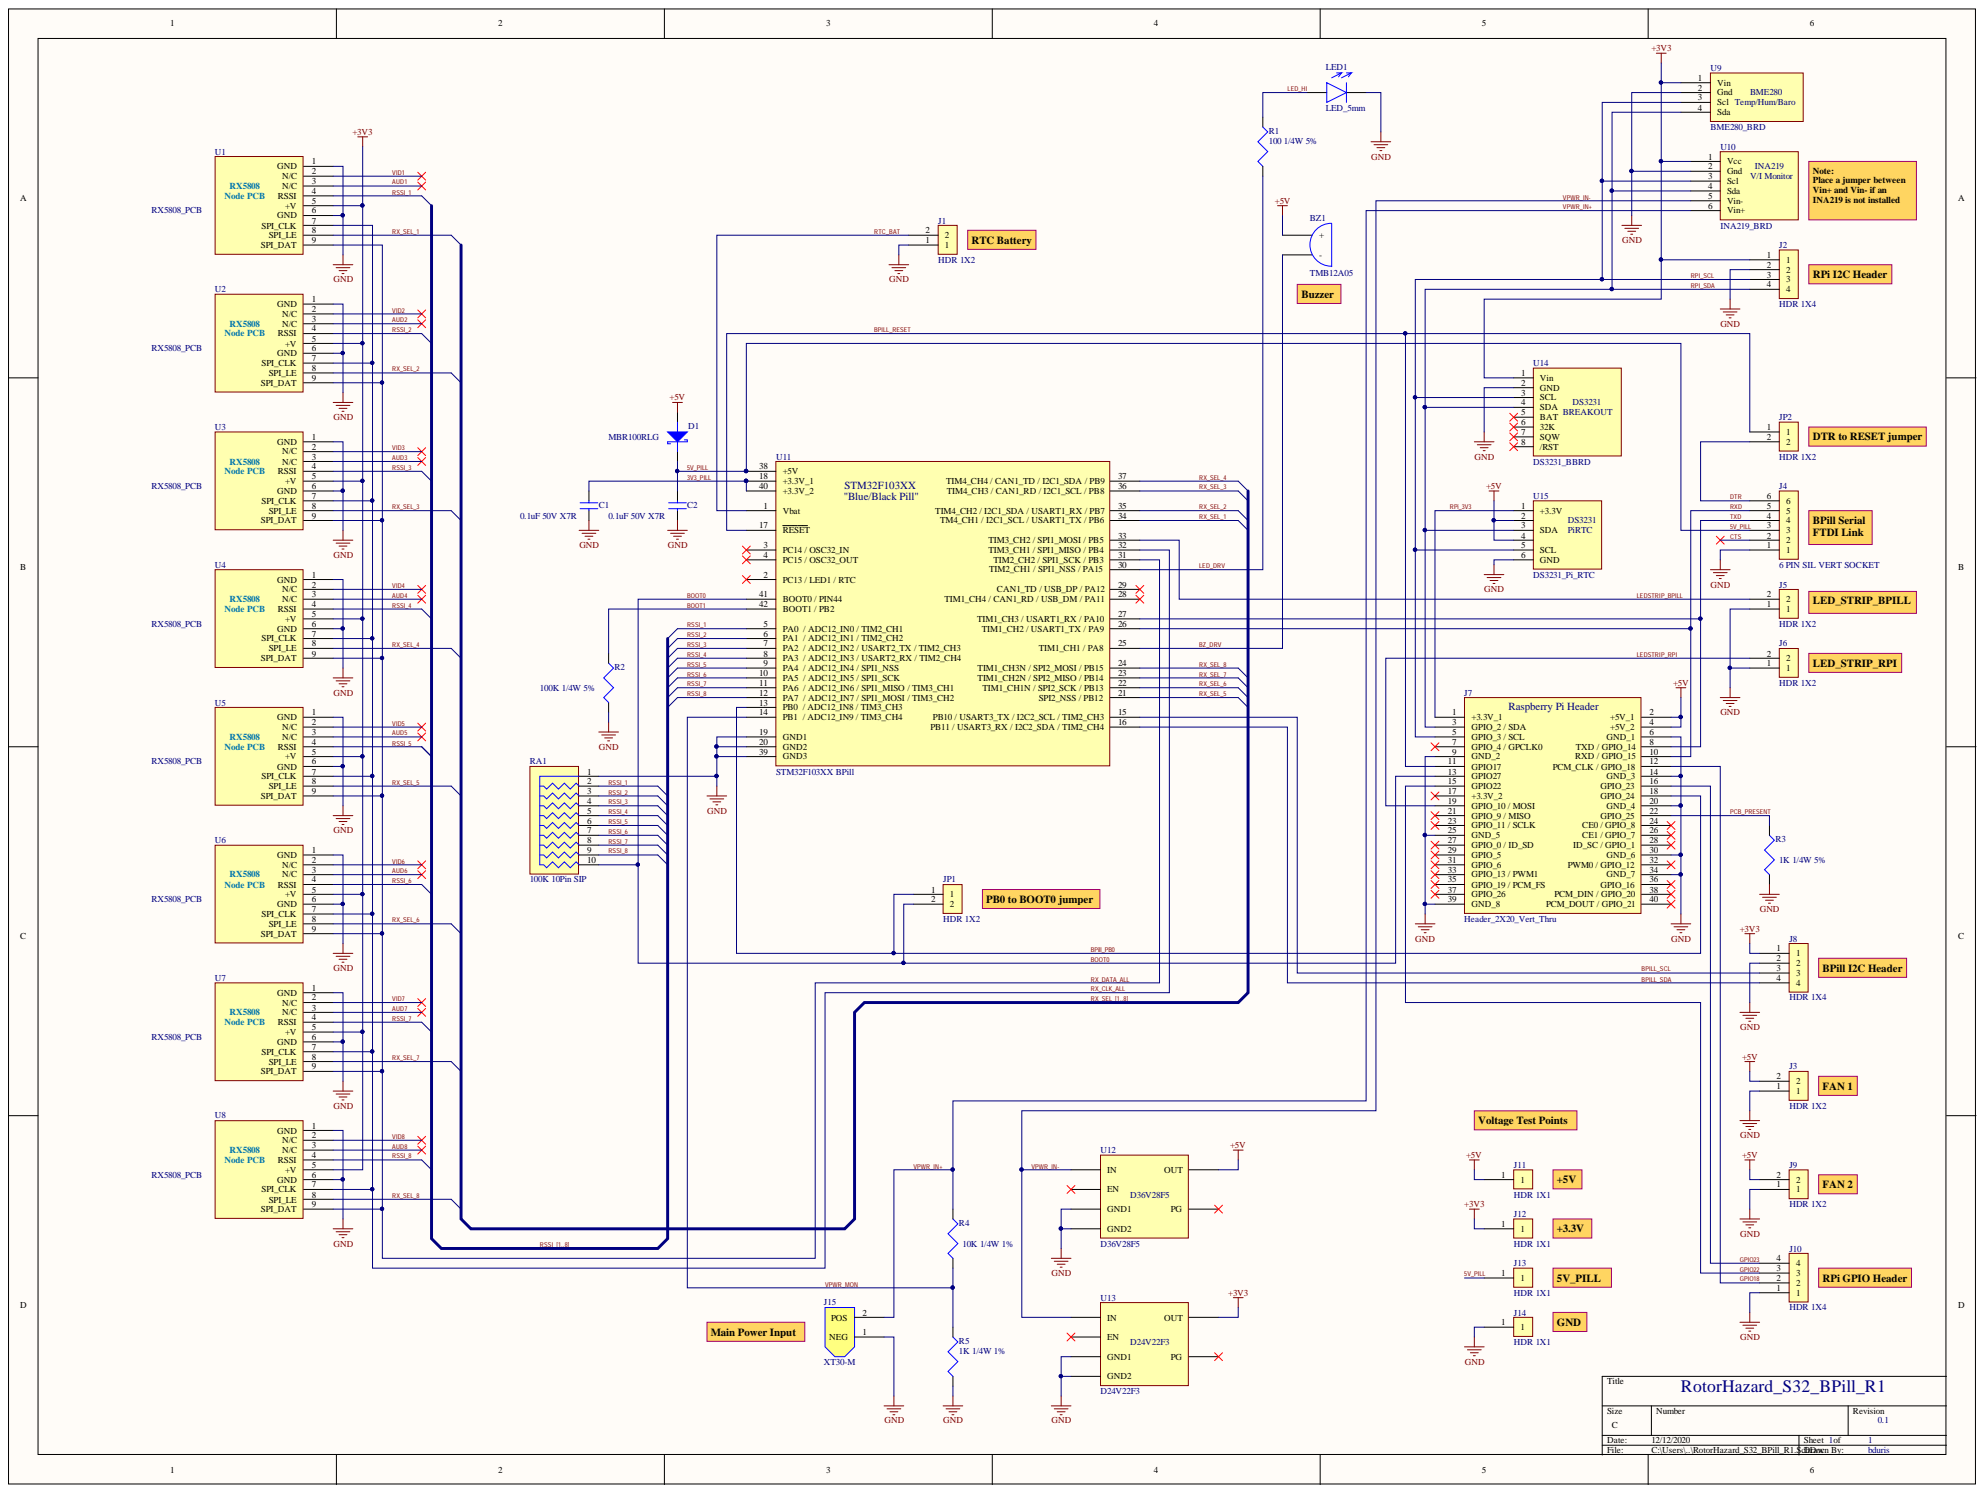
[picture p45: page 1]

RPi I2C Header Note: Place a jumper betw

+ 5 V + 3 . 3 V _ 1 STM32F103XX "Blue/Black Pill" + 3 . 3 V _2 | T M TIM / TIM 2_CH / TIM 2_CH TIM 3 _CH TIM 3 _CH PB1 0 | 4_CH 4 / CA N 1 4_CH 3 / CA N 1 4_CH 2 / I2C1 _ S D 4_CH 1 / I2C1 _ SCL TIM 3 _CH TIM 3 _CH TIM 2_CH TIM 2_CH 1 _CH 4 / CA N 1 TIM 1 _CH 3 TIM 1 _CH 3 4 TIM 1 _CH 3 TIM 1 _CH 2 1 TIM 1 _CH 2 / U S ART 3 _T X / I2C2 U S ART 3 _RX / I2C2 | _T D / I2C1 _ S D A / PB9 _RD / I2C1 _ SCL / PB8 A / U S ART 1 _RX / PB7 / U S ART 1 _T X / PB6 2 / S PI1 _M O SI / PB5 1 / S PI1 _MIS O / PB4 2 / S PI1 _ SCK / PB3 1 / S PI1 _N S S / P A 1 5 _RD / U SB_D M / P A 1 1 / U S ART 1 _RX / P A 1 0 2 / U S ART 1 _T X / P A 9 TIM 1 _CH 1 / P A 8 N / S PI2 _M O SI / PB1 5 N / S PI2 _MIS O / PB1 4 1 N / S PI2 _ SCK / PB1 3 S PI2 _N S S / PB1 2 _ SCL / TIM 2_CH 3 _ S D A / TIM 2_CH 4

BOOT 0 | 1 8 4 0 1

BOOT 1 | 4 2 | 2 7 | 1

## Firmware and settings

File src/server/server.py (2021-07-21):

'''RotorHazard server script'''
RELEASE_VERSION = "3.1.0-dev.8" # Public release version code
SERVER_API = 32 # Server API version
NODE_API_SUPPORTED = 18 # Minimum supported node version
NODE_API_BEST = 35 # Most recent node API
JSON_API = 3 # JSON API version

# This must be the first import for the time being. It is
# necessary to set up logging *before* anything else
# because there is a lot of code run through imports, and
# we would miss messages otherwise.
import logging
import log
from datetime import datetime
from monotonic import monotonic
import RHTimeFns

log.early_stage_setup()
logger = logging.getLogger(__name__)

EPOCH_START = RHTimeFns.getEpochStartTime()

# program-start time, in milliseconds since 1970-01-01
PROGRAM_START_EPOCH_TIME = int((RHTimeFns.getUtcDateTimeNow() - EPOCH_START).total_seconds() * 1000)

# program-start time (in milliseconds, starting at zero)
PROGRAM_START_MTONIC = monotonic()

# offset for converting 'monotonic' time to epoch milliseconds since 1970-01-01
MTONIC_TO_EPOCH_MILLIS_OFFSET = PROGRAM_START_EPOCH_TIME - 1000.0*PROGRAM_START_MTONIC

logger.info('RotorHazard v{0}'.format(RELEASE_VERSION))

# Normal importing resumes here
import gevent.monkey
gevent.monkey.patch_all()

import io
import os
import sys
import base64
import subprocess
import importlib
import copy
from functools import wraps
from collections import OrderedDict
from six import unichr, string_types

from flask import Flask, send_file, request, Response, session, templating, redirect
from flask_socketio import SocketIO, emit

import socket
import random
import string
import json

import Config
import Database
import Results
import Language
import RHData
import RHUtils
from RHUtils import catchLogExceptionsWrapper
from ClusterNodeSet import SecondaryNode, ClusterNodeSet
import PageCache
from util.SendAckQueue import SendAckQueue
import RHGPIO
from util.ButtonInputHandler import ButtonInputHandler
import util.stm32loader as stm32loader

# Events manager
from eventmanager import Evt, EventManager

Events = EventManager()

# LED imports
from led_event_manager import LEDEventManager, NoLEDManager, ClusterLEDManager, LEDEvent, Color, ColorVal, ColorPattern, hexToColor

sys.path.append('../interface')
sys.path.append('/home/pi/RotorHazard/src/interface')  # Needed to run on startup

from Plugins import Plugins, search_modules  #pylint: disable=import-error
from Sensors import Sensors  #pylint: disable=import-error
import RHRace
from RHRace import StartBehavior, WinCondition, WinStatus, RaceStatus
from data_export import DataExportManager

APP = Flask(__name__, static_url_path='/static')

HEARTBEAT_THREAD = None
BACKGROUND_THREADS_ENABLED = True
HEARTBEAT_DATA_RATE_FACTOR = 5

ERROR_REPORT_INTERVAL_SECS = 600  # delay between comm-error reports to log

DB_FILE_NAME = 'database.db'
DB_BKP_DIR_NAME = 'db_bkp'
IMDTABLER_JAR_NAME = 'static/IMDTabler.jar'
NODE_FW_PATHNAME = "firmware/RH_S32_BPill_node.bin"

# check if 'log' directory owned by 'root' and change owner to 'pi' user if so
if RHUtils.checkSetFileOwnerPi(log.LOG_DIR_NAME):
    logger.info("Changed '{0}' dir owner from 'root' to 'pi'".format(log.LOG_DIR_NAME))

# command-line arguments:
CMDARG_VERSION_LONG_STR = '--version'    # show program version and exit
CMDARG_VERSION_SHORT_STR = '-v'          # show program version and exit
CMDARG_ZIP_LOGS_STR = '--ziplogs'        # create logs .zip file
CMDARG_JUMP_TO_BL_STR = '--jumptobl'     # send jump-to-bootloader command to node
CMDARG_FLASH_BPILL_STR = '--flashbpill'  # flash firmware onto S32_BPill processor

if __name__ == '__main__' and len(sys.argv) > 1:
    if CMDARG_VERSION_LONG_STR in sys.argv or CMDARG_VERSION_SHORT_STR in sys.argv:
        sys.exit(0)
    if CMDARG_ZIP_LOGS_STR in sys.argv:
        log.create_log_files_zip(logger, Config.CONFIG_FILE_NAME, DB_FILE_NAME)
        sys.exit(0)
    if CMDARG_JUMP_TO_BL_STR not in sys.argv:  # handle jump-to-bootloader argument later
        if CMDARG_FLASH_BPILL_STR in sys.argv:
            flashPillArgIdx = sys.argv.index(CMDARG_FLASH_BPILL_STR) + 1
            flashPillPortStr = Config.SERIAL_PORTS[0] if Config.SERIAL_PORTS and \
                                                len(Config.SERIAL_PORTS) > 0 else None
            flashPillSrcStr = sys.argv[flashPillArgIdx] if flashPillArgIdx < len(sys.argv) else None
            if flashPillSrcStr and flashPillSrcStr.startswith("--"):  # use next arg as src file (optional)
                flashPillSrcStr = None                       #  unless arg is switch param
            flashPillSuccessFlag = stm32loader.flash_file_to_stm32(flashPillPortStr, flashPillSrcStr)
            sys.exit(0 if flashPillSuccessFlag else 1)
        print("Unrecognized command-line argument(s): {0}".format(sys.argv[1:]))
        sys.exit(1)

TEAM_NAMES_LIST = [str(unichr(i)) for i in range(65, 91)]  # list of 'A' to 'Z' strings

BASEDIR = os.getcwd()
APP.config['SQLALCHEMY_DATABASE_URI'] = 'sqlite:///' + os.path.join(BASEDIR, DB_FILE_NAME)
APP.config['SQLALCHEMY_TRACK_MODIFICATIONS'] = False
Database.DB.init_app(APP)
Database.DB.app = APP

# start SocketIO service
SOCKET_IO = SocketIO(APP, async_mode='gevent', cors_allowed_origins=Config.GENERAL['CORS_ALLOWED_HOSTS'])

# this is the moment where we can forward log-messages to the frontend, and
# thus set up logging for good.
Current_log_path_name = log.later_stage_setup(Config.LOGGING, SOCKET_IO)

INTERFACE = None  # initialized later
SENSORS = Sensors()
CLUSTER = None    # initialized later
ClusterSendAckQueueObj = None
serverInfo = None
serverInfoItems = None
Use_imdtabler_jar_flag = False  # set True if IMDTabler.jar is available
vrx_controller = None
server_ipaddress_str = None
ShutdownButtonInputHandler = None
Server_secondary_mode = None

RACE = RHRace.RHRace() # For storing race management variables
LAST_RACE = None
SECONDARY_RACE_FORMAT = None
RHData = RHData.RHData(Database, Events, RACE, SERVER_API, DB_FILE_NAME, DB_BKP_DIR_NAME) # Primary race data storage
PageCache = PageCache.PageCache(RHData, Events) # For storing page cache
Language = Language.Language(RHData) # initialize language
__ = Language.__ # Shortcut to translation function
RHData.late_init(PageCache, Language) # Give RHData additional references

TONES_NONE = 0
TONES_ONE = 1
TONES_ALL = 2

ui_server_messages = {}
def set_ui_message(mainclass, message, header=None, subclass=None):
    item = {}
    item['message'] = message
    if header:
        item['header'] = __(header)
    if subclass:
        item['subclass'] = subclass
    ui_server_messages[mainclass] = item

# convert 'monotonic' time to epoch milliseconds since 1970-01-01
def monotonic_to_epoch_millis(secs):
    return 1000.0*secs + MTONIC_TO_EPOCH_MILLIS_OFFSET

# Wrapper to be used as a decorator on callback functions that do database calls,
#  so their exception details are sent to the log file (instead of 'stderr')
#  and the database session is closed on thread exit (prevents DB-file handles left open).
def catchLogExcDBCloseWrapper(func):
    def wrapper(*args, **kwargs):
        try:
            retVal = func(*args, **kwargs)
            RHData.close()
            return retVal
        except:
            logger.exception("Exception via catchLogExcDBCloseWrapper")
            try:
                RHData.close()
            except:
                logger.exception("Error closing DB session in catchLogExcDBCloseWrapper-catch")
    return wrapper

# Return 'DEF_NODE_FWUPDATE_URL' config value; if not set in 'config.json'
#  then return default value based on BASEDIR and server RELEASE_VERSION
def getDefNodeFwUpdateUrl():
    try:
        if Config.GENERAL['DEF_NODE_FWUPDATE_URL']:
            return Config.GENERAL['DEF_NODE_FWUPDATE_URL']
        if RELEASE_VERSION.lower().find("dev") > 0:  # if "dev" server version then
            retStr = stm32loader.DEF_BINSRC_STR      # use current "dev" firmware at URL
        else:
            # return path that is up two levels from BASEDIR, and then NODE_FW_PATHNAME
            retStr = os.path.abspath(os.path.join(os.path.join(os.path.join(BASEDIR, os.pardir), \
                                                             os.pardir), NODE_FW_PATHNAME))
        # check if file with better-matching processor type (i.e., STM32F4) is available
        try:
            curTypStr = INTERFACE.nodes[0].firmware_proctype_str if len(INTERFACE.nodes) else None
            if curTypStr:
                fwTypStr = getFwfileProctypeStr(retStr)
                if fwTypStr and curTypStr != fwTypStr:
                    altFwFNameStr = RHUtils.appendToBaseFilename(retStr, ('_'+curTypStr))
                    altFwTypeStr = getFwfileProctypeStr(altFwFNameStr)
                    if curTypStr == altFwTypeStr:
                        logger.debug("Using better-matching node-firmware file: " + altFwFNameStr)
                        return altFwFNameStr
        except Exception as ex:
            logger.debug("Error checking fw type vs current type: " + str(ex))
        return retStr
    except:
        logger.exception("Error determining value for 'DEF_NODE_FWUPDATE_URL'")
    return "/home/pi/RotorHazard/" + NODE_FW_PATHNAME

# Returns the processor-type string from the given firmware file, or None if not found
def getFwfileProctypeStr(fileStr):
    dataStr = None
    try:
        dataStr = stm32loader.load_source_file(fileStr, False)
        if dataStr:
            return RHUtils.findPrefixedSubstring(dataStr, INTERFACE.FW_PROCTYPE_PREFIXSTR, \
                                                 INTERFACE.FW_TEXT_BLOCK_SIZE)
    except Exception as ex:
        logger.debug("Error processing file '{}' in 'getFwfileProctypeStr()': {}".format(fileStr, ex))
    return None

def getCurrentProfile():
    current_profile = RHData.get_optionInt('currentProfile')
    return RHData.get_profile(current_profile)

def getCurrentRaceFormat():
    if RACE.format is None:
        val = RHData.get_optionInt('currentFormat')
        if val:
            race_format = RHData.get_raceFormat(val)
            if not race_format:
                race_format = RHData.get_first_raceFormat()
                RHData.set_option('currentFormat', race_format.id)
        else:
            race_format = RHData.get_first_raceFormat()

        # create a shared instance
        RACE.format = RHRaceFormat.copy(race_format)
        RACE.format.id = race_format.id  #pylint: disable=attribute-defined-outside-init
    return RACE.format

def getCurrentDbRaceFormat():
    if RACE.format is None or RHRaceFormat.isDbBased(RACE.format):
        val = RHData.get_optionInt('currentFormat')
        return RHData.get_raceFormat(val)
    else:
        return None

def setCurrentRaceFormat(race_format, **kwargs):
    if RHRaceFormat.isDbBased(race_format): # stored in DB, not internal race format
        RHData.set_option('currentFormat', race_format.id)
        # create a shared instance
        RACE.format = RHRaceFormat.copy(race_format)
        RACE.format.id = race_format.id  #pylint: disable=attribute-defined-outside-init
        RACE.cacheStatus = Results.CacheStatus.INVALID  # refresh leaderboard
        RACE.team_cacheStatus = Results.CacheStatus.INVALID
    else:
        RACE.format = race_format

    if 'silent' not in kwargs:
        emit_current_laps()

class RHRaceFormat():
    def __init__(self, name, race_mode, race_time_sec, start_delay_min, start_delay_max, staging_tones, number_laps_win, win_condition, team_racing_mode, start_behavior):
        self.name = name
        self.race_mode = race_mode
        self.race_time_sec = race_time_sec
        self.start_delay_min = start_delay_min
        self.start_delay_max = start_delay_max
        self.staging_tones = staging_tones
        self.number_laps_win = number_laps_win
        self.win_condition = win_condition
        self.team_racing_mode = team_racing_mode
        self.start_behavior = start_behavior

    @classmethod
    def copy(cls, race_format):
        return RHRaceFormat(name=race_format.name,
                            race_mode=race_format.race_mode,
                            race_time_sec=race_format.race_time_sec,
                            start_delay_min=race_format.start_delay_min,
                            start_delay_max=race_format.start_delay_max,
                            staging_tones=race_format.staging_tones,
                            number_laps_win=race_format.number_laps_win,
                            win_condition=race_format.win_condition,
                            team_racing_mode=race_format.team_racing_mode,
                            start_behavior=race_format.start_behavior)

    @classmethod
    def isDbBased(cls, race_format):
        return hasattr(race_format, 'id')

#
# Authentication
#

def check_auth(username, password):
    '''Check if a username password combination is valid.'''
    return username == Config.GENERAL['ADMIN_USERNAME'] and password == Config.GENERAL['ADMIN_PASSWORD']

def authenticate():
    '''Sends a 401 response that enables basic auth.'''
    return Response(
        'Could not verify your access level for that URL.\n'
        'You have to login with proper credentials', 401,
        {'WWW-Authenticate': 'Basic realm="Login Required"'})

def requires_auth(f):
    @wraps(f)
    def decorated(*args, **kwargs):
        auth = request.authorization
        if not auth or not check_auth(auth.username, auth.password):
            return authenticate()
        return f(*args, **kwargs)
    return decorated

# Flask template render with exception catch, so exception
# details are sent to the log file (instead of 'stderr').
def render_template(template_name_or_list, **context):
    try:
        return templating.render_template(template_name_or_list, **context)
    except Exception:
        logger.exception("Exception in render_template")
    return "Error rendering template"

#
# Routes
#

@APP.route('/')
def render_index():
    '''Route to home page.'''
    return render_template('home.html', serverInfo=serverInfo,
                           getOption=RHData.get_option, __=__, Debug=Config.GENERAL['DEBUG'])

@APP.route('/event')
def render_event():
    '''Route to heat summary page.'''
    return render_template('event.html', num_nodes=RACE.num_nodes, serverInfo=serverInfo, getOption=RHData.get_option, __=__)

@APP.route('/results')
def render_results():
    '''Route to round summary page.'''
    return render_template('results.html', serverInfo=serverInfo, getOption=RHData.get_option, __=__, Debug=Config.GENERAL['DEBUG'])

@APP.route('/run')
@requires_auth
def render_run():
    '''Route to race management page.'''
    frequencies = [node.frequency for node in INTERFACE.nodes]
    nodes = []
    for idx, freq in enumerate(frequencies):
        if freq:
            nodes.append({
                'freq': freq,
                'index': idx
            })

    return render_template('run.html', serverInfo=serverInfo, getOption=RHData.get_option, __=__,
        led_enabled=(led_manager.isEnabled() or (CLUSTER and CLUSTER.hasRecEventsSecondaries())),
        vrx_enabled=vrx_controller!=None,
        num_nodes=RACE.num_nodes,
        nodes=nodes,
        cluster_has_secondaries=(CLUSTER and CLUSTER.hasSecondaries()))

@APP.route('/current')
def render_current():
    '''Route to race management page.'''
    frequencies = [node.frequency for node in INTERFACE.nodes]
    nodes = []
    for idx, freq in enumerate(frequencies):
        if freq:
            nodes.append({
                'freq': freq,
                'index': idx
            })

    return render_template('current.html', serverInfo=serverInfo, getOption=RHData.get_option, __=__,
        num_nodes=RACE.num_nodes,
        nodes=nodes,
        cluster_has_secondaries=(CLUSTER and CLUSTER.hasSecondaries()))

@APP.route('/marshal')
@requires_auth
def render_marshal():
    '''Route to race management page.'''
    return render_template('marshal.html', serverInfo=serverInfo, getOption=RHData.get_option, __=__,
        num_nodes=RACE.num_nodes)

@APP.route('/settings')
@requires_auth
def render_settings():
    '''Route to settings page.'''
    server_messages_formatted = ''
    if len(ui_server_messages):
        for key, item in ui_server_messages.items():
            message = '<li class="' + key
            if 'subclass' in item and item['subclass']:
                message += ' ' + key + '-' + item['subclass']
            if 'header' in item and item['header']:
                message += ' ' + item['header'].lower()
            message += '">'
            if 'header' in item and item['header']:
                message += '<strong>' + item['header'] + ':</strong> '
            message += item['message']
            message += '</li>'
            server_messages_formatted += message
    if Config.GENERAL['configFile'] == -1:
        server_messages_formatted += '<li class="config config-bad warning"><strong>' + __('Warning') + ': ' + '</strong>' + __('The config.json file is invalid. Falling back to default configuration.') + '<br />' + __('See <a href="/docs?d=User Guide.md#set-up-config-file">User Guide</a> for more information.') + '</li>'
    elif Config.GENERAL['configFile'] == 0:
        server_messages_formatted += '<li class="config config-none warning"><strong>' + __('Warning') + ': ' + '</strong>' + __('No configuration file was loaded. Falling back to default configuration.') + '<br />' + __('See <a href="/docs?d=User Guide.md#set-up-config-file">User Guide</a> for more information.') +'</li>'

    return render_template('settings.html', serverInfo=serverInfo, getOption=RHData.get_option, __=__,
        led_enabled=(led_manager.isEnabled() or (CLUSTER and CLUSTER.hasRecEventsSecondaries())),
        led_events_enabled=led_manager.isEnabled(),
        vrx_enabled=vrx_controller!=None,
        num_nodes=RACE.num_nodes,
        server_messages=server_messages_formatted,
        cluster_has_secondaries=(CLUSTER and CLUSTER.hasSecondaries()),
        node_fw_updatable=(INTERFACE.get_fwupd_serial_name()!=None),
        is_raspberry_pi=RHUtils.isSysRaspberryPi(),
        Debug=Config.GENERAL['DEBUG'])

@APP.route('/streams')
def render_stream():
    '''Route to stream index.'''
    return render_template('streams.html', serverInfo=serverInfo, getOption=RHData.get_option, __=__,
        num_nodes=RACE.num_nodes)

@APP.route('/stream/results')
def render_stream_results():
    '''Route to current race leaderboard stream.'''
    return render_template('streamresults.html', serverInfo=serverInfo, getOption=RHData.get_option, __=__,
        num_nodes=RACE.num_nodes)

@APP.route('/stream/node/<int:node_id>')
def render_stream_node(node_id):
    '''Route to single node overlay for streaming.'''
    if node_id <= RACE.num_nodes:
        return render_template('streamnode.html', serverInfo=serverInfo, getOption=RHData.get_option, __=__,
            node_id=node_id-1
        )
    else:
        return False

@APP.route('/stream/class/<int:class_id>')
def render_stream_class(class_id):
    '''Route to class leaderboard display for streaming.'''
    return render_template('streamclass.html', serverInfo=serverInfo, getOption=RHData.get_option, __=__,
        class_id=class_id
    )

@APP.route('/stream/heat/<int:heat_id>')
def render_stream_heat(heat_id):
    '''Route to heat display for streaming.'''
    return render_template('streamheat.html', serverInfo=serverInfo, getOption=RHData.get_option, __=__,
        num_nodes=RACE.num_nodes,
        heat_id=heat_id
    )

@APP.route('/scanner')
@requires_auth
def render_scanner():
    '''Route to scanner page.'''

    return render_template('scanner.html', serverInfo=serverInfo, getOption=RHData.get_option, __=__,
        num_nodes=RACE.num_nodes)

@APP.route('/decoder')
@requires_auth
def render_decoder():
    '''Route to race management page.'''
    return render_template('decoder.html', serverInfo=serverInfo, getOption=RHData.get_option, __=__,
        num_nodes=RACE.num_nodes)

@APP.route('/imdtabler')
def render_imdtabler():
    '''Route to IMDTabler page.'''
    return render_template('imdtabler.html', serverInfo=serverInfo, getOption=RHData.get_option, __=__)

@APP.route('/updatenodes')
@requires_auth
def render_updatenodes():
    '''Route to update nodes page.'''
    return render_template('updatenodes.html', serverInfo=serverInfo, getOption=RHData.get_option, __=__, \
                           fw_src_str=getDefNodeFwUpdateUrl())

# Debug Routes

@APP.route('/hardwarelog')
@requires_auth
def render_hardwarelog():
    '''Route to hardware log page.'''
    return render_template('hardwarelog.html', serverInfo=serverInfo, getOption=RHData.get_option, __=__)

@APP.route('/database')
@requires_auth
def render_database():
    '''Route to database page.'''
    return render_template('database.html', serverInfo=serverInfo, getOption=RHData.get_option, __=__,
        pilots=RHData.get_pilots(),
        heats=RHData.get_heats(),
        heatnodes=RHData.get_heatNodes(),
        race_class=RHData.get_raceClasses(),
        savedraceMeta=RHData.get_savedRaceMetas(),
        savedraceLap=RHData.get_savedRaceLaps(),
        profiles=RHData.get_profiles(),
        race_format=RHData.get_raceFormats(),
        globalSettings=RHData.get_options())

@APP.route('/vrxstatus')
@requires_auth
def render_vrxstatus():
    '''Route to VRx status debug page.'''
    return render_template('vrxstatus.html', serverInfo=serverInfo, getOption=RHData.get_option, __=__)

# Documentation Viewer
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

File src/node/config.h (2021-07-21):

#ifndef config_h
#define config_h

#include <Arduino.h>
#include "util/rhtypes.h"

#ifdef STM32_CORE_VERSION
#define STM32_MODE_FLAG 1  // 1 for STM 32-bit processor running multiple nodes
#else
#define STM32_MODE_FLAG 0  // 0 for Arduino processor running single node
#endif

#if !STM32_MODE_FLAG

// Set to 1-8 for manual selection of Arduino node ID/address
// Set to 0 for automatic selection via hardware pin
// See https://github.com/RotorHazard/RotorHazard/wiki/Specification:-Node-hardware-addressing
#define NODE_NUMBER 0

#endif

// ******************************************************************** //

// features flags for value returned by READ_RHFEAT_FLAGS command
#define RHFEAT_STM32_MODE ((uint16_t)0x0004)      // STM 32-bit processor running multiple nodes
#define RHFEAT_JUMPTO_BOOTLDR ((uint16_t)0x0008)  // JUMP_TO_BOOTLOADER command supported
#define RHFEAT_IAP_FIRMWARE ((uint16_t)0x0010)    // in-application programming of firmware supported
#define RHFEAT_NONE ((uint16_t)0)

#if STM32_MODE_FLAG
// value returned by READ_RHFEAT_FLAGS command
#define RHFEAT_FLAGS_VALUE (RHFEAT_STM32_MODE | RHFEAT_JUMPTO_BOOTLDR | RHFEAT_IAP_FIRMWARE)

#define SERIAL_BAUD_RATE 921600
#define MULTI_RHNODE_MAX 8
#define STM32_SERIALUSB_FLAG 0  // 1 to use BPill USB port for serial link

#else
// value returned by READ_RHFEAT_FLAGS command
#define RHFEAT_FLAGS_VALUE RHFEAT_NONE

#define SERIAL_BAUD_RATE 115200
#define MULTI_RHNODE_MAX 1
#endif  // STM32_MODE_FLAG


#if STM32_MODE_FLAG || defined(__TEST__)
#define ATOMIC_BLOCK(x)
#define ATOMIC_RESTORESTATE
#else
#include <util/atomic.h>
#endif

#if !STM32_MODE_FLAG

// Set to 0 for standard RotorHazard node wiring; set to 1 for ArduVidRx USB node wiring
//   See here for an ArduVidRx example: http://www.etheli.com/ArduVidRx/hw/index.html#promini
#define ARDUVIDRX_WIRING_FLAG 0

#define CHORUS_WIRING_FLAG 0

#if ARDUVIDRX_WIRING_FLAG
#define RX5808_DATA_PIN 10             //DATA output line to RX5808 module
#define RX5808_SEL_PIN 11              //SEL output line to RX5808 module
#define RX5808_CLK_PIN 12              //CLK output line to RX5808 module
#define RSSI_INPUT_PIN A7              //RSSI input from RX5808
#define NODE_RESET_PIN A1              //Pin to reset paired Arduino via command for ISP
#elif CHORUS_WIRING_FLAG
#define RX5808_DATA_PIN 10             //DATA output line to RX5808 module
#define RX5808_SEL_PIN 11              //SEL output line to RX5808 module
#define RX5808_CLK_PIN 12              //CLK output line to RX5808 module
#define RSSI_INPUT_PIN A3              //RSSI input from RX5808
#define NODE_RESET_PIN A1              //Pin to reset paired Arduino via command for ISP
#else
#define RX5808_DATA_PIN 11             //DATA output line to RX5808 module
#define RX5808_SEL_PIN 10              //SEL output line to RX5808 module
#define RX5808_CLK_PIN 13              //CLK output line to RX5808 module
#define RSSI_INPUT_PIN A0              //RSSI input from RX5808
#define NODE_RESET_PIN 12              //Pin to reset paired Arduino via command for ISP
#endif

#define DISABLE_SERIAL_PIN 9  //pull pin low (to GND) to disable serial port
#define HARDWARE_SELECT_PIN_1 2
#define HARDWARE_SELECT_PIN_2 3
#define HARDWARE_SELECT_PIN_3 4
#define LEGACY_HARDWARE_SELECT_PIN_1 4
#define LEGACY_HARDWARE_SELECT_PIN_2 5
#define LEGACY_HARDWARE_SELECT_PIN_3 6
#define LEGACY_HARDWARE_SELECT_PIN_4 7
#define LEGACY_HARDWARE_SELECT_PIN_5 8

#define MODULE_LED_ONSTATE HIGH
#define MODULE_LED_OFFSTATE LOW

#else  // STM32_MODE_FLAG

#define RX5808_DATA_PIN PB3            //DATA output line to RX5808 modules
#define RX5808_CLK_PIN PB4             //CLK output line to RX5808 modules

#define RX5808_SEL0_PIN PB6            //SEL output lines to RX5808 modules
#define RX5808_SEL1_PIN PB7
#define RX5808_SEL2_PIN PB8
#define RX5808_SEL3_PIN PB9
#define RX5808_SEL4_PIN PB12
#define RX5808_SEL5_PIN PB13
#define RX5808_SEL6_PIN PB14
#define RX5808_SEL7_PIN PB15

#define BUZZER_OUTPUT_PIN PA8
#define BUZZER_OUT_ONSTATE LOW
#define BUZZER_OUT_OFFSTATE HIGH

#define AUXLED_OUTPUT_PIN PA15

#ifndef STM32_F4_PROCTYPE  // pinouts for STM32F103C8T6 "Blue Pill" module

#define RSSI_INPUT0_PIN A0             //RSSI inputs from RX5808 modules
#define RSSI_INPUT1_PIN A1
#define RSSI_INPUT2_PIN A2
#define RSSI_INPUT3_PIN A3
#define RSSI_INPUT4_PIN A4
#define RSSI_INPUT5_PIN A5
#define RSSI_INPUT6_PIN A6
#define RSSI_INPUT7_PIN A7

#define VOLTAGE_MONITOR_PIN PB1

// on the S32_BPill PCB this pin is connected to RPi GPIO24, which should be
//  configured for "heartbeat" on the RPi in "/boot/config.txt" like this:
//    dtoverlay=act-led,gpio=24
//    dtparam=act_led_trigger=heartbeat
#define RPI_SIGNAL_PIN PB0
#define RPI_SIGNAL_ONSTATE HIGH

#else                   // pinouts for STM32F411CEU6 "Black Pill" module
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

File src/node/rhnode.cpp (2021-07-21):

#ifndef __TEST__
// RotorHazard FPV Race Timing
// Based on Delta 5 Race Timer by Scott Chin
// SPI driver based on fs_skyrf_58g-main.c Written by Simon Chambers
// I2C functions by Mike Ochtman
//
// MIT License
//
// Copyright (c) 2019 Michael Niggel and other contributors
//
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
#include "config.h"
#include "RssiNode.h"
#include "commands.h"
#if !STM32_MODE_FLAG
#include <Wire.h>
#include "rheeprom.h"
#endif

// Note: Configure Arduino NODE_NUMBER value in 'config.h'

// firmware version string (prefix allows text to be located in '.bin' file)
const char *firmwareVersionString = "FIRMWARE_VERSION: 1.1.4";

// build date/time strings
const char *firmwareBuildDateString = "FIRMWARE_BUILDDATE: " __DATE__;
const char *firmwareBuildTimeString = "FIRMWARE_BUILDTIME: " __TIME__;

// node processor type
#if !STM32_MODE_FLAG
const char *firmwareProcTypeString = "FIRMWARE_PROCTYPE: Arduino";
#else
#if !STM32_F4_PROCTYPE
const char *firmwareProcTypeString = "FIRMWARE_PROCTYPE: STM32F1";
#else
const char *firmwareProcTypeString = "FIRMWARE_PROCTYPE: STM32F4";
#endif
#endif

#if !STM32_MODE_FLAG
// i2c address for node
// Node 1 = 8, Node 2 = 10, Node 3 = 12, Node 4 = 14
// Node 5 = 16, Node 6 = 18, Node 7 = 20, Node 8 = 22
uint8_t i2cAddress = 6 + (NODE_NUMBER * 2);
#define SERIALCOM Serial
#define EEPROM_ADRW_RXFREQ 0       //address for stored RX frequency value
#define EEPROM_ADRW_ENTERAT 2      //address for stored 'enterAtLevel'
#define EEPROM_ADRW_EXITAT 4       //address for stored 'exitAtLevel'
#define EEPROM_ADRW_EXPIRE 6       //address for stored catch history expire duration
#define EEPROM_ADRW_CHECKWORD 8    //address for integrity-check value
#define EEPROM_CHECK_VALUE 0x3526  //EEPROM integrity-check value
#define COMMS_MONITOR_TIME_MS 5000 //I2C communications monitor grace/trigger time

#else
#define MIN_RSSI_DETECT 5          //value for detecting node as installed
#if STM32_SERIALUSB_FLAG
#define SERIALCOM SerialUSB
#else
#define SERIALCOM Serial
#endif
#endif

// dummy macro
#define LOG_ERROR(...)

Message serialMessage;

#if !STM32_MODE_FLAG
Message i2cMessage;

// Defines for fast ADC reads
#define cbi(sfr, bit) (_SFR_BYTE(sfr) &= ~_BV(bit))
#define sbi(sfr, bit) (_SFR_BYTE(sfr) |= _BV(bit))

void i2cInitialize(bool delayFlag);
void i2cReceive(int byteCount);
bool i2cReadAndValidateIoBuffer(byte expectedSize);
void i2cTransmit();

#elif STM32_SERIALUSB_FLAG
void serialEvent();
#endif

void setModuleLed(bool onFlag);

#if defined(RPI_SIGNAL_PIN) || defined(AUXLED_OUTPUT_PIN) || defined(BUZZER_OUTPUT_PIN)
void handleRpiSignalAndShutdownActions(mtime_t curTimeMs);
#endif

#ifdef RPI_SIGNAL_PIN
static volatile bool rpiActiveSignalFlag = false;
static volatile mtime_t rpiLastActiveTimeMs = 0;
#define RPI_INACTIVE_DELAYMS 9000  // if no RPi signal for this long then "inactive"
#define RPI_MISSING_DELAYMS 2000
#define GET_RPI_ACTIVESIG_FLAG() (rpiActiveSignalFlag)
#define GET_RPI_LASTACTIVE_TIMEMS() (rpiLastActiveTimeMs)
// have AUX LED mostly on if RPi status is "active"
#define AUXLED_OUT_ONSTATE (rpiActiveSignalFlag ? LOW : HIGH)
#define AUXLED_OUT_OFFSTATE (rpiActiveSignalFlag ? HIGH : LOW)
#else
#define GET_RPI_ACTIVESIG_FLAG() (false)
#define GET_RPI_LASTACTIVE_TIMEMS() (0)
#define AUXLED_OUT_ONSTATE HIGH
#define AUXLED_OUT_OFFSTATE LOW
#endif

#ifdef AUXLED_OUTPUT_PIN
static volatile bool auxLedOutEnabledFlag = false;
#endif

#ifdef BUZZER_OUTPUT_PIN
void setBuzzerState(bool onFlag);
static volatile int buzzerBeepDurationCounter = 0;
static volatile int lastCommActivityTimeMs = 0;
#endif

#if defined(AUXLED_OUTPUT_PIN) || defined(BUZZER_OUTPUT_PIN)
static volatile bool shutdownButtonPressedFlag = false;
static volatile bool shutdownHasBeenStartedFlag = false;
static volatile bool rpiSignalMissingFlag = false;
#endif
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

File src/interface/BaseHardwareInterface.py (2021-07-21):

import gevent
import logging
from monotonic import monotonic

ENTER_AT_PEAK_MARGIN = 5 # closest that captured enter-at level can be to node peak RSSI
CAP_ENTER_EXIT_AT_MILLIS = 3000  # number of ms for capture of enter/exit-at levels

logger = logging.getLogger(__name__)


class BaseHardwareInterface(object):

    LAP_SOURCE_REALTIME = 0
    LAP_SOURCE_MANUAL = 1
    LAP_SOURCE_RECALC = 2
    LAP_SOURCE_LABEL_STRS = ["realtime", "manual", "recalc"]

    RACE_STATUS_READY = 0
    RACE_STATUS_STAGING = 3
    RACE_STATUS_RACING = 1
    RACE_STATUS_DONE = 2

    def __init__(self):
        self.calibration_threshold = 20
        self.calibration_offset = 10
        self.trigger_threshold = 20
        self.start_time = 1000*monotonic() # millis
        self.environmental_data_update_tracker = 0
        self.race_status = BaseHardwareInterface.RACE_STATUS_READY
        self.pass_record_callback = None # Function added in server.py
        self.new_enter_or_exit_at_callback = None # Function added in server.py
        self.node_crossing_callback = None # Function added in server.py
        self.nodes = []

    # returns the elapsed milliseconds since the start of the program
    def milliseconds(self):
        return 1000*monotonic() - self.start_time

    def log(self, message):
        logger.info('Interface: {0}'.format(message))

    def get_lap_source_str(self, source_idx):
        return BaseHardwareInterface.LAP_SOURCE_LABEL_STRS[source_idx] \
            if source_idx >= 0 and source_idx < len(BaseHardwareInterface.LAP_SOURCE_LABEL_STRS) \
            else "unknown ({})".format(source_idx)
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

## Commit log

2020-08-13 Moving and tidying in prep for new design
    [Box Eight Node.stl, Box Four Node.stl, Grille Circles.stl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]
2020-09-25 Create Folders
    Added folders for both PCB variants
2020-09-25 Upload STL Files
    STL fopr both flatcase PCB variants
    [4Node_RHFlatCaseLid.stl, 8Node_RHFlatCaseLid.stl, PCB_Clip.stl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]
